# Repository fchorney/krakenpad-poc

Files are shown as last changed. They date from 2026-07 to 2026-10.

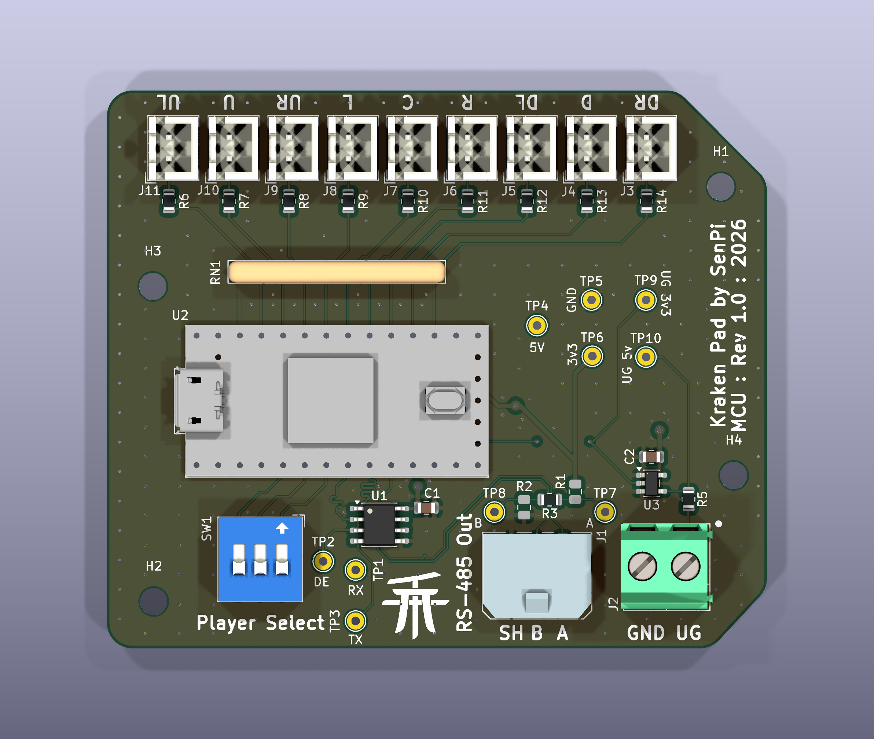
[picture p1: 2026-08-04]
review/01-master/11-3d-top.png

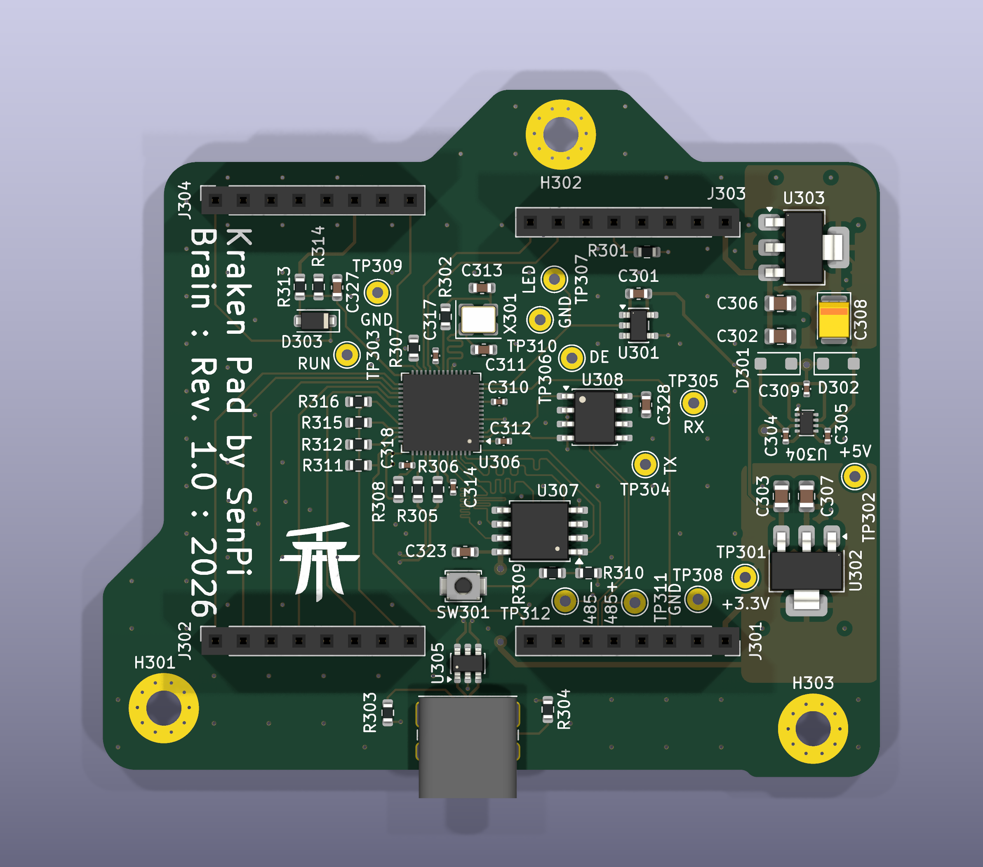
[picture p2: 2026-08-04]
review/04-dual-brain/11-3d-top.png

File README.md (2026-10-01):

# KrakenPad

Open-source dance pad controller hardware and firmware, built for modern ITG-style
rhythm games (Stepmania, ITGmania, DeadSync, etc.).

Commercial dance pad electronics haven't kept pace with what competitive/high-level
play actually wants: low, consistent input latency, high-resolution force sensing,
and hardware/firmware you can actually inspect, modify, and fix yourself. This
project is a ground-up replacement controller — sensor boards, main controller, and
firmware — designed around those priorities instead of around vendor lock-in or
proprietary protocols.

It is not tied to any one game or platform — it just speaks USB HID, so anything
that reads a standard controller/joystick works.

## Priorities

- **Low, consistent input latency.** Presses are detected and reported by dedicated
  interrupt-driven hardware, not discovered via a slow polling cycle — eliminating
  the multi-millisecond blind spots that periodic-scan designs are prone to.
- **High-resolution force sensing.** Each panel reads continuous per-sensor
  pressure (not just a binary switch), sampled at kHz-class rates, enabling more
  accurate and tunable press/release detection than simple threshold switches.
- **Higher, more consistent USB polling and LED refresh rates** than older
  commercial hardware typically offers, for tighter timing and smoother panel
  lighting.
- **Fully open hardware and firmware.** Schematics, PCB layouts, and firmware
  source are all open — no proprietary authentication, no closed protocol, no
  black-box firmware blobs. Anyone can build, modify, or repair their own unit.
- **Standard, open software compatibility.** Presents as a generic USB controller
  so it works out of the box with the open-source rhythm game ecosystem, with no
  vendor-specific driver or SDK required.

## Hardware Scope

The project is initially targeted at retrofitting existing SMX-style dance pad
frames — reusing the frame and panel mechanics while replacing the electronics
(control unit and panel sensor/LED boards) entirely. The design isn't
SMX-compatible at the protocol or hardware level; it simply fits the same
frame as a drop-in electronics replacement, since that's the hardware most
readily available for this kind of upgrade.

## Status

Prototype boards in hand, bring-up underway. Rev 1 of both boards — the master
controller and the two-board panel — was fabricated in August 2026, and the
boards are now being assembled and tested one at a time. The first panel and the
first master have been brought up: power, flash, sensors, all 25 LEDs, the
interrupt path and the RS-485 bus all work on the real hardware, panel to master.
Any board change from here is a rev 2 change. Firmware is still at bring-up
stage: the host-facing USB HID layer and flash-backed animation playback are not
written yet. See `docs/BRINGUP_LOG.md` for per-board results, `CLAUDE.md` and
`docs/` for design notes and specs.

## AI Disclosure

This project was built with AI assistance (Claude), used mainly for the grunt
work: research and part-comparison legwork, documentation drafts, firmware
prototyping, design-review passes, and scripted KiCad edits/fab outputs. All
design decisions, schematic wiring, PCB layout, and physical testing were done
by a human.

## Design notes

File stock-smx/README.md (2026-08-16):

# Stock SMX pad — reference documentation

**What a factory StepManiaX pad actually contains**, recorded from a full
teardown. This tree is descriptive and stands on its own: it is working
knowledge of stock SMX hardware, useful to anyone repairing or studying a pad,
and it is **deliberately independent of this project's replacement design**.

> **This directory contains no design opinions.** Nothing here says what we
> would replace, improve or remove. Our own hardware lives in `hardware/` and
> `docs/`; our replacement harnesses are in `hardware/harness/`.

## Contents

| File | What it covers |
|---|---|
| `harness/` | Every stock cable and connector, wall socket to FSRs — 12 WireViz drawings + a one-page topology map |
| `MEASUREMENTS.md` | The teardown bench sheet: raw lengths, gauges, pinouts, and the verification passes |
| `WIRE_COLORS.md` | Per-conductor colors for every stock harness, with confirmed/TODO status |
| `PARTS.md` | Stock connector/contact index, the JST-vs-Molex gender conventions, and JST YL current ratings |
| `PANEL_PCB.md` | The stock panel PCB — reverse-engineering reference |

## The harness drawings

Documented in power-flow order, wall inward. **The record is COMPLETE as of
2026-08-08** — nothing knowingly undocumented. A short list of low-consequence
unknowns is kept in `MEASUREMENTS.md`.

| File | Harness | Count per pad |
|---|---|---|
| `ac-input.yml` | Wall cord → YD06 EMI filter → locking IEC C13 | 1 |
| `psu-12v.yml` | C13 → YU1208 12V PSU → 5.5×2.5 barrel → JST YL 2-way | 1 |
| `12v-distribution.yml` | YL 2-way → fork-terminal star point → 2nd YL 2-way + underglow SM 3P | 1 |
| `external-12v-input.yml` | Star point → barrel socket, external cabinet 12V in | 1 |
| `dcdc-5v.yml` | Star point → Daygreen B15-1224-05, 12V→5V 15A | 1 |
| `5v-distribution.yml` | Converter 5V out → fork terminals → SM 2P + VLR-04V | 1 |
| `5v-columns.yml` | VLP-04V → 3× Molex 39014041, one per panel column | 1 |
| `mcu-interface.yml` | 5V SM 2P + underglow DATA → 14-pin KF2510 → Micro, analog row | 1 |
| `mcu-panel-io.yml` | 17-pin KF2510 on the Micro's digital row → 9 panel signal lines + RJ-12 data bus | 1 |
| `panel-signal-lines.yml` | YLP-09V → nine 18 AWG home runs → panel terminal blocks | 1 |
| `panel-power-chain.yml` | Column feed → 3 panels daisy-chained at 5V, 2 jumpers each | 3 |
| `panel-data-chain.yml` | MCU RJ-12 → all 9 panels, serpentine data bus | 1 |

`harness/stock-overview.dot` is the whole pad on one sheet — graphviz, not
WireViz, because it is a topology map rather than a harness drawing. It carries
no detail that is not already in the `.yml` files.

## Regenerating the drawings

```sh
uv tool install wireviz     # one-time; needs graphviz (brew install graphviz)
cd harness && ./gen.sh      # renders every .yml to harness/out/
```

Outputs land in `harness/out/` and are **not** committed.

## The headline findings

**The stock pad is a 5 V pad.** 12 V exists only between the supply and a
**Daygreen B15-1224-05** DC-DC converter; everything downstream — panels, LEDs,
MCU — runs at 5 V, with 15 A the whole budget. Read any stock harness past the
converter as 5 V unless it says otherwise.

**Topology:** wall → EMI filter → 12 V PSU → 5.5×2.5 barrel → fork-terminal star
point (physically the converter's input screw terminals) → { underglow SM 3P,
external 12 V barrel socket, **12 V→5 V converter** } → 5 V fork terminals →
{ **SM 2P → the MCU**, VLR-04V → 3× Molex to the panel columns }.

**The PSU has no terminal block and no ground stud.** It is a brick with one
captive output cable. Any description of "PSU lugs" or a "PSU GND stud" is
wrong — those came from pre-teardown guesswork elsewhere in this repo and have
been corrected.

**The MCU is fully accounted for.** Both header rows carry a KF2510 crimp
housing pushed straight onto the Arduino Micro's own pins — no adapter board.
Nine per-panel signal lines on D2–D10 (so **Dn drives panel n−2**), a **TX-only**
data bus off D1 through an RJ-12, and A1 driving the underglow. **On both
housings every position carries a contact whether wired or not** — an unwired
position is not an empty cavity.

**Panel LEDs have no wiring at all** — the 25-LED string is entirely PCB traces.
The only LED wiring in the pad is the underglow.

## Conventions used throughout

- **Panel numbers are 0–8** (0 = UL … 8 = DR). Teardown notes were spoken in
  1–9 numbering; subtract one.
- **Lengths in metres**, as WireViz expects. Bench readings were taken in
  **centimetres**, so the conversion is ÷100.
- **Sanity-check every length against something physical.** Every length taken
  on 2026-08-08 was reported in mm and meant in cm, and the whole set had to be
  corrected ×10 — caught only because nine panel home runs summed to an
  impossible 0.93 m of wire.
- **Wire by color within a harness, never by pin number across one.** Colors are
  inconsistent between harnesses; see `WIRE_COLORS.md`.
- Anything not measured or confirmed is marked `TODO` in a `notes:` field so it
  appears on the rendered drawing rather than hiding in a comment.
- **Never write `->` or a Unicode arrow inside a `notes:` field.** Notes are
  emitted into a graphviz HTML-like label unescaped and `dot` fails with an
  unhelpful syntax error. Write "then".

## Scope note: AC mains

`harness/ac-input.yml` documents the mains wiring as found. This project
replaces the MCU and panel PCBs only — nothing on the AC side changes. It is
recorded so a pad can be reassembled correctly and so the safety-critical
details (the JST YLP-03V's ground-in-the-middle pinout, the chassis bonding ring
terminal) are written down rather than remembered.

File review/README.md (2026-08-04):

# Review package — r/PrintedCircuitBoard, regenerated 2026-08-04

Export-only image set for every board in this project, formatted to the
subreddit's posting rules ([rule #8 / "please read before
posting"](https://old.reddit.com/r/PrintedCircuitBoard/comments/zj6ac8/please_read_before_posting_especially_if_using_a/),
[the "before you request a review, please fix these"
post](https://old.reddit.com/r/PrintedCircuitBoard/comments/1jwjhpe/before_you_request_a_review_please_fix_these/)).

Regenerate everything with:

```sh
tools/gen_review_images.py            # add --skip-3d to skip the slow raytraces
```

The script works on throwaway copies of the projects under `/tmp`, because
`kicad-cli` mutates `.kicad_pro` / `.kicad_sym` as a side effect. `hardware/` is
never written to.

## What's here

| Directory | Board | Size | Layers |
|---|---|---|---|
| `01-master/` | Master MCU board (Teensy 4.0 carrier) | 77.6 × 65.6 mm | 4 |
| `03-dual-carrier/` | Panel PCB — two-board design, LED/IO carrier | 127 × 127 mm core (139.3 mm across tabs) | 4 |
| `04-dual-brain/` | Panel PCB — two-board design, MCU brain | 70.9 × 62.8 mm | 4 |

The directory numbering has a gap because `02-panel-single/` — the retired
single-board panel — was removed on 2026-08-04 when the two-board split was
chosen. It is in git history at `1b41d1c` if it is ever wanted back.

At the top level: `POST-01-master.md` and `POST-03-dual-panel.md` are draft post
titles/bodies with the per-image captions each request needs, and
`RULES-CHECKLIST.md` is the pre-post audit.

Per board:

| File | What it is |
|---|---|
| `01-schematic.pdf` | schematic, vector, light background |
| `01-schematic-1-*.png` | same page rasterised at 300 dpi for image hosts |
| `02-2d-top.png` | F.Cu + F.Silkscreen + Edge.Cuts |
| `03-2d-in1.png` | In1.Cu + Edge.Cuts |
| `04-2d-in2.png` | In2.Cu + Edge.Cuts |
| `05-2d-bottom-mirrored.png` | B.Cu + B.Silkscreen + Edge.Cuts, mirrored so bottom silk reads correctly |
| `06-2d-silkscreen-top.png` | F.Silkscreen + Edge.Cuts alone (silk legibility check) |
| `07-2d-top-no-pour.png` | as `02`, zones emptied — routing visible under the pour |
| `08-2d-in1-no-pour.png` | as `03`, zones emptied |
| `09-2d-in2-no-pour.png` | as `04`, zones emptied |
| `10-2d-bottom-no-pour-mirrored.png` | as `05`, zones emptied |
| `11-3d-top.png` | 3D, straight-down plan view, same orientation as the 2D top |
| `12-3d-bottom.png` | 3D, straight-down plan view from below (matches the mirrored 2D bottom) |

The no-pour set exists because a solid GND pour hides the routing — reviewers
routinely ask for copper without fills. They are plotted from a throwaway copy
of the board with every zone un-filled; `--check-zones` is deliberately *not*
passed for those, or KiCad refills them.

**Cropping note:** `--bg-color` paints the whole PDF *page*, so trimming that
raster crops to the page, not the board. Each 2D view is therefore plotted
twice — once on white paper to measure the true board extent, once on black —
and the black raster is cropped to the white one's trim box.

`dual-panel.kicad_pcb` holds both outlines in one file (they ship as one
panel). The script splits it into two boards by X coordinate before plotting so
each gets its own images — see `DUAL_SPLIT_X` in the script.

## How the images satisfy the rules

* Exported with `kicad-cli`, never screen-captured — no cursor, no OS chrome,
  no grid, no photos of a monitor.
* Schematics keep KiCad's light background and standard orientation.
* 2D plots carry only layers that exist in the gerbers: copper, silkscreen and
  the board outline. No `*.Fab`, no `*.Courtyard`, no `User.*`, no net names on
  traces, no pad numbers.
* 2D colour scheme is a purpose-built theme (`PCB-Review`, written to
  `~/Library/Preferences/kicad/10.0/colors/` by the script): white silkscreen
  and outline, red/green/orange/blue copper per layer, black background so
  clearance and holes read as voids.
* 3D views are orthographic straight-down plan views in the same orientation as
  the 2D images. No tilted-only views.
* File sizes are 0.1–3.6 MB PNG / PDF.

## Read before posting

* **Subreddit rule 1 and rule 7A restrict AI-assisted work** ("no AI content /
  AI designs", "minor AI help ok"). These boards were designed with substantial
  AI assistance. Decide how you want to handle that before posting — the
  moderators, not this file, get to judge where the line is.
* **Rule 5: no board-house names anywhere in the title or body.** The
  `JLCJLCJLCJLC` string on B.Silkscreen (all three boards) is the order-number
  placeholder and is visible in `05-2d-bottom-mirrored.png`; don't name the
  vendor in the post text if a reviewer asks about it.
* **Rule 7A: no design questions in a review request.** Post each board as its
  own review request — the drafts in `POST-*.md` are written that way. (The
  single-vs-dual question that used to sit here is settled; don't reintroduce it
  into a post.)
* **Rule 7A: one review per board per day**, and don't edit images mid-review.

## State as of the 2026-08-04 regeneration

These images are current with the boards as of that date. They include the
2026-08-03 shifter swap (quad SN74AHCT125 → single-gate **SN74AHCT1G125**), the
brain's via-in-pad pass, the clearance floor raised 0.09 → **0.127 mm**, and the
carrier's **third mounting hole**. Earlier image sets predate all of that.

Also reflected: silkscreen fixes (FSR East, RS-485 A/B on the bus test points, fab
placeholder removed), the **year** in every name/rev block, `master-pcb` refdes
contiguous from 1, and `dual-panel` re-annotated into per-sheet blocks — **carrier
2xx, brain 3xx**, every type contiguous, no duplicates across sheets, which is
exactly the multi-sheet exception the rules allow.

Verified the same day, from clean project copies with zones current:

| Board | DRC | Unconnected | Schematic parity | ERC |
|---|---|---|---|---|
| master-pcb | 1 ✱ | 0 | 0 | 0 |
| dual-panel | 0 | 19 | 90 ✱✱ | 0 |

✱ One `courtyards_overlap` between R4 and U2 — R4 sits deliberately under the
socketed Teensy, and the violation is an accepted exclusion, not an open defect.

✱✱ Both dual-panel numbers are expected and neither is a defect. The **19
unconnected** are the board-to-board mating gap KiCad cannot model. The **90
parity items are a `kicad-cli`-only artifact — the GUI reports none**; they are
net *naming*, not topology, and the exported netlist agrees with the PCB
pad-for-pad across all 577 pads. Be ready to explain both if a reviewer asks.

Still open:

1. The carrier's board-to-board headers **J210–J213** are bottom-mounted (the
   brain hangs underneath), so the top view shows only their plated holes. The
   header bodies are in `03-dual-carrier/12-3d-bottom.png` — post both sides.
2. `dual-panel.kicad_pro` registers the root sheet as
   `a1b2c3d4-…-000000000001` — inherited from the retired `panel-pcb`, which the
   sheets were seeded from — while `dual-panel.kicad_sch` says `…00000000d001`.
   Harmless day to day, but it is why "Update PCB from Schematic" refused to match
   after re-annotation and had to be recovered with a re-link-by-refdes round trip.
   Expect it again on the next renumber.

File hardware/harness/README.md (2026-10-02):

# Wire Harness — our design

Source-of-truth for every cable, connector and pigtail **this project builds**.

> **The stock SMX pad's wiring is a separate record: [`stock-smx/`](../../stock-smx/).**
> That tree is descriptive and stands on its own as working knowledge of stock
> hardware. This one is prescriptive. **Do not merge them** — a stock file must
> stay true and useful to someone repairing a factory pad who has never heard of
> this project.
>
> Where a stock finding bears on one of these harnesses, the note goes **here**,
> never in the stock file.

Diagrams are generated with [WireViz](https://github.com/wireviz/WireViz): each
`.yml` is a text description of connectors + cable + connections, and WireViz
renders an SVG/PNG harness drawing and a BOM from it.

## Regenerating

```sh
uv tool install wireviz     # one-time; needs graphviz (brew install graphviz)
./gen.sh                    # renders every .yml to out/
```

Outputs land in `out/` and are **not** committed.

## The harnesses

| File | Harness | Count per pad |
|---|---|---|
| `12v-trunk.yml` | PSU → XT30 → inline fuse → Wago lever-block fan-out | 1 |
| `power-column.yml` | Fan-out → column of 3 panels, daisy chain | 3 |
| `rs485-chain.yml` | Master → 9 panels, serpentine RS-485 chain | 1 |
| `int-home-run.yml` | Master J3–J11 → nine panel carriers, home runs | 1 |
| `underglow.yml` | Fan-out + master → underglow strips | 1 |
| `fsr-panel.yml` | FSR → panel carrier, internal to a panel | 36 (4×9) |

`PARTS.md` is the connector/contact/cable/tooling index **and the shopping
list** — everything still to buy is marked ⬜ there.

`WIRE_COLORS.md` is the per-conductor color reference.

## Topology

```
AC (stock, unchanged) → YU1208 12V 8.5A (retained)
  → XT30 (replaces the stock 5.5×2.5 barrel; the barrel's other half
     gets the second XT30 so the stock harness can be plugged back in)
  → T8A slow-blow inline fuse
  → Wago 221-415 lever blocks, mounted on the Daygreen's own M3 holes
      ├─ 20 AWG → Micro-Fit 2p → panel 0 → 3 → 6
      ├─ 20 AWG → Micro-Fit 2p → panel 1 → 4 → 7
      ├─ 20 AWG → Micro-Fit 2p → panel 2 → 5 → 8
      ├─ 22 AWG → SM 3P → underglow strips
      └─ GND rail only: master GND tie (its own port, its own lead)
```

Three lever blocks: **one on +12 V** (exactly 5 ports) and **two jumpered on
GND** (6 ports — the extra is the master GND tie). The external 12 V cabinet
input is deferred and not designed in; that is what makes the +12 V count land
at 5.

## What we keep, and what we replace

**Retained unmodified:** the whole AC side (wall cord, YD06 EMI filter, locking
C13), the YU1208 supply itself, and its captive 18 AWG output cable.

**Removed:** the 5.5 × 2.5 barrel pair, the 30 cm 20 AWG tail and its JST YL
2-way, the Daygreen converter, and everything downstream of it at 5 V.

**Why both connectors go:** every connector the stock pad offers at that point
is a ~5 A class part, against our 6.34 A. A JST YL at 2 circuits and #20 AWG is
rated **5.0 A**; a 5.5 × 2.5 barrel is 3–5 A. Both would be permanent
bottlenecks below the load. With them gone, **nothing in the 12 V path limits
below the supply's own 8.5 A**.

**Cutting is still reversible** — the second XT30 goes on the cut stock tail, so
the original 12 V path can be restored by unplugging our trunk and plugging the
stock tail back in. Label it and keep it with the pad.

⚠ **Meter the barrel's polarity before cutting it.** It is the only unambiguous
polarity reference on the supply side — both captive conductors are black and
the moulded ridge's meaning is *not recorded*. Power the supply, meter centre
pin vs sleeve (label says centre-positive), note which conductor is +12 V, *then*
cut. Detail in `12v-trunk.yml`.

## Cable quantities

All three come from the completed stock record, since our harnesses run the same
geometry through the same panel positions. The WireViz BOMs in `out/` regenerate
these totals.

| Cable | Needed **per pad** | Buy (build scope = **2 pads**) |
|---|---|---|
| 12 V columns + trunk, 2C 20 AWG | 5.4 m + ~1 m = **6.4 m** | **20 m** |
| **RS-485 + INT, 22 AWG 2-core shielded pair (RVSP)** — one reel | 4.2 m + 10.65 m = **14.85 m** (INT was 9.3 m before the +15 cm/cable of 2026-10-02) | **40 m** (bought 50 m) |

**RS-485 and INT share one cable as of 2026-08-16.** Both are 2-core shielded
twisted pair at signal-level current; only the shield termination differs
(RS-485 → Micro-Fit pin 3, INT trimmed). 22 AWG is the only gauge inside both
connector windows — JST XH needs ≥1.30 mm insulation OD, Micro-Fit ≤1.85 mm.
Rationale in `PARTS.md` → "RS-485 and INT share ONE cable".

⚠ **The "Needed" column is one pad; the "Buy" column is two.** These were
mismatched until 2026-08-16, when the buy quantities were still sized for a
single pad even though the board and connector orders had long been sized for
two. Sourcing detail and the match-checks are in `docs/BOM.md` → Order 4.

## Power budget

**≈ 6.34 A / 76 W** at full white everywhere, against an 8.5 A supply = 75%
loaded — and that is the *datasheet* worst case, a state nothing ever commands.
Realistic peak using measured figures is 5.30 A.

| Load | Math | Amps @ 12 V |
|---|---|---|
| Panel LEDs | 9 × 25 × 15 mA (WS2815, **per pixel**) | 3.4 |
| Panel brains | 9 × ~60 mA | 0.5 |
| Underglow | 44 groups × 55.5 mA (WS2811, 3 × 18.5 mA) | 2.44 |
| Master | USB-powered | 0 |
| | **total** | **≈ 6.34 A** |

⚠ **The two LED families behave in opposite ways.** WS2815 stacks three dies in
series and shorts unlit ones, so **panel red draws exactly what white does** and
only PWM duty reduces current. WS2811 has three independent sinks, so
**underglow red draws ⅓ of white** and colour scales current linearly. A single
global power or animation policy is therefore wrong. Full treatment and both
current models: `docs/UNDERGLOW.md` → "Current draw".

### ⚠ Per-pixel figures: always say WHICH quantity

Three numbers circulate and they are **not** interchangeable. Quoting one where
another is meant has now caused the same confusion twice.

| quantity | strip cut (2026-08-16) | assembled panel (2026-09-08) | datasheet |
|---|---|---|---|
| PWM-scaled, `I × max(r,g,b)/255` | 8.7 mA | **12.9 mA** | — |
| quiescent, drawn even when dark | 1.84 mA | **1.76 mA** | — |
| **total at full white** | **10.5 mA** | **14.66 mA** | **15 mA** |

- The **budget table above uses the datasheet's 15 mA**, a *total*. The assembled
  panel measures 14.66 — so that budget is **confirmed to ~1% on hardware**
  (0.43 A/panel vs 0.44 A budgeted; 6.28 A pad vs 6.34 A), not conservative.
- The **model** for predicting what a frame draws uses the PWM-scaled figure.
  Use **12.9 mA** for the board; 8.7 was the strip and under-predicts by half.
- `8.7 + 1.84 = 10.5` and `12.9 + 1.76 = 14.66` — that is why the pairs of
  numbers in older notes look contradictory when they are not.

⚠ **The raw 2026-08-16 readings were never actually written down here**, despite
`CLAUDE.md` pointing at this section for them. What survives is the derived
figures above and the bench firmware, `firmware/panel/c/led_current_test/`. The
2026-09-08 panel readings, which *are* recorded, are in `docs/BRINGUP_LOG.md`.

⚠ **There is no current sensing anywhere in the pad.** The master is
USB-powered and deliberately outside the 12 V path, so every figure here is an
open-loop model prediction. The trunk's **inline fuse is the only current
protection**, and the stock ceiling (the Daygreen current-limiting at 75 W) is
deleted along with the converter. It is not optional.

## Conventions

- **Panel numbers are 0–8** (0 = UL … 8 = DR).
- **Lengths in metres**, as WireViz expects; bench readings are cm, so ÷100.
- Wire colors use WireViz two-letter codes (`BK` black, `RD` red, `YE` yellow,
  `GN` green, `WH` white, `BU` blue, `BN` brown, `GY` grey, `VT` violet,
  `OG` orange, `PK` pink).
- Anything not yet chosen or measured is marked `TODO` in a `notes:` field so it
  shows up on the rendered drawing rather than hiding in a comment.
- **Never write `->` or a Unicode arrow inside a `notes:` field** — graphviz
  fails with an unhelpful syntax error. Write "then".

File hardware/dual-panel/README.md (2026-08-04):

# Dual-board panel — the production panel design

**This is the panel that gets built.** The single-board alternative
(`hardware/panel-pcb`) was retired on 2026-08-04; it lives in git history only,
last present at `1b41d1c`.

**For as-built facts — interface pin map, RP2040 GPIO map, part inventory,
mechanical stack, verification status — read [`docs/DUAL_PANEL.md`](../../docs/DUAL_PANEL.md).**
This file covers only *why the project is shaped the way it is*; anything
enumerable is derived from the KiCad files and lives in that doc, so it cannot
drift.

> Earlier revisions of this file described a 34-pin two-row interface (J12/J13),
> USB-C on the carrier, and two mounting screws. **None of that was built.** The
> interface is four 1×8 rows (32 pins), USB-C is on the brain, and there are three
> screws. Trust `docs/DUAL_PANEL.md`.

## The idea

Split the 127×127 mm panel into a **display/IO carrier** — 25 WS2815s, every
external connector, the switches — and a **brain** — RP2040, flash, transceiver,
regulators, level shifter, USB — that plugs into the carrier's underside and sits
in the frame cavity. The LEDs own the top surface; anything mounted above them
shadows the play surface.

Motivations, in the order they mattered:

1. **Layout separation.** On one board the LED field and the brain compete for the
   same planes. Split, each board's routing is a different problem.
2. **ESD and protection.** Clamp at the ports on the carrier; the brain sits behind
   the connector.
3. **Fix the brain without re-fabbing the panels.** Not about upgrades — about a
   routing or hardware bug found at bring-up. Re-spinning a small brain board is far
   cheaper in money and materials than re-spinning 20 carriers.

The measured comparison that settled single-vs-dual is archived at
[`docs/archive/DESIGN_COMPARISON.md`](../../docs/archive/DESIGN_COMPARISON.md). Short
version: cost was near-neutral at **$2.13/panel**, and the split measured *better*
on FSR isolation — 1.1× channel-length spread vs 11×, and 3.18 mm worst same-layer
clearance to LED data / 12V vs 1.06 mm.

## Why one KiCad project rather than two

KiCad has no multi-board feature, but a project is already *one hierarchy → one
netlist → one `.kicad_pcb`*, and two `Edge.Cuts` outlines in a single board file is
the supported way to panelise. Two things fall out:

- **ERC checks the board-to-board interface for you.** With two separate projects,
  every interface change means editing two schematics and hand-checking that they
  agree — and the interface spec is precisely the mistake that would force *both*
  boards to be re-spun.
- **One JLC engineering fee and one PCBA setup instead of two.**

The cost is a known wart: the ratsnest draws airwires across the mating gap and DRC
reports 19 `unconnected_items`. There is no way to tell KiCad "these mate
mechanically." Giving each side distinct net names would kill the airwires but throw
away the cross-checking that motivated this structure, so the 19 are accepted and
enumerated instead.

## Why both boards are 4-layer on one panel

Tempting idea: carrier at 2 layers, brain at 4, since the carrier looks like it
might route single-sided. It costs more, not less, and it is not close.

A 2-layer carrier saves only the bare-fab delta on one board — the qty-5 quote put
the *entire* board cost for the 127×127 4-layer panel at **$14.91**, so even if
2-layer PCBs were free the saving caps around **$55** at qty 20; realistically
**$25–35**. A second run costs fixed per-order overhead: $25 eng fee + $51.12 PCBA
setup + $16.42 stencil + $4.93 storage ≈ **$97**, plus a second ~$40 shipment ⇒
**~$137**.

| | one 4L panel (both boards) | 2L carrier + 4L brain |
|---|---|---|
| bare fab | ~$55–60 | ~$25–30 + ~$15 |
| order overhead | $97 × 1 | $97 × 2 |
| shipping | ~$40 | ~$80 |
| **net** | — | **~$110–140 worse** |

There is no quantity where this flips: the saving scales with board count, the
penalty doesn't. Both boards need PCBA regardless — WS2815 is MSL 5a with a 24 h
floor life, so hand-assembling the carrier was never on the table.

What you get for the $25–35 you'd have "saved" is two extra copper layers on the
noisiest board in the system: an uninterrupted GND plane plus a power plane, under a
25-LED field with four high-impedance FSR lines crossing it. That is motivation #1
delivered better than the 2-layer version would have.

**6-layer was the weakest option considered** — JLCPCB lists 4-layer 100×100 mm from
~$7 vs 6-layer from ~$35, and it delivers neither the best routing environment nor
fault isolation. Only a 6-layer *brain* would genuinely force two fab runs; the brain
is already 4-layer-proven, since all of its content routed on 4 layers back when it
was still sharing them with the LED field and 12V distribution.

*Prices are point-in-time — verify live, per the warning in `docs/BOM.md`.*

## Directory map

| path | what |
|---|---|
| `dual-panel.kicad_sch` | root sheet — two sheet symbols, nothing else |
| `carrier.kicad_sch` / `brain.kicad_sch` | the two roles |
| `dual-panel.kicad_pcb` | **both** outlines, carrier left of x=182.55 mm, brain right |
| `dual-panel.pretty` / `.kicad_sym` / `3dmodels/` | project-local libraries |
| `panel/` | panelisation + JLC fab package — `gen_panel.py`, `gen_fab.py`, `QUOTE-2026-07-31.md` |
| `fit-test/` | 1:1 printable cavity fit template — re-run after any outline change |

Both sheets were seeded as full copies of `panel-pcb` rev 1.0 and stripped to role,
which is why some schematic sheet descriptions still say so. That is history, not a
live dependency: **`dual-panel` references no `panel-pcb` library**, and its
`fp-lib-table`/`sym-lib-table` point only at its own project-local libs.

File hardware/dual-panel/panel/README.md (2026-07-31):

# Fabrication panel

`dual-panel.kicad_pcb` holds two boards — carrier and brain — side by side. A fab
needs **one contiguous piece**, so `gen_panel.py` joins them to a rail frame with
mouse-bite tabs and writes a separate `panel.kicad_pcb`.

```sh
python3 gen_panel.py     # must run under KiCad's Python, see below
```

The panel is a **generated artifact, like gerbers** — it's gitignored. Keep
designing in `dual-panel.kicad_pcb` and re-run this for fab. Never hand-edit the
panel; the next run overwrites it.

## Why bother

JLC's own panelization only arrays a *single* design, so two different boards have
to be supplied as a customer panel. Doing that is what makes it **one order** —
one engineering fee, one PCBA setup, one stencil and storage (~$97), plus one
shipment instead of two. Upload them as two designs and you pay all of it twice.

It also needs to be genuinely joined: two closed outlines with a gap between them
don't describe a manufacturable board, and the pieces would simply fall off the
router.

## Current output

~228 × 143 mm (≈326 cm²), 289 footprints, verified as one contiguous piece.

```
carrier : 16 tabs   N=3 S=3 E=7 W=3
brain   :  6 tabs   N=0 S=0 E=3 W=3
```

The script prints that breakdown every run — it's the "will a board come off the
panel?" check, so read it rather than trusting the total. Tunable parameters are at
the top: rail width, tab count and width, mouse-bite drill and spacing, fiducial
and tooling-hole counts.

**The brain only ever gets east/west tabs**, and that is a KiKit limitation rather
than a setting. `buildPartitionLineFromBB` tiles the panel by bounding boxes; the
brain's bbox sits inside the carrier's y-span, so the layout reads as two columns
with one item each and the brain has no north/south neighbour to bridge to — its
partition line is literally two vertical segments. Tight frames, explicit
`TabAnnotation`s on the N/S edges (both direction conventions) and `buildFullTabs`
were all tried and produce nothing there. Stacking the boards vertically instead
just rotates the problem, since the brain is then the narrower board. The only real
fix is filling the brain's column above and below it — i.e. more brains per panel,
which costs a full extra assembly each.

Three tabs per side on a 71 × 63 mm board is ample support, so this is a
non-issue in practice.

## Fabrication package

```sh
python3 gen_panel.py     # build/refresh the panel
python3 gen_fab.py       # then the fab package
```

Writes `production/` (gitignored, regenerable): `panel-gerbers.zip` (4 copper +
paste + silk + mask + Edge.Cuts, separate PTH/NPTH Excellon and drill maps),
`panel-BOM.csv` and `panel-CPL.csv` in JLC column format.

**Assembly scope is SMD only** — 115 placements, 101 top and 14 bottom, across 35
component lines, every one carrying an LCSC number. Through-hole parts (all
connectors, both switches, and the eight interface headers/sockets) are
hand-soldered, matching panel-pcb. That also sidesteps the interface
headers/sockets having no LCSC number.

Three groups are filtered out, for different reasons:

- **through-hole parts**, per the decision above
- **the 30 test points** — bare plated holes with nothing to place, whose "value"
  is a net name, so left in they become 30 unmatched BOM lines
- **KiKit's fiducials, tooling holes and mouse bites**. Note `--smd-only` honours
  the SMD attribute but *not* `exclude_from_bom`, so the fiducials are
  SMD-attributed and sail into the position file unless dropped explicitly.

The BOM is built from exactly the set the CPL places, so the two cannot disagree.

**Upload the zip as a customer panel** ("panel by customer"), not as a single
board — JLC's own panelization only arrays one design.

## Requirements

KiKit, importable from **KiCad's Python** (`pcbnew` only exists there). KiKit 1.8.0
is confirmed working against KiCad 10.0.4.

```sh
KPY=/Applications/KiCad/KiCad.app/Contents/Frameworks/Python.framework/Versions/Current/bin/python3

# either install into KiCad's Python (the bundle is writable, no sudo)
"$KPY" -m pip install kikit

# or keep the bundle clean and install somewhere separate
"$KPY" -m pip install --target ~/.kikit kikit
PYTHONPATH=~/.kikit "$KPY" gen_panel.py
```

## Things that will bite

**KiCad DRC does not catch sub-micron outline gaps.** A 1.6 µm gap between a fillet
arc and its line sat in this design with DRC reporting *zero* violations, and it
made the board unpanelizable. The script checks outline continuity itself and fails
with the coordinates.

**The two bounding boxes must be separable by a vertical line**, not merely
disjoint — KiKit extracts each board with a rectangular `sourceArea`. They once
interleaved by 0.28 mm, because a carrier connector tab reached past the brain's
west edge, and no rectangle could split them. The fix is to nudge the brain east;
its position is arbitrary, since the assembled relationship lives in the H5→H1
offset rather than the layout. The script checks this and says how far to move it.

**KiKit will emit a panel whose boards are still loose, without complaining.** An
early attempt reported no error and produced 0 tabs, no frame, and two separate
pieces. The order matters: framing substrates must exist *before* the partition
line and tab annotations. The script verifies the result is one contiguous piece
and fails if it isn't — don't remove that check.

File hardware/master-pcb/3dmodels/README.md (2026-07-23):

# Third-party 3D models — master PCB

| File | Part | Source | License |
|---|---|---|---|
| `Teensy_4.0_Assembly.STEP` | PJRC Teensy 4.0 | [XenGi/teensy.pretty](https://github.com/XenGi/teensy.pretty) | MIT (see `LICENSE-XenGi-teensy.pretty.txt`) |

The Teensy 4.0 **symbol** (`master-pcb.kicad_sym`) and **footprint**
(`master-pcb.pretty/Teensy40_Socketed.kicad_mod`) come from the same upstream
project ([XenGi/teensy_library](https://github.com/XenGi/teensy_library) and
[XenGi/teensy.pretty](https://github.com/XenGi/teensy.pretty), both MIT).

The footprint is **locally modified**: upstream pads 35–44 (Teensy bottom-side
pins 24–33) were removed. This design does not use those pins, and as
through-holes they sat in a 2×5 grid directly under the socket, consuming
routing area. Pads 1–34 are unchanged from upstream.

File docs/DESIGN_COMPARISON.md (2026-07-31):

# Single board vs two boards — measured comparison

Deciding between `hardware/panel-pcb` (one 127×127 board) and `hardware/dual-panel`
(carrier + socketed brain). Measured 2026-07-31.

**The two are the same circuit.** Identical schematic, identical BOM — 115
placements, 35 component lines, same parts, same quantities, same LCSC codes. The
only differences are *layout* and *the 32-pin interface*. That makes the comparison
unusually narrow: it isn't "which design is better", it's "does splitting it hurt".

## Cost: settled, and near-neutral

Both quoted at qty 5, ENIG, epoxy filled & capped, SMD-only assembly:

| | panel-pcb | dual-panel | delta |
|---|---|---|---|
| PCB | $78.05 | $89.01 | +$10.96 |
| PCBA | $199.96 | $199.67 | −$0.29 |
| Advanced | $8.70 | $8.70 | — |
| **Total** | **$286.71** | **$297.38** | **+$10.67** |

**$2.13 per panel**, all of it bare board area, and 70% of that extra area is rails
and dead space rather than the brain itself. Assembly is free. Full detail in
[`hardware/dual-panel/panel/QUOTE-2026-07-31.md`](../hardware/dual-panel/panel/QUOTE-2026-07-31.md).

Cost is therefore **not** the deciding factor. Layout quality is.

## FSR routing — dual-panel measures better on every channel

The FSR lines are the highest-impedance nets on the board and the stated layout
priority ("FSRs as far from power/LED as possible").

| metric | panel-pcb | dual-panel |
|---|---|---|
| FSR_North | **401.3 mm** | 83.2 mm |
| FSR_East | 36.6 mm | 90.3 mm |
| FSR_South | 137.6 mm | 93.2 mm |
| FSR_West | 266.7 mm | 91.6 mm |
| spread across channels | **11× (36.6 → 401.3)** | **1.1× (83.2 → 93.2)** |
| worst same-layer clearance to LED data / 12V | **1.06 mm** | **3.18 mm** |
| FSR segments on F.Cu / B.Cu | 90 / 57 | 27 / 37 |
| cross-layer crossings under aggressors | 0 | 21 (B.Cu under F.Cu) |

**Different isolation strategies.** `panel-pcb` routes FSR predominantly on F.Cu —
the same layer as all 332 LED-chain segments and the 12V distribution — and relies
on 1–4 mm of lateral spacing. `dual-panel` routes them mostly on B.Cu and lets them
cross *under* the aggressors, separated by the In1 and In2 ground planes. Those 21
crossings are by design and benign; two ground planes is far better isolation than
3 mm of coplanar air.

**The asymmetry is the sharper finding.** An 11× spread means the four channels have
materially different pickup areas — East is a 36 mm stub, North is a 401 mm run
alongside a field of PWM-switched 12 V LEDs. They would have different noise floors,
so per-channel calibration would be doing real work rather than trimming.

FSR_North on `panel-pcb` is 68 segments spanning a 131 × 123 mm bounding box —
essentially the whole board — for a signal that only has to get from a board-edge
connector to a central MCU.

## Other critical nets — no meaningful difference

| net | panel-pcb | dual-panel |
|---|---|---|
| RS485+ / RS485− | 150.4 / 153.6 mm, 3.2 mm mismatch | 209.1 / 208.1 mm, 1.0 mm mismatch |
| INT_OUT | 85.1 mm, 2 vias | 99.1 mm, 0 vias |

`dual-panel`'s RS-485 is longer because it crosses the interface, but better matched.
At 1 Mbps over <3 m of cable neither figure matters; the mismatch is noise either way.
INT is comparable, and it is the sole press path, so worth noting nothing degraded.

## What this does and does not show

**Does not show `panel-pcb` would misbehave.** This measures geometry, not behaviour.
The FSR signal is sampled at 4 kHz through a 10 k‖10 nF filter with a 1.6 kHz corner,
and thresholded against per-channel calibration held in flash. A 401 mm trace adds
roughly 40 pF against a 10 nF cap — irrelevant for settling. The exposure is *noise
pickup*, which is a risk-profile difference, not a proven defect.

**Review status matters here.** `panel-pcb`'s **human review covered the schematic
only** — its *layout* has only ever been reviewed by AI. So the FSR asymmetry has not
had expert eyes on it, and an AI review is unlikely to have measured trace lengths.
It should not be read as "reviewed and found fine".

**The counterweight is not electrical.** Walking each crossing net against what
actually stresses a connector — FSR at kHz and 10 kΩ, INT as one open-drain edge,
RS-485 at 1 Mbps, LED data as one damped edge behind R16 — the interface is benign at
these speeds and impedances. The real risk of the split is **mechanical**: 32 spring
contacts in a device that is stomped on. That is what the M3 screws and the 11 mm
spacer are for, and it is the question no measurement here answers.

## Open questions for a reviewer

Frame it narrowly — these implement an identical schematic:

1. Does the 32-pin interface degrade anything, given the signal speeds above?
2. Is `panel-pcb`'s FSR routing (401 mm, 1.06 mm from the LED field, on the same
   layer) acceptable, or a real noise problem?
3. Is the mechanical reliability of a socketed brain acceptable in a stomped device?

## Method

Measured directly from the `.kicad_pcb` files with `pcbnew`: per-net track length by
layer, via counts, and segment-to-segment minimum distance between each FSR net and
every LED-chain / `LED_DATA*` / `+12VDC` net. Clearance is computed **layer-aware** —
same-layer minimum separately from cross-layer crossings, because a crossing with two
ground planes between is not a clearance problem and a naive 2D measurement reports it
misleadingly as 0.00 mm.

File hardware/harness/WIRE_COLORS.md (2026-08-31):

# Wire Colors — our harnesses

Conductor colors for the harnesses this project builds. The stock pad's colors
are a separate record: `stock-smx/WIRE_COLORS.md`.

Status column: **confirmed** = settled. **TODO** = not yet chosen.

The two-letter codes are WireViz's, used in the `.yml` sources:
`BK` black, `WH` white, `RD` red, `GN` green, `YE` yellow, `BU` blue,
`BN` brown, `PK` pink, `GY` grey, `VT` violet, `OG` orange.

**Per-panel identification is a marker at BOTH cable ends, not conductor
color** — the chosen RVSP cable comes in one color only. **The scheme is a
printed label under clear heat-shrink** (below), decided 2026-08-31 when the
reel landed. The **two-band row/column colour code** is the documented fallback,
and it in turn replaced the stock SMX 0=Red … 8=Black map on 2026-08-17.

## Panel identification — printed labels under clear shrink

**DECIDED 2026-08-31, and it supersedes the colour code below as the primary
scheme.** Each cable end carries a printed slip reading the panel's physical
position — `UL` `U` `UR` `L` `C` `R` `DL` `D` `DR` — captured under a piece of
**clear** heat-shrink.

**Why it won, when the colour code was already designed and costed:**

- **No lookup table.** `UL` is self-describing; `red + blue` is not. Every
  decode of the colour scheme is a trip back to this file.
- **It matches the socket.** The master's J3–J11 silkscreen already reads
  `UL`/`U`/`UR`/…, so the label and the socket are the *same string*. The colour
  code only encoded the same information indirectly.
- **The bin was one colour short anyway.** Stock on hand is red, blue, green,
  white, yellow, black and clear — **no violet**, and black and clear are both
  excluded as markers (see rule 2 below). The colour scheme needed a purchase;
  this one uses clear shrink already on the shelf.
- **Immune to bad light.** The failure mode the colour code fights hardest —
  telling blue from violet inside a closed pad — does not exist here.

**Practical rules:**

- **Laser-print the slips, not inkjet** — toner will not smudge or run when the
  shrink is heated; inkjet ink can. No printer to hand? A fine **paint pen on
  white heat-shrink** is the acceptable substitute; a permanent marker directly
  on shrink rubs off with handling and is not.
- **Print the position, never the panel ID.** Slot↔ID agreement is not assumed
  anywhere in this project — the master learns the real mapping with the `'I'`
  identify pulse and reports mismatches (`docs/RS485_PROTOCOL.md`).
- **Quantity: 9 cables × 2 ends × 2 pads = 36 labels**, half the 72 pieces the
  two-band code needed.
- Mark both ends of every cable identically.

### ⚠ Slide the shrink on BEFORE crimping

This applies to either scheme and is the one ordering mistake that cannot be
undone. Heat-shrink has to go onto the cable **before** the connectors are
terminated. Crimp all 204 contacts first and the only retrofit markers left are
tape or clip-on sleeves — and **tape is rejected here** (adhesive migrates and
the wrap unwinds in a warm pad), which is the whole reason it is not the scheme.

Note the RS-485 ends also need heat-shrink for the **braid-to-drain joint** (the
reel has foil + braid and no drain wire — `docs/BOM.md`). Load both pieces onto
the conductor in the same pass.

## Fallback — two-band row/column colour code

**Decided 2026-08-17; demoted to fallback 2026-08-31.** Kept in full because it
is what to build if labels prove impractical at assembly, and because its design
rules constrain any colour marking used anywhere in this harness.

The stock map needed **9 distinct colors**, and coloured
heat-shrink is simply not sold in nine distinguishable colours — that was the
blocker. This scheme needs **6**, as two disjoint sets of three, and every cable
end carries **two bands: one row, one column.**

| | col 1 (**L**) | col 2 (**C**) | col 3 (**R**) |
|---|---|---|---|
| **row 1 (U)** | `UL` = **red + blue** — ID 0 | `U` = **red + white** — ID 1 | `UR` = **red + violet** — ID 2 |
| **row 2 (M)** | `L` = **yellow + blue** — ID 3 | `C` = **yellow + white** — ID 4 | `R` = **yellow + violet** — ID 5 |
| **row 3 (D)** | `DL` = **green + blue** — ID 6 | `D` = **green + white** — ID 7 | `DR` = **green + violet** — ID 8 |

- **Rows, top → bottom: red, yellow, green.** A traffic light read downward.
- **Columns, left → right: blue, white, violet.**

### Why this is better than the 9-colour map it replaces, beyond needing fewer colours

- **It encodes physical position, and so does the master's silkscreen.** J3–J11
  are labelled `UL`/`U`/`UR`/`L`/`C`/`R`/`DL`/`D`/`DR`, so a cable now reads in
  the same terms as the socket it plugs into. The old map encoded *panel ID*,
  which is a DIP-switch/firmware property the master doesn't even assume is
  correct — it learns the real mapping with the `'I'` identify pulse.
- **Order-independent, because the two sets are disjoint.** Red is only ever a
  row and blue only ever a column, so "red then blue" and "blue then red" decode
  identically. There is no way to misread a cable by looking at the bands in the
  wrong order — worth preserving if the colours are ever changed.
- **Degrades gracefully.** Lose a band and you still have a row *or* a column,
  narrowing to three candidates. Lose the single band of a 9-colour scheme and
  you have nothing.

### Rules if the colours get substituted

The exact colours matter less than these three properties. Substitute freely
from what is actually in the bin, but keep:

1. **The two sets disjoint** — no colour used as both a row and a column, or the
   order-independence above is lost.
2. **No black and no clear.** Black is the default heat-shrink colour *and* the
   RVSP jacket is dark, so a black band reads as ordinary strain relief; clear
   reads as unmarked. This is why the stock map's `8 = Black` could not survive.
3. **No confusable pair across the sets** — red/orange, blue/violet,
   yellow/white, brown/black. Inside a closed pad the light is bad. Note the
   proposed sets already put blue and violet in the *same* set, where they are
   only ever compared against each other's positions, not against a row.

**Quantity: 2 bands × 9 cables × 2 ends × 2 pads = 72 pieces**, ~8 of each
colour per pad. Mark both ends of every cable identically.

**This scheme existed because nine colours are unobtainable, not because
colour-coding was ever preferable** — which is exactly why the printed labels
above took over as soon as the alternative was actually on the shelf.

## 12V trunk and fan-out — `12v-trunk.yml`

| Conductor | Gauge | Color | Code | Status |
|---|---|---|---|---|
| +12V, XT30 to fuse | 20 AWG | red | `RD` | confirmed |
| +12V, fuse to Wago | 20 AWG | red | `RD` | confirmed |
| GND, XT30 to Wago | 20 AWG | black | `BK` | confirmed |

Taken from the same 2C 20 AWG jacketed reel as the power columns. The PSU's own
captive cable upstream of the XT30 is **18 AWG and BOTH CONDUCTORS ARE BLACK** —
one carries a moulded ridge, and which is +12 V is not recorded. Meter the
barrel before cutting it. See `stock-smx/harness/psu-12v.yml`.

## 12V power columns — `power-column.yml`

| Conductor | Gauge | Color | Code | Status |
|---|---|---|---|---|
| +12V | 20 AWG | red | `RD` | **TODO confirm** |
| GND | 20 AWG | black | `BK` | **TODO confirm** |

## RS-485 chain — `rs485-chain.yml`

| Conductor | Gauge | Color | Code | Status |
|---|---|---|---|---|
| A | 22 AWG | blue | `BU` | **TODO confirm** |
| B | 22 AWG | white | `WH` | **TODO confirm** |
| Shield | — | drain | — | pin 3, both ends |

## INT home runs — `int-home-run.yml`

New builds, not stock — colors are ours to choose.

| Conductor | Gauge | Color | Code | Status |
|---|---|---|---|---|
| INT | 22 AWG | white | `WH` | proposed |
| GND | 22 AWG | black | `BK` | proposed |

Per-panel identification is **two bands of coloured heat-shrink at both cable
ends**, not conductor color — the chosen RVSP cable comes in one color. See
"Panel identification — two-band row/column code" at the top of this file. The
stock SMX 0 = Red … 8 = Black map is **superseded** (2026-08-17) and no longer
names markers.

## FSR leads — `fsr-panel.yml`

| Conductor | Gauge | Color | Code | Status |
|---|---|---|---|---|
| S1 | 30 AWG | red | `RD` | confirmed — sensor's own moulded tail |
| S2 | 30 AWG | black | `BK` | confirmed — sensor's own moulded tail |

The FSR is not polarised, so these two are interchangeable electrically — the
colors matter only for build consistency.

## Underglow — `underglow.yml`

| Conductor | Gauge | Color | Code | Status |
|---|---|---|---|---|
| 12V | 22 AWG | yellow | `YE` | confirmed at teardown (pad side) |
| DATA | 22 AWG | white | `WH` | confirmed at teardown — **not pink**; the Gen4+ manual's pink was never observed |
| GND | 22 AWG | black | `BK` | confirmed at teardown (pad side) |
| Master GND tie | 20 AWG | black | `BK` | new build |

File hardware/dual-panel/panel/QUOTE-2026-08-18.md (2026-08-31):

# JLCPCB quote — 2026-08-18 (THE ORDER — ✅ PLACED)

> ## ✅ ORDERED 2026-08-18. JLC first, then LCSC combined at checkout.
>
> ### ⚠ EVERY FIGURE IN THIS FILE IS **USD**. The card was charged **CAD**.
>
> | | USD | CAD charged |
> |---|---|---|
> | JLCPCB | $630.93 | **$876.05** |
> | LCSC | $155.80 | **$216.33** |
> | **paid** | | **$1,092.38** |
> | advanced options (bake + cleaning), after review | $11.16 | **$15.42** |
> | **panelisation supplement, charged after review** | **$24.42** | **$33.91** |
> | **UPS — import charges on the JLC shipment, billed 2026-08-27** | *(billed CAD)* | **$109.30** |
>
> **Implied FX 1.3885, identical on both orders to four decimals** — which is how
> the currency was confirmed rather than assumed. A mid-session assumption that
> JLC/LCSC quote in CAD was **wrong**; they quote USD.
>
> ### ⚠ PANELISATION SUPPLEMENT LANDED — **$24.42 USD / $33.91 CAD**
>
> Charged after review **because the panel carries two different designs**
> (carrier + brain in one `.kicad_pcb`, panelised together). This was an
> anticipated risk, not a surprise, and it is the real price of the two-board
> split — **budget it into any rev-2 panelisation decision.**
>
> ✅ **RECONCILED 2026-08-22.** The supplement is **additional to** the advanced
> options, not inclusive of them: baking + board cleaning landed as their own
> charge of **$15.42 CAD**, against the $11.16 USD estimate (~$15.49 at the order's
> 1.3885 FX). Counting them separately was therefore correct, and the total below
> is **exact, no longer an upper bound.**
>
> ### ⚠ UPS IMPORT CHARGES — **$109.30 CAD, billed separately 2026-08-27**
>
> ⚠ **Billed, not "billed on delivery" — the parcel had NOT arrived as of
> 2026-08-31.** UPS raises the Canadian import charges before release, so paying
> them says nothing about where the parcel is. An earlier wording here implied
> the shipment had landed; it had not.
>
> Charged by **UPS** on the JLC/PCBA shipment, **on top of** the $82.01 USD JLC
> shipping line — i.e. the courier bill is **1.85× what JLC itself charged to
> ship it**, and it appears nowhere in any vendor quote. This is the usual
> Canadian import stack (brokerage/disbursement + duty + GST/PST collected at the
> door), not a JLC cost and not something the quote could have predicted.
>
> ⚠ **UPS WAS NOT A CHOICE.** JLC's cheaper shipping options **were not offered at
> this order's quantity/weight** (20 panelised PCBA boards + 5 master fabs). The
> cheap-carrier advice that applies to a small parcel does not apply here —
> **assume rev 2 at similar volume is locked to a premium courier again**, and
> budget the import bill as a fixed cost of ordering rather than something to
> shop around.
>
> ⚠ **A SECOND import bill is UNRESOLVED.** The order shipped as **two separate
> shipments** (the JLC/LCSC combine could not be applied — see `ORDER_NOTES.md`
> §7). The **LCSC parcel is on "Global Direct Standard Line"**, a consolidated
> service which is *usually* sold as duty/tax-prepaid — but that is **unverifiable
> for this order**, and "usually" is not a cost record. **Checked 2026-08-27:
> LCSC states NO incoterm** — not `DDP`, not `DAP`/`DDU` — anywhere on the order
> page or on the commercial invoice. There is nothing left to look up, so **the
> only way this resolves is a bill appearing, or the parcel landing without
> one**: a bill means it was `DAP`, silence through to delivery means it was
> prepaid. Note the JLC bill arrived *before* that parcel did, so the absence of
> a charge is only conclusive once the goods are actually in hand. **Until then the total below is a floor,
> not a final figure.**
>
>
> ✅ **The AliExpress cable parcel (the third shipment, $165.06) was DELIVERED
> 2026-08-31 with NO import charges.** One clean data point for rev 2: the import
> exposure so far is attached to the **JLC/UPS courier** shipment, not to
> low-value-declared AliExpress freight. It says nothing about the LCSC parcel,
> which remains the open one. **It is also the only one of the three shipments
> that has actually arrived** — JLC and LCSC were both still in transit as of
> that date.
>
> **For rev 2: budget landed cost, not quoted cost.** Import charges on this
> order were **~7.4% of everything else combined** — larger than the panelisation
> supplement and the advanced options put together. The only real lever found so
> far is **self-clearing at a CBSA office**, which removes the brokerage portion
> (not the duty/tax) at the cost of a trip.
>
> ### Project total: **$1,587.51 CAD** (~$794/pad) — every line an actual charge
>
> | | CAD |
> |---|---|
> | JLCPCB (charged) | 876.05 |
> | LCSC (charged) | 216.33 |
> | advanced options — bake + board cleaning | 15.42 |
> | panelisation supplement — 2 designs on one panel | 33.91 |
> | AliExpress — 50 m RVSP $125.84 + 20 m 2C $39.22 | 165.06 |
> | DigiKey/PJRC — Teensy 4.0 ×2 | 72.52 |
> | Newark — Molex 11-03-0043 extractor | 63.13 |
> | Amazon — fuse holders + T8AL250V | 21.26 |
> | Home Depot — Wago 221-415, 10-pack | 14.53 |
> | **UPS — import charges, JLC shipment** | **109.30** |
> | **TOTAL** | **1,587.51** |
>
> **Only JLC and LCSC were USD.** Every other purchase above was already CAD —
> confirmed by the user, so no conversion applies to them.
>
> **Updated 2026-08-22 — nothing is left to buy.** The Wago blocks were the last
> purchase outstanding; bought as a **10-pack for $14.53** (the plan assumed ×6 at
> $12.97 — 221-415 is not sold in sixes). **Sourcing for rev 1 is complete.**
>
> ✅ **Every line above is a confirmed charge.** The total was exact as of
> 2026-08-22 and moved once since, on **2026-08-27**, when UPS billed **$109.30
> CAD** in import charges on the JLC shipment — a cost no vendor quote
> contained. It is exact again now, but see the second-shipment warning above. The last
> estimate to be replaced was the AliExpress cable, long carried as ~$165.00 and
> confirmed 2026-08-22 against the card at **$165.06**: **50 m RVSP $125.84 + 20 m
> 2-conductor $39.22**, which sum to the charge exactly. Settling the two JLC
> after-review charges is what removed the old ~$15.50 upper-bound caveat.
>
> **Shipping combine: there is NO combine option at LCSC checkout.** Both orders
> were paid in full, then `support@lcsc.com` was emailed with both order numbers
> immediately. Any saving arrives as a **refund**, not a discount at checkout.

**This is the real qty-20 quote, and it supersedes `QUOTE-2026-07-31.md` as the
cost reference.** That one was qty 5, taken before the USB-C, level-shifter,
C0G-cap and RS-485-transceiver part changes, and its `panel-pcb` column describes
a board that no longer exists.

Dual-panel **×20 with PCBA**, master-pcb **×5 bare fab**. 4-layer, ENIG, POFV,
SMD-only assembly both sides, baking on the WS2815s, board cleaning, slow build.

## Headline

| | |
|---|---|
| Merchandise (both boards) | **$557.92** |
| Shipping | $82.01 |
| Coupon | −$9.00 |
| **Shown total** | **$630.93** |
| ⚠ Advanced options, billed after review | **+$11.16** |
| **Realistic JLC all-in** | **$642.09** |

⚠ **JLC excludes "Advanced Options" from the displayed total** — its own wording is
*"the cost of the options below is not included in the 'Total Price'."* Bake
components $7.88 + board cleaning $3.28 arrive as a separate charge after review.
**Confirmed: billed separately, $15.42 CAD** (2026-08-22).

## Breakdown

| dual-panel ×20 — PCB | $174.47 | | dual-panel ×20 — PCBA | $375.41 |
|---|---|---|---|---|
| Board | $79.70 | | Components (35 items) | $239.28 |
| Via covering | $32.44 | | Feeders loading | $53.55 |
| Surface finish (ENIG) | $31.40 | | Setup fee | $51.12 |
| Engineering fee | $25.00 | | Stencil | $16.42 |
| Via plating method | $4.89 | | SMT assembly | $14.09 |
| Confirm production file | $1.04 | | Packaging | $0.50 |
| | | | Confirm parts placement | $0.45 |
| | | | Panel / Large size | $0.00 |

**master-pcb ×5, bare fab: $8.04** — derived, not itemised separately
($557.92 − $549.88). Matches the "≈$8 per 5 boards" figure recorded in July, so the
master's fab cost has not moved.

**$28.05 per complete assembled panel** (all-in ÷ 20).

## POFV is now priced at volume

**Via covering $32.44 + via plating method $4.89 = $37.33 at qty 20**, up from
$22.77 at qty 5. This closes the long-open "POFV surcharge has never been priced"
question. It is ~6.7% of the order and is **not optional** — see `ORDER_NOTES.md` §1.

## ⚠ 18 → 20 PCBA cost far more than linear scaling predicts

The quote was first taken at **18 assembled** (2 left bare, intended as passthroughs).
Going to 20 cost **+$70.45**, against a predicted +$20.

| | 18 PCBA | 20 PCBA | delta |
|---|---|---|---|
| Components | $170.16 | $239.28 | **+$69.12** |
| SMT assembly | $12.76 | $14.09 | +$1.33 |
| Setup / stencil / feeders / confirm / packaging | — | — | **$0.00** |
| PCB block (all of it) | $174.47 | $174.47 | **$0.00** |

**Per-board component cost ROSE with volume — $9.45 → $11.96.** That is
non-monotonic, so it is a step function somewhere across the 35 lines, not linear
cost. The obvious suspect was a WS2815 reel break; **that was checked and
disproved** — `C5446699` ships in 1000-piece packs, and both 450 (18 boards) and
500 (20 boards) round to the same single pack. **The actual cause is unidentified.**
JLC's BOM matcher shows per-line extended cost, so comparing 18 vs 20 there would
find it.

⚠ **Do not estimate a quantity change on this board by dividing and multiplying.**

**It was ordered at 20 anyway**, because `docs/BOM.md` fixes the scope at **20 panel
assemblies (2 × 9 + 2 spares)**. The 2 spares were always the plan, and the brain
is the one board that cannot be hand-built. Passthroughs cost nothing extra: the
carrier daisy-chains `RS485+/−`, `RS485_Shield`, `+12VDC` and `GND` in its own
copper (J204↔J207, J205↔J208 share nets), so **a populated carrier with the brain
unplugged IS a passthrough**. Only caveat: `LED_DATA_5V` then floats, since the
shifter U301 and R301 live on the brain — ground it at TP214 if the LEDs misbehave.

## Sanity checks that passed

- **PCB block byte-identical between the 18 and 20 quotes** — correct, the fab
  quantity was always 20; only assembly changed.
- **Setup, stencil, feeders, confirm and packaging all held steady** across the
  quantity change, so nothing else silently reset when the quantity was edited.

⚠ **Editing the quantity WIPES the PCB and PCBA remark fields.** Set quantity
first, then paste. Re-verify every option afterwards.

## Companion order

**LCSC (order 2): $138.68 merchandise + $33.19 shipping − $16.07 discounts =
$155.80.** The −$16.07 is the *sum* of the two itemised discounts ($4.07 + $12.00
shipping), not a third one.

**Vendor total, USD, JLC + LCSC only: $666.51 + $155.80 = $822.31.**
⚠ Not the project total — that is **$1,478.21 CAD** at the top of this file, which
also carries the cable, Teensys, extractor, fuses and Wagos. This figure is USD and
covers the two vendor orders alone. JLC's $666.51 is the $642.09 all-in above plus
the **$24.42 panelisation supplement**, which landed after review.

⚠ **$103.20 of that is shipping** ($82.01 JLC + $21.19 net LCSC) — 13% of the
two vendor orders — **and that is the quoted freight only. UPS then billed
$109.30 CAD in import charges on the JLC parcel**, which more than
doubles the real cost of getting the order here. See the top of this file. See `ORDER_NOTES.md` §7 for combining the two shipments, and note the
saving is realistically under $21, not $33, because shipping is recalculated and
the −$12 LCSC shipping discount may be lost.

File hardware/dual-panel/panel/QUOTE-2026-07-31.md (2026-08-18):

# JLCPCB quotes — 2026-07-31

> ## ⛔ SUPERSEDED — this is qty 5 and predates several part changes.
>
> **For cost, use `QUOTE-2026-08-18.md`** — the real qty-20 order quote. This file
> predates the USB-C, level-shifter, C0G-cap and RS-485-transceiver changes, and
> its `panel-pcb` column describes a board that was deleted 2026-08-04.
> **Kept for the controlled single-vs-dual board comparison only.**

Quantity **5**, ENIG, epoxy filled & capped vias, SMD-only assembly, baking on the
WS2815s. Not ordered. Taken before deleting the `JLCJLCJLCJLC` placeholder, but
**after** the R20 (`C22935`) and R8–R11 (`C98220`) LCSC fixes.

**The two-board split costs $10.67 across five panels — $2.13 per panel.**

## Headline comparison

| | panel-pcb (single board) | dual-panel (carrier + brain) | delta |
|---|---|---|---|
| PCB | $78.05 | $89.01 | **+$10.96** |
| PCBA | $199.96 | $199.67 | **−$0.29** |
| Advanced | $8.70 | $8.70 | — |
| **Total** | **$286.71** | **$297.38** | **+$10.67** |
| per panel | $57.34 | $59.48 | +$2.13 |

Both buy the same thing: five working panels. **Assembly is free** — it came in
fractionally cheaper on the panel. The entire difference is the bare board being
physically bigger (326 cm² vs 178 cm²), which is the rails and the dead space
beside the brain as much as the second board itself.

This is a controlled comparison: the two designs export **identical BOMs** — 115
placements, 35 lines, same parts, same quantities, same LCSC codes — because the
circuit is the same, just divided across two boards.

## dual-panel breakdown ($297.38)

| PCB | $89.01 | | PCBA | $199.67 | | Advanced | $8.70 |
|---|---|---|---|---|---|---|---|
| Engineering fee | $25.00 | | Setup fee | $51.12 | | Bake components | $7.88 |
| Via covering | $19.09 | | Stencil | $16.42 | | Board cleaning | $0.82 |
| Surface finish (ENIG) | $20.20 | | **Panel** | **$0.00** | | | |
| Board | $20.00 | | **Large size** | **$0.00** | | | |
| Via plating method | $3.68 | | Components (35 items) | $73.32 | | | |
| Confirm production file | $1.04 | | Feeders loading | $53.55 | | | |
| | | | SMT assembly | $4.31 | | | |
| | | | Confirm parts placement | $0.45 | | | |
| | | | Packaging | $0.50 | | | |

`panel-pcb` differs only in: board $11.80, via covering $17.99, surface finish
$18.70, via plating $3.52, components $73.58, SMT assembly $4.34.

## ⚠ Panel format: use Column = 1, Row = 1

**This is the expensive gotcha.** On "panel by customer", JLC asks for column and
row counts. Entering **2 × 1** — geometrically true, two boards side by side —
makes their system read qty 5 panels as **10 assembled boards**, and it prices
components and placement for twice the units:

| line | Column = 2 | Column = 1 | ratio |
|---|---|---|---|
| Components | $128.34 | $73.32 | 1.75× |
| SMT assembly | $7.56 | $4.31 | 1.75× |

That is **$58 of phantom assembly**, and nothing else on the quote moves.

**How it was diagnosed, since the same trap will look different next time:** the
two lines that changed are the only two that scale with *unit count*. Everything
that scales with *complexity* — feeders loading ($53.55), setup ($51.12), stencil
($16.42) — was identical to the cent. Same reels, same setup, same number of
sides, but 1.75× the parts, means more units are being built, not more work per
unit. Both ratios matching to three decimals (1.744 / 1.742) confirmed it.

Use **1 × 1** and describe the panel in the order remarks instead:

> Customer panel: 2 different designs, 1× carrier (139.2 × 127.0 mm) + 1× brain
> (70.9 × 62.5 mm), joined by mouse-bite tabs to a 5 mm rail frame.

## Panelising is confirmed working

`Setup fee $51.12` and `Stencil $16.42` are **identical to the single-board quote**,
and `Panel: $0.00` / `Large size: $0.00` mean the customer panel was accepted with
no surcharge and 228 × 143 mm didn't trip an oversize band.

That per-order overhead is paid **once for both boards**. Two separate designs
would repeat engineering + setup + stencil + confirm-file ≈ **$94**, plus a second
shipment — which is what the one-project, one-panel structure exists to avoid.

## Scaling

About **$147.58 is quantity-independent** (engineering, setup, stencil, feeder
loading, both confirm fees). The remaining ~$149.80 scales, at about **$29.96 per
panel**.

| qty | total | per panel |
|---|---|---|
| 5 | $297.38 | $59.48 |
| 9 (a full pad) | ~$418 | ~$46.36 |
| 10 (a pad + 1 spare set) | ~$447 | ~$44.72 |

Linear extrapolation, so a floor on the saving — components have quantity breaks.
A single qty-10 run is roughly **$150 cheaper** than 5 now and 5 later.

## Notes

- **ENIG is deliberate** — a 0.4 mm-pitch QFN-56 plus filled-and-capped vias is
  exactly where a flat finish earns its keep.
- **Via covering ($19.09)** is the price of via-in-pad. The lever, if ever wanted:
  move the six 0402 vias (C5, C6, C7, C9, C11, C15) out of their pads, leaving only
  the RP2040 thermal array, and a cheaper option becomes viable. Design change, and
  it's 6% of the order.
- **Baking came in flat at $7.88**, not per-part.
- The 2026-07-18 panel-pcb quote's $72.59 components line was **not** under-counting
  as first suspected — $73.58 here confirms it was right all along.

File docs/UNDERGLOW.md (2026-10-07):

# Platform / Underglow LED Strips (optional feature)

Status: **optional — electrical spec fully resolved.** Nice-to-have; if it
isn't easy to fit, the plan is to just not connect it rather than force a fit.
Trimmed 2026-07-23 — superseded speculation (5V-bus theories, Daygreen-reuse
ideas, pre-confirmation brightness background) removed; full history in git.

## What the stock underglow is (all confirmed)

- **Driven directly by the stock MCU**, not on the panel data bus:
  `SMX_SetPlatformLights()` sends USB `'L' + strip_index + count + RGB` and
  the MCU handles it locally (confirmed by bus capture — no bus traffic during
  platform light updates).
- **12V-native, 3 wires** (confirmed from the official Gen4+ manual wiring
  diagram, page 8): 12V (yellow) and GND (black) come straight from the PSU
  side, data (pink) from the MCU. The 3-wire/12V combination rules out WS2815
  (which needs a 4th backup-data wire) — this is the common 12V
  WS2811-grouped-by-3 strip design. **Confirmed against the WS2811 datasheet
  2026-08-16 — see "Current draw" below.** Note the part identification is
  still an *inference* from three observations (12V, 3 wires, probe-confirmed
  groups of 3); no one has read a part marking. The architecture is certain
  even if the exact IC vendor is not.
- **44 addressable chunks per pad, each = 3 physical LEDs** (confirmed by
  direct test with `underglow_probe.cpp` — lighting one chunk lights three
  LEDs). Physical layout: 17 chunks left edge + 17 right edge + 10 back
  (players stand at the front) = 132 physical LEDs addressed as 44 groups.
- **Addressing resolution is per-group-of-3** — animation tooling and USB
  protocol commands should think in 44 positions (17/17/10), not 132 LEDs.
- Stock PSU: Gen 4 = 12V 9A, Gen 5 = 12V 15A (from the manual). This project
  targets **Gen 5 pads only**.

## Current draw — resolved 2026-08-16 against the WS2811 datasheet

**2.44 A at full white, all 44 groups.** The `44 × 60 mA = 2.6 A` figure this
repo already carried is correct and about 6% conservative — unlike the panel
LED figure, which was wrong by 3× and had to be corrected the same week. This
one needed no correction.

### How the WS2811 actually draws current

From the Worldsemi WS2811 datasheet (pages 2–3):

- The pinout is **`OUTR` / `OUTG` / `OUTB` — three separate output pins**, each
  an independent constant-current sink.
- Electrical characteristics: `I_OL`, condition `ROUT`, **Typ 18.5 mA**. There
  is no Min/Max given.
- Absolute max `V_OUT` = **12 V** per output; `V_DD` is only 6–7 V.
- Pin 7 `SET` is the **speed-mode** pin (VDD = low speed, floating = high
  speed) — *not* a current-setting pin. The datasheet's "add a resistance to
  IC VDD" note applies to running from a **24 V** supply. **WS2811 output
  current is fixed internally; there is no REXT.** Several third-party guides
  get this wrong.

At 12 V each channel drives **3 same-colour dies in series** — that is exactly
why one IC addresses 3 physical LEDs, and why the pad's addressing granularity
is 44 groups rather than 132 pixels.

So **full white per group = 3 channels × 18.5 mA = 55.5 mA**, and
44 × 55.5 mA = **2.44 A**.

Sanity-checked against two independent commercial strip densities, which is the
check that would have caught the WS2815 error had it been applied there:

| Density | ICs/m | Predicted | Vendors state |
|---|---|---|---|
| 60 LED/m | 20 | 1.11 A/m (13.3 W/m) | 1.2 A/m (14.4 W/m) ✓ |
| 90 LED/m | 30 | 1.67 A/m (20.0 W/m) | max 20 W/m ✓ |

### ⚠ The underglow and the panels behave in OPPOSITE ways

This is the single most important fact on this page for firmware and animation
work, and it is genuinely counterintuitive because both parts are from the same
manufacturer's family.

| | Underglow (WS2811) | Panels (WS2815) |
|---|---|---|
| Topology | 3 **independent** current sinks, each feeding 3 series dies | 3 dies **in series** in one package, unlit ones shorted out |
| Pure red vs full white | **red = ⅓ of white** | **red = exactly white** |
| Does colour choice reduce current? | **yes, linearly** | **no, never — only PWM duty does** |
| Current model | `I = 18.5mA × (r+g+b)/255` per group | `I = 12.9mA × max(r,g,b)/255` per pixel ⚠ **was 8.7mA — see note below** |

**A single global power policy is therefore wrong.** One written on the panels'
rule over-estimates underglow by up to 3×; one written on the underglow's rule
under-estimates the panels catastrophically. Model the two separately.

> ⚠ **8.7 and 10.5 are the SAME measurement, not two conflicting ones.** The
> table below gives the **PWM-scaled component**; `CLAUDE.md` quotes **10.5
> mA/pixel** for the same strip. The difference is quiescent:
> **8.7 + 1.84 = 10.54.** Always say which quantity you mean — this ambiguity
> made the two look contradictory for weeks, and caused the same mistake again
> on 2026-09-08 when 12.9 was first compared against the datasheet's 15.

The panel `max()` model is not a guess — it is confirmed on four points from the
2026-08-16 bench run:

| Commanded | `max()` predicts | Measured |
|---|---|---|
| (255,255,255) | 8.7 mA | 8.7 mA ✓ |
| (255,0,0) | 8.7 mA | 8.7 mA ✓ |
| (128,128,128) | 4.35 mA | 4.6 mA ✓ |
| one channel @ 64 | 2.18 mA | 2.2 mA ✓ |

The `(128,128,128)` row is load-bearing: staggered PWM phases would have given
8.7 mA there. It gave half, so the phases are aligned and `max()` holds.

Secondary consequence, thermal rather than electrical: WS2811 is a **linear**
part, dropping ~6 V across the IC on a red channel (3 × ~2.0 V dies) versus
~2.4 V on green/blue (3 × ~3.2 V). So on the underglow, red is simultaneously
the *lowest* current and the *least efficient per unit light* — a third distinct
behaviour from the panels, where red and white draw identically but red wastes
the most.

### Sizing figure

Use **20 mA/channel**, not the 18.5 mA typ — the datasheet gives no Max, so
binning can go over as easily as under, and this matches the 20 mA/pixel
headroom convention already used for the panels. That puts underglow at
**2.64 A** for sizing purposes.

### Deferred: a firmware power budget

An earlier plan had the master scale LED output to hold total pad current under
a connector limit, because the design briefly tried to reuse the stock PSU tail
unmodified. **That constraint was removed 2026-08-16** (see
`hardware/harness/12v-trunk.yml`) and the budget is no longer needed for safety.
Recorded here because the model is worth keeping if it is ever wanted:

- The two formulas above give **exact** per-frame current, not an estimate.
- Underglow is the natural place to absorb any cap: it is decorative, and it is
  **master-local**, so the master governs it completely. The panels' local
  fallback animations (played after a 100 ms RS-485 timeout) are by definition
  *not* reachable by a master-side budget — so any panel-side cap would have to
  be compiled into the default animation slots to be real.
- Because WS2811 current scales with channel count, a **single-colour** underglow
  already costs ⅓ of white. Any "limit by channels driven" policy would almost
  never bind in practice, since typical underglow use is one accent colour.

Sources: [WS2811 datasheet (Worldsemi)](https://cdn-shop.adafruit.com/datasheets/WS2811.pdf),
[mirror (TME)](https://www.tme.eu/Document/26d574b43ad9ddaffa4d5bcd140ec145/WS2811.pdf).

## Set-and-forget is native behavior

WS28xx-family LEDs latch their PWM state: write one frame and they hold the
color indefinitely with the data line quiet. ~~Our default: write on command
only. Animation stays possible for free (send frames more often) but is not
the design center.~~ **Superseded 2026-10-05:** write-on-command only works if
the strip is already powered when the command arrives, and a real strip powers
up at full white. See "Measured on a real strip" below.

## Measured on a real strip, 2026-10-05

The stock underglow (44 groups), master #2. Log:
`docs/BRINGUP_LOG.md` → master #2 → 2026-10-05.

- **Byte order is BRG, not RGB.** Sending R, G, B lit the strip blue, red,
  green. The master firmware's `underglowFill` reorders; anything else that
  drives the strip must too. Measured on one strip only: check the second
  pad's strips rather than assume.
- **All 44 groups addressable singly and in order** (`g` chase).
- **Power-on state is full white**, held until the first frame. That is
  2.44 A, which the 12 V budget already covers, so the issue is appearance, not
  power.

**Design consequence: the master must re-send the underglow frame
periodically, not only on command.** The master runs on USB and the strip on
12 V; they come up independently, and the master has no 12 V sense. If the
strip powers up after the master has sent its frame, or is re-plugged, it sits
at full white until the host happens to send another. Fix: send the current
frame at boot, then every few hundred ms. A frame is ~1.3 ms, so the cost is
negligible. A 12 V sense on the master would also solve it, but that is a board
change.

## Our design (as built on the master PCB — see `docs/MASTER_PCB.md`)

- **Power**: strips take 12V/GND from the Wago fan-out (`hardware/harness/12v-trunk.yml`) — the
  master is not in the underglow power path at all. No regulator, no
  magnetics on the master.
- **Data**: Teensy GPIO11 → SN74AHCT1G125 single-gate buffer (VCC = Teensy USB 5V rail)
  → 330R series → J2 pin 1 (DATA position of the merged GND-tie/underglow
  screw terminal). Ground reference comes via the master's mandatory GND
  tie (J2 pin 2).
- **Host-side**: a strip-set command in our USB protocol
  (`docs/USB_PROTOCOL.md`, `'L'` platform strip — write-on-command).
- Gating is UI/software config only ("underglow: on/off") — no sense pin; a
  12V-sense divider (like the panel's) is the known upgrade path if
  config-only gating proves annoying.

## Physical connection — CLOSED 2026-08-08 by the full pad teardown

The strips terminate in a **JST SM 3P, female**, carrying 12V / DATA / GND.
Our side is therefore a **JST SM 3P male** pigtail, no splicing required:

- 12V and GND come off the **12V star point**, exactly as stock does. Note that
  star point is **not** "PSU terminals" — the stock PSU is a brick with a single
  JST YL 2-way output and no terminal block or ground stud. The star point is
  physically the DC-DC converter's input screw terminals.
- DATA goes to master **J2 pin 1**.
- Master **J2 pin 2** is a separate lead to a GND port on the Wago fan-out — the mandatory
  GND tie, required whether or not underglow is fitted.

Harness drawing and BOM: `hardware/harness/underglow.yml`.

**Pin order RESOLVED 2026-08-08, and it is the reverse of what was assumed:**
**pin 1 = GND, pin 2 = DATA, pin 3 = 12V.** The conductor *set* was right; the
*order* was not. Building to the old 12V/DATA/GND assumption would have put 12V
into the DATA pin and destroyed the first WS2811.

**Naming, per JST's convention** (see `stock-smx/PARTS.md`): the pad-side
half is an **SMR-03V-B receptacle**, which in JST-speak carries *male pin*
contacts; the strips' own pigtail is the **SMP-03V-BC plug** with female sockets.
"SM 3P female" above refers to the strip side's contacts and is consistent with
this, but order by part number, not by gender word.

**RESOLVED 2026-08-16: we DO build the SM 3P pigtail.** An earlier note here
said this harness "may not be needed at all", because the teardown found the pad
already had an SM 3P wired with 12V/GND from the star point and DATA on a
**JST YLR-01V**. That was **conditional on reusing the stock harness segment**,
and we do not — all SMX wiring is removed, and the star point itself is replaced
by the Wago fan-out (`hardware/harness/12v-trunk.yml`). The stock `SMR-03V-B`
goes with that wiring.

**What survives is only the strips' own moulded `SMP-03V-BC` pigtail**, so we
must build its mate:

- **`SMR-03V-B` housing — LCSC `C157907`**
- ~~**`SMM-003T-P0.5` pin contact — LCSC `C385123`**, ×3 plus spares~~ — wrong
  pin: rated 28–30 AWG, too fine for 22 AWG. **Corrected 2026-10-07:** the SM
  male pin is **`SYM-001T-P0.6`** (28–22 AWG). Not yet bought; the build in use
  is the pre-made pigtail route in `hardware/harness/PARTS.md`.

12 V and GND come from the Wago fan-out; DATA from master J2 pin 1. No
`YLP-01V` is involved.

This supersedes the earlier note that the underglow leads were crimped into a
12-pin Dupont-style housing with no intermediate connector to reuse. That was
wrong; there is a reusable connector.

## ⚠ The panel figure was corrected on real hardware, 2026-09-08

The `8.7 mA/pixel` above came from a `HD-12v-WS2815-144L-B-IP30` **strip cut**.
An assembled panel — JLC-placed `C5446699`, a different manufacturer and bin —
measures **12.9 mA/pixel**. Compare totals rather than constants:

| | strip cut (2026-08-16) | assembled panel (2026-09-08) | datasheet |
|---|---|---|---|
| PWM-scaled | 8.7 | **12.9** | — |
| quiescent | 1.84 | **1.76** | — |
| **total, full white** | **10.5** | **14.66** | **15** |

The strip ran **30% under datasheet**; the board runs **2% under**. Both were
measured correctly — they are simply different LEDs from different bins, which
is the whole reason a strip figure must not be used to model a board.

Two-point fit against the real board:

| state | duty (`max(r,g,b)/255`) | measured |
|---|---|---|
| master's idle rainbow (`>>3`) | 31/255 = 12.2% | **0.083 A** |
| pressed solid red `{200,0,0}` | 200/255 = 78.4% | **0.296 A** |

Solving both unknowns gives `Ifull = 12.9 mA`, `Iq = 1.76 mA` — and that
quiescent independently reproduces the documented 1.84 mA/pixel to within 4%,
so the **model's structure is confirmed and only the constant moved.**

**⚠ Do not compare 12.9 against the datasheet's 15 mA directly — they are not the
same quantity.** 12.9 is the PWM-scaled component with quiescent fitted
*separately*; at full white you add it back: **12.9 + 1.76 = 14.66 mA/pixel,
within 2% of the datasheet's 15.** So the datasheet figure evidently already
includes quiescent, and the budget built on it is **confirmed accurate, not
merely conservative**: 25 × 14.66 = 0.37 A + 60 mA brain = **0.43 A per panel
against the budgeted 0.44 A**, and **6.28 A whole-pad against 6.34 A**. The
entire 12V chain — PSU, gauges, fuse, connector ratings — was sized from 15
mA/pixel and that number now stands measured to ~1%.

What the 8.7 figure *does* break is anything that used it to predict animation
power — that under-predicts by half. Budget and model are different jobs: the
budget asks "how big must the supply be", the model asks "what does this frame
actually draw". **Measurement caveat:** USB was connected, so the
brain ran off VBUS through `U304` and this is essentially pure LED current; add
the brain's ~60 mA separately for a 12V-only panel.

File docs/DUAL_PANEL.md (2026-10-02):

# Dual-Panel (carrier + brain) — as-built reference

**This is the panel design that gets built.** The single-board `hardware/panel-pcb`
was retired on 2026-08-04 when the two-board split won; it is not in the working
tree any more, only in git history (last present at `1b41d1c`). The measurements
that decided it are archived at `docs/archive/DESIGN_COMPARISON.md`.

Everything below is read out of the current KiCad files — the schematic netlist
(`kicad-cli sch export netlist --format kicadxml`) and `dual-panel.kicad_pcb` —
not carried forward from plans. Last derived **2026-08-04**.

## Project shape

One KiCad project, two hierarchical sheets, **one `.kicad_pcb` holding both board
outlines** so they fab and assemble as a single panel:

```
hardware/dual-panel/
  dual-panel.kicad_sch     root — two sheet symbols, nothing else
    carrier.kicad_sch      LED field + every external connector + switches
    brain.kicad_sch        RP2040, flash, transceiver, regulators, USB
  dual-panel.kicad_pcb     BOTH outlines
  panel/                   panelisation + JLC fab package (gen_panel.py, gen_fab.py)
  fit-test/                1:1 printable cavity fit template
```

KiCad has no multi-board feature, but one project is already one hierarchy → one
netlist → one board file, and two `Edge.Cuts` outlines is the supported way to
panelise. The payoff is that **ERC polices the board-to-board interface** — the
one mistake that would force both boards to be re-spun — and it is one JLC
engineering fee and one PCBA setup instead of two.

| | size | layers |
|---|---|---|
| carrier | 139.30 × 127.10 mm (127 × 127 core, 139.3 across the connector tabs) | 4 |
| brain | 70.91 × 62.75 mm | 4 |

174 footprints total, 1107 vias, 4-layer stackup shared by both boards.

**Reference designators are blocked per sheet: carrier = 2xx, brain = 3xx.**
Every type is contiguous within its block with no duplicates across sheets. This
is the multi-sheet exception r/PrintedCircuitBoard's rules explicitly allow.

## Board-to-board interface — 32 pins, netlist-verified

Four independent 1×8 2.54 mm pairs. **Carrier carries the pin headers on B.Cu
(J210–J213); the brain carries the sockets (J301–J304)** and hangs underneath in
the frame cavity.

Every one of the 32 nets below was checked to land on the same net at both ends.

| | J210 ↔ J301 | J211 ↔ J302 | J212 ↔ J303 | J213 ↔ J304 |
|---|---|---|---|---|
| 1 | `+3.3VDC` | `DIP_ID3` | `+12VDC` | `+3.3VDC` |
| 2 | `GND` | `DIP_ID2` | `GND` | `FSR_North` |
| 3 | `TERM_SENSE` | `DIP_ID1` | `GND` | `FSR_West` |
| 4 | `GND` | `DIP_ID0` | `GND` | `GND` |
| 5 | `RS485+` | `GND` | `LED_DATA_5V` | `GND` |
| 6 | `RS485−` | `INT_OUT` | `GND` | `+12VDC` |
| 7 | `GND` | `GND` | `SWCLK` | `GND` |
| 8 | `FSR_East` | `FSR_South` | `SWDIO` | `DEBUG_LED` |

**16 signals, 4 rail pins (+3.3VDC ×2, +12VDC ×2), 12 GND.** Each of the four FSR
lines sits on a different connector with GND adjacent, and `LED_DATA_5V` — the only
fast-edged single-ended signal — is on J212 with GND on both sides, away from every
FSR line.

Two things worth knowing about this interface:

- **USB does not cross it.** `USB_D±`, `VBUS` and `USB_BOOT` are all brain-local
  now that J305 and SW301 moved there (2026-07-28). Earlier planning documents
  that show USB-C on the carrier and a 34-pin two-row interface describe a design
  that was never built.
- **`+3.3VDC` is load-bearing, not a probe convenience.** The four FSR connectors
  sit on the carrier while their dividers sit on the brain, so this rail is the
  **FSR excitation supply** and the reference the ADC readings are ratiometric to.
- **180° rotation is prevented geometrically** — the four rows sit at unequal
  distances from the brain's centreline, so a rotated brain physically will not
  seat. That matters: rotated, `+12VDC` would land on the `+3.3VDC` pin.

## RP2040 (U306) GPIO map — netlist-verified

**This differs from the retired `panel-pcb` map. Firmware must use these.**
The prototype firmware in `firmware/panel/` predates both boards and uses
breadboard pin numbers; it is not a reference for either.

| pad | function | net |
|---|---|---|
| 2 | GPIO0 | `RS485_TX` |
| 3 | GPIO1 | `RS485_RX` |
| 6 | GPIO4 | `RS485_DE` (DE + R̅E̅ tied) |
| 13 | GPIO10 | `TERM_SENSE` |
| 14 | GPIO11 | `LED_DATA` (→ U301 shifter → R301 330R → carrier) |
| 27 | GPIO16 | `DEBUG_LED` |
| 28 | GPIO17 | `SENSE_12V` |
| 29–32 | GPIO18–21 | `DIP_ID3`, `DIP_ID2`, `DIP_ID1`, `DIP_ID0` (bit order reversed) |
| 34 | GPIO22 | `INT_OUT` — open-drain to master, the sole gameplay press path |
| 38–41 | GPIO26–29 / ADC0–3 | `FSR_South`, `FSR_West`, `FSR_North`, `FSR_East` |
| 25 | SWDIO | `SWDIO` (SWCLK on pad 24) |
| 46/47 | USB_DM / USB_DP | brain-local, behind R305/R306 27Ω |
| 51–56 | QSPI | `QSPI_SD3/SCLK/SD0/SD2/SD1/SS` → U307 flash |
| 20 | XIN | X301 12 MHz |

**16 of 30 GPIO used.** Spare: 2, 3, 5–9, 12–15, 23–25.

### Pin-capability audit (2026-08-04)

Checked every assignment against the RP2040 datasheet's GPIO function table.
**No blockers — the board is wired correctly. Four things firmware must know:**

- ✅ **`RS485_TX`/`RS485_RX` are on GPIO0/GPIO1, which really are UART0 TX/RX.**
  Hardware UART, not PIO. (GPIO16/17 would have been the other UART0 pair, and
  they're used for other things — no conflict.)
- ⚠ **`RS485_DE` on GPIO4 is not a UART0 RTS pin** — those are GPIO3, 15 and 19.
  DE must be driven in software (or by a PIO UART), timed off the TX FIFO
  draining. This is not a layout mistake: the RP2040's PL011 has no RS-485
  auto-direction mode on *any* pin, so no pin choice would have bought it. But
  it is the classic RS-485 bug — **release DE too early and the last byte is
  truncated, too late and you collide with the next talker.** The breadboard
  prototype already ran 1 Mbps with manual DE and 0 CRC errors, so the approach
  is proven; it just has to be re-derived on the real pin.
- ⚠ **`SENSE_12V` on GPIO17 is a digital threshold, not a measurement.** Only
  GPIO26–29 have ADC, and all four are taken by FSRs — **there is no spare ADC
  channel.** The divider is sized for a clean presence detect, verified from the
  netlist:

  | | |
  |---|---|
  | divider | R313 100k / R314 33k → ratio 0.2481 |
  | at 12.0 V | 2.977 V at the pin |
  | reads HIGH above | 8.65 V input (VIH = 0.65·3V3 = 2.145 V) |
  | reads LOW below | 4.65 V input (VIL = 0.35·3V3 = 1.155 V) |
  | over-voltage | divider alone survives to 14.5 V; **D303 clamps to +3.3VDC** past that |
  | quiescent | 90 µA |

  So it answers "is the 12 V bus up?" with a wide, safe hysteresis band. It
  cannot report *what* the rail voltage is, and adding that later would mean
  giving up an FSR channel.
- ⚠ **`INT_OUT` on GPIO22 must be emulated open-drain.** The RP2040 has no true
  open-drain output mode. Assert = drive output LOW; release = switch the pin to
  **input (hi-Z)**, never drive it HIGH. Driving push-pull would fight the
  master's 10 k pull-up and break the documented safe-failure behaviour
  (disconnected wire reads HIGH = not pressed). The pin itself is fine; this is
  purely a firmware contract.

Everything else is a plain SIO input or output with no special requirement:
`TERM_SENSE` (GPIO10), the four `DIP_ID` lines (GPIO18–21, internal pull-ups, no
board resistors), and `DEBUG_LED` (GPIO16 — PWM0A is available on that pin if
brightness control is ever wanted). `LED_DATA` on GPIO11 is driven by PIO, which
can drive any GPIO.

> **`SENSE_12V` on a non-ADC pin is CLOSED — do not raise it again.** The
> 2026-07-23 external AI review raised it as its finding F1; the user confirmed
> then that 12 V sense is a **digital present/absent check only** — it gates
> whether it is safe to drive the WS2815s — and was **never** meant to measure bus
> voltage. So a non-ADC pin is correct, not a defect. This was recorded in
> `docs/PANEL_PCB.md`; that file was deleted with the single-board design on
> 2026-08-04 and the note was nearly lost, which is why it is restated here.

## Signal conventions (netlist-verified)

Small facts that are easy to get wrong at firmware or assembly time.

- **Panel-ID DIP bit order is reversed.** `SW201` pins 1–4 drive `DIP_ID0`–`DIP_ID3`,
  but on the MCU **GPIO18 = bit 3 … GPIO21 = bit 0**. Switch closes to GND, internal
  pull-ups, so **closed = 0**.
- **`TERM_SENSE`: LOW = terminated.** `SW202` is DPDT — pole A puts `R201` (120 Ω)
  across the pair, pole B reports the state so firmware can never disagree with the
  copper. Wiring as built: pin 2 = `RS485+` (pole-A common), pin 1 → `R201` →
  `RS485−`, pin 5 = `TERM_SENSE` (pole-B common), pin 4 = GND, pins 3 and 6 NC,
  **pins 7/8 are mounting lugs tied to GND**.
- **FSR connectors are `pin 2 = +3.3VDC`, `pin 1 = ADC node`.** The FSR itself is
  non-polarised, so a reversed lead is harmless.
- **WS2815 chain has three endpoints per net, not two** — the backup ring. Verified:
  `LD1 = D203.DOUT + D208.DIN + D213.BIN`. Rule is `BIN(n) ← DIN-signal(n−1)`, the
  **first LED's BIN ties to GND** (D203 pins 5 and 6 are both on GND), and the last
  DOUT is left unconnected. That is ~1.5× the routing of a plain daisy chain and it
  is deliberate: it lets the chain survive one dead LED.
- **The 25-LED field is wired serpentine** — rows alternate direction, same physical
  topology as the stock SMX panel. Animation tooling has to account for the mapping;
  see `docs/ANIMATIONS.md`. The row of 3 is intentionally rotated 180° from the row
  of 4, which is a consequence of that layout and not a placement error.
- **Support pins:** `RUN` = R307 10 k pull-up; `QSPI_SS` = R310 10 k pull-up —
  **fitted deliberately, it closes an early-power-ramp race** — plus R309 1 k to
  `SW301` BOOTSEL; `ADC_AVDD` = R308 200 Ω from +3.3VDC into C318 2.2 µF.

## Layout and routing

- **4 layers, JLC 4-layer standard** (0.3/0.45 via class): L1 components + signals,
  **In1 and In2 are BOTH solid GND, never split** (layer names `GND1.Cu`/`GND2.Cu`);
  B.Cu spillover + GND pour. There is **no 12 V plane** — 12 V is a routed trace
  tree (2 mm trunk, ≥0.5 mm LED branches, verified by widest-path analysis
  2026-08-06), and the 3.3 V/5 V islands are small F.Cu pours at the regulators,
  not inner-layer pours. An earlier draft of this file described In2 as power
  pours; that was never the as-built board. Chosen for analog noise —
  high-impedance FSR lines sharing a board with 25 switching LEDs — not for
  routing density.
- ⚠ **The two boards need SEPARATE GND zones, and this has already broken once.**
  As built there are **four** zones: `GND_Planes` (priority 0, carrier, 4 layers),
  **`GND_Brain` (priority 1, brain, 4 layers)**, and the two F.Cu regulator islands
  `LD0 5VDC AMS` (2) and `LD0 3.3VDC` (3).

  `GND_Brain` was **deleted by commit `96f43c0` (2026-08-03, the shifter swap —
  a 62 704-line full-file rewrite)** and the loss went unnoticed because
  `GND_Planes` was then simply stretched east to cover both boards. That fills
  correctly in KiCad, so **DRC, ERC, schematic parity and an external review all
  passed** — but KiKit extracts each board with a rectangular `sourceArea`, so the
  one spanning zone was attributed to the carrier and clipped to it, and **the
  brain came out of panelization with no ground pour on any of its four layers.**
  Two fab packages were generated in that state. Restored 2026-08-17.

  A zone spanning the split cannot survive panelization. `gen_panel.py` now fails
  the build if any board ends up without a ground pour on every copper layer.
- **Assembly is double-sided**: 115 SMD placements, **101 top / 14 bottom**. THT
  (connectors, switches, the interface headers) is hand-soldered, not JLC.
- **High-current path:** at the IN connector of a column's first panel the 12 V
  daisy-chain carries **~1.3 A** (three panels), of which ~0.9 A passes through
  to OUT and ~0.44 A is local — fat copper on L1/In2 is now generous rather than
  necessary. **Corrected 2026-08-16** from 3.7 A / 1.24 A: the WS2815 datasheet's
  15 mA is **per pixel, not per channel** (three dies in series, unlit ones
  shorted out), so per-LED draw is ~15 mA, not 47 mA. Bench-measured at
  10.5 mA/pixel. See `hardware/harness/README.md` → "Power budget".
- **10 nF ADC caps sit physically at the RP2040 pins.** The crosstalk fix is
  placement-sensitive; do not relocate them for routing convenience.
- **QSPI is length-matched to a 20 nm spread across the five data/clock nets**
  (19.82 mm each, 0.15 mm wide). Do not disturb it. Width changes are safe — they do
  not affect length.

### Trace / via width conventions (the user's routing rules)

| Class | Trace | Via |
|---|---|---|
| 12 V trunk (IN/OUT + ground return, ≤1.3 A) | 2 mm | 0.6 mm |
| LED power feeds off the 12 V plane + grounds | 1 mm | 0.3 mm |
| 5 V / 3V3 top-layer power | 1.5–2 mm | 0.6 mm |
| Data | 0.2 mm (0.15 mm where needed, e.g. the QFN escape) | 0.3 mm |
| Ground (non-trunk) | 2 mm | 0.3 mm |
| Decoupling | ~2 mm, short beats wide | 0.3 mm |
| QSPI | **0.15 mm**, length-matched | — |
| USB / RS-485 | per impedance below | — |

**CLOSED 2026-08-16 — no re-route needed.** This was opened when the class
current appeared to rise from 2.7 A to 3.7 A, leaving 2 mm of 1 oz outer copper
at only a 1.05× margin. That rise came from misreading the WS2815 datasheet's
15 mA as per-channel; the real class current is **1.3 A**, against ~3.9 A for
2 mm of 1 oz outer copper at a 10 °C rise — a **3× margin**. The trunk and its
vias are comfortably oversized as drawn. Nothing to widen; nothing to decide.

As-built deviation worth knowing: **`XIN`/`XOUT` are routed at 0.2 mm, not the
0.15 mm the table implies.** That is fine — the 0.15 mm figure exists for the QSPI
pinch at the QFN escape, not for crystal nets.

### Differential pairs

Measured from the board, not calculated forward:

| pair | width / spacing | length | layers |
|---|---|---|---|
| `USB+` / `USB−` | 0.25 mm / 0.1375 mm | 3.02 / 3.04 mm | F.Cu only |
| `RS485+` / `RS485−` | 0.15 mm / 0.2 mm (~119 Ω) | 209.06 / 208.05 mm | F.Cu + ~34 mm B.Cu each |

USB is now **3 mm long**, because the receptacle moved onto the brain right beside
the RP2040 — impedance control is close to irrelevant at that length, and the
0.1375 mm pair spacing is deliberate coupling, not a clearance violation. RS-485
mismatches by 1.01 mm over ~208 mm; at 1 Mbps that is ~7 ps, i.e. nothing.

Impedance figures come from Hammerstad-Jensen cross-checked against IPC-2141 (they
agree within 5%); ±10% is the honest band for a non-impedance-controlled order.

**Retired finding — do not port it forward.** `panel-pcb` had deliberate one-sided
B.Cu hops on `USB_D+` and `RS485+`, where one conductor dove to B.Cu to cross under
its partner because the pair arrived in the wrong order for its destination pins.
Every automated review flagged them (2026-07-23 findings F7/F8) and they were
closed WONTFIX. **They do not exist on `dual-panel`** — verified: both USB legs are
F.Cu-only across 3 segments each, and both RS-485 legs carry a comparable amount of
B.Cu (~34 mm) because the pair crosses the board-to-board interface, which is not a
crossover. If a future review reports a one-sided hop, it is a new finding.

> **The stackup lesson, so it is never re-derived.** On `panel-pcb` the pairs were
> first drawn at USB 0.528 mm / RS-485 0.2787 mm — correct for KiCad's **default**
> stackup (3 × 0.48 mm FR4), which is what they had been calculated against. Applying
> the real JLC 4-layer stackup put the reference plane at **0.2104 mm** instead of
> 0.48 mm. Impedance follows w/h, so a 2.28× thinner dielectric needs a ~2.1×
> narrower trace; the original geometry was landing near 55 Ω / 92 Ω.
> **Rule of thumb: 90 Ω USB on a normal 4-layer stackup is 0.2–0.3 mm. If you have
> drawn 0.5 mm, the stackup is wrong.**

## Physical

127 × 127 mm carrier core (real edges 128/127/128/127), mounting holes 4.5 mm on
114 mm centres except the top pair at 113 mm, LED lattice at 33.5 mm column /
17 mm row pitch — all measured off the stock board and confirmed with a 1:1
printout (`stock-smx/PANEL_PCB.md`). **X is locked at ~127 mm by the edge
connectors; Y has ~20 mm of slack per end** if a future revision needs it. Height
budget above the PCB is ~35 mm.

Silkscreen: "Kraken Pad by SenPi / Rev. 1.0", JLC order-number placeholder on
B.Silkscreen, and the project logo.

⚠ **Corrected 2026-08-18: the logo is SILKSCREEN, not exposed copper.** This line
previously described it as "exposed GND copper via the mask-opening technique"
with artwork still pending. Verified against the board — all graphics live on
`F.Silkscreen` (10 items) and `User.Drawings` (5); **there is no copper/mask logo
pair anywhere.** The stale claim mattered because it was the stated reason the
surface finish was an aesthetic choice, which propagated into
`docs/PRE_ORDER_CHECKLIST.md`. Finish is **ENIG**, decided on solderability and
probe life, not appearance.

## Passthrough variant

A carrier populated with only connectors + the termination switch + R201 is
electrically a valid passthrough: power and RS-485 are bused connector-to-connector,
and INT floats safe-HIGH at the master. Mechanism is KiCad per-symbol DNP → a second
BOM/CPL export, so it is **one bare-PCB SKU with two assembly variants**. Nothing is
built yet — see `docs/MODULAR_PANEL_COUNT.md`.

## Accepted-for-rev-A risks

Bring-up measurements, **not order blockers** — these were accepted deliberately:
U303 thermal at real load (~50 mA), +5 V rail margin, INT-into-a-dead-panel (the
master-side 10 k pull-up is deliberately *not* stiff for exactly this case),
hot-plug/USB-attach behaviour, SI asymmetries, and the FSR runs on B.Cu.

## Carrier (2xx) — 76 parts

| block | designators |
|---|---|
| LED field | 25× WS2815 **D203–D227**, pin-1 100nF **C203–C227** (Cn pairs with Dn) |
| bulk | **C201** 470µF 25V elec |
| FSR connectors | **J201** W, **J202** S, **J203** E, **J206** N — JST B2B-PH-K (C131337). Dividers are on the brain |
| power | **J205** 12V_IN, **J208** 12V_OUT — Micro-Fit 43650-0200 (C192562) |
| RS-485 | **J204** IN, **J207** OUT — Micro-Fit 43650-0300 (C503478); **SW202** termination (SS22E01L5, C609835) + **R201** 120Ω; shield network **R202** 1M ‖ **C202** 100nF |
| INT | **J214** WJ500V-5.08-2P (C8465), **D201** SMAJ5.0A, **R203** 100Ω |
| panel ID | **SW201** 4-pos DIP (DS-04, C52177925) |
| SWD | **J209** 3-pin PZ254V-11-03P (C2937625) |
| debug LED | **D202** + **R204** 1k |
| interface | **J210–J213** 1×8 headers, B.Cu |
| mechanical | **H201** (86.83, 106.19), **H202** (123.03, 53.86), **H203** (146.03, 108.06) |
| test points | TP201–TP218, from the netlist: **+12VDC** TP203, TP205 · **TERM_SENSE** TP201 · **RS485+/−** TP202/TP204 · **+3.3VDC** TP206 · **INT** (`D201` K) TP211 · **LED_DATA_5V** TP214 · **LED chain nodes** LD6/LD12/LD18/LD23 = TP215/TP216/TP217/TP218 · **GND** TP207–TP210, TP212, TP213. ⚠ Nine of these footprints carry a wrong *Value* field (most say `GND`); fab layer only, not printed. Corrected 2026-10-02 |

Protection lives at the ports on the carrier, so a plug or ESD event clamps
upstream and never crosses the interface.
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

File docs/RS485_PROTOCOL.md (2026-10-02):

# RS-485 Bus Protocol (v0 — prototype)

Status: **v0, prototype bring-up.** Minimal framing; `'L'`/`'F'`/`'f'`/`'C'`/`'c'`
are implemented and bench-proven, **`'I'`/`'i'` (identify) are specified but not
yet implemented** — there is no master firmware yet. Config write/read and
calibration come later; they slot in as new command bytes with the same framing.

## Physical layer

- UART **1 Mbps, 8N1**, half-duplex RS-485 (MAX3485 / THVD1450)
- Master drives the bus by default; a panel transmits only when replying to a
  poll addressed to it
- DE/~RE tied together per transceiver:
  - Teensy: `Serial1.transmitterEnable(pin)` — hardware manages DE automatically
  - RP2040: manual — raise DE, `uart_write_blocking`, `uart_tx_wait_blocking`
    (TX **complete**, not FIFO-empty), drop DE

## Framing

Every message, both directions:

| Offset | Field | Value |
|---|---|---|
| 0 | sync | `0x55` |
| 1 | cmd | command byte |
| 2 | addr | panel ID 0–8, or `0xFF` broadcast |
| 3 | len | payload length (0–80) |
| 4 | payload | `len` bytes |
| 4+len | crc | CRC-8 (poly `0x07`, init `0x00`) over cmd, addr, len, payload |

Receivers hunt for `0x55`, then validate CRC; on mismatch, drop and re-hunt.
(`0x55` can appear inside payloads — the CRC is what actually validates a frame.
Good enough for v0; re-sync loss just costs one frame.)

## Commands

### `'L'` — LED frame (master → panels)

- addr = panel ID (per-panel frame) or `0xFF` broadcast, len 75
- Payload: 25 × RGB triplets, **serpentine LED order** (LED index i at bytes
  3i, 3i+1, 3i+2 = R, G, B)
- Panel displays the frame on receipt. Remote frames take priority over local
  animations; panel falls back to local animation if no `'L'` frame arrives
  within **100ms**.
- Multi-panel: **per-panel addressed `'L'` frames** (addr = panel ID) — working
  as of the 2-panel bench bring-up 2026-07-11. A single big broadcast with
  per-panel offsets was the alternative considered; not needed at current bus
  utilization (~6% single-panel, ~9ms full 9-panel cycle).
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

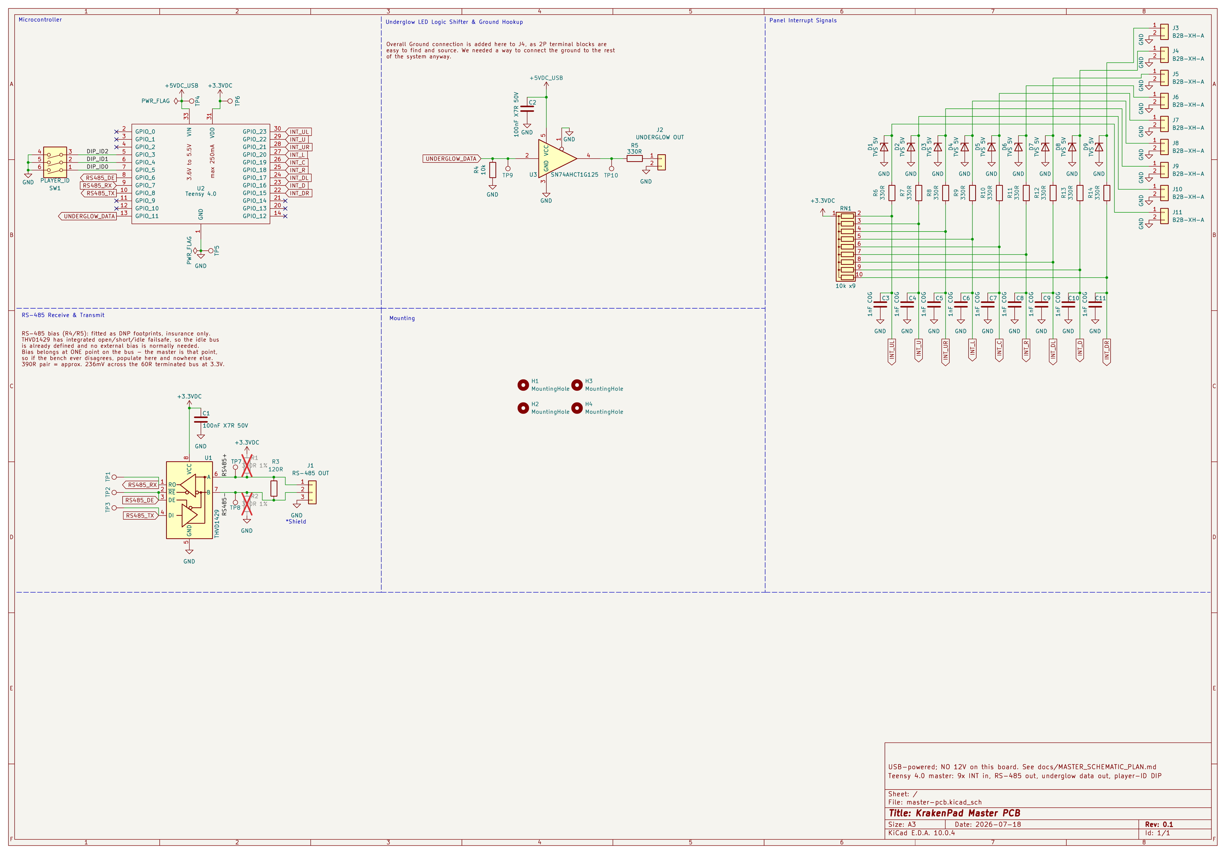
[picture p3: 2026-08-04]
review/01-master/01-schematic-1-master.png

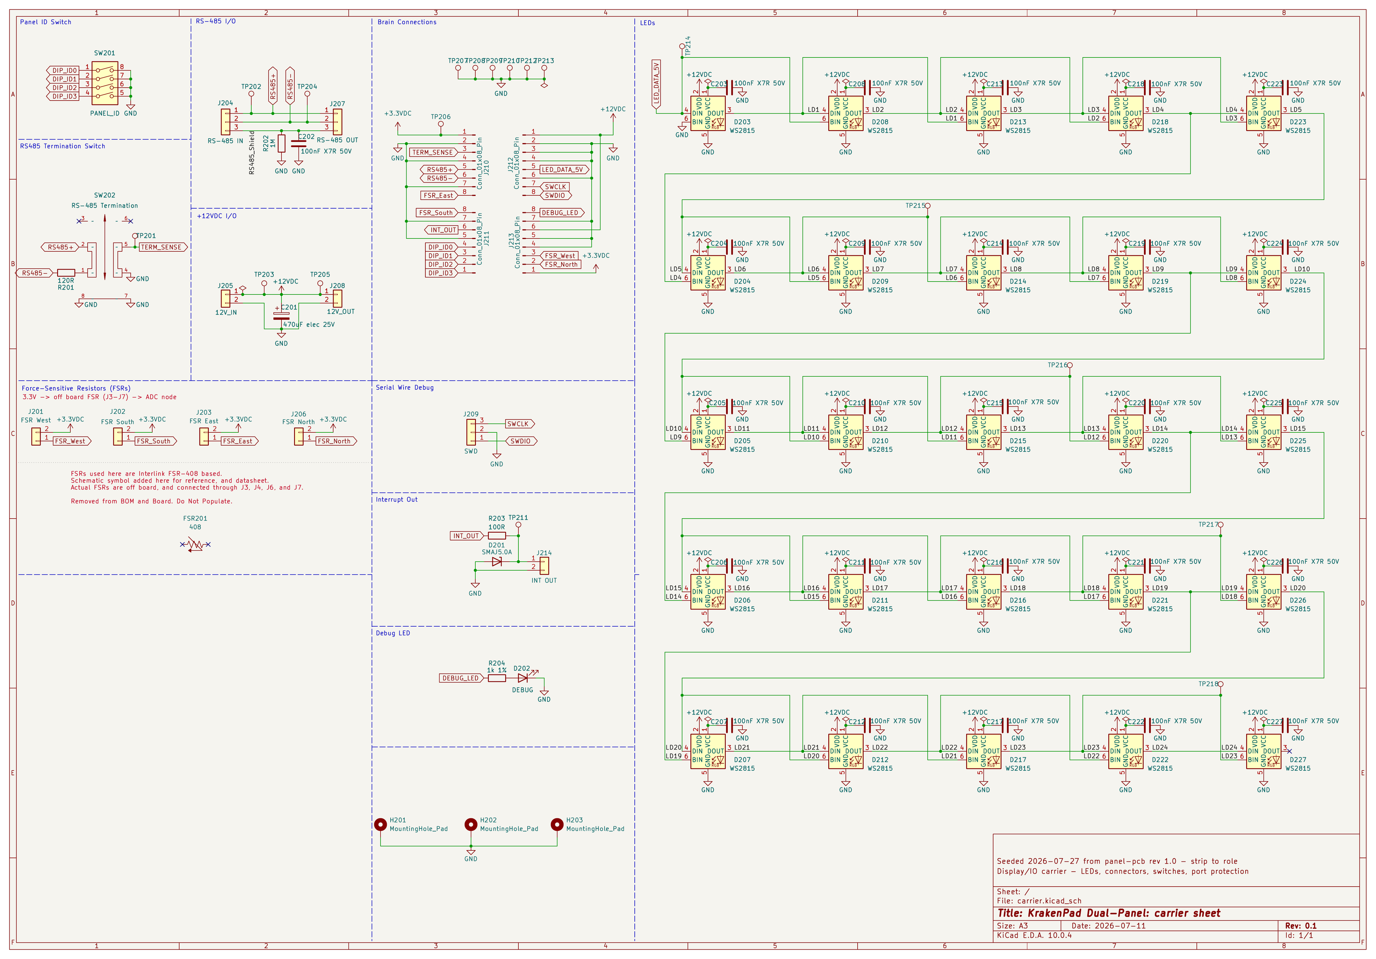
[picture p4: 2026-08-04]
review/03-dual-carrier/01-schematic-1-carrier.png

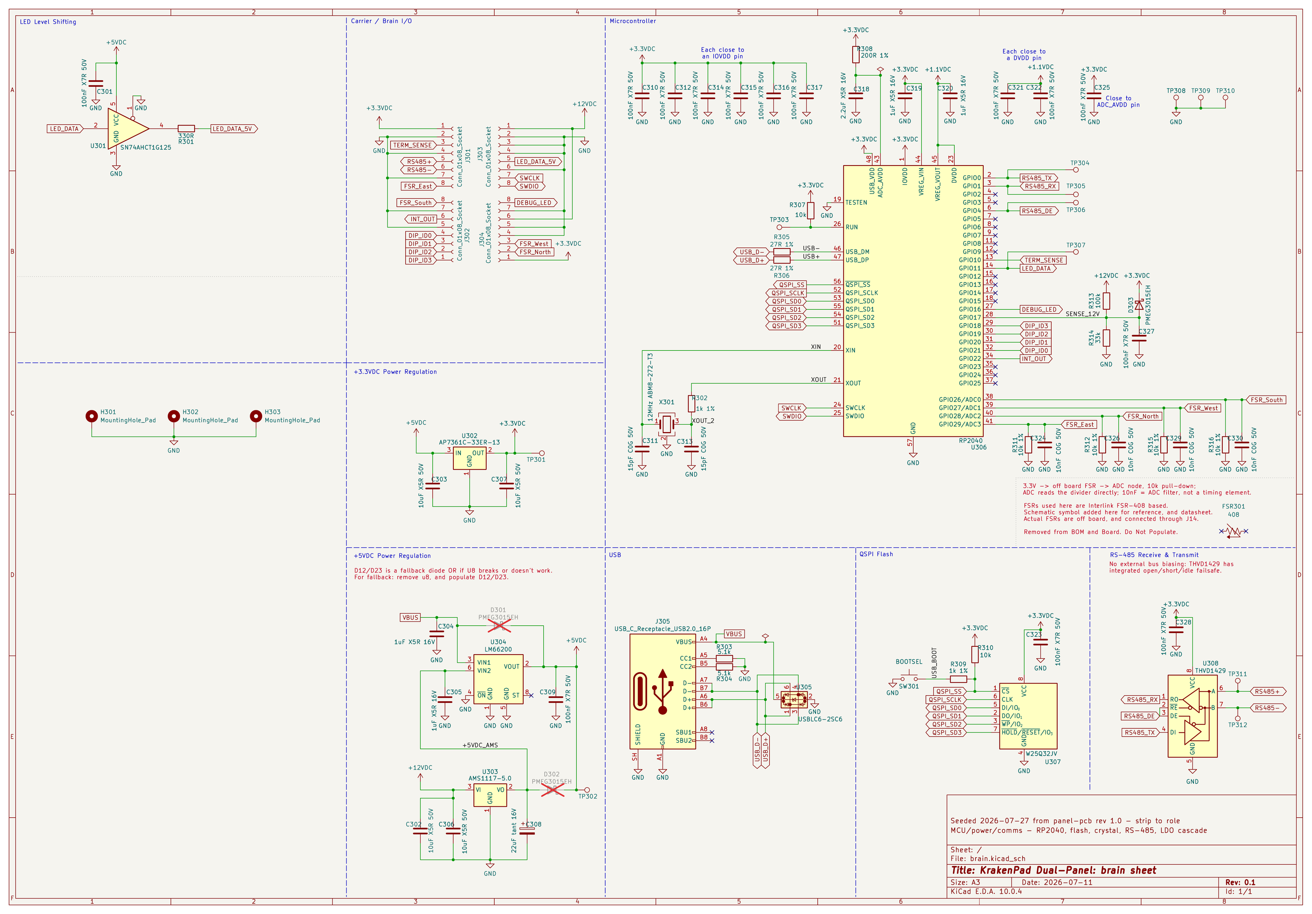
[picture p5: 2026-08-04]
review/04-dual-brain/01-schematic-1-brain.png

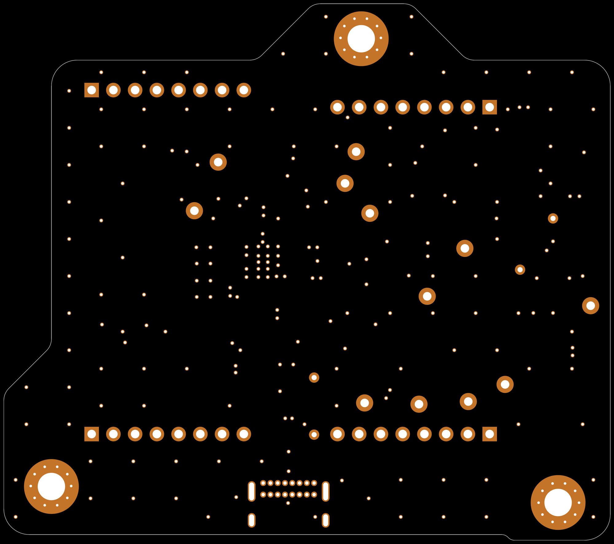
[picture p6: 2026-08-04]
review/04-dual-brain/04-2d-in2.png

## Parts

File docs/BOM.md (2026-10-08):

# Bill of Materials & Sourcing

What we are buying, and from where. Four orders, one section each.

**Build scope: 2 pads = 2 master PCBs + 20 panel assemblies** (2 × 9 + 2 spares).
One fab panel = one carrier + one brain, so that is 20 panels.

> ## ⛔ THE 2-PAD SCOPE IS SETTLED. DO NOT RE-DERIVE IT.
>
> **Every quantity in this document, and every harness quantity in
> `hardware/harness/PARTS.md`, is sized for two complete pads.** That includes
> the cable footage, both PSUs and their XT30 halves, the fuse holders, the
> Wago blocks, the crimps, the housings and the panel markers.
>
> This has been re-questioned more than once — "does the second pad actually
> exist?", "should this be ×1 for now?" — and the answer has not changed.
> **It is ×2. Assume ×2. Do not ask again.** If the scope ever genuinely
> changes it will be edited here first, and this banner will say so.

**This doc is derived from the boards, not maintained by hand.** The
per-part identity lives in the KiCad schematics (`LCSC` / `MPN` fields);
`tools/bom_census.py` reads the `.kicad_pcb` files and prints the need counts
used here. Re-run it after any part change and reconcile before ordering:

```
/Applications/KiCad/KiCad.app/Contents/Frameworks/Python.framework/Versions/Current/bin/python3 tools/bom_census.py
```

⚠ **LCSC prices and stock are point-in-time and have burned us before — verify
live in the cart before committing.** Prices below are the **2026-08-18** cart
export (`tmp/export_cart_20260818_043803.csv`), USD — the audited, all-clear
one. Older exports in `tmp/` predate the USB-C and level-shifter part swaps and
must not be used.

⚠ **Prices drift more than expected.** The USB-C (`C7095263`) was recorded here
as "~16" for 30 and is actually **$31.75** — $1.0583 each, now the second most
expensive line in the order. Re-read the extended price from a live export
rather than trusting any figure in this table.

Superseded material — the DigiKey price snapshot the pivot was measured
against, the AliExpress comparisons, and the hand-solder-vs-JLC-assembly
analysis — is in `docs/archive/BOM_SOURCING_HISTORY.md`.

---

## Order 1 — JLCPCB

> ### 💵 ACTUAL COST, 2026-08-18 — `hardware/dual-panel/panel/QUOTE-2026-08-18.md`
>
> | | |
> |---|---|
> | dual-panel ×20: PCB $174.47 + PCBA $375.41 | $549.88 |
> | master-pcb ×5, bare fab | $8.04 |
> | **merchandise** | **$557.92** |
> | shipping $82.01, coupon −$9.00 | |
> | **shown total** | **$630.93** |
> | ⚠ advanced options (bake $7.88 + cleaning $3.28), billed after review | +$11.16 |
> | **JLC all-in** | **$642.09** |
>
> **Project total: $642.09 + $155.80 (LCSC) = $797.89**, of which **$103.20 is
> shipping** — combine the two shipments, see `ORDER_NOTES.md` §7.
>
> ⚠ **USD, and freight only.** On delivery **UPS billed a further $109.30 CAD** in
> import charges (brokerage + duty + tax) on the JLC parcel — 1.85× JLC's own
> $82.01 shipping line. The LCSC parcel ships separately and may draw its own.
> **Full landed cost: $1,587.51 CAD**, see `hardware/dual-panel/panel/QUOTE-2026-08-18.md`.
>
> **$28.05 per complete assembled panel.**

| Item | Qty | Note |
|---|-----|---|
| Panel, 4-layer, **+ SMD assembly (PCBA)** | 20 | One fab panel = one carrier + one brain. 115 SMD placements/panel, DNP excluded. Part identity comes from the exported BOM/CPL's `LCSC` column and auto-matches. These parts never reach the bench and are **not** in order 2. |
| Master PCB, bare fab only | 2 | Hand-assembled — PCBA's ~$148 fixed overhead buys nothing for 19 parts. |

Files come from `hardware/dual-panel/panel/production/` (gerbers zip + BOM +
CPL), generated by `gen_panel.py` then `gen_fab.py`. **Always regenerate before
ordering** — that directory is gitignored precisely because it is a build
artifact. Upload as a **customer panel**, not a single board. See
`docs/PRE_ORDER_CHECKLIST.md` §1.

Place this order **first or same-day** as order 2, then email
`support@lcsc.com` with both order numbers to combine the shipment.

## Order 2 — LCSC ($138.68 merchandise / **$155.80 delivered**, 30 lines)

> ### ✅ CART AUDIT 2026-08-18 — four defects found, ALL FIXED AND RE-VERIFIED
>
> Reconciled `tmp/export_cart_20260818_042110.csv` against `tools/bom_census.py`.
> The cart had drifted from the design in four ways. **Two would have stopped
> the build outright** — a board cannot be assembled with a part that isn't there.
>
> | # | LCSC | action | why |
> |---|---|---|---|
> | 1 | **C7095263** | ➕ **ADD ~25** | GCT USB4085-GF-A, brain **J305**. Was simply absent. |
> | 2 | **C53184807** | 🗑️ **REMOVE 30** | LCK-TCF829D — the **retired `panel-pcb`** vertical USB-C. Superseded 2026-08-04. |
> | 3 | **C7484** | ➕ **ADD 5** | SN74AHCT1G125DBVR, master **U3**. Was simply absent. |
> | 4 | **C354152** | 🗑️ **REMOVE 5** | SN74AHCT125N quad DIP — superseded by the single-gate part **2026-08-03**. |
> | 5 | **C5383116** | ⬆️ **50 → 100** | Need **80** (4 × 20 boards); MOQ multiple is 50. |
> | 6 | **C7509515** | ⬆️ **50 → 85** | Need **80**; multiple is 5. |
>
> **The pattern is worth noting: the cart was never updated after two part
> swaps.** Items 1–4 are two swaps left half-applied — the old part still in the
> cart, the new one never added. A part swap is not done when the schematic
> changes; it is done when the cart changes too.
>
> **Items 5–6 are the one-pad/two-pad error again**, this time live in a real
> cart: `hardware/harness/PARTS.md` said *"36 for a 9-panel pad, 50 ordered"*
> and the cart was built to it. The scope is **20 panel assemblies**.
>
> **✅ RESOLVED.** All six applied and re-verified against
> `tmp/export_cart_20260818_043803.csv`: every one of the 30 lines meets or
> exceeds need, nothing superseded remains, and there are no unneeded lines.
> Total $118.33 → **$142.93**.
>
> ### 🔄 UPDATE 2026-08-18 — RS-485 transceiver swapped in the cart
>
> **`C1850236` (THVD1429DR, 4 pcs, $16.28) → `C2671361` (THVD1450DR, 5 pcs,
> $5.60)** — applied to the live cart by the user. Same SOIC-8 pinout, and it
> covers the master's need of 2 with spares. Rationale is in `CLAUDE.md`; the
> panel-side saving is separate and larger (JLC PCBA, −$52).
>
> **Final live figures at order time: merchandise $138.68**, i.e. **+$6.43 above
> the $132.25 this doc predicted** — ordinary LCSC price drift since the
> 2026-08-18 cart export, exactly what the warning at the top of this file exists
> for. Delivered: $138.68 + $33.19 shipping − $16.07 discounts = **$155.80**
> (the −$16.07 is the *sum* of the $4.07 and $12.00 lines, not a third discount).
>
> **Reproduce this check before any future order** — it is the only step that
> catches cart drift, because both docs already listed the correct parts:
> ```
> python3 tools/bom_census.py            # need, from the boards
> # then diff the total column against a fresh LCSC cart export
> ```

Everything hand-soldered on both boards, plus the harness connectors.
**Combined-shipped with the JLC order**, so it carries no extra freight.
Constraints on combining: same currency and customer ID, not to Mainland
China, cannot be unbound afterwards, shipping is recalculated. If either order
has already shipped, it's too late.

### Panel through-hole (21 placements/board × 20)

Refs are `dual-panel`'s — **carrier 2xx, brain 3xx**. Re-derived from the board
2026-08-04 with `tools/bom_census.py`; the old `panel-pcb` numbering is in
`docs/archive/REFDES_TRANSLATION.md`.

| LCSC | Part | Refs | Board | Need | Cart | Ext $ |
|---|---|---|---|---|---|---|
| **C503478** | Molex Micro-Fit 3.0 3-pin RA header (436500300) | J204, J207 (+ master J1) | carrier | 42 | 50 | 21.10 |
| **C192562** | Molex Micro-Fit 3.0 2-pin RA header (436500200) | J205, J208 | carrier | 40 | 50 | 19.93 |
| **C131337** | JST B2B-PH-K-S 2-pin 2mm vertical (genuine JST) | J201, J202, J203, J206 | carrier | 80 | 100 | 3.53 |
| **C7095263** | GCT USB4085-GF-A USB-C, horizontal all-THT | J305 | **brain** | 20 | 30 | **31.75** |
| **C8465** | KANGNEX WJ500V-5.08-2P screw terminal | J214 (+ master J2) | carrier | 22 | 30 | 4.01 |
| **C52177925** | Zhongdi DS-04 DIP slide, 4-pos | SW201 | carrier | 20 | 30 | 6.03 |
| **C609835** | XKB SS22E01L5 DPDT slide | SW202 | carrier | 20 | 25 | 4.37 |
| **C2937625** | XFCN PZ254V-11-03P pin header 1×03 (SWD) | J209 | carrier | 20 | 50 | 0.94 |
| **C5383116** | HanElectricity 2541WV-08P 1×8 header, **6.0mm mating pin / 3.0mm tail**, gold | J210–J213 | carrier | 80 | 100 | 0.87 |
| **C7509515** | CONNFLY DS1023-1x8SF11 1×8 socket, 8.5mm body, gold | J301–J304 | **brain** | 80 | 85 | 6.65 |

**Two corrections landed 2026-08-04, both from re-deriving against the real board:**

- **USB-C was listed as the wrong part.** `C53184807` (LCKELEC LCK-TCF829D,
  vertical) is the *retired* `panel-pcb` pick. `dual-panel` uses the **GCT
  USB4085-GF-A, `C7095263`**, horizontal, on the **brain**. The LCK footprint
  survives in `dual-panel.pretty` as a revert path, but it is not what is on the
  board.
- **The 8 board-to-board interface connectors were missing entirely** — 160 pieces
  across the build. **Sourced 2026-08-16** (rows above). The load-bearing spec is
  mating-pin length: separation is set by the two plastics meeting, not by pins
  bottoming out, and some "short" headers trim the *tail* instead, leaving nothing
  to solder through the carrier. ⚠ **These parts stack to 11.04 mm, so they need
  12 mm M3 spacers, not the 11 mm the mechanical stack assumed** — see
  `docs/DUAL_PANEL.md` → "Mechanical stack".

The 30 test points are bare probe holes; `SW301` (BOOTSEL) is SMD on the brain, so
JLC places it. Neither is ordered.

### Master — all of it (hand-assembled, SMD included)

| LCSC | Part | Refs | Need | Cart | Ext $ |
|---|---|---|---|---|---|
| **C2671361** | TI THVD1450DR RS-485 transceiver, SOIC-8 | U1 | 2 | **5** | **5.60** |
| **C7484** | TI SN74AHCT1G125DBVR single buffer, SOT-23-5 (was C354152 quad DIP, swapped 2026-08-03) | U3 | 2 | 5 | 0.23 |
| **C840655** | Bourns 4610X-101-103LF 10k ×9 bussed, SIP-10 | RN1 | 2 | 5 | 1.66 |
| **C46595747** | DORABO DS-3P-BU DIP slide, 3-pos | SW1 | 2 | 5 | 1.23 |
| **C2905420** | KH-2.54FH-1X14P-H8.5 female 1×14 socket | U2 socket (2/board) | 4 | 10 | 1.52 |
| **C113952** | SMAJ5.0A TVS, DO-214AC (MDD) | D1–D9 | 18 | 40 | 1.64 |
| **C844839** | 330R 1% 0805 (Vishay) | R5, R6–R14 | 20 | 50 | 0.75 |
| **C1791** | 1nF C0G 0805 (Samsung) | C3–C11 | 18 | 30 | 0.35 |
| **C83055** | 100nF X7R 0805 (Walsin) | C1, C2 | 4 | 10 | 0.24 |
| **C844816** | 120R 1% 0805 (Vishay) | R3 | 2 | 100 | 0.86 |
| **C192906** | 10k 1% 0805 (Yageo) | R4 | 2 | 50 | 0.90 |
| **C158012** | JST B2B-XH-A 2-pin 2.5mm vertical THT | J3–J11 (INT) | 18 | 40 | — |

Master J1 and J2 share the panel's Micro-Fit and terminal lines above.

⚠ **Some of the master resistors that arrived have no value marking on the body**
(found at the bench, 2026-10-02). They work, but a hand-assembled board is easier
to place and check when every resistor carries its code. **Next order (masters
#3–#5 and any rev 2): check the datasheet's marking line before buying.** Which
of the three resistor lines above were unmarked is not recorded yet.

**J3–J11 replaced the 9-pos Euroblock 2026-07-26** (INT went to twisted
pair, signal + dedicated GND). That moved the INT connector off the AliExpress
order and onto this one. Nine per board, 18 for two pads.

**Two of these part numbers also appear on the panel, and the quantities here
deliberately do not cover that:** the panel's D201 (SMAJ5.0A, **C113952**) and U308
(THVD1450, **C2671361**) are SMD, so **JLCPCB sources and places them** as part
of order 1. Only the master's 18 TVS and 2 transceivers are hand-soldered and
bought here. Checking design totals against this table will therefore look 20
TVS and 20 transceivers short — that is correct, not an under-order.

### Harness (not on any board)

| LCSC | Part | Need | Cart | Ext $ |
|---|---|---|---|---|
| **C114089** | Molex 436450200 Micro-Fit 2-ckt receptacle housing | 30 | 50 | 3.79 |
| **C259740** | Molex 436450300 Micro-Fit 3-ckt receptacle housing | 36 | 50 | 5.68 |
| **C259786** | Molex 430300001 Micro-Fit crimp, 20–24 AWG | 168 | 300 | 4.47 |
| **C144401** | JST XHP-2 2-pos housing (INT, wire side) | 18 | 50 | — |
| **C385122** | JST SXH-001T-P0.6N XH crimp, 22–26 AWG | 36 | 100 | — |
| **C157907** | JST SMR-03V-B 3-pos housing — **underglow custom-length leads; ordered without contacts, needs `SYM-001T-P0.6` (not yet bought, 2026-10-07)** | 1 | 10 | 0.77 |
| **C99102** | XT30U-**F** — PSU side of the 12V trunk (recessed sockets) | 2 | 10 | 2.06 |
| **C99101** | XT30U-**M** — our trunk + the cut stock tail (exposed pins) | 4 | 10 | 2.28 |

**XT30 added 2026-08-17.** Solder-cup, so no crimp tool — the only connector in
the pad that needs none. **Female goes on the PSU**: its contacts are recessed,
so the permanently-live side is shrouded and our male pins are dead whenever
unplugged. Two males per pad because one goes on the **cut stock 20 AWG tail**,
which is what keeps the PSU modification reversible. ⚠ Verify gender by looking
at the parts — put whichever half has *sockets* on the supply.

Housing/crimp counts derive from the stock SMX topology: 3 power columns of 3
panels (5 housings per column × 3 × 2 pads = 30), RS-485 serpentine with 9
segments × 2 ends × 2 pads = 36 housings. Buy crimps in bulk — crimping has a
learning curve.

**Micro-Fit crimp count rose 132 → 168 on 2026-07-26:** RS-485 3-pin housings
now populate **all three** circuits, because pin 3 carries the cable shield
(36 housings × 3 = 108, plus 60 for power). The third position is no longer
empty — keying against 2-pin power is the 3-circuit housing itself, and pin 3
carries shield only, so a mis-mate still cannot put 12V on a transceiver.

XH counts: 9 INT connectors per pad × 2 pads = 18 housings, 2 contacts each =
36. 100 contacts ordered deliberately — XH crimping wants practice crimps.

Power feed cables crimp only the panel end. **The PSU end is not crimped at
all** — it is bare conductor into a Wago 221-415 lever block, fed from the PSU
through an XT30 pair and an inline T8A fuse. The old "fork/spade lugs at the PSU"
line was a pre-teardown assumption: there is no PSU terminal block and no ground
stud. See `hardware/harness/12v-trunk.yml`.

## Order 3 — DigiKey / PJRC ✅ COMPLETE

| Item | Qty | Note |
|---|-----|---|
| Teensy 4.0 (PJRC 15583) | 2 | ✅ **PURCHASED AND IN HAND.** ~$36 each, the one part LCSC never carries. |

**This order is closed — nothing further to buy from DigiKey/PJRC.**

## Order 4 — AliExpress

Commodity items and the two things the other vendors don't win. Each candidate
needs its match-check to pass before ordering.

| Item | Qty | Candidate | Match-check |
|---|-----|---|---|
| 12V power cable, 2C 20 AWG jacketed | **12.8m needed → 20m (2×10m) ORDERED 2026-08-16** | [1005008621580316](https://www.aliexpress.com/item/1005008621580316.html) | 20 AWG (not 22/24), **stranded**, 2-conductor jacketed round |
| **RS-485 + INT cable, 22 AWG 2-core shielded twisted pair (RVSP)** — **ONE reel, both harnesses** | **27.0m needed → 50m ORDERED 2026-08-16** (30m was the next step down and left only 3m; 50m is ~3.5 pads' worth and the better per-metre price) | [1005006546939974](https://www.aliexpress.com/item/1005006546939974.html) (22 AWG / 2-core option) | **Conductor insulation OD must be 1.30–1.85mm** — see the checks below. Shield **required**: RS-485 lands it on Micro-Fit pin 3, INT trims it |
| Wire ferrules | ✅ **SIZES CLOSED 2026-09-01 — ENOUGH ON HAND 2026-10-07** (~~BUY 100× 0.34 mm²~~; a recount found about 10 spare after the 32 still needed) (bare; match the barrel length to the bin. 0.5 mm² needs no purchase) | domestic | **Both earlier guesses were one size too big.** **0.34 mm² (1.25 mm OD / 0.8 mm ID) ×36** for the J214 INT conductors — the reel measured 24 AWG, not the labelled 22. **0.5 mm² (1.45 mm OD / 1.05 mm ID) ×4** for master J2: the 20 AWG GND tie (DIN CSA column right, vendor labelling wrong — 20 AWG = 0.518 mm², ~80% fill) and the 22 AWG underglow DATA lead (⚠ **not** 0.34 as `PARTS.md`'s 2026-08-16 block says — the 24 AWG finding applies to the RVSP reel only; test-fit one). ~30 of each on hand, so only the 0.34 mm² falls short. ⚠ **First crimps pulled out and the ferrule was not the cause** — the HSC8 6-4 is self-adjusting with no die stations and 0.34 mm² sits at the bottom of its 0.25–6.0 mm² span; tightening its adjustment pin made the conductor snap before the ferrule releases. Both sizes verified good at that one setting. **Wago lever blocks want no ferrule at all.** Full reasoning: `hardware/harness/PARTS.md` → "Ferrules" |
| ~~Colored + printed heatshrink, zip-tie anchors, grommets~~ | — | ✅ **ON HAND / not needed** | **Heat-shrink and zip ties are on hand** — but heat-shrink is **load-bearing** here (it carries the per-panel INT identification, 36 marks), so confirm the stock covers 9 distinguishable colours, or use printed labels under clear. **Grommets were speculative and are dropped as a purchase**: the teardown recorded no frame penetration our harness crosses. Made an assembly-time check instead — see below |

**Where the cable quantities come from (all closed 2026-08-16):** they are
transcribed from the completed stock record, since our harnesses run the same
geometry through the same panel positions — `panel-power-chain.yml` +
`5v-columns.yml` give the 12V columns (0.60m feed ×3 + 0.60m jumpers ×6 =
**5.4m**), `panel-data-chain.yml` gives the RS-485 serpentine (0.60m + 8 × 0.45m
= **4.2m**), and `panel-signal-lines.yml` gives the INT home runs (**9.3m**).
The WireViz BOMs in `hardware/harness/out/` regenerate these totals.

⚠ **Those figures are PER PAD; the Qty column above is for TWO pads**
(corrected 2026-08-16 — the buy quantities had been sized for one pad while
every other quantity in this doc was sized for two, which would have left the
reels short). The 12V line also carries **+1m per pad for the trunk**
(`hardware/harness/12v-trunk.yml`), which is why it reads 12.8m and not 10.8m.
The shielded-pair line is 2 × (4.2 + 9.3) = **27.0m**. Reels sell in 5/10/20/50m
steps, so round up rather than reorder — a second AliExpress order is a second
month of shipping.

### RS-485 and INT are ONE cable now — 22 AWG, decided 2026-08-16

They were two lines (RS-485 "22 AWG", INT "24 AWG"), and `rs485-chain.yml` had
separately drifted to 24 AWG against this doc's 22. Both runs are **2-core
shielded twisted pair** carrying signal-level current, so they are now a single
**22 AWG** reel. Full rationale and the connector-window table:
`hardware/harness/PARTS.md` → "RS-485 and INT share ONE cable".

**22 AWG is the only gauge inside both connector windows** — JST XH needs
insulation OD **≥1.30mm** (24 AWG RVSP measures ~1.3–1.4, right at the floor)
and Micro-Fit needs **≤1.85mm**. Gauge here is purely mechanical; the current is
microamps to milliamps.

Only the shield termination differs: RS-485 lands it on Micro-Fit **pin 3**,
INT trims and heatshrinks it at both ends. Cross-plugging is impossible — the
connectors differ (3-circuit Micro-Fit vs JST XH and a 5.08mm screw terminal).

**Verify before crimping 204 contacts:**

1. **Conductor insulation OD must be 1.30–1.85mm.** This is the *individual
   conductor's* insulation, **not** the outer jacket OD — and it is the one spec
   that can sink this cable. It is rarely listed, so ask the seller or measure on
   arrival. Below 1.30 the XH contact won't grip; above 1.85 the Micro-Fit
   terminal's insulation wings won't close.
2. **Genuinely twisted**, not 2-core parallel/zip.
3. **Stranded, not solid** — solid cracks at the crimp after a few re-dresses.

Checks 2 and 3 are already satisfied by the type code: **RVSP** = R 软 flexible
(stranded) + V PVC + S 双绞 (twisted) + P shielded. Only the OD is open.

### ✅ BOTH REELS LANDED AND MEASURED 2026-08-31 — cable ACCEPTED

No import charges were billed on this delivery (unlike the JLC parcel — see
`hardware/dual-panel/panel/QUOTE-2026-08-18.md`).

| Measured | RVSP (50 m) | 2C power (20 m) | Requirement | |
|---|---|---|---|---|
| Outer jacket OD | ~5.0 mm | ~4.75 mm | *(informational)* | — |
| **Conductor insulation OD** | **~1.45 mm** | **~1.50 mm** | **1.30–1.85 mm** | ✅ **PASS** — 0.15 mm above the JST XH floor, 0.35–0.40 mm under the Micro-Fit ceiling |
| Twisted | genuine twist | n/a | required | ✅ |
| Stranded | yes | yes | required | ✅ |

**Both connector windows clear on both cables**, so the mechanical risk that
made this the gating check is closed. Crimp the 204 contacts.

**Both cables are one gauge step under their markings — copper, and harmless.**
Each was measured by end-to-end resistance, then confirmed against mass and/or
construction:

| | marked | **actual** | shortfall | metal |
|---|---|---|---|---|
| RVSP 50 m | `2x0.3mm²` / 22 AWG | **0.212 mm² — 16/0.13, 24 AWG** | 29% | copper ✅ |
| 2C power 20 m | `STYLE 2464 20AWG` | **0.42 mm² — 21/0.16, 21 AWG** | 22% | copper ✅ |

The power cable was measured as a **single 20 m spool** (the 2×10 m ordered
arrived as one length) shorted at the far end: 2.0 Ω raw, 1.7 Ω after the
meter's 0.3 Ω leads, over 40 m of conductor = 42.5 Ω/km, which is 99% of
nominal 21 AWG. A 21-strand count then fixes the build as **21/0.16** (0.42 mm²)
where the honest 20 AWG is 21/0.18. **CCA is excluded without weighing**: to read
42.5 Ω/km as CCA the conductor would need 0.607 mm², i.e. 21 strands of 192 µm —
thicker than the genuine build, against a caliper reading of 120 µm.
**No build impact** — the worst column drops 135 mV at the far panel against
106 mV for true 20 AWG.

⚠ **Both cables shipped the honest strand COUNT with thinner strands** — RVSP
16/0.13 where 0.3 mm² is 16/0.15, power 21/0.16 where 0.5 mm² is 21/0.18. So
**counting strands never exposes the substitution**; only strand diameter or
resistance does. Note this before accepting any future cable on a strand count.
Note too that this project's calipers read a soft round strand **30–40 µm low**,
consistently — enough to make a good conductor look like a fraudulent one.

✅ **The power cable's `80C 300V` meets the ≥80 °C/300 V spec below**; the RVSP's
70 °C does not and is recorded as an accepted deviation. The cable carrying real
current is the better-rated one.

⚠ **`STYLE 2464` is printed with no UL file number** (no `E…`), so the UL style
claim is decorative rather than a listing. Common at this end of the market; it
means the `20AWG` assertion has no certification behind it.

**Shield construction: foil + braid, NO separate drain wire.** The
braid-as-drain technique already specified under "RS-485 shield" below is
therefore **mandatory, not a contingency** — at every one of the 18 RS-485 ends,
gather the braid, solder a short 22 AWG lead, heatshrink the joint, and crimp
that into Micro-Fit pin 3. The 18 INT ends trim and heatshrink the braid
instead. Budget the extra assembly time.

⚠ **The conductor is 24 AWG copper, not the 22 AWG on the label — CLOSED
2026-08-31. It is copper (the "never CCA" rule below is satisfied), and the
gauge shortfall changes only the ferrule size.** One conductor end-to-end across the 50 m reel
reads **4.5 Ω = 90 Ω/km = 0.19 mm²**; 22 AWG would read 2.65 Ω. The stripped
bundle's ~0.6 mm caliper reading independently gives the same ~0.21 mm², so two
methods agree. **Nothing in the build depends on it except the ferrule barrel** —
the insulation OD passes either way, `SXH-001T-P0.6N` covers 22–28 AWG, and the
current is microamps to milliamps. Two follow-ons: Molex `430300001` covers
20–24 AWG so 24 sits at the **bottom edge** — pull-test the first few Micro-Fit
crimps; and **for rev 2, hold the vendor to the insulation OD, not the gauge in
any unit** — the jacket's own `0.3mm²` was as wrong as the listing's "22 AWG".

> **Pull-test result, 2026-09-08: the Micro-Fit crimps PASS, but only just.**
> Bench-confirmed by the user on the first shield-lead terminations. That is the
> predicted outcome for a conductor sitting at the bottom edge of `430300001`'s
> 20–24 AWG window, and it is **accepted for the prototype pads** — the joint
> holds, the load is milliamps, and the cable is already bought.
>
> ⚠ **It is NOT acceptable for a production run.** "Barely passes" has no margin
> against assembly handling, and a marginal crimp on a differential pair fails
> intermittently rather than cleanly. **If these are ever manufactured in
> quantity, source genuine 22 AWG shielded twisted pair** — specified by measured
> insulation OD and conductor resistance, not by a printed gauge, since this reel
> missed its own marking by 38%. Pull-test every crimp on the prototype build
> rather than the first few.

**CCA was suspected and is ruled out.** A 0.3 mm² CCA conductor measures nearly
the same 84 Ω/km as a 0.2 mm² copper one, so resistance alone could not separate
them — but **resistance × mass cancels the cross-section and fingerprints the
metal**: 84.0 Ω/km × 1.90 g/m = 159.6, against 154.5 for copper and 93.8 for
CCA-15%. Copper, by better than 2×. The construction is `16/0.13` (0.212 mm²)
sold as `2x0.3mm²`. Full working, and the ⚠ warning about inferring CSA from a
stripped bundle's diameter: `hardware/harness/PARTS.md` → "Ferrules". The jacket reads `ZC-RVSP 2x0.3mm² 300/300V JB/T8734.5-2016` — so
the seller's "22 AWG" was an honest conversion of `0.3mm²` and **the cable
misses its own printed marking**, by 38% against the ~65 Ω/km that flexible
class-5 0.3 mm² allows. Full working: `hardware/harness/PARTS.md` → "Ferrules".

The Euroblock line (the master's old 9-pos header + plug) was **removed 2026-07-26** — INT
moved to JST XH, which is sourced on the LCSC order.

Buy mating housings and crimps from the **same** ecosystem — mixing clone
crimps into a different clone housing risks seat/latch failures. Micro-Fit
clones are otherwise fine at this 5A hobby load, but ours are genuine Molex
from LCSC anyway. Watch vertical-vs-**right-angle** on any PCB header.

## Not ordered

| Item | Why |
|---|-----|
| **Panel D301/D302** (PMEG3015EH, C552867) | **DNP** — the LM66200 ideal-diode mux (U304) replaced the Schottky power-OR. Footprints stay so populating both + removing U304 is a hand-solderable rescue |
| **Master R1/R2** (390R 1%) | **DNP** — THVD1450's integrated failsafe makes RS-485 bias unnecessary; footprints exist if the bench disagrees |
| FSR sensors | reuse stock SMX (Interlink FSR 408; iefsr.com if replacements are needed) |
| 18 AWG stranded (underglow / GND tie) | on hand |
| ~~Spade/fork lugs (PSU ends + master GND tie)~~ | **Deleted 2026-08-16 — not needed.** The teardown found no PSU terminal block and no ground stud; the 12V star point is a Wago lever-block fan-out that takes bare conductor, and the master GND tie lands in its own lever port |
| M3 mounting hardware | on hand |
| Master enclosure | future — 3D-print from the KiCad 3D export once boards are in hand |
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

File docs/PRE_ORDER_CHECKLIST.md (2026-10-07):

# Pre-order checklist — dual-panel + master (rev 2.0, rescoped 2026-08-04)

> # 🔒 ORDERED 2026-08-18 — THIS CHECKLIST IS NOW A HISTORICAL RECORD
>
> **Both boards are at fab.** Nothing here is actionable any more; it documents how
> rev 1 was verified. Tag **`rev1-fab`**, artifacts in
> `hardware/fab-archive/rev1-2026-08-18/`. Any change from here is **rev 2**.

Run this top to bottom before paying JLCPCB. ⬜ is open, ✅ is closed.

> 📋 **`docs/ORDER_NOTES.md` is the companion to this file** — the text and
> answers you need *while the order form is open*: what to say about POFV and
> J305, and every DFM flag that is intentional. This file is the process;
> that one is the script.

**Rescoped 2026-08-04.** Rev 1.0 of this doc was written around the single-board
`hardware/panel-pcb`, which was retired when the two-board split won. Where a
closed item below names a part rather than a board, it still holds — the parts are
the same physical parts, only the reference designators moved (carrier 2xx, brain
3xx). Anything panel-pcb-specific has been dropped; it is in git at `1b41d1c`.

**Build scope: 2 fully assembled pads** = 2 master PCBs + **20 panel assemblies**
(2 × 9 + 2 spares). One fab panel = one carrier + one brain, so that is **20
panels**. Every quantity here and in `docs/BOM.md` is sized to that; if the scope
changes, both docs move together.

---

## 0. The blocker

✅ **Pad + harness teardown — done 2026-08-08.** Every component and wire is out.
**J2's 2-pos screw terminal is confirmed final, not interim**: the underglow
strips terminate in a **JST SM 3P female** carrying 12V/DATA/GND, so our side is
an SM 3P male pigtail that sends 12V/GND to the pad's 12V distribution and DATA
alone to J2 pin 1 — no splice, and no change to the master PCB. See
`docs/UNDERGLOW.md`. (There are no "PSU lugs"; distribution is now the Wago
fan-out in `hardware/harness/12v-trunk.yml`.)

Remaining teardown follow-ups, none of which block the board order:

- ✅ **SM 3P pin order resolved 2026-08-08: pin 1 = GND, pin 2 = DATA,
  pin 3 = 12V** — the *reverse* of the earlier assumption. Building to the old
  order would have put 12V into the DATA pin.
- ✅ **Underglow connector — RESOLVED 2026-08-16.** We *do* build this side:
  removing all SMX wiring takes the stock `SMR-03V-B` with it, leaving only the
  strips' moulded plug to mate. **Use a pre-made 3-pin SM 2.5 LED-strip pigtail
  pair (22 AWG, on hand)**, not loose contacts — `SMM-003T-P0.5` is 28–30 AWG
  and cannot crimp our wire. `SMR-03V-B` (LCSC **C157907**) is stocked as a
  hand-made fallback. ⚠ **Corrected 2026-10-07:** it was ordered with no
  contacts — the right pin is `SYM-001T-P0.6` (28–22 AWG), which was never
  checked. Wanted, not yet bought; see `hardware/harness/PARTS.md`. Pinout **1 = GND, 2 = DATA, 3 = 12 V**. Cable-side either
  way, so it never blocked the board order.
- ✅ **"PSU stud size" is moot** — the stock PSU is a brick with one JST YL 2-way
  output and no terminal block or ground stud. The 12V star point is physically
  the DC-DC converter's input screw terminals.
- ✅ **Stock harness fully documented 2026-08-08** — 12 WireViz drawings plus a
  one-page topology map in **`stock-smx/`**, wall socket through to the FSRs,
  with per-run lengths. That tree is kept deliberately separate from our own
  replacement harnesses in `hardware/harness/`.

✅ **Source the 8 board-to-board interface connectors — DONE 2026-08-16.**
Carrier headers **J210–J213** = LCSC **C5383116** (HanElectricity 2541WV-08P,
1×8 male 2.54 mm, **6 mm mating pin / 3 mm solder tail**, gold, 3 A/pin).
Brain sockets **J301–J304** = LCSC **C7509515** (CONNFLY DS1023-1x8SF11, 1×8
female, 8.5 mm body, gold). They are hand-soldered, so they are a cart item, not
a PCBA line.

> ⚠ **QUANTITY CORRECTED 2026-08-18.** This read *"50 of each ordered against a
> need of 36"* — **36 is the ONE-PAD figure** and the cart had been built to the
> 50. The scope is **20 panel assemblies**, so the need is **4 × 20 = 80 of
> each**. Now **100 / 85** in the cart. Same stale per-pad number appeared in
> `hardware/harness/PARTS.md`; both are fixed.

**⚠ Carries one consequence: the M3 spacer must be 12 mm.** These parts measure
2.54 + 8.50 = **11.04 mm** board-to-board, against the 10.75 mm the mechanical
stack assumed — so an 11 mm spacer no longer clears, by 0.04 mm, and would let
the connector plastics take the clamping load. ✅ **12 mm F-F is on hand**
(2026-08-16); the only open question is having **60** of them. See
`docs/DUAL_PANEL.md` → "Mechanical stack".

Original constraint, retained because it is what made these parts the right
ones:

**Type confirmed from `dual-panel.kicad_pcb` 2026-08-16 — they are ordinary
2.54 mm parts, nothing exotic:** `PinHeader_1x08_P2.54mm_Vertical` on the
carrier (B.Cu), `PinSocket_1x08_P2.54mm_Vertical` on the brain. Four of each per
panel, 32 pins per side. Searchable on DigiKey/LCSC as plain 1×8 headers and
sockets; the pitch and pin count are not the hard part.

Constraint most listings don't state: **6.0 mm mating pin with a ≥3.0 mm
solder tail** (the standard 11.6 mm total pin). Separation is set by the two
plastics meeting, not by pins bottoming out, and some "short" headers trim the tail
instead of the mating end — which leaves nothing to solder through the carrier.

✅ **INT cable length — CLOSED 2026-08-16 at 9.3 m/pad**, from the stock record
(`stock-smx/harness/panel-signal-lines.yml`, nine home runs of 60–150 cm).
**Purchased**: RS-485 and INT now share one **50 m** reel of 22 AWG 2-core
shielded RVSP against a 27.0 m two-pad need.

⬜ **INT cable OD check on arrival** — conductor insulation must be **1.30–1.85 mm**:
a floor for the JST XH contact and a ceiling for the Micro-Fit terminal, since
one cable now feeds both. Do this **before crimping 204 contacts**. It is the
only spec that can sink this cable and it is rarely listed by sellers.

---

## 1. Fab package

The panel is a **generated artifact, like gerbers** — gitignored, never
hand-edited. Regenerate both steps; the second overwrites the first's output.

```sh
cd hardware/dual-panel/panel
python3 gen_panel.py     # joins carrier + brain to a rail frame with mouse bites
python3 gen_fab.py       # gerbers zip + JLC-format BOM + CPL into production/
```

✅ **REGENERATED AND VERIFIED 2026-08-18.** The previous package was from
**Jul 30** and predated the Aug 4 board edit (third mounting hole, hole refdes,
via fill/cap) *and* the Aug 17 U303 fix — it would have been fabbed without the
third mounting hole.

```
carrier : 16 tabs   N=3 S=3 E=7 W=3     ← expected shape, matched
brain   :  6 tabs   N=0 S=0 E=3 W=3     ← expected shape, matched
substrates 2 · tab cuts 22 · contiguous: YES — one piece
panel 227.57 × 143.10 mm (326 cm²) · 291 footprints
CPL 115 placements · BOM 35 lines · every line carries an LCSC number
6 non-part footprints dropped (fiducials/tooling)
```

The brain gets no N/S tabs; that is a KiKit partition-line limitation, not a
setting, and it is documented in `hardware/dual-panel/panel/README.md`.

⚠ **KiKit is NOT importable from KiCad's Python directly** — it lives in
`~/.kikit`, so both generators need the path prefix or they fail with
`ModuleNotFoundError`:

```sh
KPY=/Applications/KiCad/KiCad.app/Contents/Frameworks/Python.framework/Versions/Current/bin/python3
cd hardware/dual-panel/panel
PYTHONPATH=~/.kikit "$KPY" gen_panel.py
PYTHONPATH=~/.kikit "$KPY" gen_fab.py
```

🚨 **A FAB BLOCKER WAS CAUGHT HERE 2026-08-17 — the brain had no ground pour.**
The first regenerated package (and the Jul 30 one before it) put the brain on the
panel with **zero GND copper on all four layers**. Root cause: `GND_Brain` was
deleted by `96f43c0` and `GND_Planes` stretched to cover both boards instead. That
fills fine in KiCad, so **every existing check passed** — DRC, ERC, parity, and a
human review. KiKit clips a spanning zone to one board and the other gets nothing.

Fixed by recreating `GND_Brain`, and `gen_panel.py` now **fails the build** if any
board lacks a GND pour on any copper layer. Expected passing output:

```
  ground pour per board (mm2):
    carrier  F.Cu=13421  In1.Cu=15656  In2.Cu=15656  B.Cu=15093
    brain    F.Cu=2412   In1.Cu=3418   In2.Cu=3418   B.Cu=3249
```

⚠ **If either row shows zeros, do not order** — the boards will arrive with no
ground plane. See `docs/DUAL_PANEL.md` → "Layout and routing".

✅ **Package contents spot-checked**: D301/D302 (DNP) absent from both BOM and
CPL while D303 is present; the 30 test points filtered; 16 gerber files (4 copper
+ paste/silk/mask pairs + Edge.Cuts + separate PTH/NPTH Excellon + 2 drill maps +
gbrjob). `In1_Cu` and `In2_Cu` come out byte-identical in size, corroborating
that **both inner layers are solid GND** and no 12V plane exists.

✅ **Master package: NO regeneration needed, verified rather than assumed.**
Regenerated to a scratch dir and compared layer-by-layer against
`hardware/master-pcb/production/`: **all 11 files are content-identical.**

⚠ **When diffing gerbers, strip `%TF.CreationDate` as well as `G04` comments.**
It is an X2 *attribute*, not a comment, so a comment-only filter leaves a
timestamp in and every layer falsely reads as changed — that produced a wrong
"master package is stale" verdict on 2026-08-18 before it was caught. The drill
files being identical while all nine gerbers "differed" was the tell.

⬜ **Upload as a customer panel** ("panel by customer"), **not** as a single board
— JLC's own panelization only arrays one design, and two different boards must be
supplied this way. Doing that is what makes it *one* order: one engineering fee,
one PCBA setup, one stencil, one shipment.

⬜ **Assembly scope is SMD only.** Through-hole — every connector, both switches,
and the eight interface headers/sockets — is hand-soldered. `gen_fab.py` filters
THT, the 30 test points (bare plated holes whose "value" is a net name, so they'd
become 30 unmatched BOM lines), and KiKit's mouse bites / tooling holes / fiducials.

⬜ **Master board**: bare fab only, no PCBA — hand-assembled from LCSC parts. Its
shopping BOM regenerates with `python3 tools/gen_bom.py --board
hardware/master-pcb/master-pcb.kicad_pcb`.

⬜ Working tree committed and pushed.

---

## 2. Design-file state

✅ **RE-VERIFIED 2026-08-18** from clean project copies, after the U303 pad edit.
Counts are **identical to the 2026-08-04 baseline** — the edit introduced nothing.

| board | DRC | unconnected | parity | ERC | exclusions |
|---|---|---|---|---|---|
| master-pcb | 1 ✱ | 0 | 0 | 0 | 0 DRC / 0 ERC |
| dual-panel | 0 | 19 ✱✱ | 90 ✱✱✱ | 0 | 0 DRC / 0 ERC |

✅ **U303's SOT-223 tab is FIXED and the fix is in the copper.** The tab pad now
carries `zone_connect 2` (solid) into the `+5VDC_AMS` pour, replacing the 4×0.5mm
thermal spokes that were throttling the AMS1117's stated heatsink path.

⚠ **A `zone_connect` change only reaches the gerbers if the zone was refilled
afterwards** — the fill polygons are stored in the `.kicad_pcb`, so an unrefilled
board keeps the old spokes in the artwork while the *rule* reads solid. Verified
by refilling all 6 zones headlessly and comparing areas: **zero change**, so the
saved copper already matches the solid-connection rule. Worth repeating after any
future pad/zone/rule edit:

```python
# kicad python; threshold in nm^2
before = {…z.GetFilledPolysList(layer).Area()…}
pcbnew.ZONE_FILLER(b).Fill(b.Zones())
# any area delta ⇒ the saved fill was stale
```

Both `drc_exclusions` and `erc_exclusions` are genuinely **empty** — nothing is
suppressed by exclusion. Two rule severities are set to `ignore` on both boards,
and both are cosmetic library-naming checks: `footprint_filters_mismatch` and
`footprint_type_mismatch`.

✱ One `courtyards_overlap`, R4 against U2 — R4 sits deliberately under the socketed
Teensy. Accepted, not a defect.

✱✱ The permanent board-to-board mating-gap floor. KiCad cannot model "these mate
mechanically"; each was confirmed to be a genuine crossing net.

✱✱✱ **A `kicad-cli`-only artifact — the GUI reports none.** Net *naming*, not
topology; the exported netlist agrees with the PCB pad-for-pad across all 577 pads
and gerbers carry no net names.

⬜ **Re-run all three checks after any edit.** Geometric DRC, `--schematic-parity`,
and ERC are three separate checks and parity is the easy one to forget.

⚠ **`kicad-cli` mutates `.kicad_pro` / `.kicad_sym` as a side effect.** Run checks
on a scratch copy — and copy the **whole project set** (`.kicad_pro`, `.kicad_dru`,
`.kicad_prl`, `fp-lib-table`, `.pretty`), or `${KIPRJMOD}` won't resolve and the
counts differ.

### JLC DFM run — 2026-08-17, findings and what was done

Ran JLC's own DFM checker on `panel-gerbers.zip`. Reports are in `tmp/`.

✅ **Annular ring (100 Danger) — FIXED.** Vias were **0.3 mm drill / 0.45 mm pad
= 0.075 mm annular**, JLC's *absolute* minimum for the class. JLC recommends
**≥0.15 mm** against drill-registration breakout, so their tool flagged all of
them. Vias are now **0.60 mm pad = 0.150 mm annular**, meeting the recommendation.

- **Drills are unchanged** (1063 @ 0.3 mm, 44 @ 0.6 mm), so current capacity and
  the POFV story are untouched. ⚠ Do not confuse the two: the **0.5 mm POFV
  limit is a DRILL limit**, not a pad diameter.
- Copper pour lost **55 mm² of 72,756 — 0.076%**. Nothing else moved.
- **Three vias stay at 0.45 mm** because growing them violates clearance:
  `VBUS` @ (216.23, 85.24) against U305 pad 2, and GND vias @ (176.69, 27.18)
  and (176.67, 151.95) against the board edge. Shrinking those three instead of
  nudging them gives **0 DRC violations and no re-routing**. The netclass is
  0.6 mm so new vias inherit the good size; the DRU `via_diameter` minimum stays
  at 0.45 mm only so these three pass.

⬜ **Trace spacing (5 Danger at 0.09 mm) — DELIBERATELY NOT FIXED.** 500 of the
508 sub-0.15 mm gaps are **copper-pour-to-track**, not track-to-track: the DRU's
blanket `(constraint clearance (min 0.09mm))` **replaces** the Default netclass's
0.2 mm, so pours back off only 0.09 mm. Raising it looked like a free win — but
**every value tested above 0.09 mm (0.10, 0.11, 0.12, 0.125) orphans a copper
island and produces a `starved_thermal` on J211 pad 5.** 0.09 mm is JLC's stated
minimum, so this is *at* spec rather than under it, and the real routing is
comfortably clear (tightest track-track 0.1266 mm, track-pad 0.1328 mm). Left
alone as the lesser risk.

🟢 **Ignore:** silkscreen-over-pad/hole (96) is cosmetic — JLC clips it.
Negative soldermask expansion (62) is normal. Fiducials reported "null" but **6
exist** (`KiKit_FID_T/B_1-3`); JLC's detector just missed KiKit's. Slot width
0.5 mm (6) sits at JLC's minimum, same "at limit, not under" as the vias.

### SMT DFM — run WITH BOM + CPL, all findings triaged 2026-08-17

| finding | Danger | verdict |
|---|---|---|
| Lead to hole distance | 72 | ✅ **deliberate via-in-pad** — makes POFV mandatory, see below |
| Pin left / right / outer edge | 28 / 28 | ✅ **fixed 2026-08-18** — pads widened to 0.23 mm = datasheet b max; confirmed cleared on the DFM re-run |
| Pin **inner** edge | 42 | ⚠ **ACCEPTED, do not fix** — pad inner edge 3.000 mm = pin inner edge at datasheet **L max 0.500**. Zero heel at worst case only; 0.100 mm at nominal. Adding heel measured to cause solder-mask bridging. Full argument + JLC reply in `docs/ORDER_NOTES.md` §8 |
| Lead area overlapping pad | 1 | RP2040 exposed pad; conservative, see below |
| component→board edge, through-hole ×4, pad spacing, clipped by outline, pin without pad, pin outer edge, missing hole | **0** | clean |

🚨 **POFV IS NOW MANDATORY, NOT A COST DECISION.** "Lead to hole distance" is the
**83 via-in-pad instances** from `9bf960f` ("via-in-pad pass on the brain").
Measured: **all 0.3 mm drill, all on the brain, none over the 0.5 mm fill limit**,
17 of them under U306. Without filling, solder wicks down those vias during
reflow and starves 83 joints including the RP2040's. This also sharpens the
question for JLC — ask them to **fill the 0.3 mm vias; the 44 at 0.6 mm drill do
not need filling and none of them sit in a pad.**

✅ **The RP2040 exposed pad is CORRECT at 3.2 × 3.2 mm.** Verified against
Raspberry Pi's own reference board (`Minimal-KiCAD.zip` →
`RPI-RP2040-MINIMAL_R3-S1.kicad_pcb`), which uses the same 3.2 mm EP. ⚠ A web
search claiming RP2040 needs a 5.6 × 5.6 mm EP is **wrong** — KiCad ships that
variant for other parts in the same body. Do not "fix" this.

✅ **The pin-edge findings were a pad-width difference on U306 — FIXED 2026-08-18,
pads widened to Raspberry Pi's 0.23 mm.** We were on KiCad's generic
`QFN-56-1EP_7x7mm_P0.4mm_EP3.2x3.2mm` with **0.875 × 0.20 mm** signal pads against
Raspberry Pi's official **0.80 × 0.23 mm**; 28 + 28 = **56 = exactly the pin
count**, which identified the width as the cause. Resolved by the user's pre-order
call rather than deferring to rev-B.

**What was changed, and what deliberately was not.** A local footprint
`dual-panel:QFN-56-1EP_7x7mm_P0.4mm_EP3.2x3.2mm_RPiPad` widens **only** the signal
pad width, 0.20 → **0.23 mm**. Pad **length stays 0.875 mm** (not RPi's 0.80) —
the extra toe overhang aids solderability and inspection, and shortening it would
have moved geometry the DFM never complained about. Pitch, pad centres and the
3.2 × 3.2 mm exposed pad are untouched. Pad-to-pad gap goes 0.20 → **0.17 mm**,
still far above JLC's floor.

⚠ **The widening had two knock-on effects; both are handled.**
1. **Zone refill is mandatory** — the wider pads produced three pad-to-`GND_Brain`
   clearance errors that exist only in stale fill polygons. A headless
   `ZONE_FILLER` pass cleared them (`GND_Brain` F.Cu 2423.787 → 2423.741 mm²).
2. **The `QSPI flash pour clearance` rule had to be scoped to zones.** It was
   written with no B-side condition, so it also policed track-to-pad, and the
   wider pad 51 left one +1.1VDC track at 0.1253 mm against the 0.13 mm rule.
   That is a routing gap, not a pour gap — and 0.1253 mm is still well clear of
   JLC's 0.09 mm floor. The condition now ends `&& B.Type == 'Zone'`, matching the
   rule's own stated purpose. **Verified still live:** raising it to 0.20 mm
   produces 101 QSPI-vs-`GND_Brain` violations, so it is genuinely holding the
   pour back.

⚠ **Edit the schematic INSTANCE, not the `lib_symbols` cache.** Changing the
footprint in both places raises a `lib_symbol_mismatch` ERC warning, because the
cached symbol then disagrees with the on-disk `MCU_RaspberryPi` library. The
instance override alone is what assigns the footprint, and is what the GUI would
have produced. Reverting the cache took ERC back to 0.

✅ **Re-verified after the change: DRC 0 · unconnected 19 · parity 90 · ERC 0** —
identical to the baseline. Gerbers confirmed to carry the new geometry (roundrect
apertures at 0.0575 mm corner radius with ±0.0575/±0.380 mm vertices = 0.23 ×
0.875 mm, present in both pad orientations).

✅ **`tht to smd` (11 Danger) does not apply to this order.** The pairs are
TP303→D303 (1.55), TP306→U308 (2.17), J213→D204 (2.01), J303→U303 (2.16),
TP208→D212 (2.17), TP304→U308 (**1.13**, closest), TP309→C327 (2.23),
TP310→X301 (2.83), TP301→U302 (2.39), and SW202's two ground lugs (1.69 to
R201). **Seven are bare test-point probe holes with nothing soldered into them**,
and the other four are hand-soldered by us. **JLC does SMD only on this order —
every through-hole part is hand-assembled**, so their THT-process clearance check
is inapplicable. Nothing is under 1.1 mm.

### The two DRU subtleties, both still live

⬜ **J305's USB-C holes sit at exactly 0.45 mm edge-to-edge — zero margin against
JLC's published multilayer floor.** Verified 2026-08-04 by raising the rule to
0.5 mm on a copy: **14 violations come straight back**, all on J305. The
`pad to pad clearance (with hole, different nets)` rule is deliberately relaxed to
0.45 mm; the generic `hole to hole clearance (different nets)` rule stays at 0.5 mm
and still guards via↔pad and every other non-pad-pair hole.
- **The two rules are not interchangeable** — both carry a `hole_to_hole`
  constraint, but the pad-to-pad rule is more specific and appears later, so *it*
  governs J305. Don't "simplify" them into one.
- **Keep J305 on the DFM-confirmation list at order time.**

⬜ **`.kicad_dru`'s "Minimum Trace Width and Spacing" rule carries
`(constraint clearance (min 0.09mm))`, and in KiCad a custom rule *replaces* the
netclass value rather than acting as a floor** — so it silently overrides the
Default netclass's 0.2 mm board-wide. Proven by deleting just that constraint: 77
violations appear, actual range 0.0900–0.1993 mm. The routing was separately raised
to a 0.1266 mm minimum, so this is not currently biting, but the rule reads like a
fab-capability template and does not say what it appears to say. If 0.2 mm should
ever be enforced, drop the `clearance` constraint (keep `track_width`) and let the
netclass govern.

---
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

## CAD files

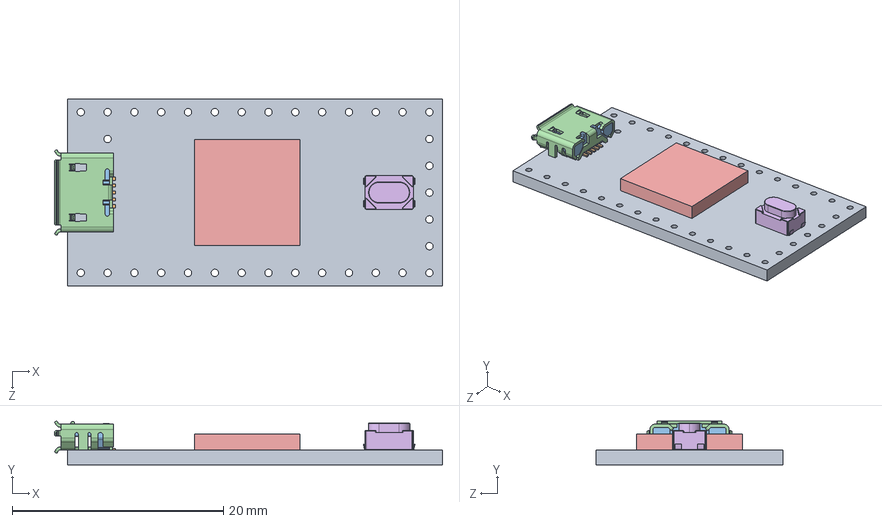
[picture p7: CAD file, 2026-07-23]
hardware/master-pcb/3dmodels/Teensy_4.0_Assembly.STEP
36.8 x 4.12 x 17.7 mm
Teensy_4.0_PCB
Micro USB-B Female 5Pin SMD
NXP iMXRT1062
SKRPACE010 v4

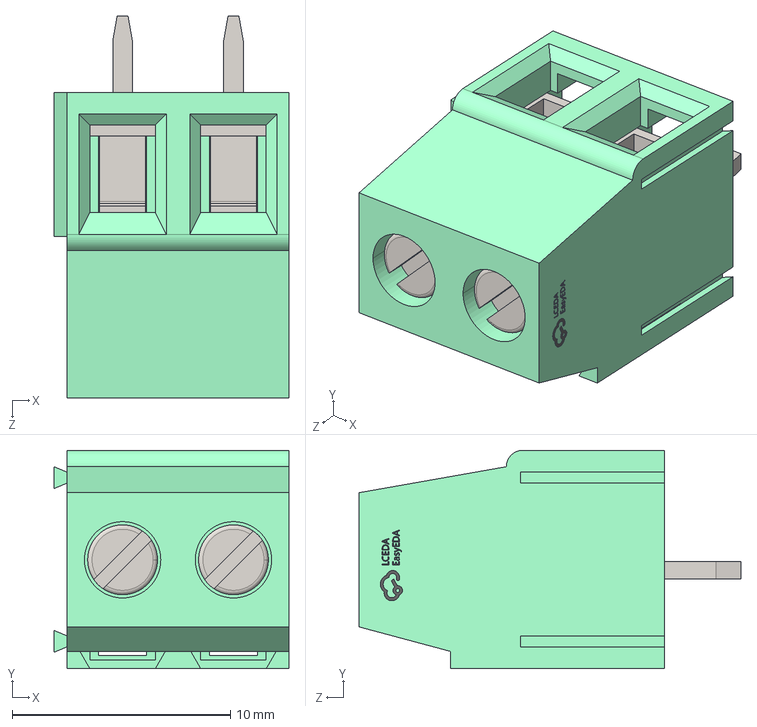
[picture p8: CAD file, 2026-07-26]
hardware/dual-panel/3dmodels/WJ500V-5.08-2P.step
10.8 x 10.0 x 17.5 mm

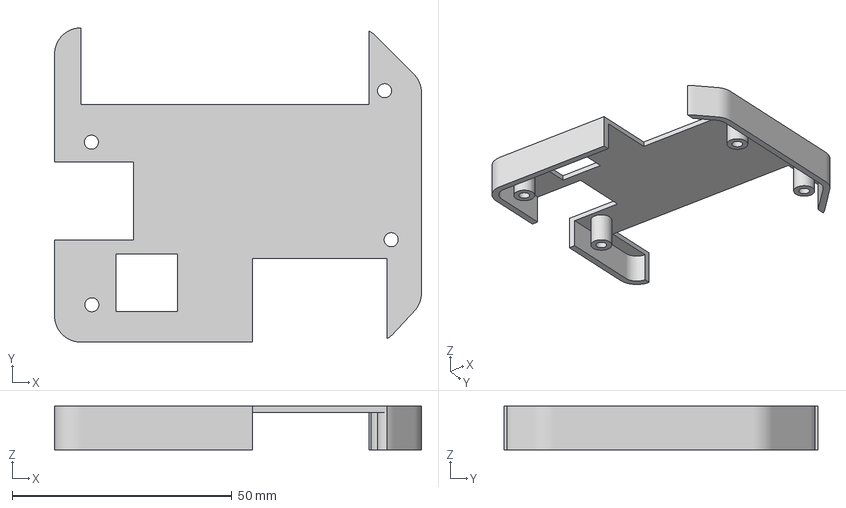
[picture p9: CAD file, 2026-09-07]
hardware/Master-Case/MCU-Top.3mf
83.5 x 71.5 x 10.0 mm

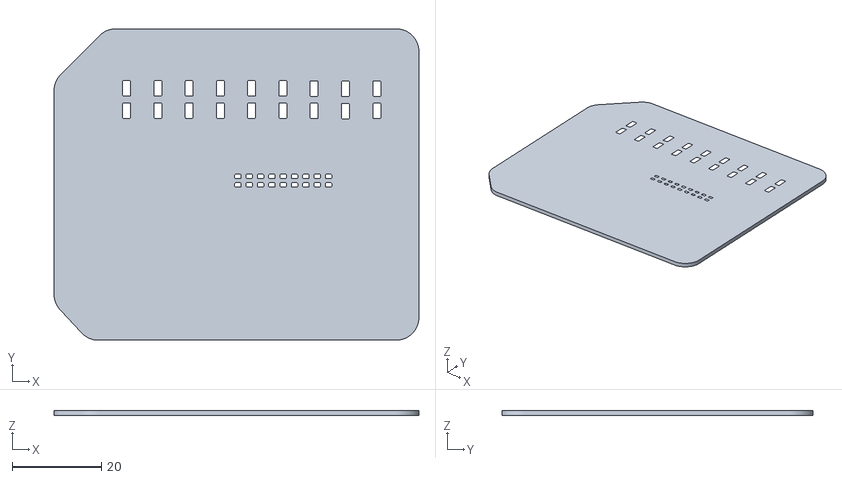
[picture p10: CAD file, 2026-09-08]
hardware/master-pcb/stencil/master-stencil-bottom.stl
81.8 x 69.8 x 1.20

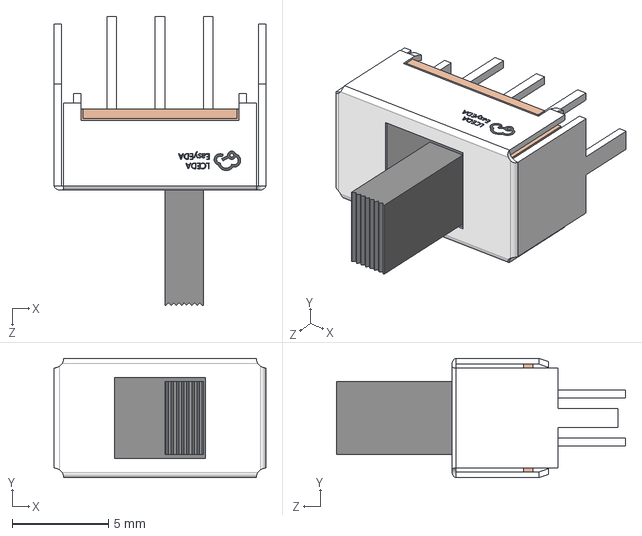
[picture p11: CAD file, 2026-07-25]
hardware/dual-panel/3dmodels/SS22E01L5.step
11.0 x 6.20 x 15.0 mm

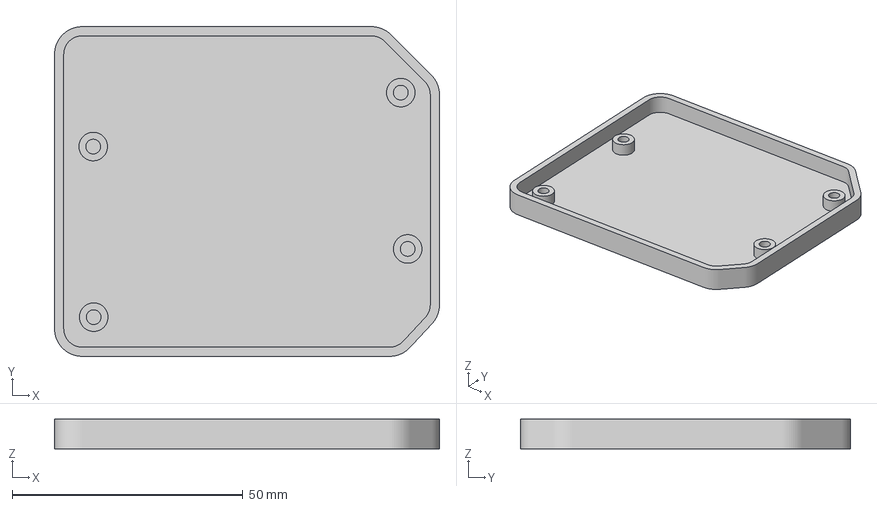
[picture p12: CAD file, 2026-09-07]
hardware/Master-Case/MCU-Bottom.3mf
83.5 x 71.5 x 6.50 mm

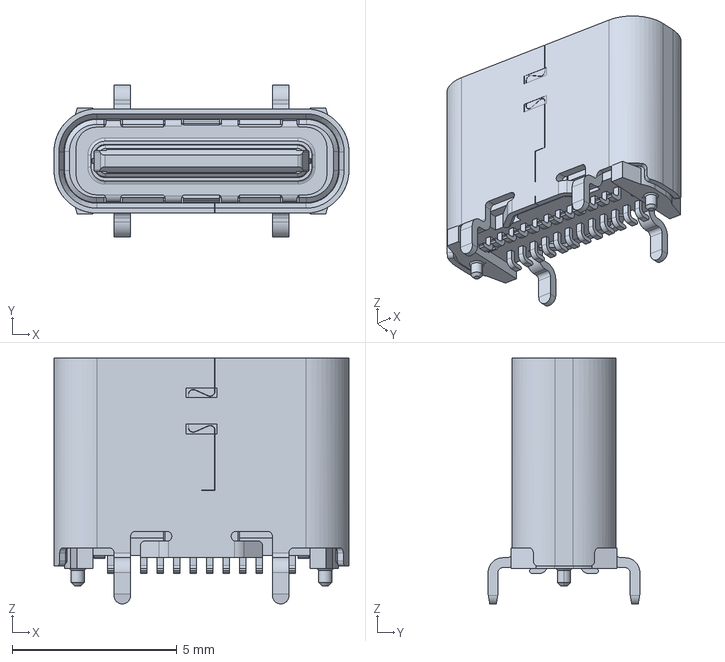
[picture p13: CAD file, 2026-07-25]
hardware/dual-panel/3dmodels/PLACEHOLDER_USB_C_CMUCF661016C.stp
8.94 x 4.60 x 7.45 mm

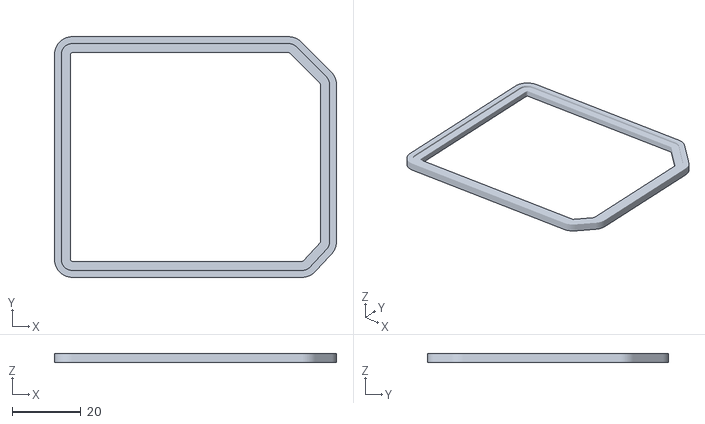
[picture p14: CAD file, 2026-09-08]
hardware/master-pcb/stencil/master-jig-base.stl
81.8 x 69.8 x 2.60

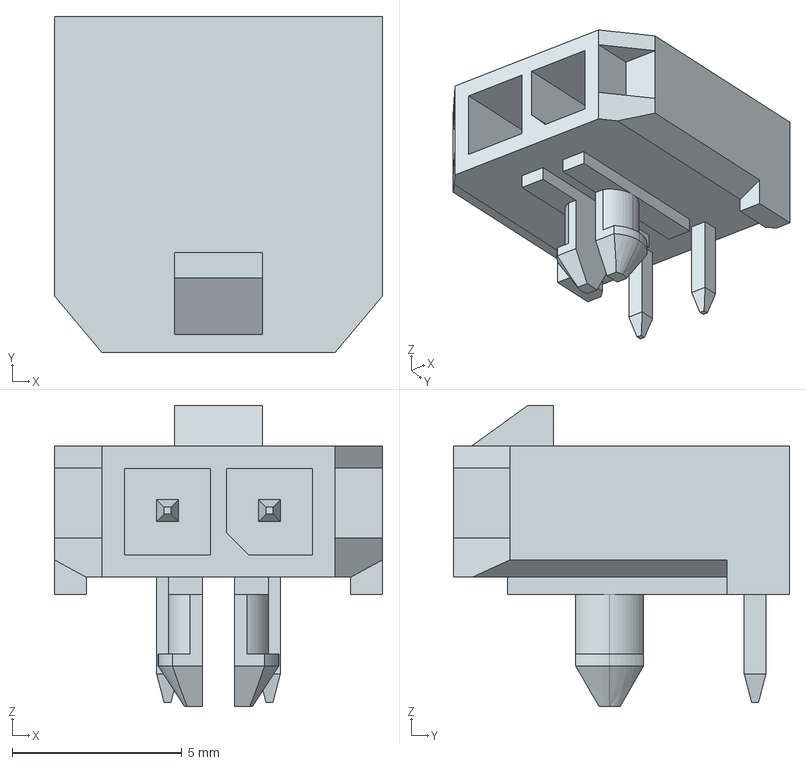
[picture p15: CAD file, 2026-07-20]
hardware/dual-panel/3dmodels/0436500200.stp
9.65 x 9.90 x 8.87 mm

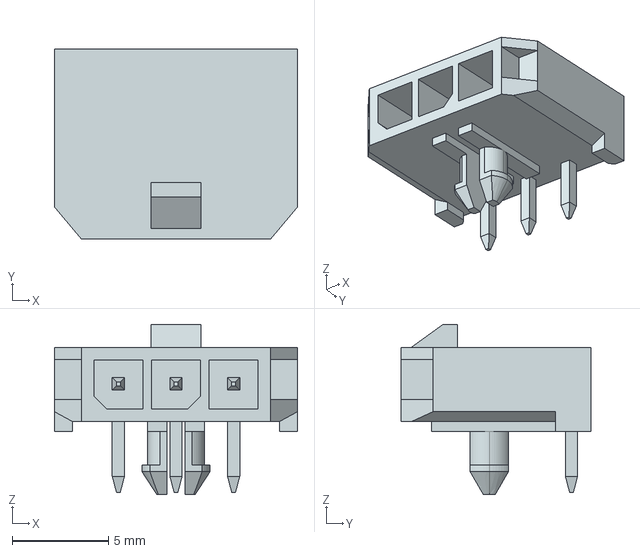
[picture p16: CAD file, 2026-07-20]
hardware/dual-panel/3dmodels/0436500300.stp
12.7 x 9.90 x 8.87 mm

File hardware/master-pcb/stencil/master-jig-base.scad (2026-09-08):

// generated by tools/gen_stencil.py — do not edit by hand
// board: master-pcb.kicad_pcb
$fn = 48;
module board_outline() {
    polygon(points=[[156.9252,-77.4957], [157.2599,-77.5334], [157.5883,-77.6084], [157.9062,-77.7197], [158.2097,-77.8659], [158.4948,-78.0452], [158.7581,-78.2553], [158.8788,-78.3728], [167.6220,-87.1214], [167.7393,-87.2421], [167.9490,-87.5053], [168.1280,-87.7903], [168.2740,-88.0936], [168.3851,-88.4113], [168.4600,-88.7394], [168.4976,-89.0738], [168.5000,-89.2421], [168.5000,-134.8219], [168.4971,-135.0091], [168.4506,-135.3805], [168.3581,-135.7432], [168.2213,-136.0916], [168.0422,-136.4203], [167.8236,-136.7242], [167.6984,-136.8633], [162.8902,-142.0414], [162.7684,-142.1688], [162.4998,-142.3973], [162.2063,-142.5927], [161.8920,-142.7523], [161.5611,-142.8740], [161.2182,-142.9561], [160.8681,-142.9975], [160.6918,-143.0000], [94.0000,-143.0000], [93.8317,-142.9976], [93.4971,-142.9599], [93.1688,-142.8850], [92.8510,-142.7738], [92.5477,-142.6277], [92.2626,-142.4486], [91.9994,-142.2387], [91.7613,-142.0006], [91.5514,-141.7374], [91.3723,-141.4523], [91.2262,-141.1490], [91.1150,-140.8312], [91.0401,-140.5029], [91.0024,-140.1683], [91.0000,-140.0000], [91.0000,-80.4934], [91.0023,-80.3251], [91.0400,-79.9905], [91.1149,-79.6623], [91.2261,-79.3445], [91.3722,-79.0411], [91.5513,-78.7560], [91.7612,-78.4928], [91.9993,-78.2547], [92.2626,-78.0448], [92.5477,-77.8656], [92.8510,-77.7196], [93.1688,-77.6084], [93.4971,-77.5335], [93.8317,-77.4958], [94.0000,-77.4934], [156.7568,-77.4934]]);
}
// Support jig for pasting the SECOND side: the board rests on a
// 2.5mm ledge and everything inside is open, so parts already
// placed on side one hang free instead of being crushed.
// The rebate is shallower than the board, leaving 1.0mm of edge
// proud so the stencil's skirt still has something to grip.
difference() {
  linear_extrude(height=2.600) offset(r=2.150) board_outline();
  translate([0,0,2.000]) linear_extrude(height=1.600) offset(r=0.150) board_outline();
  translate([0,0,-1]) linear_extrude(height=4.600) offset(r=-2.500) board_outline();
}

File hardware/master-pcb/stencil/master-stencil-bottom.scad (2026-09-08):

// generated by tools/gen_stencil.py — do not edit by hand
// board: master-pcb.kicad_pcb
$fn = 48;
module board_outline() {
    polygon(points=[[-156.9252,-77.4957], [-157.2599,-77.5334], [-157.5883,-77.6084], [-157.9062,-77.7197], [-158.2097,-77.8659], [-158.4948,-78.0452], [-158.7581,-78.2553], [-158.8788,-78.3728], [-167.6220,-87.1214], [-167.7393,-87.2421], [-167.9490,-87.5053], [-168.1280,-87.7903], [-168.2740,-88.0936], [-168.3851,-88.4113], [-168.4600,-88.7394], [-168.4976,-89.0738], [-168.5000,-89.2421], [-168.5000,-134.8219], [-168.4971,-135.0091], [-168.4506,-135.3805], [-168.3581,-135.7432], [-168.2213,-136.0916], [-168.0422,-136.4203], [-167.8236,-136.7242], [-167.6984,-136.8633], [-162.8902,-142.0414], [-162.7684,-142.1688], [-162.4998,-142.3973], [-162.2063,-142.5927], [-161.8920,-142.7523], [-161.5611,-142.8740], [-161.2182,-142.9561], [-160.8681,-142.9975], [-160.6918,-143.0000], [-94.0000,-143.0000], [-93.8317,-142.9976], [-93.4971,-142.9599], [-93.1688,-142.8850], [-92.8510,-142.7738], [-92.5477,-142.6277], [-92.2626,-142.4486], [-91.9994,-142.2387], [-91.7613,-142.0006], [-91.5514,-141.7374], [-91.3723,-141.4523], [-91.2262,-141.1490], [-91.1150,-140.8312], [-91.0401,-140.5029], [-91.0024,-140.1683], [-91.0000,-140.0000], [-91.0000,-80.4934], [-91.0023,-80.3251], [-91.0400,-79.9905], [-91.1149,-79.6623], [-91.2261,-79.3445], [-91.3722,-79.0411], [-91.5513,-78.7560], [-91.7612,-78.4928], [-91.9993,-78.2547], [-92.2626,-78.0448], [-92.5477,-77.8656], [-92.8510,-77.7196], [-93.1688,-77.6084], [-93.4971,-77.5335], [-93.8317,-77.4958], [-94.0000,-77.4934], [-156.7568,-77.4934]]);
}
// 36 apertures
difference() {
  union() {
    linear_extrude(height=0.200) offset(r=2.150) board_outline();
    translate([0,0,-1.000]) linear_extrude(height=1.000) difference() {
      offset(r=2.150) board_outline();
      offset(r=0.150) board_outline();
    }
  }
  translate([0,0,-0.5]) linear_extrude(height=1.200)
    polygon(points=[[-155.0250,-86.9500], [-155.1207,-86.9690], [-155.2018,-87.0232], [-155.2560,-87.1043], [-155.2750,-87.2000], [-155.2750,-90.2000], [-155.2560,-90.2957], [-155.2018,-90.3768], [-155.1207,-90.4310], [-155.0250,-90.4500], [-153.7250,-90.4500], [-153.6293,-90.4310], [-153.5482,-90.3768], [-153.4940,-90.2957], [-153.4750,-90.2000], [-153.4750,-87.2000], [-153.4940,-87.1043], [-153.5482,-87.0232], [-153.6293,-86.9690], [-153.7250,-86.9500]]);
  translate([0,0,-0.5]) linear_extrude(height=1.200)
    polygon(points=[[-155.0250,-91.9500], [-155.1207,-91.9690], [-155.2018,-92.0232], [-155.2560,-92.1043], [-155.2750,-92.2000], [-155.2750,-95.2000], [-155.2560,-95.2957], [-155.2018,-95.3768], [-155.1207,-95.4310], [-155.0250,-95.4500], [-153.7250,-95.4500], [-153.6293,-95.4310], [-153.5482,-95.3768], [-153.4940,-95.2957], [-153.4750,-95.2000], [-153.4750,-92.2000], [-153.4940,-92.1043], [-153.5482,-92.0232], [-153.6293,-91.9690], [-153.7250,-91.9500]]);
  translate([0,0,-0.5]) linear_extrude(height=1.200)
    polygon(points=[[-129.9050,-107.9300], [-130.0007,-107.9490], [-130.0818,-108.0032], [-130.1360,-108.0843], [-130.1550,-108.1800], [-130.1550,-108.6800], [-130.1360,-108.7757], [-130.0818,-108.8568], [-130.0007,-108.9110], [-129.9050,-108.9300], [-128.9550,-108.9300], [-128.8593,-108.9110], [-128.7782,-108.8568], [-128.7240,-108.7757], [-128.7050,-108.6800], [-128.7050,-108.1800], [-128.7240,-108.0843], [-128.7782,-108.0032], [-128.8593,-107.9490], [-128.9550,-107.9300]]);
  translate([0,0,-0.5]) linear_extrude(height=1.200)
    polygon(points=[[-129.9050,-109.8300], [-130.0007,-109.8490], [-130.0818,-109.9032], [-130.1360,-109.9843], [-130.1550,-110.0800], [-130.1550,-110.5800], [-130.1360,-110.6757], [-130.0818,-110.7568], [-130.0007,-110.8110], [-129.9050,-110.8300], [-128.9550,-110.8300], [-128.8593,-110.8110], [-128.7782,-110.7568], [-128.7240,-110.6757], [-128.7050,-110.5800], [-128.7050,-110.0800], [-128.7240,-109.9843], [-128.7782,-109.9032], [-128.8593,-109.8490], [-128.9550,-109.8300]]);
  translate([0,0,-0.5]) linear_extrude(height=1.200)
    polygon(points=[[-98.9250,-87.0000], [-99.0207,-87.0190], [-99.1018,-87.0732], [-99.1560,-87.1543], [-99.1750,-87.2500], [-99.1750,-90.2500], [-99.1560,-90.3457], [-99.1018,-90.4268], [-99.0207,-90.4810], [-98.9250,-90.5000], [-97.6250,-90.5000], [-97.5293,-90.4810], [-97.4482,-90.4268], [-97.3940,-90.3457], [-97.3750,-90.2500], [-97.3750,-87.2500], [-97.3940,-87.1543], [-97.4482,-87.0732], [-97.5293,-87.0190], [-97.6250,-87.0000]]);
  translate([0,0,-0.5]) linear_extrude(height=1.200)
    polygon(points=[[-98.9250,-92.0000], [-99.0207,-92.0190], [-99.1018,-92.0732], [-99.1560,-92.1543], [-99.1750,-92.2500], [-99.1750,-95.2500], [-99.1560,-95.3457], [-99.1018,-95.4268], [-99.0207,-95.4810], [-98.9250,-95.5000], [-97.6250,-95.5000], [-97.5293,-95.4810], [-97.4482,-95.4268], [-97.3940,-95.3457], [-97.3750,-95.2500], [-97.3750,-92.2500], [-97.3940,-92.1543], [-97.4482,-92.0732], [-97.5293,-92.0190], [-97.6250,-92.0000]]);
  translate([0,0,-0.5]) linear_extrude(height=1.200)
    polygon(points=[[-117.2050,-107.9300], [-117.3007,-107.9490], [-117.3818,-108.0032], [-117.4360,-108.0843], [-117.4550,-108.1800], [-117.4550,-108.6800], [-117.4360,-108.7757], [-117.3818,-108.8568], [-117.3007,-108.9110], [-117.2050,-108.9300], [-116.2550,-108.9300], [-116.1593,-108.9110], [-116.0782,-108.8568], [-116.0240,-108.7757], [-116.0050,-108.6800], [-116.0050,-108.1800], [-116.0240,-108.0843], [-116.0782,-108.0032], [-116.1593,-107.9490], [-116.2550,-107.9300]]);
  translate([0,0,-0.5]) linear_extrude(height=1.200)
    polygon(points=[[-117.2050,-109.8300], [-117.3007,-109.8490], [-117.3818,-109.9032], [-117.4360,-109.9843], [-117.4550,-110.0800], [-117.4550,-110.5800], [-117.4360,-110.6757], [-117.3818,-110.7568], [-117.3007,-110.8110], [-117.2050,-110.8300], [-116.2550,-110.8300], [-116.1593,-110.8110], [-116.0782,-110.7568], [-116.0240,-110.6757], [-116.0050,-110.5800], [-116.0050,-110.0800], [-116.0240,-109.9843], [-116.0782,-109.9032], [-116.1593,-109.8490], [-116.2550,-109.8300]]);
  translate([0,0,-0.5]) linear_extrude(height=1.200)
    polygon(points=[[-119.7450,-107.9300], [-119.8407,-107.9490], [-119.9218,-108.0032], [-119.9760,-108.0843], [-119.9950,-108.1800], [-119.9950,-108.6800], [-119.9760,-108.7757], [-119.9218,-108.8568], [-119.8407,-108.9110], [-119.7450,-108.9300], [-118.7950,-108.9300], [-118.6993,-108.9110], [-118.6182,-108.8568], [-118.5640,-108.7757], [-118.5450,-108.6800], [-118.5450,-108.1800], [-118.5640,-108.0843], [-118.6182,-108.0032], [-118.6993,-107.9490], [-118.7950,-107.9300]]);
  translate([0,0,-0.5]) linear_extrude(height=1.200)
    polygon(points=[[-119.7450,-109.8300], [-119.8407,-109.8490], [-119.9218,-109.9032], [-119.9760,-109.9843], [-119.9950,-110.0800], [-119.9950,-110.5800], [-119.9760,-110.6757], [-119.9218,-110.7568], [-119.8407,-110.8110], [-119.7450,-110.8300], [-118.7950,-110.8300], [-118.6993,-110.8110], [-118.6182,-110.7568], [-118.5640,-110.6757], [-118.5450,-110.5800], [-118.5450,-110.0800], [-118.5640,-109.9843], [-118.6182,-109.9032], [-118.6993,-109.8490], [-118.7950,-109.8300]]);
  translate([0,0,-0.5]) linear_extrude(height=1.200)
    polygon(points=[[-109.5850,-107.9300], [-109.6807,-107.9490], [-109.7618,-108.0032], [-109.8160,-108.0843], [-109.8350,-108.1800], [-109.8350,-108.6800], [-109.8160,-108.7757], [-109.7618,-108.8568], [-109.6807,-108.9110], [-109.5850,-108.9300], [-108.6350,-108.9300], [-108.5393,-108.9110], [-108.4582,-108.8568], [-108.4040,-108.7757], [-108.3850,-108.6800], [-108.3850,-108.1800], [-108.4040,-108.0843], [-108.4582,-108.0032], [-108.5393,-107.9490], [-108.6350,-107.9300]]);
  translate([0,0,-0.5]) linear_extrude(height=1.200)
    polygon(points=[[-109.5850,-109.8300], [-109.6807,-109.8490], [-109.7618,-109.9032], [-109.8160,-109.9843], [-109.8350,-110.0800], [-109.8350,-110.5800], [-109.8160,-110.6757], [-109.7618,-110.7568], [-109.6807,-110.8110], [-109.5850,-110.8300], [-108.6350,-110.8300], [-108.5393,-110.8110], [-108.4582,-110.7568], [-108.4040,-110.6757], [-108.3850,-110.5800], [-108.3850,-110.0800], [-108.4040,-109.9843], [-108.4582,-109.9032], [-108.5393,-109.8490], [-108.6350,-109.8300]]);
  translate([0,0,-0.5]) linear_extrude(height=1.200)
    polygon(points=[[-113.0250,-87.0000], [-113.1207,-87.0190], [-113.2018,-87.0732], [-113.2560,-87.1543], [-113.2750,-87.2500], [-113.2750,-90.2500], [-113.2560,-90.3457], [-113.2018,-90.4268], [-113.1207,-90.4810], [-113.0250,-90.5000], [-111.7250,-90.5000], [-111.6293,-90.4810], [-111.5482,-90.4268], [-111.4940,-90.3457], [-111.4750,-90.2500], [-111.4750,-87.2500], [-111.4940,-87.1543], [-111.5482,-87.0732], [-111.6293,-87.0190], [-111.7250,-87.0000]]);
  translate([0,0,-0.5]) linear_extrude(height=1.200)
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

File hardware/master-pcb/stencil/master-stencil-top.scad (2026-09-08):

// generated by tools/gen_stencil.py — do not edit by hand
// board: master-pcb.kicad_pcb
$fn = 48;
module board_outline() {
    polygon(points=[[156.9252,-77.4957], [157.2599,-77.5334], [157.5883,-77.6084], [157.9062,-77.7197], [158.2097,-77.8659], [158.4948,-78.0452], [158.7581,-78.2553], [158.8788,-78.3728], [167.6220,-87.1214], [167.7393,-87.2421], [167.9490,-87.5053], [168.1280,-87.7903], [168.2740,-88.0936], [168.3851,-88.4113], [168.4600,-88.7394], [168.4976,-89.0738], [168.5000,-89.2421], [168.5000,-134.8219], [168.4971,-135.0091], [168.4506,-135.3805], [168.3581,-135.7432], [168.2213,-136.0916], [168.0422,-136.4203], [167.8236,-136.7242], [167.6984,-136.8633], [162.8902,-142.0414], [162.7684,-142.1688], [162.4998,-142.3973], [162.2063,-142.5927], [161.8920,-142.7523], [161.5611,-142.8740], [161.2182,-142.9561], [160.8681,-142.9975], [160.6918,-143.0000], [94.0000,-143.0000], [93.8317,-142.9976], [93.4971,-142.9599], [93.1688,-142.8850], [92.8510,-142.7738], [92.5477,-142.6277], [92.2626,-142.4486], [91.9994,-142.2387], [91.7613,-142.0006], [91.5514,-141.7374], [91.3723,-141.4523], [91.2262,-141.1490], [91.1150,-140.8312], [91.0401,-140.5029], [91.0024,-140.1683], [91.0000,-140.0000], [91.0000,-80.4934], [91.0023,-80.3251], [91.0400,-79.9905], [91.1149,-79.6623], [91.2261,-79.3445], [91.3722,-79.0411], [91.5513,-78.7560], [91.7612,-78.4928], [91.9993,-78.2547], [92.2626,-78.0448], [92.5477,-77.8656], [92.8510,-77.7196], [93.1688,-77.6084], [93.4971,-77.5335], [93.8317,-77.4958], [94.0000,-77.4934], [156.7568,-77.4934]]);
}
// 41 apertures
// DNP, no aperture cut: R1, R2
difference() {
  union() {
    linear_extrude(height=0.200) offset(r=2.150) board_outline();
    translate([0,0,-1.000]) linear_extrude(height=1.000) difference() {
      offset(r=2.150) board_outline();
      offset(r=0.150) board_outline();
    }
  }
  translate([0,0,-0.5]) linear_extrude(height=1.200)
    polygon(points=[[105.8000,-89.0750], [105.8957,-89.0940], [105.9768,-89.1482], [106.0310,-89.2293], [106.0500,-89.3250], [106.0500,-89.8500], [106.0310,-89.9457], [105.9768,-90.0268], [105.8957,-90.0810], [105.8000,-90.1000], [104.9000,-90.1000], [104.8043,-90.0810], [104.7232,-90.0268], [104.6690,-89.9457], [104.6500,-89.8500], [104.6500,-89.3250], [104.6690,-89.2293], [104.7232,-89.1482], [104.8043,-89.0940], [104.9000,-89.0750]]);
  translate([0,0,-0.5]) linear_extrude(height=1.200)
    polygon(points=[[105.8000,-90.9000], [105.8957,-90.9190], [105.9768,-90.9732], [106.0310,-91.0543], [106.0500,-91.1500], [106.0500,-91.6750], [106.0310,-91.7707], [105.9768,-91.8518], [105.8957,-91.9060], [105.8000,-91.9250], [104.9000,-91.9250], [104.8043,-91.9060], [104.7232,-91.8518], [104.6690,-91.7707], [104.6500,-91.6750], [104.6500,-91.1500], [104.6690,-91.0543], [104.7232,-90.9732], [104.8043,-90.9190], [104.9000,-90.9000]]);
  translate([0,0,-0.5]) linear_extrude(height=1.200)
    polygon(points=[[132.4500,-119.2375], [132.4310,-119.3332], [132.3768,-119.4143], [132.2957,-119.4685], [132.2000,-119.4875], [131.6750,-119.4875], [131.5793,-119.4685], [131.4982,-119.4143], [131.4440,-119.3332], [131.4250,-119.2375], [131.4250,-118.3375], [131.4440,-118.2418], [131.4982,-118.1607], [131.5793,-118.1065], [131.6750,-118.0875], [132.2000,-118.0875], [132.2957,-118.1065], [132.3768,-118.1607], [132.4310,-118.2418], [132.4500,-118.3375]]);
  translate([0,0,-0.5]) linear_extrude(height=1.200)
    polygon(points=[[130.6250,-119.2375], [130.6060,-119.3332], [130.5518,-119.4143], [130.4707,-119.4685], [130.3750,-119.4875], [129.8500,-119.4875], [129.7543,-119.4685], [129.6732,-119.4143], [129.6190,-119.3332], [129.6000,-119.2375], [129.6000,-118.3375], [129.6190,-118.2418], [129.6732,-118.1607], [129.7543,-118.1065], [129.8500,-118.0875], [130.3750,-118.0875], [130.4707,-118.1065], [130.5518,-118.1607], [130.6060,-118.2418], [130.6250,-118.3375]]);
  translate([0,0,-0.5]) linear_extrude(height=1.200)
    polygon(points=[[112.8250,-89.0750], [112.9207,-89.0940], [113.0018,-89.1482], [113.0560,-89.2293], [113.0750,-89.3250], [113.0750,-89.8500], [113.0560,-89.9457], [113.0018,-90.0268], [112.9207,-90.0810], [112.8250,-90.1000], [111.9250,-90.1000], [111.8293,-90.0810], [111.7482,-90.0268], [111.6940,-89.9457], [111.6750,-89.8500], [111.6750,-89.3250], [111.6940,-89.2293], [111.7482,-89.1482], [111.8293,-89.0940], [111.9250,-89.0750]]);
  translate([0,0,-0.5]) linear_extrude(height=1.200)
    polygon(points=[[112.8250,-90.9000], [112.9207,-90.9190], [113.0018,-90.9732], [113.0560,-91.0543], [113.0750,-91.1500], [113.0750,-91.6750], [113.0560,-91.7707], [113.0018,-91.8518], [112.9207,-91.9060], [112.8250,-91.9250], [111.9250,-91.9250], [111.8293,-91.9060], [111.7482,-91.8518], [111.6940,-91.7707], [111.6750,-91.6750], [111.6750,-91.1500], [111.6940,-91.0543], [111.7482,-90.9732], [111.8293,-90.9190], [111.9250,-90.9000]]);
  translate([0,0,-0.5]) linear_extrude(height=1.200)
    polygon(points=[[133.8000,-89.0750], [133.8957,-89.0940], [133.9768,-89.1482], [134.0310,-89.2293], [134.0500,-89.3250], [134.0500,-89.8500], [134.0310,-89.9457], [133.9768,-90.0268], [133.8957,-90.0810], [133.8000,-90.1000], [132.9000,-90.1000], [132.8043,-90.0810], [132.7232,-90.0268], [132.6690,-89.9457], [132.6500,-89.8500], [132.6500,-89.3250], [132.6690,-89.2293], [132.7232,-89.1482], [132.8043,-89.0940], [132.9000,-89.0750]]);
  translate([0,0,-0.5]) linear_extrude(height=1.200)
    polygon(points=[[133.8000,-90.9000], [133.8957,-90.9190], [133.9768,-90.9732], [134.0310,-91.0543], [134.0500,-91.1500], [134.0500,-91.6750], [134.0310,-91.7707], [133.9768,-91.8518], [133.8957,-91.9060], [133.8000,-91.9250], [132.9000,-91.9250], [132.8043,-91.9060], [132.7232,-91.8518], [132.6690,-91.7707], [132.6500,-91.6750], [132.6500,-91.1500], [132.6690,-91.0543], [132.7232,-90.9732], [132.8043,-90.9190], [132.9000,-90.9000]]);
  translate([0,0,-0.5]) linear_extrude(height=1.200)
    polygon(points=[[153.1500,-122.5250], [153.1614,-122.4676], [153.1939,-122.4189], [153.2426,-122.3864], [153.3000,-122.3750], [154.3250,-122.3750], [154.3824,-122.3864], [154.4311,-122.4189], [154.4636,-122.4676], [154.4750,-122.5250], [154.4750,-122.8250], [154.4636,-122.8824], [154.4311,-122.9311], [154.3824,-122.9636], [154.3250,-122.9750], [153.3000,-122.9750], [153.2426,-122.9636], [153.1939,-122.9311], [153.1614,-122.8824], [153.1500,-122.8250]]);
  translate([0,0,-0.5]) linear_extrude(height=1.200)
    polygon(points=[[153.1500,-123.4750], [153.1614,-123.4176], [153.1939,-123.3689], [153.2426,-123.3364], [153.3000,-123.3250], [154.3250,-123.3250], [154.3824,-123.3364], [154.4311,-123.3689], [154.4636,-123.4176], [154.4750,-123.4750], [154.4750,-123.7750], [154.4636,-123.8324], [154.4311,-123.8811], [154.3824,-123.9136], [154.3250,-123.9250], [153.3000,-123.9250], [153.2426,-123.9136], [153.1939,-123.8811], [153.1614,-123.8324], [153.1500,-123.7750]]);
  translate([0,0,-0.5]) linear_extrude(height=1.200)
    polygon(points=[[153.1500,-124.4250], [153.1614,-124.3676], [153.1939,-124.3189], [153.2426,-124.2864], [153.3000,-124.2750], [154.3250,-124.2750], [154.3824,-124.2864], [154.4311,-124.3189], [154.4636,-124.3676], [154.4750,-124.4250], [154.4750,-124.7250], [154.4636,-124.7824], [154.4311,-124.8311], [154.3824,-124.8636], [154.3250,-124.8750], [153.3000,-124.8750], [153.2426,-124.8636], [153.1939,-124.8311], [153.1614,-124.7824], [153.1500,-124.7250]]);
  translate([0,0,-0.5]) linear_extrude(height=1.200)
    polygon(points=[[155.4250,-124.4250], [155.4364,-124.3676], [155.4689,-124.3189], [155.5176,-124.2864], [155.5750,-124.2750], [156.6000,-124.2750], [156.6574,-124.2864], [156.7061,-124.3189], [156.7386,-124.3676], [156.7500,-124.4250], [156.7500,-124.7250], [156.7386,-124.7824], [156.7061,-124.8311], [156.6574,-124.8636], [156.6000,-124.8750], [155.5750,-124.8750], [155.5176,-124.8636], [155.4689,-124.8311], [155.4364,-124.7824], [155.4250,-124.7250]]);
  translate([0,0,-0.5]) linear_extrude(height=1.200)
    polygon(points=[[155.4250,-122.5250], [155.4364,-122.4676], [155.4689,-122.4189], [155.5176,-122.3864], [155.5750,-122.3750], [156.6000,-122.3750], [156.6574,-122.3864], [156.7061,-122.4189], [156.7386,-122.4676], [156.7500,-122.5250], [156.7500,-122.8250], [156.7386,-122.8824], [156.7061,-122.9311], [156.6574,-122.9636], [156.6000,-122.9750], [155.5750,-122.9750], [155.5176,-122.9636], [155.4689,-122.9311], [155.4364,-122.8824], [155.4250,-122.8250]]);
  translate([0,0,-0.5]) linear_extrude(height=1.200)
    polygon(points=[[126.8000,-89.0750], [126.8957,-89.0940], [126.9768,-89.1482], [127.0310,-89.2293], [127.0500,-89.3250], [127.0500,-89.8500], [127.0310,-89.9457], [126.9768,-90.0268], [126.8957,-90.0810], [126.8000,-90.1000], [125.9000,-90.1000], [125.8043,-90.0810], [125.7232,-90.0268], [125.6690,-89.9457], [125.6500,-89.8500], [125.6500,-89.3250], [125.6690,-89.2293], [125.7232,-89.1482], [125.8043,-89.0940], [125.9000,-89.0750]]);
  translate([0,0,-0.5]) linear_extrude(height=1.200)
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

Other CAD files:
hardware/master-pcb/stencil/master-stencil-top.stl

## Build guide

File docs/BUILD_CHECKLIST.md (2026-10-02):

# Repeat-build checklist

`PANEL_BRINGUP.md` and `MASTER_BRINGUP.md` are written to **prove a design** —
the right shape for board 1, the wrong shape for boards 3 through 20. This is the
condensed version: what to do per board, and what not to do again.

**Remaining as of 2026-10-02:** 2 panels built of **20** (2 pads × 9 + 2 spares),
so **18 to go**. Both masters built.

---

## Solder, flux and cleaning — every board

**Materials on hand (2026-10-01).** All are no-clean or rosin; none is water-soluble.

| | part | notes |
|---|---|---|
| Flux | MG Chemicals **8341** No Clean Flux Paste | used up |
| Flux | Chip Quik **SMD291NL** No Clean Tacky Flux | current — a gel, hard to shift with IPA |
| Paste | MG Chemicals **Sn42Bi57Ag1** low-temp, T3, no-clean | current |
| Paste | Chip Quik **Sn63/Pb37** thermally stable, T4, no-clean | in use since master #2 (2026-10-01): worked well through the printed stencil, needed more heat than SnBi, and needed no added flux |
| Wire | MG Chemicals **4884-227G** Sn63/Pb37, RA (rosin activated) core, 2.2% flux, 0.025" (0.64 mm, 23 AWG) | current — **not no-clean; its residue must be cleaned off** (below) |

- ⛔ **Never mix the bismuth paste and leaded solder on one joint.** Sn–Pb–Bi
  forms a ~96 °C eutectic, and the joint ends up brittle. Keep each board on one
  alloy family. To rework a SnBi joint, add SnBi or wick it clean first; never
  touch it up with the leaded wire. Switch pastes between boards, never partway
  through one. This matters most on the master, which is reflowed with paste
  *and* has its through-hole hand-soldered.
- **The wire's flux is the one residue that must come off.** MG classes the
  4880–4888 core as **J-STD-004B ROM1**: rosin, *moderate* activity, **0.5–2.0 %
  halides**, and silver-chromate result "Detection" (halides present). MG's own
  no-clean Sn63/Pb37 wire (4860–4865) is REL0 with <0.05 %. The datasheet still
  calls the residue "non-corrosive and non-conductive" (corrosion test pass, SIR
  >1×10⁹ Ω), but MG's own solder-wire catalogue lists **Cleaning: Required** for
  this series and "No-clean" for the others. So "leave it" in the bullet below
  applies only to no-clean flux. Every joint made with this wire gets cleaned.
  MG doesn't name a solvent for it in either document. IPA dissolves rosin.
  Sources, read 2026-10-01: `mgchemicals.com/downloads/tds/tds-4880-4888.pdf`
  (Ver. 4.0, 2025-09-30) and `…/category-data-sheets/CDS-Solder Wires.pdf`
  (Ver. 1.1, 2023-02-14).
- **Distilled water does nothing here.** It removes water-soluble (OA) flux only.
  On no-clean residue a partial wetting can leave white residue.
- **Use less flux.** No-clean flux is only benign where heat activated it. Flux
  that spread past the joint and never got hot stays tacky and partly active, and
  that's most of the sticky film.
- **Through-hole: rosin-core wire only, no added flux.** An iron heats the joint
  alone. SMD291NL spread around the pad, wicked down the barrel or tucked under a
  connector body never reaches activation temperature, so it stays raw gel. IPA
  can't reach it there, and it keeps seeping back out however much is used.
  Found on the first panels (2026-10-01): hot-air rework residue came off easily,
  but the through-hole joints stayed sticky. **SMD291NL is for hot air and
  reflow only.**
- **No-clean flux: either clean it completely or leave it.** Fully heated
  no-clean residue is made to stay on the board. (This doesn't apply to the RA
  wire. See above.) A half-dissolved smear is worse than either.
- **Cleaning method:** scrub, then flush with *fresh* solvent while it's still
  wet and wick it off into a lint-free wipe. Repeat 2–3×. Dirty solvent that
  evaporates on the board is what leaves the film. IPA handles the rosin wire;
  SMD291NL needs a real flux remover. Test any remover on a spare board's LED
  first.
- **Clean locally around your own joints only.** JLC already washed the panels.
  Keep liquid away from `SW201`, `SW202`, `SW301` (Omron: "Washing: Not
  possible"), `J305` and the `J301`–`J304` sockets. On the master, the same goes
  for `SW1`.
- **Melamine foam is fine on joints and mask, but never on the WS2815 lenses.**
  It's an abrasive and will scuff the encapsulant. It also crumbles, so finish
  with a flush.

---

## ⛔ First-board-only — do NOT repeat

These were one-time questions about the *design*, and they are closed. Repeating
them costs bench time and risks "re-opening" settled decisions.

- **Stage 0 meter sweep** (`TP306` 35 mV, `TP302`, `TP301`, `RUN`). `TP306` in
  particular answered whether the RP2040's internal pull-down parks the THVD1450
  in receive. It does. Closed, and it dropped a rev-2 candidate.
- **The `p` pull-strength probe.** Answered; the rule stands.
- **`ADC_DUMMY_READ = 0`.** Confirmed on hardware; keeps the full sample rate.
- **Master `r`** (nine INT pins on one GPIO port, register `0x42000008`).
  A property of the chip, not of your soldering.

---

## Per panel (×19)

### 1. Hand-solder — 20 connectors, all through-hole

JLC placed every SMD part including the 25 WS2815s. Nothing here needs hot air.

**Carrier (15):** `J201` `J202` `J203` `J206` JST-PH ×4 · `J204` `J207`
Micro-Fit 3 ×2 · `J205` `J208` Micro-Fit 2 ×2 · `J209` SWD 1×3 · `J210`–`J213`
1×8 pin headers ×4 · `J214` screw terminal · `SW201` ID DIP · `SW202` termination

**Brain (5):** `J301`–`J304` 1×8 sockets ×4 · `J305` USB-C

⚠ The 30 test points are bare probe holes — nothing to fit.
⚠ `J305`'s contact holes sit at 0.45 mm edge-to-edge, zero margin. Don't bridge.

### 2. Flash

```
picotool load -f -x firmware/panel/c/bringup/build/panel_bringup.uf2
```

Blank boards enter BOOTSEL on their own. Already-flashed boards reflash over USB
with `-f`, or `B` from the firmware — **the button is never needed after the
first time.**

⚠ Panel builds need the toolchain override until the Homebrew formula is removed:
`-DPICO_TOOLCHAIN_PATH=/Applications/ArmGNUToolchain/15.2.rel1/arm-none-eabi`

### 3. Bench — brain alone on USB

| | pass condition |
|---|---|
| `v` | banner prints; **record the RP2040 unique ID — this is the board's name** |
| `w` | JEDEC `EF 40 16`, write/verify PASS **and** the 4 MB alias check PASS |
| `s` | sysclk 125 MHz, all five internal pull-ups good, 4 ADC channels uniform |

### 4. Bench — carrier mated, 12 V on, USB kept

⚠ **Connect USB *before* 12 V.** The brain back-drives its own VBUS to 2.78 V, so
a USB-C host refuses to attach to an already-powered panel. Rev 1 needs no rework
— just the ordering.

| | pass condition |
|---|---|
| `s` | 12 V present; `TERM_SENSE` tracks `SW202` |
| `d` | DIP reads the ID you set — **closed = 0, so ID 0 is all four switches ON** |
| `f` | four channels, resting ~94–98, each FSR moves its own edge only |
| `i` | INT pulses (meter the 8 s dwell phase, never the 1 Hz train) |
| `l` | all 25 LEDs light |
| | pull USB: rail holds via `U304` |

⚠ **Run once on 12 V only**, or `U303` ships untested — VBUS at 5.25 V outranks
the AMS1117 so the mux otherwise never selects it.

### 5. Bench — on the bus

`R` to enable the responder, then from the master: heartbeat shows replies, `I`
passes for this panel's ID, `S <id> 500 400` acks. `T` on the panel should read
**0 CRC errors, 0 overruns, 0 uart errors**.

⚠ Give every panel a **unique** ID 0–8. Two on one address collide, and the
master's health check calls it out by name.

### 6. Record

Append to `docs/BRINGUP_LOG.md`, keyed by the RP2040 unique ID: JEDEC, `w`, DIP,
FSR mapping and resting values, LED count, bus counters. One summary row + a
detail section. With 20 boards, "which one had the odd channel" gets asked later.

---

## Per master (×1)

1. **Solder headers onto a fresh Teensy** — the reason board 1 uses the
   ex-prototype module. Two 1×14 rows only.
2. **Paste and reflow both sides.** The board is double-sided: 46 parts on the
   front, and `D1`–`D9` + `C3`–`C11` (the whole INT protection block) on the
   back. Stencils and a support jig: `hardware/master-pcb/stencil/`.
3. **Hand-solder the through-hole**: `J1` Micro-Fit 3, `J2` screw terminal,
   `J3`–`J11` JST XH ×9, two 1×14 Teensy sockets, `RN1`, `SW1`.
4. ⚠ **Leave `R1`/`R2` empty** — DNP, never ordered. The stencil already omits
   their apertures.
5. ⚠ **Do not cut the Teensy's VUSB↔VIN bridge.** The board taps VIN; cutting it
   kills `U3`'s 5 V rail with no other symptom.
6. **Bench:** `N` (all nine external pull-ups — the test `n` cannot do), `n`
   (all HIGH), `D`, `U` (`R4` present; `TP10` follows `TP9` — this is what caught
   bridged pins on `U3`), `u` with a scope.

---

## Per pad — harness

~29 cables: 9 RS-485 (1 × 60 cm + 8 × 45 cm), 9 power, 9 INT home-runs, 1
underglow pigtail, 1 master GND tie.

- ⚠ **Pull-test every crimp.** The RVSP reel is 24 AWG despite its marking and
  sits at the bottom edge of Molex `430300001`'s 20–24 AWG window — it passes,
  but barely. Sourcing genuine 22 AWG before a full harness build is the cheap
  insurance.
- ⚠ **Slide heat-shrink on before crimping.** Labels are the only marking scheme;
  after termination the only retrofit is tape, which is rejected.
- ⚠ **Shield goes to Micro-Fit pin 3 on RS-485 only** — braid gathered to a
  pigtail, a 22 AWG lead soldered on, joint heat-shrunk, *that* lead crimped.
  Never tin the part inside the crimp barrel. INT shields are trimmed and
  heat-shrunk at both ends, never bonded to the INT ground.
- 🛒 **Still to buy: 100 × 0.34 mm² ferrules** (~30 on hand, 36 needed per pad).

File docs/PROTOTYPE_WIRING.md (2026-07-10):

# Breadboard Prototype Wiring Guide

One master MCU (Teensy 4.0) and one panel MCU (Raspberry Pi Pico) connected via RS-485,
with a single interrupt wire, 4 FSRs, and a WS2812B LED strip.

---

## Parts List

### ICs
- Teensy 4.0 — 1×
- Raspberry Pi Pico — 1×
- MAX3485 (SOIC-8) — 2× (one per RS-485 end)
- SOIC-8 to DIP adapter — 2× (for breadboard use)
- SN74AHCT125N (DIP-14) — 1× (3.3V → 5V level shifter for LED data)

### Passives
- 120Ω resistor — 2× (RS-485 termination, one at each end)
- 10kΩ resistor — 5× (4× FSR voltage dividers, 1× INT pull-up)
- 470Ω resistor — 1× (series on LED data line)
- 1000µF electrolytic capacitor — 1× (LED power supply decoupling)
- 100nF ceramic capacitor — 6× (decoupling: 1 per MAX3485, 1 per 74AHCT125, spares)
- 10nF ceramic capacitor — 4× (one per FSR ADC node to GND — kills ADC mux crosstalk, see gotchas)
- TVS diode (e.g. SMBJ3.3A) — 1× (ESD protection on INT line at Teensy)

### Sensors & Actuators
- Interlink Electronics FSR 408 — 4× (long strip FSRs from SMX panel)
- WS2812B LED strip (5V, 60 LED/m) — cut to 25 LEDs or use however many you have

### Power
- USB power adapter, 5V 2A+ — 1× (dedicated to LED strip)
- Micro-USB cables — 2× (Teensy programming/power, Pico programming/power)

### Miscellaneous
- 2× large breadboards
- Jumper wires (various lengths)
- Twisted pair wire, short length (~30cm for RS-485 A/B between boards)
- 0.1" pin headers — 2× strips (Teensy and Pico ship without headers)

---

## Power Distribution

```
USB charger (5V 2A+) ──────────────────── WS2812B VDD
                                       └── 74AHCT125 pin 14 (VCC)
                      (keep this separate from MCU 5V to avoid LED current sag)

Teensy USB ──── Teensy onboard regulator ──── Teensy 3.3V out ──── MAX3485 master VCC

Pico USB ──── Pico onboard regulator ──── Pico 3V3 OUT (pin 36) ──── MAX3485 panel VCC

GND: Teensy GND + Pico GND + LED GND + USB charger GND all joined on breadboard GND rail
     (shared GND is required for RS-485 to work)
```

---

## Teensy 4.0 Connections

| Teensy Pin | Signal | Connects To |
|---|---|---|
| GND | Ground | Common GND rail |
| 3.3V | 3.3V out | MAX3485 master VCC (pin 8), one leg of INT pull-up resistor |
| 0 (RX1) | UART1 RX | MAX3485 master RO (pin 1) |
| 1 (TX1) | UART1 TX | MAX3485 master DI (pin 4) |
| 2 | RS-485 direction | MAX3485 master DE (pin 3) + ~RE (pin 2) tied together |
| 3 | INT input | 10kΩ pull-up → 3.3V; TVS diode → GND; wire → Pico GPIO5 |

---

## MAX3485 — Master Side (on SOIC-8 DIP adapter)

| Pin | Name | Connects To |
|-----|---|---|
| 1 | RO | Teensy pin 0 (RX1) |
| 2 | ~RE | Tied to pin 3, then to Teensy pin 2 |
| 3 | DE | Tied to pin 2, then to Teensy pin 2 |
| 4 | DI | Teensy pin 1 (TX1) |
| 5 | GND | Common GND rail |
| 6 | A | RS-485 A wire (twisted pair) → MAX3485 panel pin 6 |
| 7 | B | RS-485 B wire (twisted pair) → MAX3485 panel pin 7 |
| 8 | VCC | Teensy 3.3V out |

**Also on this IC:**
- 100nF ceramic cap between pins 8 and 5 (place as close to the chip as possible)
- 120Ω resistor between pins 6 and 7 (master-end RS-485 termination)

---

## Raspberry Pi Pico Connections

| Pico Pin | GPIO | Signal | Connects To |
|---|---|---|---|
| 1 | GPIO0 | UART0 TX | MAX3485 panel DI (pin 4) |
| 2 | GPIO1 | UART0 RX | MAX3485 panel RO (pin 1) |
| 3 | GND | Ground | Common GND rail |
| 4 | GPIO2 | RS-485 direction | MAX3485 panel DE (pin 3) + ~RE (pin 2) tied together |
| 5 | GPIO3 | Debug press LED | Push-pull output, HIGH on press — debug visualization only |
| 6 | GPIO4 | LED data | 74AHCT125 pin 2 (1A input) |
| 7 | GPIO5 | INT output | Wire → Teensy pin 3 (open-drain: output LOW to signal press, input/high-Z otherwise) |
| 31 | GPIO26 / ADC0 | FSR 1 | FSR voltage divider midpoint (see FSR section) |
| 32 | GPIO27 / ADC1 | FSR 2 | FSR voltage divider midpoint |
| 34 | GPIO28 / ADC2 | FSR 3 | FSR voltage divider midpoint |
| 35 | GPIO29 / ADC3 | FSR 4 | FSR voltage divider midpoint (see GPIO29 warning below) |
| 36 | 3V3 OUT | 3.3V | MAX3485 panel VCC (pin 8) |

---

## MAX3485 — Panel Side (on SOIC-8 DIP adapter)

| Pin | Name | Connects To |
|-----|---|---|
| 1 | RO | Pico GPIO1 (UART0 RX) |
| 2 | ~RE | Tied to pin 3, then to Pico GPIO2 |
| 3 | DE | Tied to pin 2, then to Pico GPIO2 |
| 4 | DI | Pico GPIO0 (UART0 TX) |
| 5 | GND | Common GND rail |
| 6 | A | RS-485 A wire → MAX3485 master pin 6 |
| 7 | B | RS-485 B wire → MAX3485 master pin 7 |
| 8 | VCC | Pico 3V3 OUT (pin 36) |

**Also on this IC:**
- 100nF ceramic cap between pins 8 and 5 (place as close to chip as possible)
- 120Ω resistor between pins 6 and 7 (panel-end RS-485 termination — single panel = last in chain)

---

## SN74AHCT125N Level Shifter (DIP-14)

Only channel 1 is used. Disable all other channels.

| Pin | Name | Connects To |
|-----|---|---|
| 1 | 1~OE | GND (enables channel 1) |
| 2 | 1A | Pico GPIO4 (3.3V LED data) |
| 3 | 1Y | 470Ω resistor → WS2812B DIN |
| 4 | 2~OE | VCC (disables channel 2) |
| 5 | 2A | Leave unconnected |
| 6 | 2Y | Leave unconnected |
| 7 | GND | Common GND rail |
| 8 | 3Y | Leave unconnected |
| 9 | 3A | Leave unconnected |
| 10 | 3~OE | VCC (disables channel 3) |
| 11 | 4Y | Leave unconnected |
| 12 | 4A | Leave unconnected |
| 13 | 4~OE | VCC (disables channel 4) |
| 14 | VCC | 5V rail |

100nF ceramic cap between pins 14 and 7 (place close to chip).

---

## FSR Voltage Dividers (×4, identical)

```
3.3V ──────┬──── FSR 408 lead 1
           │
      FSR 408 body
           │
           ├──── FSR 408 lead 2
           │          │
           │       ADC pin (GPIO26 / 27 / 28 / 29)
           │
         10kΩ
           │
          GND
```

One divider per FSR, four total. The ADC reads the voltage at the midpoint between the FSR
and the 10kΩ pull-down. Higher pressure = lower FSR resistance = higher ADC voltage.

---

## WS2812B LED Strip

| Connection | Connects To |
|---|---|
| DIN (data in) | 74AHCT125 pin 3 (1Y output), via 470Ω series resistor |
| VDD (5V) | Dedicated 5V USB power adapter (not Pico VBUS) |
| GND | Common GND rail |

Place 1000µF electrolytic capacitor across VDD and GND **at the point where power enters
the strip**, not at the breadboard. Observe polarity (+ to VDD, − to GND).

---

## INT Line Detail

The pull-up, TVS diode, Teensy pin 3, and the wire to the Pico all join at **one
single node** (one breadboard row):

```
              Teensy 3.3V
                   │
                  10kΩ            (pull-up: holds the line HIGH when idle)
                   │
    ●──────────────┼──────────────────●──────────────●
    │                                 │              │
 Teensy pin 3                    TVS diode      wire to Pico GPIO5
 (reads the line)             (SMBJ3.3A, cathode
                               to node, anode to GND)
                                      │
                                     GND
```

- **Idle:** Pico GPIO5 is high-Z → 10kΩ pulls the node to 3.3V → pin 3 reads HIGH.
- **Press:** Pico GPIO5 outputs LOW, sinking the node → pin 3 reads LOW → interrupt fires.
- **Wire unplugged:** same as idle (pull-up wins) → reads HIGH, no phantom presses.
- The TVS is not in the signal path — it sits node-to-GND and only conducts on an ESD spike.

Pico firmware: configure GPIO5 as open-drain output. Pull LOW to signal a press, release
(set as input / high-Z) when not pressed. The 10kΩ at the Teensy end pulls it HIGH.
Teensy firmware: configure pin 3 as INPUT with hardware interrupt on CHANGE (both edges).

GPIO3 additionally drives a push-pull debug LED (HIGH on press) for visual confirmation
independent of the INT wire — prototype debugging aid only, not part of the final design.

---

## RS-485 Bus

Use a short length (~30cm) of twisted pair wire between the two MAX3485 chips.
- One wire = A line (pins 6 of both chips)
- Other wire = B line (pins 7 of both chips)

Twisted pair is important even at short distances — parallel wires pick up noise.

**DE/~RE direction control:** Both DE and ~RE on each MAX3485 are tied together and driven
by a single GPIO (Teensy pin 2, Pico GPIO2).
- HIGH = transmit mode (driver enabled, receiver disabled)
- LOW = receive mode (driver disabled, receiver enabled)

**Critical firmware timing:** When transmitting, set DE HIGH before writing to UART TX.
After the last byte, wait for the UART "TX complete" flag (not "TX buffer empty" — these
are different), then set DE LOW. Dropping DE too early clips the last stop bit.

---

## Warnings and Gotchas

### GPIO29 (ADC3) on Pico
On the Raspberry Pi Pico board, GPIO29 is internally connected to a voltage divider for
VSYS monitoring. Connecting an FSR voltage divider to it creates two dividers in parallel
and skews the ADC reading. For a more accurate 4th FSR reading on the Pico prototype,
account for the ~200kΩ internal divider in your calculations, or only use 3 FSRs
(GPIO26–28) and add the 4th on the final custom PCB where GPIO29 is a clean ADC pin.

### Neither Teensy 4.0 nor RP2040 is 5V tolerant
All I/O on both MCUs is 3.3V only. Never connect a 5V signal to any GPIO. The MAX3485
(3.3V version), the Pico INT wire, and the level shifter input are all 3.3V — correct.
The level shifter OUTPUT is 5V — only connect that to the LED strip, not to any MCU pin.

### Shared GND is mandatory
The Teensy and Pico must share a common ground on the breadboard even though they are
powered from separate USB ports. RS-485 requires a common voltage reference between the
two transceivers. Without a shared GND, communication will be unreliable or fail.

### SOIC-8 adapter orientation
The MAX3485 has a dot or notch marking pin 1. Match it to the pin 1 indicator on the DIP
adapter. An upside-down IC here is a frustrating and non-obvious failure mode.

### Decoupling caps must be physically close
Place 100nF ceramic caps as close as possible to the VCC and GND pins of each IC.
Breadboards have high parasitic inductance — a cap placed far away across the board offers
little protection. The 74AHCT125 is especially sensitive when switching at WS2812B speeds.

### FSR 408 flat leads
The FSR leads are flat and flexible and make unreliable contact in standard breadboard
sockets. Bend the last few mm of each lead slightly before inserting, or solder a short
length of solid-core wire to each lead to get a solid breadboard connection.

### LED strip power — keep separate from MCU supply
Connect the LED strip VDD directly to the 5V USB power adapter. Do not run LED power
through the same breadboard rail that powers the level shifter from Pico VBUS. The 1000µF
cap handles transients but high LED current draw on the same rail can cause voltage dips
that glitch the MCU.

### ADC mux crosstalk between FSR channels — solved with 10nF caps
The RP2040's four ADC inputs share one SAR ADC behind a mux, and the sample
capacitor retains charge from the previous conversion. Reading channels
back-to-back lets a high channel (pressed FSR) bleed ~15 counts into the next
channel read. **Fix (bench-verified): 10nF ceramic from each ADC node to GND.**
Measured result: crosstalk dropped to 1–2 counts, and the idle noise floor fell
from ~45 to ~15–20 counts as a bonus — the caps also filter broadband noise on
the high-impedance divider node. Adds only ~30µs of response lag.

These caps are **required on the final panel PCB** (one per FSR channel, close
to the RP2040's ADC pins). A software alternative (discard the first conversion
after each mux switch, `ADC_DUMMY_READ` in main.c) works but halves the sample
rate; it's kept as a compile-time fallback and disabled.

### GPIO23 and GPIO24 on Pico — avoid
GPIO23 controls the onboard SMPS power mode. GPIO24 is VBUS sense. Neither is safe to
use as general-purpose I/O.

### Pico GPIO25 and Teensy pin 13 — onboard LEDs
Both are usable as GPIO but the onboard LED will light up. Useful for firmware heartbeat
debugging.

---

## Quick Reference — What Each GPIO Does

### Teensy 4.0
| Pin | Function |
|-----|---|
| 0 | RS-485 RX (Serial1) |
| 1 | RS-485 TX (Serial1) |
| 2 | RS-485 DE/~RE direction control |
| 3 | INT input from panel (interrupt on CHANGE — falling = press, rising = release) |

### Raspberry Pi Pico
| GPIO | Function |
|---|---|
| 0 | RS-485 TX (UART0) |
| 1 | RS-485 RX (UART0) |
| 2 | RS-485 DE/~RE direction control |
| 3 | Debug press LED (push-pull, HIGH on press) |
| 4 | LED data out → level shifter |
| 5 | INT output to master (open-drain) |
| 26 | ADC0 — FSR 1 |
| 27 | ADC1 — FSR 2 |
| 28 | ADC2 — FSR 3 |
| 29 | ADC3 — FSR 4 (see GPIO29 warning above) |

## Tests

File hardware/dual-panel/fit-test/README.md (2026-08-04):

# Cavity fit test

A 1:1 printable template for checking that the **brain** clears the frame cavity
before committing to an outline or an order.

## Why

Everything in `dual-panel.kicad_pcb` is in **carrier board coordinates**. The frame
cavity is not — its opening measures 88 x 100 mm, but *where* that rectangle sits
relative to the board has to come from something physical.

**Verified 2026-07-30:** the dashed rectangle matched the real frame edge on all four
sides, so the opening is measured, not assumed.

**The opening's position is derived at runtime from the frame-standoff pattern**, not
hard-coded — the standoffs are the physical registration between carrier and frame,
so the opening is fixed relative to them and moving the boards around the KiCad
canvas cannot invalidate it. This matters: the constant used to be
`WINDOW = (41.80, 129.80, 28.90, 128.90)`, correct only while the standoff pattern
sat at `(85.80, 78.90)`. The carrier was later translated `(+28.83, +10.69)` on the
canvas, the constant did not follow, and the stale window produced a phantom "brain
overhangs the cavity by 22 mm east" clash that cost real debugging time. **Do not
re-introduce a hard-coded window in board coordinates.**

The test also caught a real clash — the USB-C body overhung the west edge by 3.20mm,
leaving 2.94mm to the cavity wall where the outline alone showed 6.11mm. USB-C has
since moved to the **brain**'s south edge as **J305** (24.70mm of clearance) and the
generator now draws overhanging bodies (see below).

## Use

```sh
python3 gen_cavity_template.py     # regenerates cavity-fit-template.svg
```

1. Print `cavity-fit-template.svg` at **100% / "Actual size"** — never fit-to-page.
   Confirm the calibration bar measures exactly 100.0 mm before trusting anything.
   Card stock beats paper; paper sags through the opening and fakes a fit.
2. Punch the four ⌀4.50 standoff holes and cut out the brain silhouette.
3. Seat it on the frame standoffs and look down through the cut-out:
   - **only cavity visible** — the brain clears the opening
   - **frame ledge inside the cut** — that side clashes; measure the intrusion
4. Read the gap between the dashed rectangle and the real frame edge on each side.
   That gap *is* the offset, and it is what the design needs.

If a side disagrees, the fix is the `OPENING` **size** constant at the top of the
generator (or the standoff-derived centring, if the pattern itself is wrong) — never
a hard-coded board-coordinate window.

## Overhanging parts

Edge-mount connectors have bodies that stick out past `Edge.Cuts`, so plotting the
outline alone understates how much room the board needs. The generator detects any
footprint whose courtyard crosses the outline and draws it as a dashed blue box,
printing its clearance to the assumed opening. **Cut wide enough to clear those
boxes, not just the outline** — a body that overhangs is what actually hits the frame.

## Limits

- **Plan only.** It does not test depth. The brain sits ~14 mm down; if the frame is
  moulded with draft, the walls close in over that distance. Re-check with a stiff
  copy of the cut-out dropped to the cavity floor.
- **Not a height check.** The measured assembly stack is recorded in
  [`docs/DUAL_PANEL.md`](../../../docs/DUAL_PANEL.md) under *Mechanical stack* —
  15.35 mm used of 20 mm available, with an 11 mm M3 spacer between the boards.
- **Don't read it to tenths.** ⌀4.50 holes on M3 screws let the board sit up to
  0.75 mm off in any direction, and PCB outline tolerance adds ~±0.2 mm.

## Notes

All geometry — both outlines, the standoff holes, the M3 interface holes, and the
carrier→brain registration offset — is read from `../dual-panel.kicad_pcb` at run
time. **Re-run the generator after any outline or placement change**; only `WINDOW`
is hard-coded, because it describes the frame rather than the boards.

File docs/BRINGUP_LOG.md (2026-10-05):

# Bring-up log

Per-board results from `docs/PANEL_BRINGUP.md` and `docs/MASTER_BRINGUP.md`. One
row per board in the summary, one detail section below it.

**Panels** are named by the RP2040 unique ID the banner prints (read out of
`U307`) — silkscreen carries no serial, so this is the only durable handle on a
physical board.

⚠ **Masters have no equivalent, and the Teensy's serial is NOT a substitute.**
The Teensy is socketed, so its serial identifies *the MCU module, not the board
it is plugged into* — the same Teensy can move between masters, and the
prototype Teensy was in fact reused for master #1. Masters are therefore numbered
by hand, and **the number must be written on the board** (silkscreen carries no
serial here either). The Teensy serial is recorded alongside it only to say which
module was fitted at the time.

Twenty brains and twenty carriers were fabricated, and five master boards; this
file fills in as they are brought up.

## Summary

| board ID | assembled | stage 0 | stage 1 | stage 2 | stage 3 | notes |
|---|---|---|---|---|---|---|
| `DE6558A69754442F` | 2026-09-07 | ✅ | ✅ | ✅ | ✅ | first board powered; found the `INT_OUT` pull-down bug and the VBUS back-drive. Stage 3 2026-10-02 at ID 3 with master #2: `F`, `I`, `S` clean, `A` + `E` closed loop by eye |
| `DE6558A6977D462D` | 2026-10-02 | ✅ | ✅ | ✅ | ✅ | second board; clean first time. ID 1 on 10-01, **ID 0 from 10-02**. `i` skipped, INT proven on the bus with master #2 instead |

### Masters

| board | assembled | stage 1 | stage 2 | stage 3 | Teensy fitted | notes |
|---|---|---|---|---|---|---|
| **master #1** | 2026-09-08 | ✅ | ✅ INT | — | `20432520` (ex-prototype) | SMD hand-soldered with Sn42Bi57Ag1; INT path proven end to end with one panel; `r` closed the single-GPIO-port open item |
| **master #2** | 2026-10-02 | ✅ | ✅ INT | ✅ | `19755070` (new) | all-leaded build: Chip Quik Sn63/Pb37 paste through the printed stencils, no added flux. `S` bus fault found and fixed in master firmware 2026-10-02; first two-panel bus, see below |

## `DE6558A69754442F` — first board

**2026-09-07.** Brain only: JLC-assembled, with `J305` (GCT USB4085 USB-C) and
the `J301`–`J304` interface sockets hand-soldered. No carrier, no 12V — USB is
the only power source.

### Stage 0 — meter, blank flash, in BOOTSEL

Board enumerated as `RPI-RP2` on USB with no BOOTSEL press, as expected from a
blank flash.

| point | signal | reading | verdict |
|---|---|---|---|
| `TP306` | `RS485_DE` | **35 mV** | hard low — internal pull-down parks the THVD1450 in receive. **Closes the rev-2 external pull-down candidate.** First-board-only check |
| `TP302` | +5VDC | **5.25 V** | VBUS through `U304` with no meaningful drop; 0.75 V of margin over `U301`'s 4.5 V minimum |
| `TP301` | +3.3VDC | **3.29 V** | `U302` AP7361C in regulation on the USB-only path |
| `TP303` | `RUN` | **3.3 V** | `R307` pull-up good |

### Stage 1 — bring-up firmware over USB CDC

Firmware `firmware/panel/c/bringup/`, built Sep 3 2026 10:32:02.

```
sysclk        : 125000000 Hz
flash JEDEC   : EF 40 16   OK (Winbond W25Q32JV, 4MB)
board id      : DE6558A69754442F
SENSE_12V     : LOW
```

| check | result | verdict |
|---|---|---|
| enumerate + run | banner printed | crystal, PLL, `U305`, `R305/R306`, QFN USB pads all good |
| sysclk | 125 MHz | `X301` 12 MHz and the PLL at the right frequency |
| flash JEDEC | `EF 40 16` | genuine Winbond W25Q32JV |
| `w` write/verify | **PASS** | `U307` programs and reads back |
| `w` capacity | **PASS — no aliasing, full 4 MB** | a 2 MB die substituted for the 4 MB part is ruled out; the animation slots in upper flash are real |
| `p` | `0 0 0` | expected — see below |
| `s` → `SENSE_12V` | `12V ABSENT`, raw 0, 0 edges | negative half of the 12V-sense test: no bridge to +3.3V, `R313`/`R314` not mis-stuffed |
| `s` → DIP | `15` (`0b1111`) | internal pull-ups on GPIO18–21 all working — there are no board pull-ups on these nets |
| `s` → `TERM_SENSE` | not terminated | GPIO10 internal pull-up working |
| `s` → FSR raw | South 12, West 12, North 12, East 12 | four live ADC channels, ~10 mV, well under the 187 float threshold. **Uniform across all four**, and stable rather than drifting — evidence `R311/R312/R315/R316` are stuffed |
| `i` asserted (dwell) | **9.6 mV** | drives a clean low; ~29 Ω on-resistance against the 10 k |
| `i` released (dwell) | **2.7 V** before fix → **3.29 V** after | ⚠ **found a firmware bug**, now fixed and re-verified — see below |

**`p` = `0 0 0` is correct and guaranteed, not board-specific.** With no 12V the
`+12VDC` net floats, so GPIO17 sees only `R314`'s 33 k to GND; the internal
pull-up (50–80 kΩ) yields 0.96–1.31 V, far below VIH = 2.145 V at either end of
spec. It therefore says nothing about this chip's pull strength. **The pull-down
risk is settled at stage 2 and nowhere else.** An earlier version of
`PANEL_BRINGUP.md` predicted `0 0 1`; that was an arithmetic slip, now fixed.

**`i` needs a pull-up to mean anything.** Metered bare, GPIO22 at `J302` pin 6
read **0.4 mV released, 0.2 mV asserted** — both zero, because standalone nothing
pulls `INT_OUT` up (the master's 10 k and the carrier's `R203`/`D201` are all
absent) and a 10 MΩ meter cannot show "floating". With 10 k tacked from `TP301`
to `J302` pin 6, and with the fast pulse phase correctly ignored (its 2.64 V
duty-cycle average is unreadable on a handheld), the steady dwells gave 9.6 mV
asserted and **2.7 V released**.

### 🐛 Firmware bug found: `INT_OUT` was never truly hi-Z

The 2.7 V is the finding. RP2040 pads reset with the internal pull-**down**
enabled (`PADS_BANK0_GPIOn_PDE_RESET = 1`) and `gpio_init()` does not touch
pulls, so `int_out_release()` gave hi-Z **plus a ~45 kΩ pull-down** fighting the
10 k pull-up: 3.3 × 45/55 = 2.70 V. **This is the documented GPIO17 trap on a
second pin.**

Consequence had it shipped: 2.7 V still clears the Teensy's ~2.31 V VIH, so it
would have worked — with **0.4 V of noise margin instead of 1.0 V on the sole
gameplay input path**. Not a failure, a silent halving of margin.

**Fixed** 2026-09-07 by adding `gpio_disable_pulls(PIN_INT_OUT)` to
`int_out_init()`. **Re-measured after the fix: released dwell = 3.29 V** — the
rail, i.e. true hi-Z — with the asserted dwell unchanged at ~9 mV. Full 1.0 V of
noise margin restored. **`firmware/panel/c/main.c` needs the same call when
ported.**

### Bonus: this board's internal pull-down measures ~45 kΩ

Solved from the divider above. The RP2040 spec is 50–80 kΩ, so this die sits at
or beyond the **strong** end. Same pad structure as GPIO17, which means **stage 2
`p` on this board is predicted to read `1 0 …`** — the pull-down masking 12V,
confirming the trap on real silicon instead of arithmetic. Worth checking against
the prediction when stage 2 runs.

### Not testable at this stage

`l` (LEDs) and `b` (debug LED `D202`) are carrier-side; the `U304` power-mux
hot-swap needs 12V; RS-485 needs peers. Stages 2 and 3.

### Stage 2 — carrier mated, 12V applied

Carrier hand-assembled and mated 2026-09-07. 12V measured **12.02 V** at the
carrier.

| check | result | verdict |
|---|---|---|
| 12V-only, no USB | `D202` blinking 1 Hz | **`U303` AMS1117 proven** — the whole 12V→5V→3.3V chain carries the board with no VBUS anywhere. The documented stage-2 order never reaches this |
| `TP302`, 12V only | **4.965 V** | AMS1117 output. Below VBUS's 5.25 V, so VBUS wins the mux whenever present |
| `TP301`, 12V only | **3.29 V** | `U302` in regulation off the AMS1117 |
| `U303` temperature | barely warm | ~0.2 W in SOT-223 with pour; as expected |
| mux handover | USB removed with 12V live → board kept running, beat unbroken | **`U304` hot-swap passes** in the direction that actually switches |
| `SENSE_12V` edge | `12V PRESENT` logged on applying 12V | **the divider proven** — an edge, not a level a solder bridge could fake |
| `TERM_SENSE` | tracks `SW202`; `TERMINATED` when thrown | pole B agrees with pole A |
| DIP | all OFF → 15, leftmost ON → 7, rightmost ON → 14 | **matches the documented map**: leftmost = bit 3, rightmost = bit 0, ON = 0. Kept as-is |
| FSR raw, unfitted | South 13, West 13, North 12, East 12 | all four channels alive across the carrier interface |
| `f` with 4 FSRs fitted | **all four map correctly**, 2026-09-07 | the edge pressed is the name that moves — `J201`/`J202`/`J203`/`J206` wired as documented. This is the carrier mix-up that would otherwise surface as a gameplay bug much later |
| FSR resting | **94–98** counts | slightly below the breadboard-era ~100–115. Comfortably under the 187 float threshold — ~2× headroom before a resting channel is flagged |
| FSR full press | **~4000** counts | at the top of the 12-bit range; marginally better swing than the prototype's ~3900 |
| ADC crosstalk | **none observed** under a hard press | see below — closes `ADC_DUMMY_READ` |
| `p` with 12V | **`1 1 1`** | pull-down did **not** mask 12V → this die's Rpd > 63.5 kΩ, the weak end. Predicted `1 0 …`; prediction was wrong, rule unchanged |
| `l` LED test | **all 25 lit**, red/green/blue/white | WS2815 chain, `U301`, `R301`, serpentine and the 12V rail under load |

### 🐛 Second finding: the brain back-drives its own VBUS

**USB will not enumerate if 12V is already applied.** Isolated over a 2×2
(cable orientation × 12V): both orientations work with no 12V, neither works with
12V. So it is not a CC joint.

Measured with 12V on and USB unplugged: **VBUS = 2.78 V, D+ = 3.3 V** — one diode
drop apart. The RP2040 asserts its D+ pull-up (1.5 k to 3.3 V) as soon as the USB
stack initialises, and `U305`'s I/O→VBUS ESD diode carries that onto the VBUS
net, which has **no bleeder** (the net is only `J305` VBUS, `U304` IN1 and
`U305`). 2.78 V is above vSafe0V, so a USB-C source refuses to attach.

Corollary seen on the way: pulling 12V from a board with USB attached-but-unpowered
kills it outright and it reboots once the host finally attaches. That looks like a
mux failure and is not one — there was simply nothing to hand over to.

**Rev 1: no rework. Connect USB before 12V** — already the documented stage-2
order, which is why this stayed hidden. Consequence worth knowing: **a laptop
cannot be plugged into a live panel**; drop 12V on that column first.

**Rev 2: candidate #3** — VBUS divider into a spare GPIO so firmware can
`tud_connect()` on real VBUS instead of the SDK's `VBUS_DETECT_OVERRIDE`. A plain
bleeder is the wrong fix: against a 1.5 k pull-up it needs to be <600 Ω and then
burns ~8 mA whenever USB is live.

### ✅ `ADC_DUMMY_READ = 0` confirmed on hardware

Pressing one channel hard moved none of the other three. The breadboard firmware
discarded the first conversion after every mux switch to absorb ~15 counts of
sample-cap charge injection, **at the cost of halving the sample rate**; its own
comment said to drop it once the ADC nodes had 10 nF caps to GND, which this
board has (`C324/C326/C329/C330`). That is now measured rather than assumed, so
**the gameplay firmware keeps the full sample rate** (102 kHz was the RP2040
bench figure) with no dummy read.

### Thresholds against real hardware

Resting 94–98, full press ~4000. The defaults hold with room to spare: press 500
/ release 400 sit well clear of both ends, and the 187 float threshold has ~2×
headroom over a healthy resting channel. No retuning needed. Note that unfitted
channels read ~12, so "unplugged" and "unpressed" remain electrically
indistinguishable by design — presence is config, not measurement.

### Stage 3 — on the bus with master #2, 2026-10-02

At **ID 3**, INT on `L` (`J8`), sharing the bus with `DE6558A6977D462D` at ID 0.
Full run under **master #2 → 2026-10-02**. For this board:

| check | result | verdict |
|---|---|---|
| `'F'` polls | answered every poll addressed to ID 3 | ✅ |
| `I` | ID 3 → `L` (`J8`), 2031 µs low | ✅ ack + INT wire + `INT_OUT` |
| `S 3 500 400` × 50 (fixed master) | 50/50 acked | ✅ `'C'`→`'c'` path |
| counters over the fixed-master runs | **0 CRC, 0 uart, 0 turnaround** in 29,466 frames | ✅ |

| `A` + `E`, real presses | panel lit **green** on press (`L`'s press colour) | ✅ FSR → INT → master → `'L'` → LEDs, by eye |

### Still open for this board

- ~~**`A` with real presses.**~~ Done 2026-10-02, closed loop by eye; see
  master #2 → 2026-10-02. Presses were not counted, unlike board 2's 36.

---

## `DE6558A6977D462D` — second board

**2026-10-02.** First board built from `docs/BUILD_CHECKLIST.md` rather than the
full bring-up docs, so the first-board-only checks were not repeated. Bring-up
firmware built Sep 8 2026 15:08:34.

### Stage 0 and 1 — brain alone on USB

| check | result | verdict |
|---|---|---|
| blank board on USB | mounted as `RPI-RP2`, no button | ✅ |
| `v` sysclk | 125 MHz | ✅ |
| `v` flash JEDEC | `EF 40 16` | ✅ genuine W25Q32JV |
| `w` | write/verify **PASS**, capacity **PASS — no aliasing, full 4 MB** | ✅ |
| `s` → `SENSE_12V` | `12V ABSENT`, raw 0, 0 edges | ✅ |
| `s` → DIP / `TERM_SENSE` | 15 / not terminated | ✅ all five internal pull-ups good |
| `s` → FSR raw | South 16, West 16, North 17, East 16 | ✅ uniform (board 1 read 12) |

### Stage 2 — carrier mated, USB then 12 V

| check | result | verdict |
|---|---|---|
| `s` → `SENSE_12V` | `12V PRESENT`, raw 1, 1 edge | ✅ the edge is 12 V arriving after USB |
| `s` → DIP | 1 (`0b0001`), switches up-up-up-down | ✅ matches what was set |
| `s` → `TERM_SENSE` | TERMINATED | ✅ matches `SW202` |
| `d` | each switch flipped one bit and back: bit 3, 2, 1, 0 in switch order 1–4 | ✅ no bridges or opens on GPIO18–21 |
| FSR, East connected only | rests **97–98**; the three empty channels 15–18 | ✅ inside board 1's 94–98 |
| `f`, East pressed by hand, 15 s | East 96 → peak **3676**; South/West/North stayed 15–18 throughout | ✅ right channel, no crosstalk. Peak below ~4000 is hand press force |
| `l` | all 25 lit, red/green/blue/white | ✅ |
| `p` (run by habit; first-board-only) | `1 1 1` | same as board 1, nothing hangs on it |
| `i` | **skipped** | INT to be proven end to end with the master at stage 3 |
| USB pulled, 12 V live | board kept running | ✅ `U304` handover |
| `TP302` / `TP301`, 12 V only | **4.98 V / 3.304 V** | ✅ `U303` and `U302` in regulation (board 1: 4.965 / 3.29) |
| cold start on 12 V only | board came up | ✅ `U303` starts the board, not just holds it |
| back to USB: 12 V off, USB in, 12 V on | enumerated; `s` unchanged | ✅ |

Only one FSR was connected for this run, so South, West and North were
proven as live ADC channels at rest but not with a sensor pressed. The FSR
connectors themselves (`J201`, `J202`, `J206`) have not carried a sensor yet.

### Stage 3 — on the bus with master #2

See **master #2 → Stage 3** below for the full run. For this board: responder
at address 1, `I` passes on `U` (`J10`), `S` acks, all four command paths
answered, and 36 hand presses on East became 36 clean PRESS/RELEASE pairs at
the master through `A` mode. Counters at steady state: **0 CRC, 0 overruns,
0 uart errors, 1 turnaround** (at enable).

### Still open for this board

- The three FSR connectors not yet exercised with a sensor (`J201` W, `J202` S,
  `J206` N).

## master #1

**2026-09-08.** First master assembled. Bare JLC fab (OSP, 4-layer), every part
hand-soldered including SMD — `U1` SOIC-8, `U3` SOT-23-5, `D1`–`D9` DO-214AC and
22 × 0805 — with **MG Chemicals 4902P (Sn42Bi57Ag1)** low-temp paste by hot air.
`R1`/`R2` left unpopulated as designed.

**Teensy fitted: serial `20432520`, the ex-prototype module** (a new Teensy was
short of headers). Its VUSB↔VIN bridge was inspected and is **intact** — the
board taps VIN, and cutting that bridge costs `U3` its 5V supply with no other
symptom. It was flashed with the as-built `firmware/master/master.ino` *before*
being seated.

> The old prototype build turned out to be harmless on this board anyway, which
> is worth recording so the next person does not over-worry: every pin it drove
> as an output (Serial1 TX pin 1, DE pin 2, LED pin 13) lands on a **spare,
> unconnected** pad here, and the two pins that were repurposed (3/4, breadboard
> INT → player-ID DIP) were `INPUT_PULLUP` inputs against a switch to GND, i.e.
> ~150 µA. Flashing first is still the right habit; it just was not load-bearing.

### INT front end — verified in both directions

| check | result |
|---|---|
| `n` — all nine INT lines idle | **all HIGH** — no bridge, no shorted `C3`–`C11` |
| `N` — external pull-up (`RN1`) present | **all nine OK** — PASS |

`N` was written for this board (see `docs/MASTER_BRINGUP.md`) after noticing that
`n` alone **cannot** detect a missing `RN1`: the Teensy's internal pull-ups mask
it and the test still passes. Both together prove no shorts *and* no opens across
`D1`–`D9` / `R6`–`R14` / `C3`–`C11` and all ten `RN1` joints.

`N` also doubles as a seated/not-seated check — standalone it reads all nine LOW.

### `r` — single-GPIO-port claim CONFIRMED, and it closes a documented open item

`docs/MASTER_PCB.md` carried GPIO15–23 sharing one i.MX RT port as a
*processor-reference claim, not derived from the board files*, to be checked at
bring-up. It holds: **all nine INT pins report register `0x42000008`.** A single
read samples the whole pad, which the glitch-qualify re-read and the `'I'`
self-test both want.

⚠ **The bits are scattered — this needs a lookup table, not a shift.**

| panel | 0 `UL` | 1 `U` | 2 `UR` | 3 `L` | 4 `C` | 5 `R` | 6 `DL` | 7 `D` | 8 `DR` |
|---|---|---|---|---|---|---|---|---|---|
| pin | 23 | 22 | 21 | 20 | 19 | 18 | 17 | 16 | 15 |
| bit | 25 | 24 | 27 | 26 | 16 | 17 | 22 | 23 | 19 |

They do not descend with pin number, and `DR`/pin 15 lands on bit 19 — in the
middle, not at an end.

### `D` — player-ID DIP confirmed

Reads **0 (P1)** with all three switches ON, exactly as the inverted-DIP note
predicts. All-OFF reads 7, a reserved code — the deliberate choice, so that an
unconfigured master does not claim to be P1.

### Stage 2 — INT path end to end, master + one panel

**2026-09-08.** Master #1 with one panel (brain `DE6558A69754442F` + carrier),
12V on the panel, RS-485 cable fitted, INT cable on the `UL` header (`J11`).
Panel ran `i` from `firmware/panel/c/bringup/`.

**PASS.** Five 200 ms pulses then one 8 s dwell — exactly what `int_test()`
emits (a 5-iteration loop, then phase 2). Every `PRESS` had exactly one
`RELEASE`. **No bounce, no spurious edges, nothing dropped from the ring.**

This is the first time the sole gameplay input path has run over real hardware
end to end: panel GPIO22 (emulated open-drain) → carrier `R203`/`D201` → `J214`
→ cable → master `J11` → `D1`/`R6`/`C3` → `RN1` → Teensy pin 23 → ISR → ring.

#### Two numbers worth keeping

**Clock agreement: +7 ppm.** Press-to-press period measured 1 000 007 µs
(1000009/1000007/1000007/1000006) against an intended 1 000 000. Both ends of
that interval are *falling* edges, so the edge asymmetry below cancels and this
is a clean read of the RP2040 crystal against the Teensy's. 7 ppm between two
independent crystals is excellent. **Affects nothing** — the master timestamps
every edge off its own `micros()`, so panel/master drift never reaches a
reported number. Useful only as a free crystal sanity check.

**Assert/release asymmetry: ~22 µs, structural.** Hold measured 200.023 ms
against 200 ms; removing the 7 ppm leaves ~22 µs of excess, and four readings
sat within 2 µs of each other, so it is not noise.

- **Assert** — RP2040 drives LOW, hard and fast. This is the press path.
- **Release** — pin goes hi-Z and the line rises *passively* through `RN1`'s 10k
  into `C3` (1 nF) plus the junction capacitance of `D1` and `D201`.

10k × 1nF alone predicts ~12 µs to VIH; 22 µs implies ~1.8 nF total, i.e. roughly
800 pF across the two TVS. That is ordinary for SMAJ5.0A — **consistent with the
design, not a fault.** No action: presses are prompt, and 22 µs of release
latency is invisible against a 125 µs USB frame. `docs/USB_PROTOCOL.md`'s latency
table was corrected, since its "RC settle ~1 µs" row is the *press* figure and is
~20× optimistic if applied to a release.

⚠ **Only phase 1 is valid for timing.** Phase 2's 8 s dwell measured 8000.333 ms,
~275 µs long — a **software artifact**, not electrical: `int_test()` has a
four-line `printf` sitting between `sleep_ms(INT_DWELL_MS)` and
`int_out_release()`, so the release waits on a USB CDC write. Phase 1 has no
printf inside its loop, which is why those readings are clean.

#### RS-485 not tested — and it cannot be yet

`bus: 0/51961 poll replies` is **correct, not a fault.**
`firmware/panel/c/bringup/main.c` has **no RS-485 responder** — it only parks
`DE` low into receive (`gpio_put(PIN_RS485_DE, 0)`), with no `uart_init` on that
path, and `firmware/panel/c/main.c` is still breadboard-pinned. Nothing will
answer until that port is done. `0 crc errs` is likewise uninformative: nothing
replies, and the master cannot hear itself with `DE` tied to `R̅E̅`. It does
weakly confirm the bus picks up no garbage between transmissions.

### 🔧 Assembly defect found: `U3` had bridged pins

**The first real assembly fault on this board, and it took a new test to see it.**
`U3` (SN74AHCT1G125, SOT-23-5, hot-air placed) had **shorted pins**. Reflowed and
the level shifter now translates correctly — `U` passes.

**`u` could never have found this.** It sends real WS2811 frames at ~0.1% average
duty, so a meter reads ~5 mV whether `U3` works or not; the first reading taken
was "basically 0, and `u` doesn't change it", which is the *correct* reading of a
*working* pin through a slow instrument. `U` was written in response, and its
documented failure mode — "`TP10` stuck at 0 V while `TP9` switches" — is exactly
what the board was doing.

⚠ **Generalise this to the rest of the hot-air work.** `U3` is SOT-23-5 at 0.95 mm
pitch; **`U1` (THVD1450, SOIC-8) is the same class of risk and has had no
electrical test at all**, because RS-485 cannot be self-tested — `U1` pads 2 and 3
are both on `RS485_DE`, so transmitting kills the local receiver. A bridge there
stays invisible until a panel can answer. Inspect `U1` under magnification and
ring out its pins before blaming the protocol at stage 3.

`R4` was confirmed **PRESENT** by the same command — the 10k pull-down that holds
`U3`'s input LOW before firmware drives the pin, whose absence would put garbage
on the strip at every boot with no other symptom.

**Stage 1 is now complete on master #1**, as far as a bench allows: `U3`, `R4`,
`R5` and `J2` are all cleared with no strip attached. The underglow cable and the
LEDs themselves need the pad and are an install-day check, not a bring-up item.
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

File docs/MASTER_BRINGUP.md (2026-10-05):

# Master bring-up

Companion to `docs/PANEL_BRINGUP.md`. Written 2026-09-03, before any board was
powered; every pin and net below was read out of `master-pcb.kicad_pcb`.

**Firmware: `firmware/master/master.ino`** — unlike the panel, this is not a
separate tool. The master sketch had to be ported to the as-built board anyway,
and every board-local check it needs (DIP, underglow, INT idle states, the GPIO
port layout) works with **zero panels connected**, so the bench commands live in
the real firmware rather than a second sketch.

```sh
arduino-cli compile --fqbn teensy:avr:teensy40 firmware/master
arduino-cli upload  --fqbn teensy:avr:teensy40 firmware/master
```

## The port — what changed, and the trap in it

The breadboard prototype drove 2 panels. The as-built board drives 9, on a
different UART, with two subsystems the prototype did not have at all.

| | prototype | as built |
|---|---|---|
| panels | 2 | 9 |
| RS-485 | `Serial1`, DE on pin 2 | **`Serial2`** (RX 7 / TX 8), **DE on 6** |
| INT lines | pins 3, 4 | **pins 23,22,21,20,19,18,17,16,15** = panels 0–8 |
| player-ID DIP | — | **pins 3, 4, 5** |
| underglow | — | **pin 11** → U3 → R5 330R → J2.1 |

> ⚠ **The old map is not a subset of the new one.** Pins **3 and 4 carried the
> two INT lines on the breadboard and carry the player-ID DIP on the board.** A
> partial port — fixing the UART but leaving the INT pins — would have read the
> DIP switch as panel presses and looked like a wiring fault. This is the reason
> the port was done wholesale rather than incrementally.

Panel order is by ID: panel 0 (`UL`) is on pin 23 and descends to panel 8 (`DR`)
on pin 15 — **the pin numbers run backwards against the panel numbers.** The
firmware prints the silkscreen position (`UL`/`U`/`UR`/…) rather than a pin
number wherever it can, because that string is also what is printed on the cable
label, so nothing at the bench needs a lookup table.

## Bench commands

Type a letter **and press Enter** over USB serial. `?` lists them. The first
five need no panels and no 12V.

> ⚠ **This differs from the panel, and the difference bites coming off a panel
> bring-up.** `firmware/panel/c/bringup/` uses `getchar_timeout_us()` and acts
> on a **single keypress**; the master buffers a line and acts on `\n`/`\r`.
> The master has to work this way — `S <panel> <press> <rel>` takes arguments,
> so a single-key mode would fire `S` before you could type the thresholds.
>
> **Local echo was added 2026-09-08** (with backspace), because `S <panel>
> <press> <rel>` is unusable blind — you cannot spot a typo before Enter, and a
> dumb serial terminal does not echo for you. Your keystrokes now appear as you
> type. A reply can still land between two `[heartbeat]` lines. Keys doing
> "nothing" in `screen` is otherwise screen's copy/scrollback mode — a stray
> trackpad scroll enters it and swallows every keystroke until you press `Esc`.

| cmd | what it does |
|---|---|
| `n` | all nine INT line states, by panel position and connector |
| `N` | INT **external** pull-up (RN1) check — proves the 10k×9 is really there |
| `r` | which GPIO port register and bit each INT pin lands on |
| `D` | read the player-ID DIP |
| `u` | underglow test pattern — **scope only** |
| `U` | underglow steady levels + `R4` check — **the multimeter one** |
| `g` | underglow chase — one group lit at a time, 1 → 44 from the connector, 300 ms each |
| `g <n>` | light underglow group *n* (1–44) alone and hold it |
| `x` | pause/resume LED frames + FSR polling |
| `I` | slot ↔ panel-ID self-test (needs panels) |
| `t` | toggle the telemetry stream |
| `S <panel> <press> <rel>` | set FSR thresholds on one panel |

## Stage 1 — master alone, USB only

The board has **no regulators and no magnetics**; everything runs off the
Teensy's USB power (`+5VDC_USB` from VIN, plus the Teensy's own 3.3V regulator).
So a bare master needs nothing but a USB cable.

⚠ **The board taps Teensy VIN, not the raw VUSB pad — the on-Teensy VUSB↔VIN
bridge must stay intact.** Cut it and U3 loses its 5V supply and the underglow
goes dark with no other symptom.

**`N` — the external pull-up check, and why `n` is not enough.** Run this
before or after `n`; it is the one that actually tests the board.

`n` reads the INT lines with the Teensy's *internal* pull-ups enabled
(`pinMode(INT_PINS[i], INPUT_PULLUP)`), so it can only catch a line stuck LOW —
a bridge or a shorted `C3`–`C11`. It is **blind to the opposite fault**: with
`RN1` unsoldered every line still reads HIGH, held by the internal pull-up, and
`n` reports a clean pass. That is not a hypothetical on a hand-assembled board.
`RN1` is a THT SIP-10 whose **pin 1 is the common feeding all nine resistors**,
so a single cold joint there removes every external pull-up at once — and the
10k value is deliberate (`docs/MASTER_PCB.md`: "deliberately 10k not stiff", the
INT-into-dead-panel case), so silently running on the Teensy's internal pull-up
instead is a real, invisible deviation.

`N` inverts the bias to settle it. With the internal pull-**down** selected
(~100k on i.MX RT), `RN1`'s 10k to +3.3VDC still wins the divider —
3.3 × 100/110 ≈ 3.0 V, a solid HIGH — while a line with no external pull-up is
dragged to 0 V. `RN1` lands on the Teensy-side node (same net as `C3`–`C11`), so
the settling RC is 100k × 1nF = 100 µs worst case; the code waits 1 ms.

| result | meaning |
|---|---|
| all nine `OK` | `RN1` present and pulling on every line, all nine traces continuous |
| any line `NO external pull-up` | that line only: `RN1` joint, or an open trace to the Teensy pin |
| all nine missing | `RN1` pin 1 (the common) is open — **or the Teensy is not seated** |

⚠ **Nothing may be plugged into `J3`–`J11` while `N` runs.** A panel holding its
open-drain INT low is indistinguishable from a missing pull-up. The command
detaches the INT interrupts, flips the pin modes, and flushes the edge ring
before re-attaching them — without that flush the mode changes surface as nine
phantom presses.

**`n` — INT idle states.** All nine must read HIGH. `RN1` (10k ×9 bussed) pulls
every line to +3.3VDC, so a LOW line with nothing plugged in is a board fault:
a solder bridge, or a shorted `C3`–`C11`. Each line's protection chain is
TVS (`D1`–`D9`, SMAJ5.0A) → 330R (`R6`–`R14`) → 1nF C0G (`C3`–`C11`) to GND at
the Teensy-side node, forming a ~330 ns low-pass.

**`r` — the single-port question.** `docs/MASTER_PCB.md` flags this as "worth
confirming at bring-up, not verified here": all nine INT pins are `AD_B1_xx`
pads and *should* sit on one i.MX RT GPIO port, which would let a future fast
path sample every panel in a single register read. `r` reports the register
address and bit index for each pin, straight out of the core's own tables, and
says whether they match. **Expect them to match and the bit positions to be
scattered** — one read, but a table rather than a shift.

**`D` — the player-ID DIP**, and the same trap the panel has:

> `SW1` closes to GND against internal pull-ups (pads 4/5/6 are all GND), so a
> **closed switch reads 0**, and the bit order runs backwards against pin
> number — **pin 3 is bit 2, pin 5 is bit 0**. So **player 0 (P1) means all
> three switches ON**, and a factory-fresh all-OFF switch reads **7**, a
> reserved code. Netlist-verified; the panel's ID DIP behaves identically.

**`U` — the meter-readable underglow test, and why `u` is not one.**

⚠ **A DMM cannot see `u` at all, and the reading looks like a dead pin.** `u`
sends five real WS2811 frames — 44 groups × 24 bits × 1.25 µs ≈ 1.3 ms of burst
each — separated by 600–1200 ms with the line parked LOW, and it ends blanked.
Average duty across the run is **~0.1%**, so a handheld meter reports **~5 mV**
whether U3 works or not. That is a correct pin seen through a slow instrument,
exactly the trap the panel's `i` hit (which is why `i` grew 8-second dwells).
**`u` is for a scope. Use `U` with a meter.**

`U` does two things a meter can read:

- **`R4` present?** Pin to `INPUT_PULLUP` and read. `R4` (10k to GND) against the
  Teensy's internal ~22k divides to ~1.0 V = **LOW**; with `R4` missing the
  internal pull-up wins and it reads **HIGH**. Worth its own check because `R4`
  holds `U3`'s input LOW *before firmware drives the pin* — a missing one puts
  garbage on the strip at every boot and has **no other symptom**.
- **Steady 6 s dwells**, HIGH then LOW, each announced first.

| point | HIGH | LOW |
|---|---|---|
| `TP9` — 3.3V side, `U3` pin A | ~3.3 V | ~0 V |
| `TP10` — 5V side, `U3` pin Y | ~5 V | ~0 V |

**`TP10` following `TP9` is the whole test** — that is `U3` translating
3.3 V → 5 V, the one job it has. `TP10` stuck at 0 V while `TP9` switches means
`U3` is dead, unpowered (check `+5VDC_USB` at `TP4`), its OE̅ (pin 1) is not
grounded — **or its pins are bridged, which is what happened on master #1.**
`J2` pin 1 sits behind `R5` (330R) and reads the same as `TP10` with nothing
plugged in.

`U` ends with a blanking frame: a steady HIGH is not a valid WS2811 reset (a long
LOW is), so a connected strip could latch garbage — the LOW dwell resets it and
the zeros frame clears it.

**A pass clears the entire master-side chain — `U3`, `R4`, `R5`, `J2` — with no
strip attached.** Only the cable and the LEDs then need the pad, which makes them
an install-day check rather than a bring-up item.

**`u` — underglow.** Drives WS2811 data out pin 11 → `U3` (SN74AHCT1G125 at 5V)
→ `R5` 330R → `J2` pin 1. Two things to know:

- **`R4` (10k pull-down) holds U3's input LOW before firmware drives the pin**,
  so the strip sees no garbage during boot. Worth confirming with a scope on a
  first power-up.
- **The strip's 12V comes from the Wago fan-out, not from this board.** With the
  fan-out unpowered, `u` proves only that U3 switches — probe U3's Y pin.
  ⚠ And the connector pinout is **pin 1 = GND, pin 2 = DATA, pin 3 = 12V**, the
  reverse of what was originally assumed; building to the old order puts 12V
  into DATA and destroys the first LED.
- Underglow is **WS2811 — three independent constant-current sinks**, so colour
  scales current linearly. This is the *opposite* of the panels' WS2815, where
  red draws exactly as much as white. Do not carry a power intuition across.

The bit-bang is deliberately approximate (T1H ~600 ns / T0H ~250 ns against a
±150 ns tolerance) — a presence check for U3 and the cable, not a driver. Scope
it once, then trust it.

## Stage 2 — master + one panel

`x` first, to stop the master flooding the bus, then bring the panel up on its
own terms (`docs/PANEL_BRINGUP.md`), then resume.

⚠ **RS-485 cannot be self-tested on the master either.** `U1` pads 2 and 3 are
both on `RS485_DE` — R̅E̅ is tied to DE, exactly as on the panel — so
transmitting disables the local receiver and there is no loopback. Two nodes
minimum.

Termination is `R3` (120R, wired across `RS485+`/`RS485−`) at the master end and
`SW202` at the last panel. `R1`/`R2` (390R failsafe bias) are **DNP and were not
ordered** — the THVD1450's integrated open/short/idle failsafe makes them
unnecessary; the footprints exist so bias can be hand-added at the one correct
bus point if the bench ever disagrees.

> ~~Minor documentation trap~~ **FIXED 2026-09-08, no physical consequence.**
> The `Description` fields on R1/R2 used to call the bias pair "R4+R5" and say
> they were "PARKED UNWIRED" — naming that predated the 2026-07-31 master
> renumber. The bias pair is **R1/R2**, they *are* wired in the netlist, and
> **R4/R5 are the underglow pull-down and series resistor, both of which must be
> populated.** The same "PARKED UNWIRED" text sat on all ten test points, which
> are likewise wired. Descriptions in `.kicad_sch`/`.kicad_pcb` were corrected
> and `master-pcb-BOM.csv` regenerated; the edit touched description strings
> only, no geometry and no nets.

**Unlike the panel, the master has no manual-DE hazard.**
`Serial2.transmitterEnable(6)` makes the hardware assert and release DE around
each transmission. The truncated-last-byte trap is panel-side only, where the
RP2040's PL011 has no auto-direction mode on any pin.
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

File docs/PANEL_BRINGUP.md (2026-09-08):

# Panel bring-up

How to prove a freshly assembled `dual-panel` board works, and in what order.

Written 2026-09-03, while the LCSC parts parcel was still in transit. Every pin,
net and part number was re-derived from `dual-panel.kicad_pcb` and
`docs/DUAL_PANEL.md`.

**Stage 0 has since been run on real hardware (2026-09-07) and is closed** — see
below. Stages 1–3 are still as-written and unexercised.

**Firmware: `firmware/panel/c/bringup/`.** It is deliberately *not* the gameplay
firmware. `firmware/panel/c/main.c` is breadboard-pinned (LED on GPIO4, INT on
GPIO5, DE on GPIO2) and needs a port to the as-built map regardless; but the port
should not be the first thing to run on a real board, because bring-up happens in
a world the gameplay firmware does not model — a **standalone brain with no
carrier**: no DIP switch, no termination switch, no FSR connectors, no LEDs, no
12V. The bring-up build is single-core, USB-CDC interactive, and free to be as
chatty as a bench tool should be.

Build (note the toolchain — the Homebrew `arm-none-eabi-gcc` on `PATH` has no
newlib and dies on `nosys.specs`):
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

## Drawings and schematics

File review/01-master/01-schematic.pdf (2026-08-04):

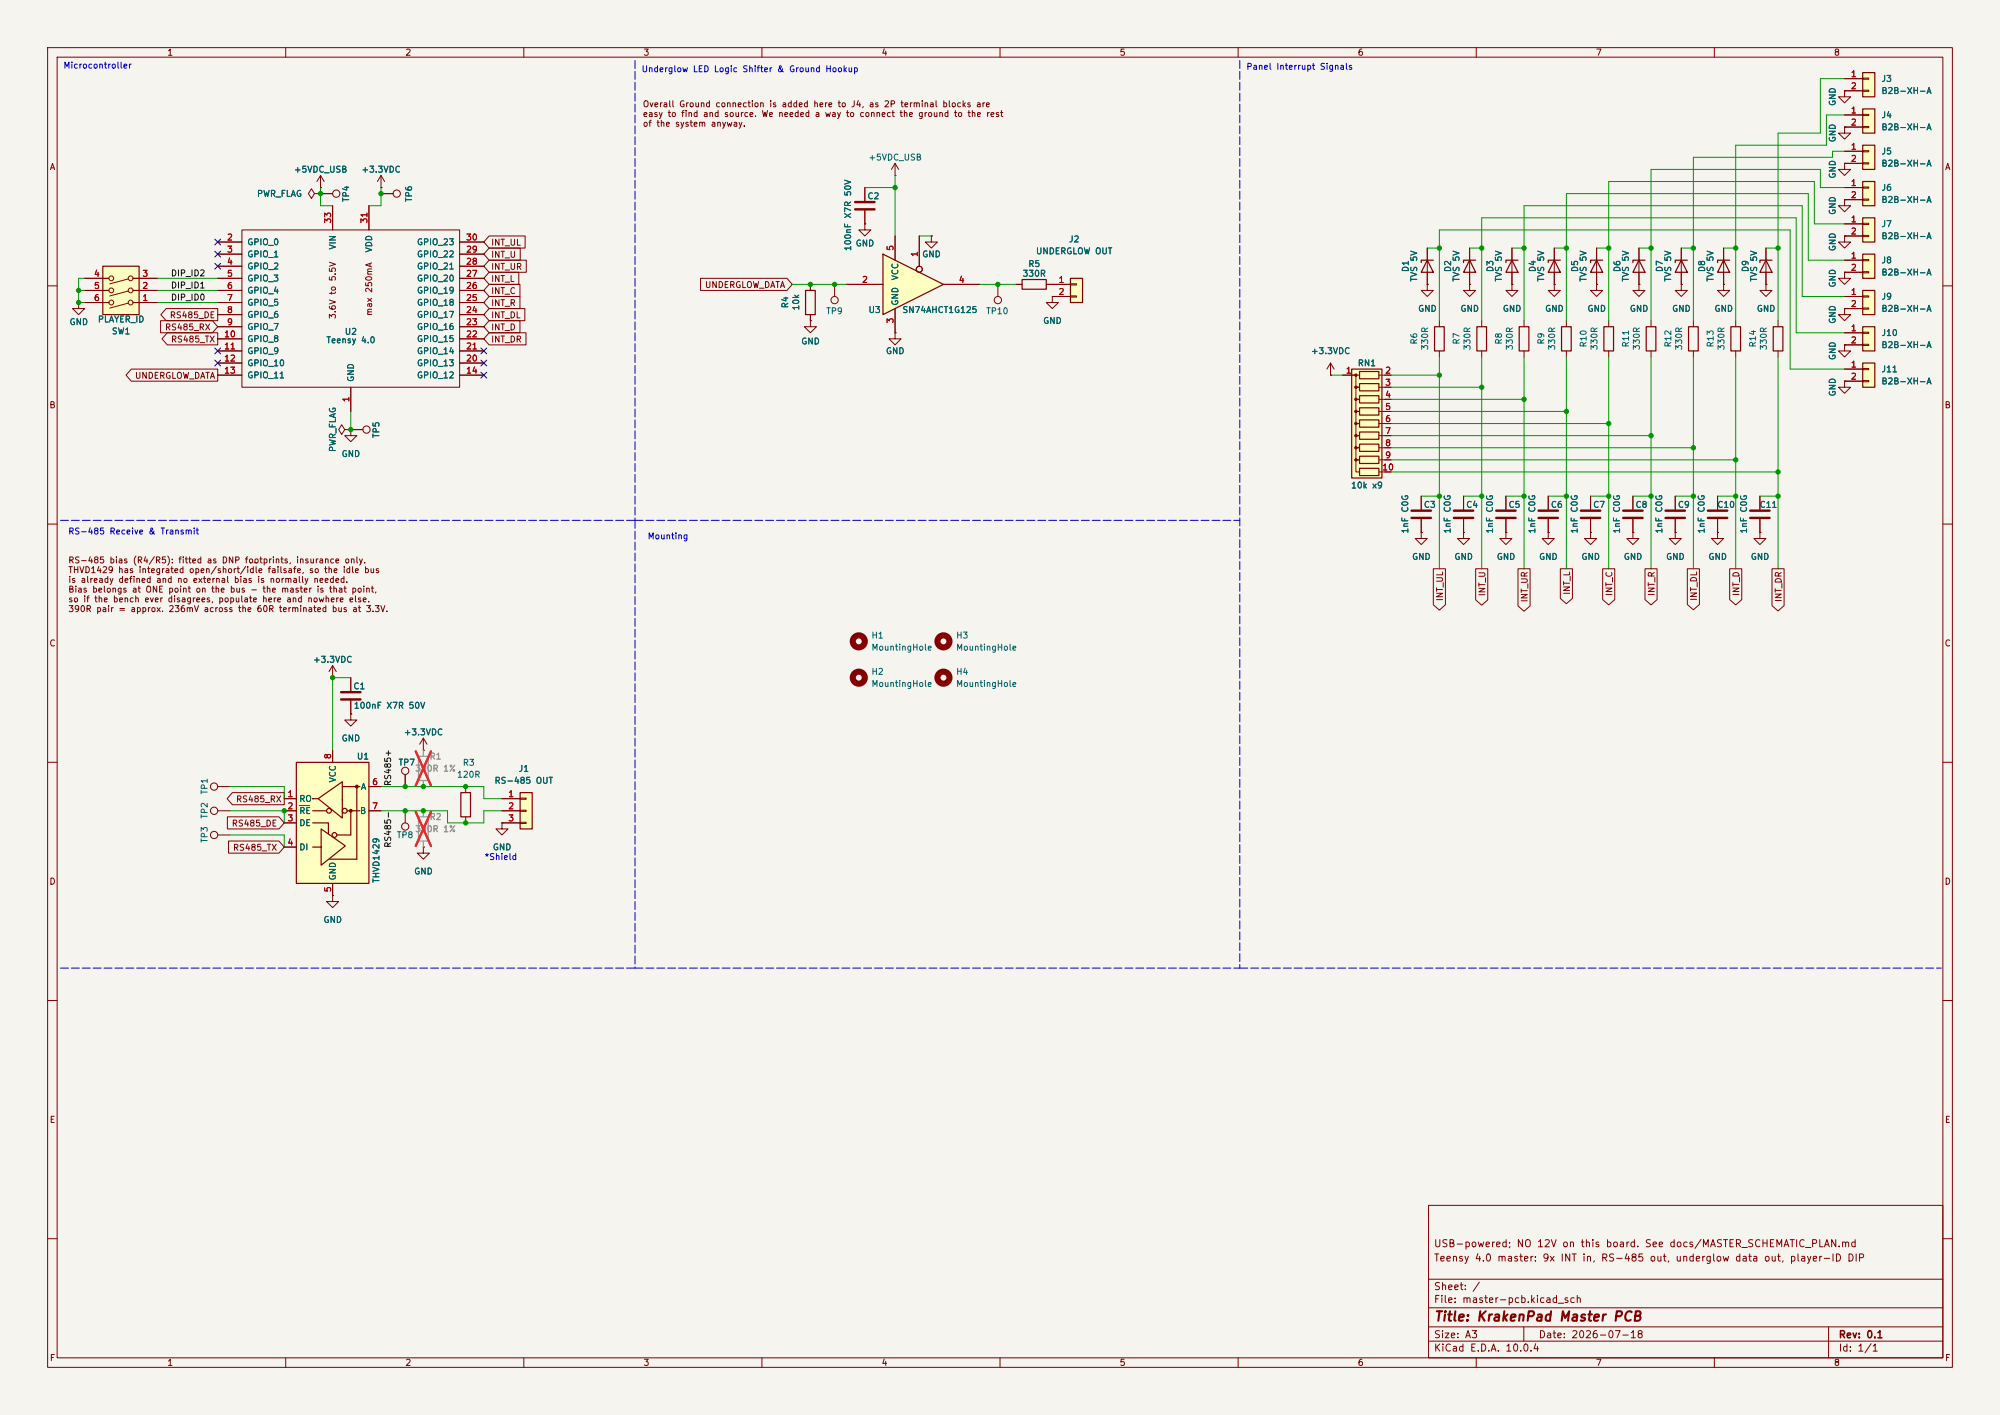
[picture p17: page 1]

Overall Ground connection is added here to J4, as 2P terminal blocks are easy to find and source. We needed a way to connect the ground to the rest of the system anyway. Underglow LED Logic Shifter & Ground Hookup

Mounting RS-485 bias (R4/R5): fitted as DNP footprints, insurance only. THVD1429 has integrated open/short/idle failsafe, so the idle bus

USB-powered; NO 12V on this board. See docs/MASTER_SCHEMATIC_PLAN.md
Teensy 4.0 master: 9x INT in, RS-485 out, underglow data out, player-ID DIP

Sheet: /
File: master-pcb.kicad_sch
Title: KrakenPad Master PCB

Size: A3 | Rev: 0.1
KiCad E.D.A. 10.0.4 | Id: 1/1 | F Date: 2026-07-18

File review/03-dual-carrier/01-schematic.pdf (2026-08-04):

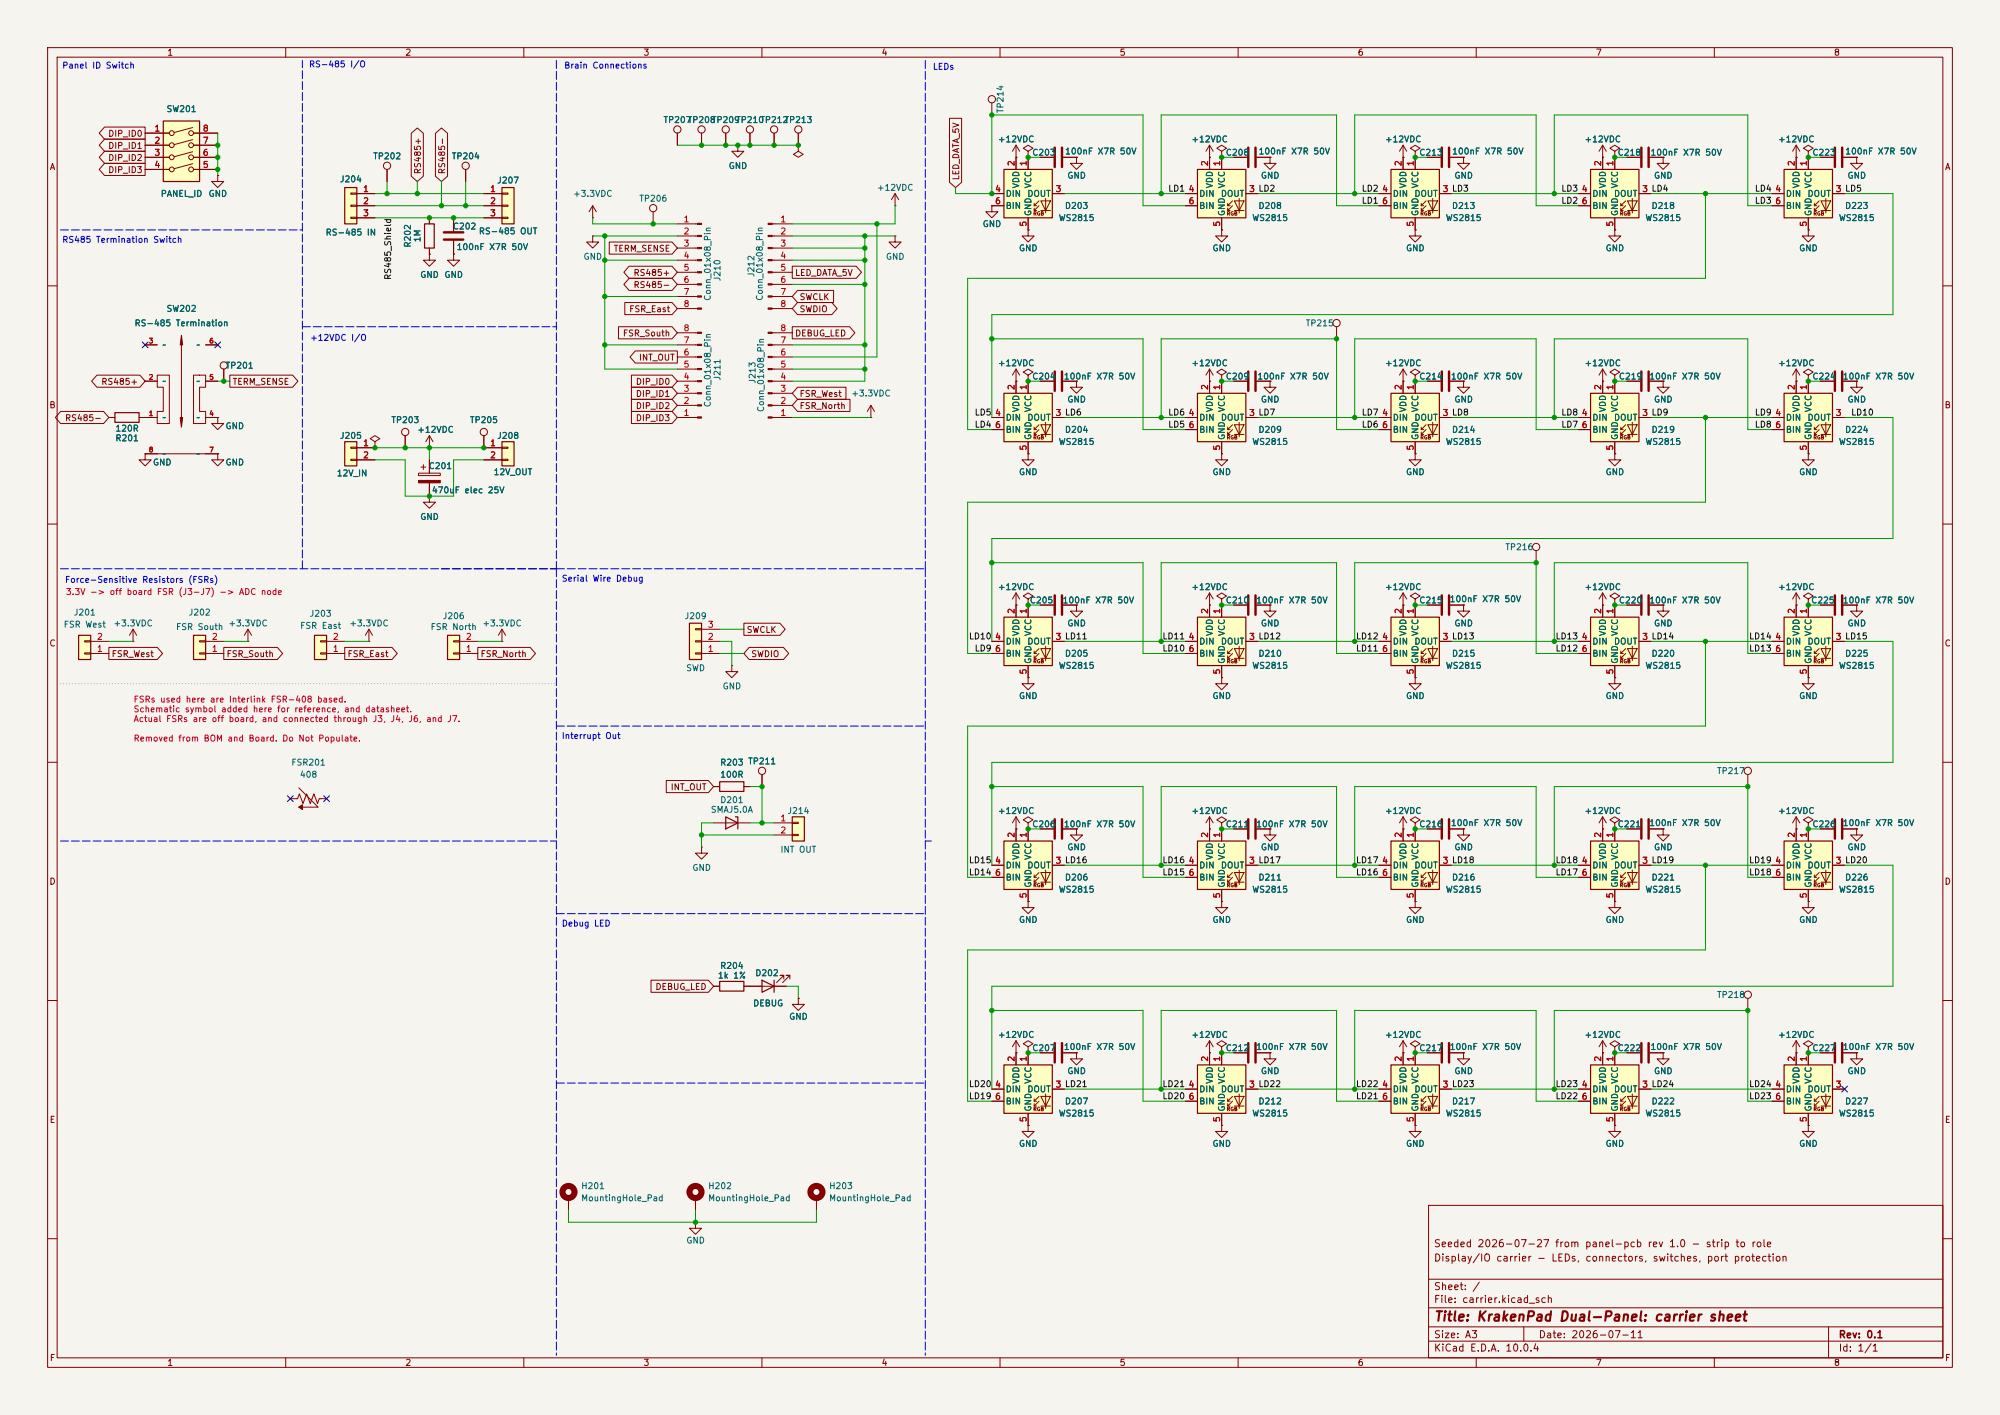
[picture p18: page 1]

LEDs Serial Wire Debug

Seeded 2026-07-27 from panel-pcb rev 1.0 - strip to role
Display/IO carrier - LEDs, connectors, switches, port protection

Sheet: /
File: carrier.kicad_sch
Title: KrakenPad Dual-Panel: carrier sheet

Size: A3 | Rev: 0.1
KiCad E.D.A. 10.0.4 | Id: 1/1 | F Date: 2026-07-11

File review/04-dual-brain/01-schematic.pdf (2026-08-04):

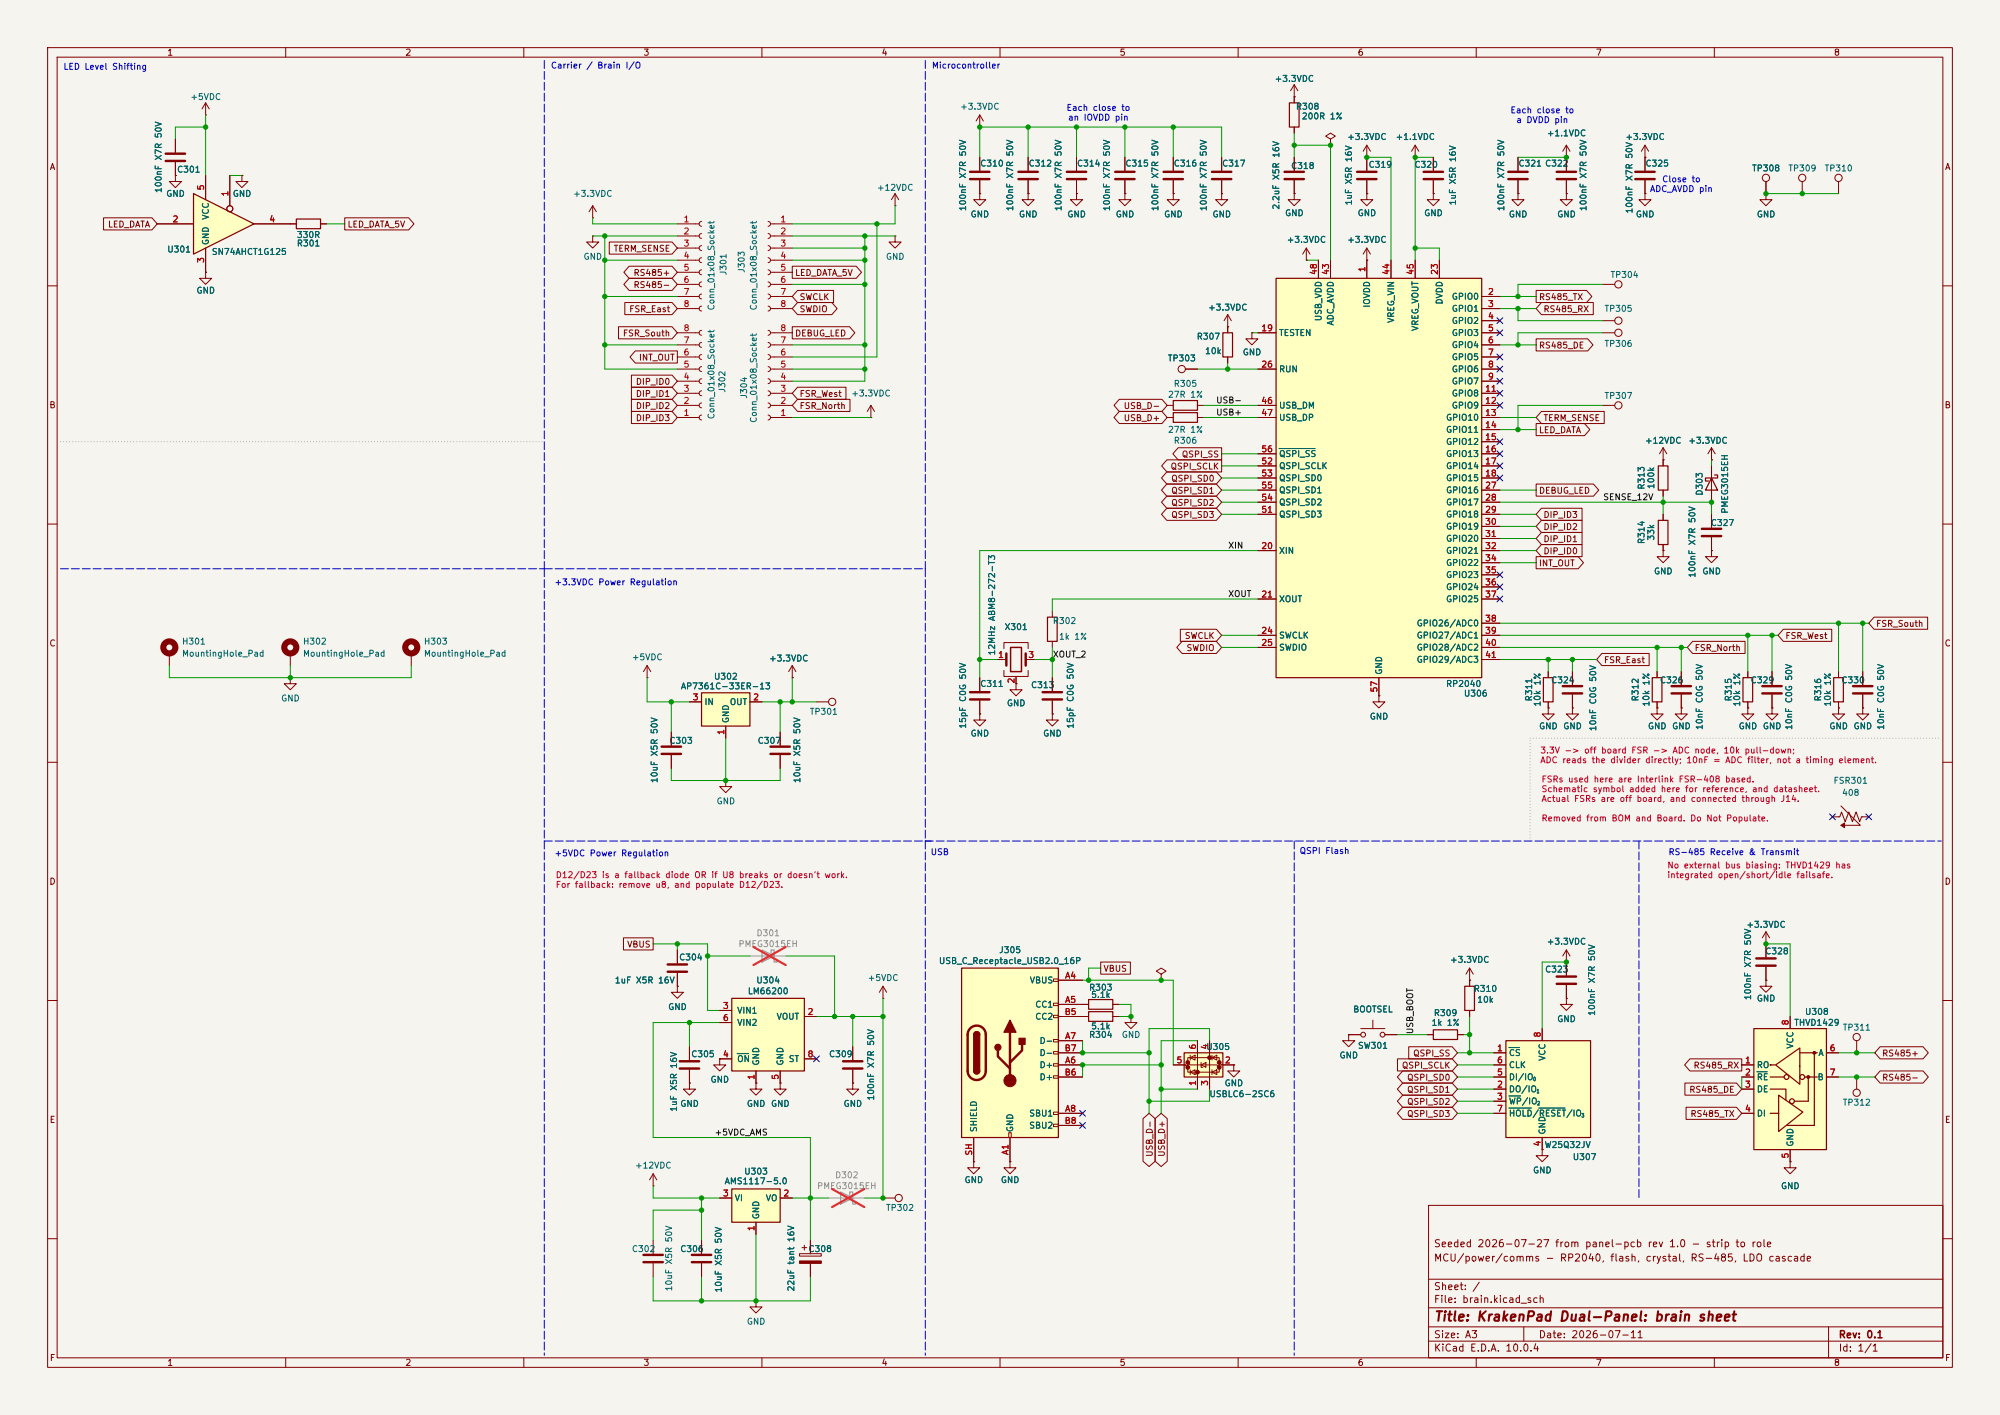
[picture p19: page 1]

3.3V -> off board FSR -> ADC node, 10k pull-down; ADC reads the divider directly; 10nF = ADC filter, not a timing element. RS-485 Receive & Transmit FSRs used here are Interlink FSR-408 based. Schematic symbol added here for reference, and datasheet. Actual FSRs are off board, and connected through J14. Removed from BOM and Board. Do Not Populate.

integrated open/short/idle failsafe.
GND +3.3VDC
THVD1429 GND
7 VCC

J305 USB_C_Receptacle_USB2.0_16P

4 DI/IO0 5 CLK 6 HOLD/RESET/IO3 7 VCC

SBU2 | B8 SHIELD SH

Seeded 2026-07-27 from panel-pcb rev 1.0 - strip to role
MCU/power/comms - RP2040, flash, crystal, RS-485, LDO cascade

Sheet: /
File: brain.kicad_sch
Title: KrakenPad Dual-Panel: brain sheet

Size: A3 | Rev: 0.1 | F Date: 2026-07-11
KiCad E.D.A. 10.0.4 | Id: 1/1

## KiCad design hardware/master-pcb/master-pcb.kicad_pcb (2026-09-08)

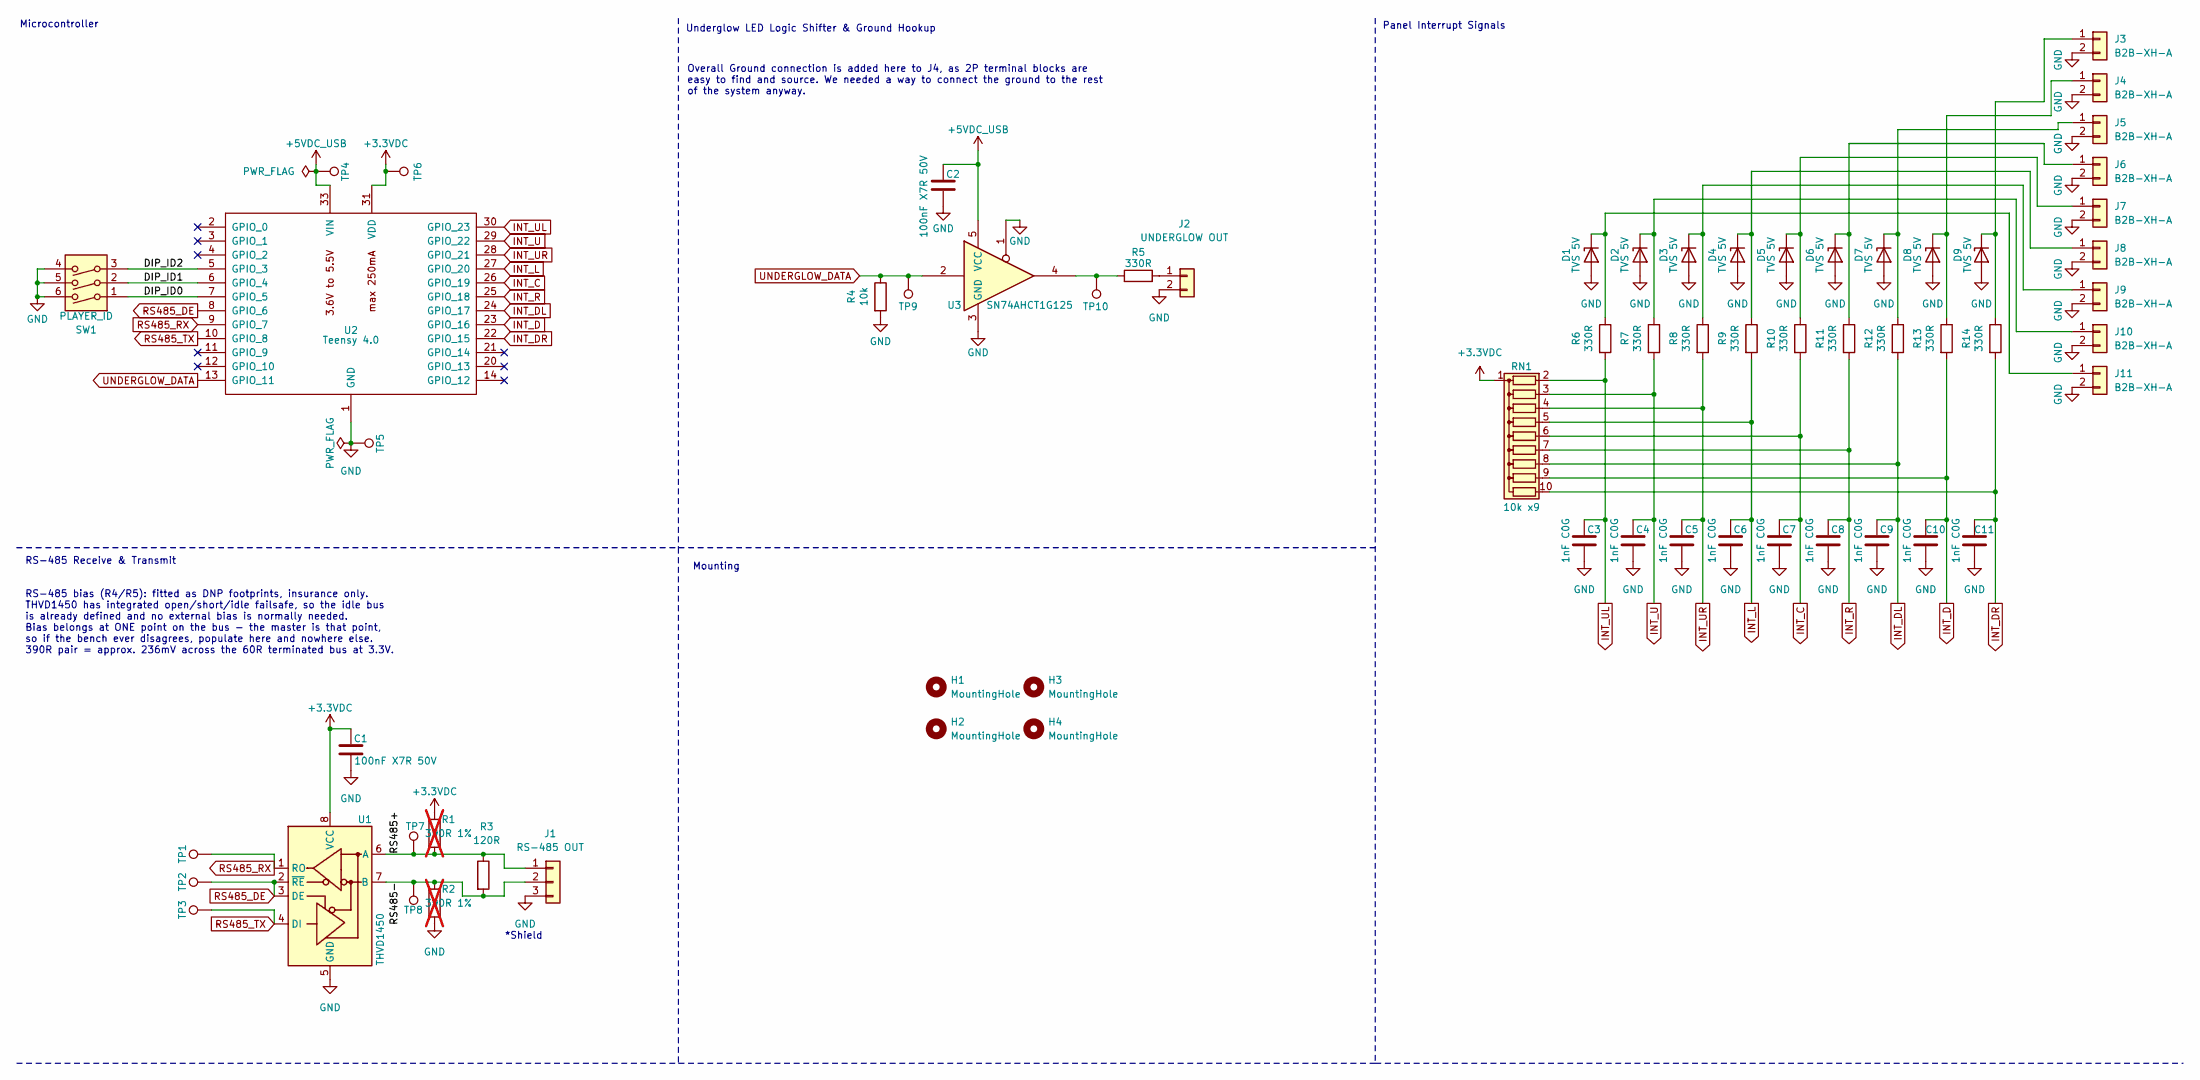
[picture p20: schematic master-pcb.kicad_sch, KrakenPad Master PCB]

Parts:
C1, C2: 100nF X7R 50V; C_0805_2012Metric; LCSC C83055
C3, C4, C5, C6, C7, C8, C9, C10, C11: 1nF C0G; C_0805_2012Metric; LCSC C1791
D1, D2, D3, D4, D5, D6, D7, D8, D9: TVS 5V; D_SMA_Handsoldering; MPN SMAJ5.0A; LCSC C113952
H1, H2, H3, H4: MountingHole; MountingHole_3.2mm_M3
J1: RS-485 OUT; Molex_Micro-Fit_3.0_43650-0300_1x03_P3.00mm_Horizontal; MPN 0436500300; LCSC C503478
J2: UNDERGLOW OUT; TerminalBlock_WJ500V-5.08-2P; MPN WJ500V-5.08-2P; LCSC C8465
J3, J4, J5, J6, J7, J8, J9, J10, J11: B2B-XH-A; JST_XH_B2B-XH-A_1x02_P2.50mm_Vertical; LCSC C158012
R1, R2: 390R 1%; R_0805_2012Metric; not fitted
R3: 120R; R_0805_2012Metric; LCSC C844816
R4: 10k; R_0805_2012Metric; LCSC C192906
R5, R6, R7, R8, R9, R10, R11, R12, R13, R14: 330R; R_0805_2012Metric; LCSC C844839
RN1: 10k x9; R_Array_SIP10; MPN 4610X-101-103LF; LCSC C840655
SW1: PLAYER_ID; SW_DIP_SPSTx03_Slide_9.78x9.8mm_W7.62mm_P2.54mm; MPN DS-3P-BU; LCSC C46595747
TP1: RS-485 RX; TestPoint_THTPad_D2.0mm_Drill1.0mm
TP2: RS-485 DE; TestPoint_THTPad_D2.0mm_Drill1.0mm
TP3: RS-485 TX; TestPoint_THTPad_D2.0mm_Drill1.0mm
TP4: +5VDC_USB; TestPoint_THTPad_D2.0mm_Drill1.0mm
TP5: GND; TestPoint_THTPad_D2.0mm_Drill1.0mm
TP6: +3.3VDC; TestPoint_THTPad_D2.0mm_Drill1.0mm
TP7: RS-485 A; TestPoint_THTPad_D2.0mm_Drill1.0mm
TP8: RS-485 B; TestPoint_THTPad_D2.0mm_Drill1.0mm
TP9: Underglow DATA 3.3V; TestPoint_THTPad_D2.0mm_Drill1.0mm
TP10: Underglow DATA 5V; TestPoint_THTPad_D2.0mm_Drill1.0mm
U1: THVD1450; SOIC-8_3.9x4.9mm_P1.27mm; MPN THVD1450DR; LCSC C2671361
U2: Teensy 4.0; Teensy40_Socketed; MPN 15583; DigiKey 1568-15583-ND
U3: SN74AHCT1G125; SOT-23-5; MPN SN74AHCT1G125DBVR; LCSC C7484

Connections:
+3.3VDC: C1.1, R1.1, RN1.1 (common), TP6.1 (1_1), U1.8 (VCC), U2.31 (VDD)
+5VDC_USB: C2.1, TP4.1 (1_1), U2.33 (VIN), U3.5 (VCC)
/DIP_ID0: SW1.1, U2.7 (GPIO_5)
/DIP_ID1: SW1.2, U2.6 (GPIO_4)
/DIP_ID2: SW1.3, U2.5 (GPIO_3)
/RS485+: J1.1, R1.2, R3.1, TP7.1 (1_1), U1.6 (A)
/RS485-: J1.2, R2.1, R3.2, TP8.1 (1_1), U1.7 (B)
GND: C1.2, C2.2, C3.2, C4.2, C5.2, C6.2, C7.2, C8.2, C9.2, C10.2, C11.2, D1.2 (A), D2.2 (A), D3.2 (A), D4.2 (A), D5.2 (A), D6.2 (A), D7.2 (A), D8.2 (A), D9.2 (A), J1.3, J2.2, J3.2, J4.2, J5.2, J6.2, J7.2, J8.2, J9.2, J10.2, J11.2, R2.2, R4.2, SW1.4, SW1.5, SW1.6, TP5.1 (1_1), U1.5 (GND), U2.1 (GND), U2.32 (GND), U3.1, U3.3 (GND)
INT_C: C7.1, R10.2, RN1.6 (R5), U2.26 (GPIO_19)
INT_D: C10.1, R13.2, RN1.9 (R8), U2.23 (GPIO_16)
INT_DL: C9.1, R12.2, RN1.8 (R7), U2.24 (GPIO_17)
INT_DR: C11.1, R14.2, RN1.10 (R9), U2.22 (GPIO_15)
INT_L: C6.1, R9.2, RN1.5 (R4), U2.27 (GPIO_20)
INT_R: C8.1, R11.2, RN1.7 (R6), U2.25 (GPIO_18)
INT_U: C4.1, R7.2, RN1.3 (R2), U2.29 (GPIO_22)
INT_UL: C3.1, R6.2, RN1.2 (R1), U2.30 (GPIO_23)
INT_UR: C5.1, R8.2, RN1.4 (R3), U2.28 (GPIO_21)
unnamed: D1.1 (K), J11.1, R6.1
unnamed: D2.1 (K), J10.1, R7.1
unnamed: D3.1 (K), J9.1, R8.1
unnamed: D4.1 (K), J8.1, R9.1
unnamed: D5.1 (K), J7.1, R10.1
unnamed: D6.1 (K), J6.1, R11.1
unnamed: D7.1 (K), J5.1, R12.1
unnamed: D8.1 (K), J4.1, R13.1
unnamed: D9.1 (K), J3.1, R14.1
unnamed: J2.1, R5.2
unnamed: R5.1, TP10.1 (1_1), U3.4
RS485_DE: TP2.1 (1_1), U1.2 (~RE), U1.3 (DE), U2.8 (GPIO_6)
RS485_RX: TP1.1 (1_1), U1.1 (RO), U2.9 (GPIO_7)
RS485_TX: TP3.1 (1_1), U1.4 (DI), U2.10 (GPIO_8)
UNDERGLOW_DATA: R4.1, TP9.1 (1_1), U2.13 (GPIO_11), U3.2

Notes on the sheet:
Panel Interrupt Signals
RS-485 bias (R4/R5): fitted as DNP footprints, insurance only. THVD1450 has integrated open/short/idle failsafe, so the idle bus is already defined and no external bias is normally needed. Bias belongs at ONE point on the bus - the master is that point, so if the bench ever disagrees, populate here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
Overall Ground connection is added here to J4, as 2P terminal blocks are easy to find and source. We needed a way to connect the ground to the rest of the system anyway.
Mounting
*Shield
Underglow LED Logic Shifter & Ground Hookup
Microcontroller
RS-485 Receive & Transmit

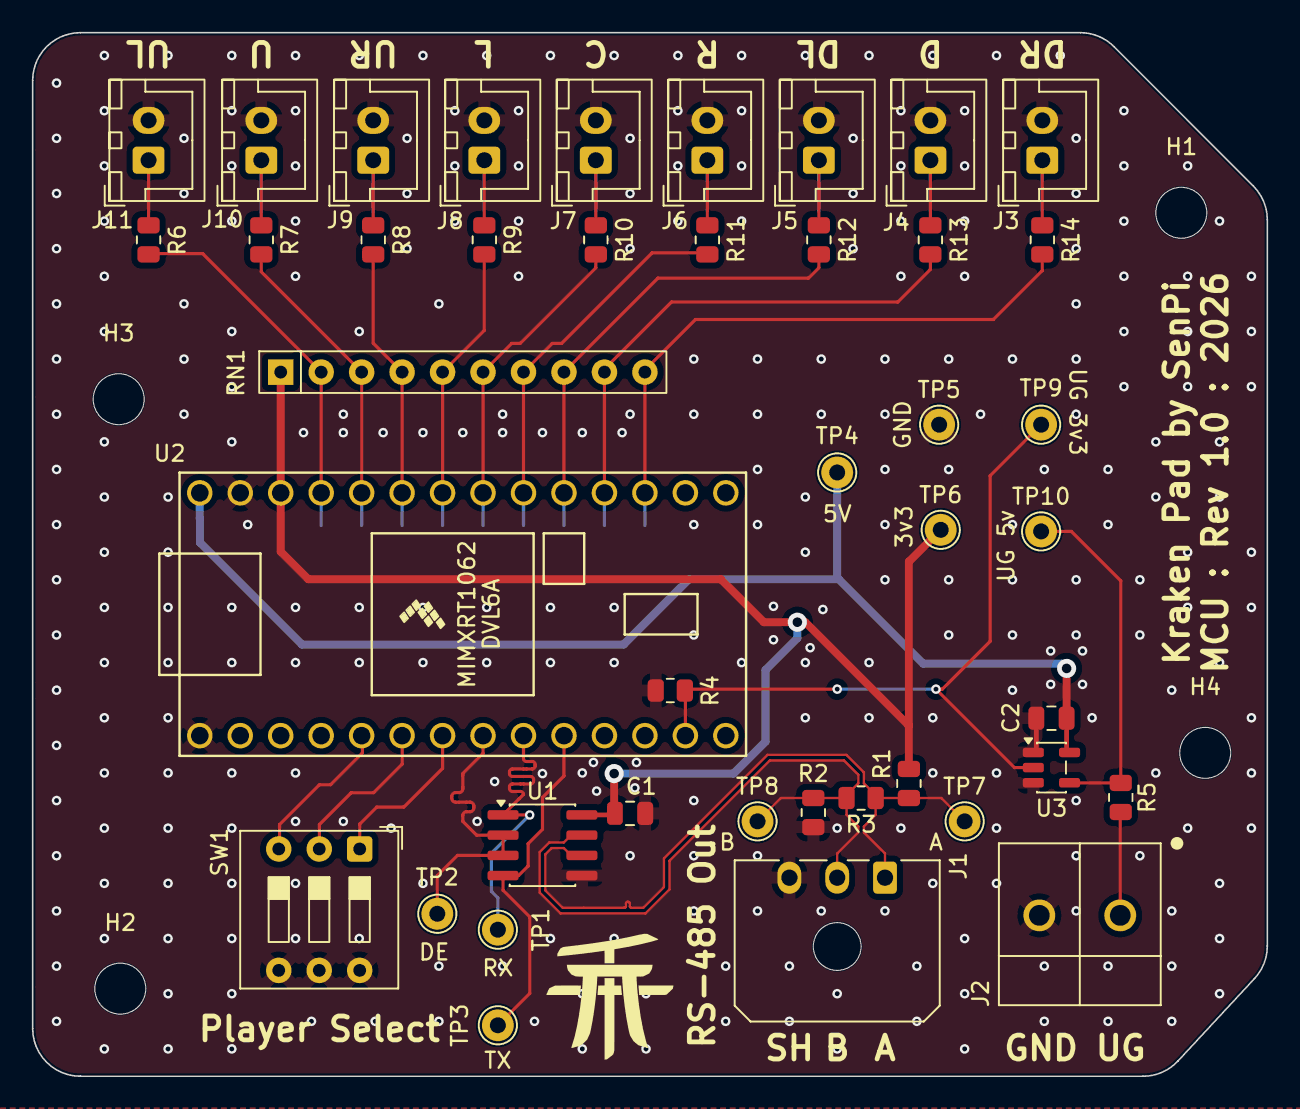
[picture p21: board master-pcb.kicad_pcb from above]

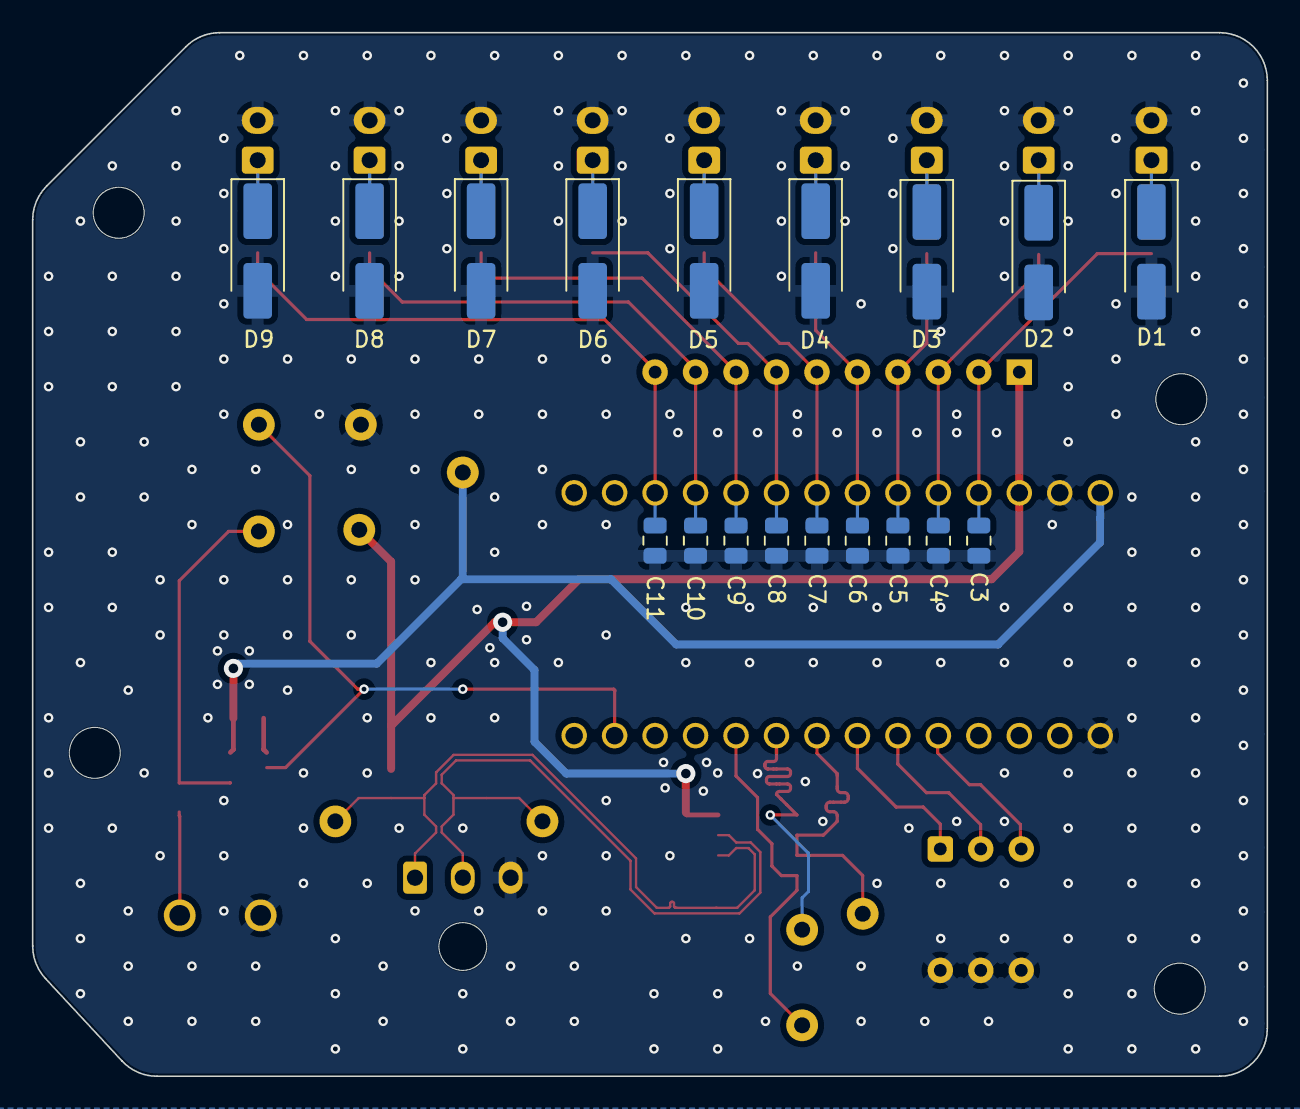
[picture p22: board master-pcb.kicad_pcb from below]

Board: 4 copper layers, 77.5 x 65.5 mm, 64 parts (18 on the bottom side), 32 nets.

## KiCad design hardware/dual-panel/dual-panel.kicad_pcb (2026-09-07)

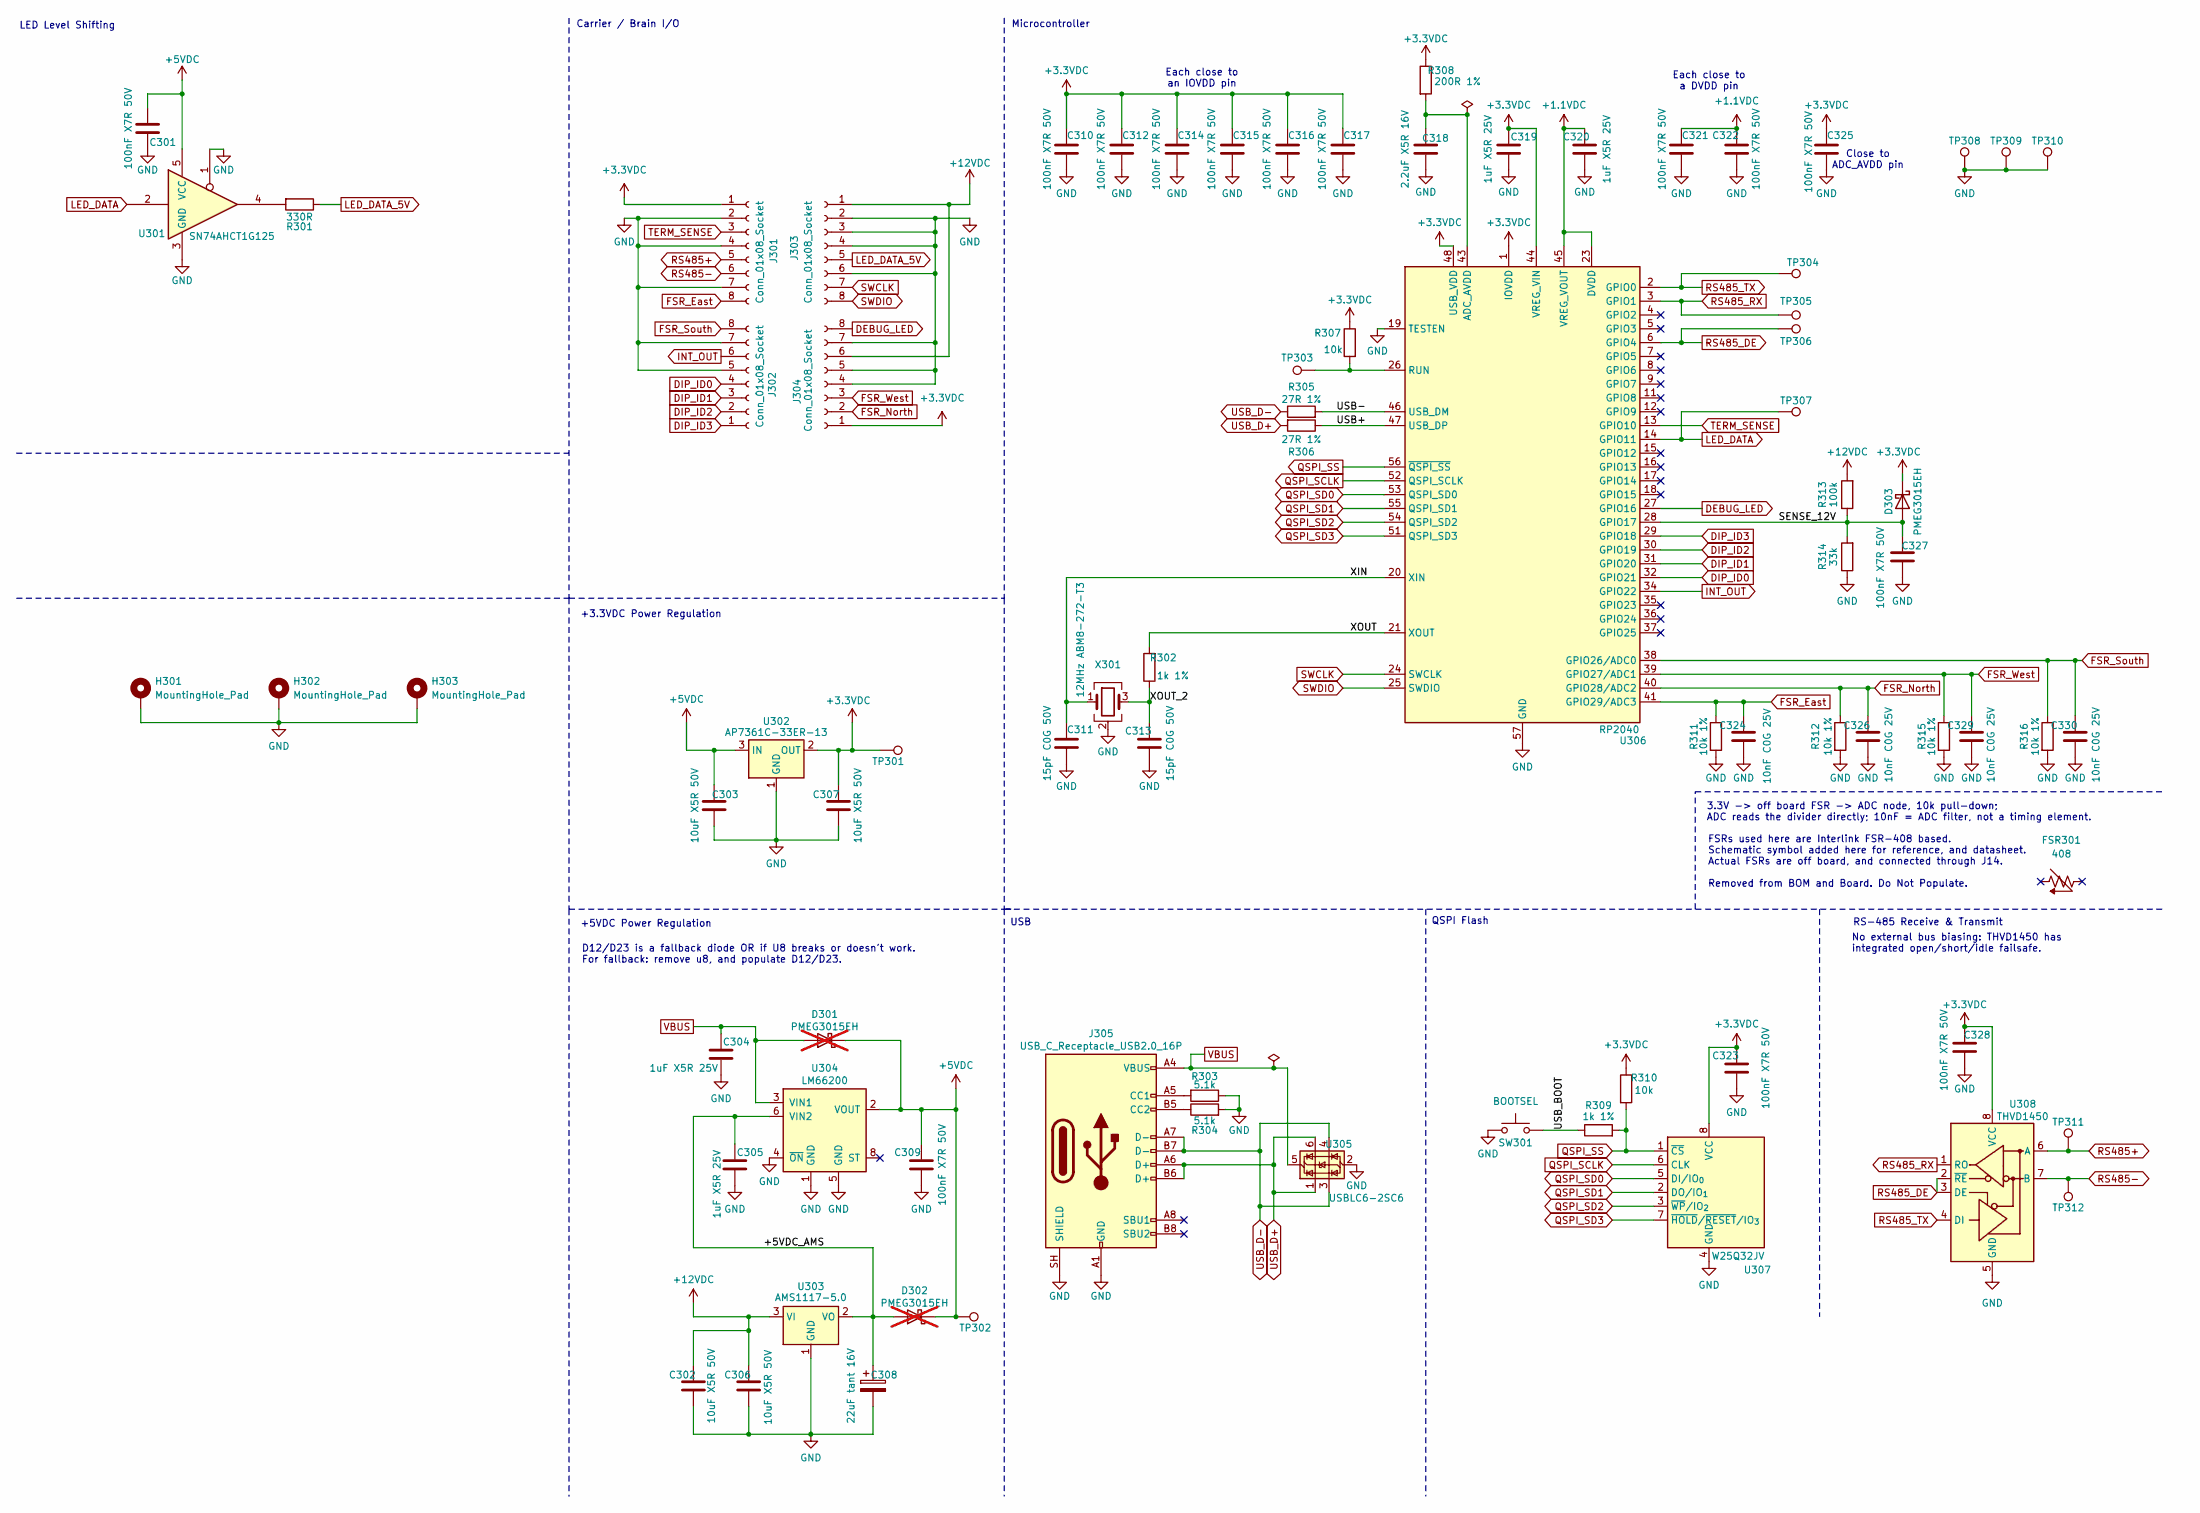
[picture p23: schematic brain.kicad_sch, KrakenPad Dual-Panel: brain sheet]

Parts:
C301, C323, C327, C328: 100nF X7R 50V; C_0603_1608Metric; LCSC C14663
C302, C303, C306, C307: 10uF X5R 50V; C_0805_2012Metric; LCSC C440198
C304, C305, C319, C320: 1uF X5R 25V; C_0402_1005Metric_SilkTrim; LCSC C52923
C308: 22uF tant 16V; CP_EIA-3528-21_Kemet-B; MPN TAJB226K016RNJ; LCSC C8020
C309, C310, C312, C314, C315, C316, C317, C321, C322, C325: 100nF X7R 50V; C_0402_1005Metric_SilkTrim; LCSC C307331
C311, C313: 15pF C0G 50V; C_0603_1608Metric; LCSC C1644
C318: 2.2uF X5R 16V; C_0402_1005Metric_SilkTrim; LCSC C170151
C324, C326, C329, C330: 10nF C0G 25V; C_0603_1608Metric; LCSC C723749
D301, D302: PMEG3015EH; D_SOD-123F; MPN PMEG3015EH,115; LCSC C552867; not fitted
D303: PMEG3015EH; D_SOD-123F; MPN PMEG3015EH,115; LCSC C552867
FSR301: 408
H301, H302, H303: MountingHole_Pad; MountingHole_3.2mm_M3_Pad
J301, J302, J303, J304: Conn_01x08_Socket; PinSocket_1x08_P2.54mm_Vertical
J305: USB_C_Receptacle_USB2.0_16P; USB_C_Receptacle_GCT_USB4085_EdgeTrim; MPN USB4085-GF-A; LCSC C7095263
R301: 330R; R_0603_1608Metric; LCSC C23138
R302, R309: 1k 1%; R_0603_1608Metric; LCSC C2907002
R303, R304: 5.1k; R_0603_1608Metric; LCSC C23186
R305, R306: 27R 1%; R_0603_1608Metric; LCSC C25190
R307, R310: 10k; R_0603_1608Metric; LCSC C2906982
R308: 200R 1%; R_0603_1608Metric; LCSC C8218
R311, R312, R315, R316: 10k 1%; R_0603_1608Metric; LCSC C98220
R313: 100k; R_0603_1608Metric; LCSC C25803
R314: 33k; R_0603_1608Metric; LCSC C4216
SW301: BOOTSEL; SW_SPST_B3U-1000P; MPN B3U-1000P; LCSC C231329
TP301: +3.3VDC; TestPoint_THTPad_D2.0mm_Drill1.0mm
TP302: +5VDC; TestPoint_THTPad_D2.0mm_Drill1.0mm
TP303: RUN; TestPoint_THTPad_D2.0mm_Drill1.0mm
TP304: UART TX; TestPoint_THTPad_D2.0mm_Drill1.0mm
TP305: UART RX; TestPoint_THTPad_D2.0mm_Drill1.0mm
TP306: RS-485 DE; TestPoint_THTPad_D2.0mm_Drill1.0mm
TP307: LED Data 3.3V; TestPoint_THTPad_D2.0mm_Drill1.0mm
TP308, TP309, TP310: GND; TestPoint_THTPad_D2.0mm_Drill1.0mm
TP311: RS485+; TestPoint_THTPad_D2.0mm_Drill1.0mm
TP312: RS485-; TestPoint_THTPad_D2.0mm_Drill1.0mm
U301: SN74AHCT1G125; SOT-23-5; MPN SN74AHCT1G125DBVR; LCSC C7484
U302: AP7361C-33ER-13; SOT-223-3_TabPin2; MPN AP7361C-33ER-13; LCSC C3743528
U303: AMS1117-5.0; SOT-223-3_TabPin2; MPN AMS1117-5.0; LCSC C6187
U304: LM66200; SOT-583-8; MPN LM66200DRLR; LCSC C3235556
U305: USBLC6-2SC6; SOT-23-6; MPN USBLC6-2SC6; LCSC C2827654
U306: RP2040; QFN-56-1EP_7x7mm_P0.4mm_EP3.2x3.2mm_RPiPad; MPN RP2040; LCSC C2040
U307: W25Q32JV; SOIC-8_5.3x5.3mm_P1.27mm; MPN W25Q32JVSSIQ; LCSC C179173
U308: THVD1450; SOIC-8_3.9x4.9mm_P1.27mm; MPN THVD1450DR; LCSC C2671361
X301: 12MHz ABM8-272-T3; Crystal_SMD_3225-4Pin_3.2x2.5mm; MPN ABM8-272-T3; LCSC C20625731

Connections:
+1.1VDC: C320.1, C321.1, C322.1, U306.23 (DVDD), U306.45 (VREG_VOUT), U306.50 (DVDD)
+3.3VDC: C307.1, C310.1, C312.1, C314.1, C315.1, C316.1, C317.1, C319.2, C323.1, C325.1, C328.1, D303.1 (K), J301.1, J304.1, R307.1, R308.1, R310.1, TP301.1 (1_1), U302.2 (OUT), U306.1 (IOVDD), U306.10 (IOVDD), U306.22 (IOVDD), U306.33 (IOVDD), U306.42 (IOVDD), U306.44 (VREG_VIN), U306.48 (USB_VDD), U306.49 (IOVDD), U307.8 (VCC), U308.8 (VCC); also elsewhere on the board
+5VDC: C301.1, C303.1, C309.1, D301.1 (K), D302.1 (K), TP302.1 (1_1), U301.5 (VCC), U302.3 (IN), U304.2 (VOUT), U304.7 (VOUT)
+12VDC: C302.1, C306.1, J303.1, J304.6, R313.2, U303.3 (VI); also elsewhere on the board
/brain/+5VDC_AMS: C305.2, C308.1, D302.2 (A), U303.2 (VO), U304.6 (VIN2)
/brain/SENSE_12V: C327.2, D303.2 (A), R313.1, R314.2, U306.28 (GPIO17)
/brain/USB+: R306.1, U306.47 (USB_DP)
/brain/USB-: R305.2, U306.46 (USB_DM)
/brain/USB_BOOT: R309.1, SW301.1
/brain/XIN: C311.1, U306.20 (XIN), X301.1
/brain/XOUT: R302.2, U306.21 (XOUT)
/brain/XOUT_2: C313.1, R302.1, X301.3
DEBUG_LED: J304.8, U306.27 (GPIO16); also elsewhere on the board
DIP_ID0: J302.4, U306.32 (GPIO21); also elsewhere on the board
DIP_ID1: J302.3, U306.31 (GPIO20); also elsewhere on the board
DIP_ID2: J302.2, U306.30 (GPIO19); also elsewhere on the board
DIP_ID3: J302.1, U306.29 (GPIO18); also elsewhere on the board
FSR_East: C324.1, J301.8, R311.1, U306.41 (GPIO29/ADC3); also elsewhere on the board
FSR_North: C326.1, J304.2, R312.1, U306.40 (GPIO28/ADC2); also elsewhere on the board
FSR_South: C330.1, J302.8, R316.1, U306.38 (GPIO26/ADC0); also elsewhere on the board
FSR_West: C329.1, J304.3, R315.1, U306.39 (GPIO27/ADC1); also elsewhere on the board
GND: C301.2, C302.2, C303.2, C304.1, C305.1, C306.2, C307.2, C308.2, C309.2, C310.2, C311.2, C312.2, C313.2, C314.2, C315.2, C316.2, C317.2, C318.1, C319.1, C320.2, C321.2, C322.2, C323.2, C324.2, C325.2, C326.2, C327.1, C328.2, C329.2, C330.2, H301.1 (1_1), H302.1 (1_1), H303.1 (1_1), J301.2, J301.4, J301.7, J302.5, J302.7, J303.2, J303.3, J303.4, J303.6, J304.4, J304.5, J304.7, J305.A1 (GND), J305.A12 (GND), J305.B1 (GND), J305.B12 (GND), J305.SH (SHIELD), R303.1, R304.2, R311.2, R312.2, R314.1, R315.2, R316.2, SW301.2, TP308.1 (1_1), TP309.1 (1_1), TP310.1 (1_1), U301.1, U301.3 (GND), U302.1 (GND), U303.1 (GND), U304.1 (GND), U304.4 (~ON), U304.5 (GND), U305.2 (GND), U306.19 (TESTEN), U306.57 (GND), U307.4 (GND), U308.5 (GND), X301.2 (G), X301.4 (G); also elsewhere on the board
INT_OUT: J302.6, U306.34 (GPIO22); also elsewhere on the board
LED_DATA: TP307.1 (1_1), U301.2, U306.14 (GPIO11)
LED_DATA_5V: J303.5, R301.1; also elsewhere on the board
unnamed: J305.A5 (CC1), R303.2
unnamed: J305.B5 (CC2), R304.1
unnamed: R301.2, U301.4
unnamed: C318.2, R308.2, U306.43 (ADC_AVDD)
unnamed: R307.2, TP303.1 (1_1), U306.26 (RUN)
QSPI_SCLK: U306.52 (QSPI_SCLK), U307.6 (CLK)
QSPI_SD0: U306.53 (QSPI_SD0), U307.5 (DI/IO_{0})
QSPI_SD1: U306.55 (QSPI_SD1), U307.2 (DO/IO_{1})
QSPI_SD2: U306.54 (QSPI_SD2), U307.3 (~WP/IO_{2})
QSPI_SD3: U306.51 (QSPI_SD3), U307.7 (~HOLD/~RESET/IO_{3})
QSPI_SS: R309.2, R310.2, U306.56 (~QSPI_SS), U307.1 (~CS)
RS485+: J301.5, TP311.1 (1_1), U308.6 (A); also elsewhere on the board
RS485-: J301.6, TP312.1 (1_1), U308.7 (B); also elsewhere on the board
RS485_DE: TP306.1 (1_1), U306.6 (GPIO4), U308.2 (~RE), U308.3 (DE)
RS485_RX: TP305.1 (1_1), U306.3 (GPIO1), U308.1 (RO)
RS485_TX: TP304.1 (1_1), U306.2 (GPIO0), U308.4 (DI)
SWCLK: J303.7, U306.24 (SWCLK); also elsewhere on the board
SWDIO: J303.8, U306.25 (SWDIO); also elsewhere on the board
TERM_SENSE: J301.3, U306.13 (GPIO10); also elsewhere on the board
USB_D+: J305.A6 (D+), J305.B6 (D+), R306.2, U305.1 (I/O1), U305.6 (I/O1)
USB_D-: J305.A7 (D-), J305.B7 (D-), R305.1, U305.3 (I/O2), U305.4 (I/O2)
VBUS: C304.2, D301.2 (A), J305.A4 (VBUS), J305.A9 (VBUS), J305.B4 (VBUS), J305.B9 (VBUS), U304.3 (VIN1), U305.5 (VBUS)

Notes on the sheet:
+5VDC Power Regulation
QSPI Flash
Microcontroller
+3.3VDC Power Regulation
No external bus biasing: THVD1450 has integrated open/short/idle failsafe.
Carrier / Brain I/O
D12/D23 is a fallback diode OR if U8 breaks or doesn't work. For fallback: remove u8, and populate D12/D23.
RS-485 Receive & Transmit
USB
FSRs used here are Interlink FSR-408 based. Schematic symbol added here for reference, and datasheet. Actual FSRs are off board, and connected through J14. Removed from BOM and Board. Do Not Populate.
3.3V -> off board FSR -> ADC node, 10k pull-down; ADC reads the divider directly; 10nF = ADC filter, not a timing element.
LED Level Shifting
Each close to an IOVDD pin
Each close to a DVDD pin
Close to ADC_AVDD pin

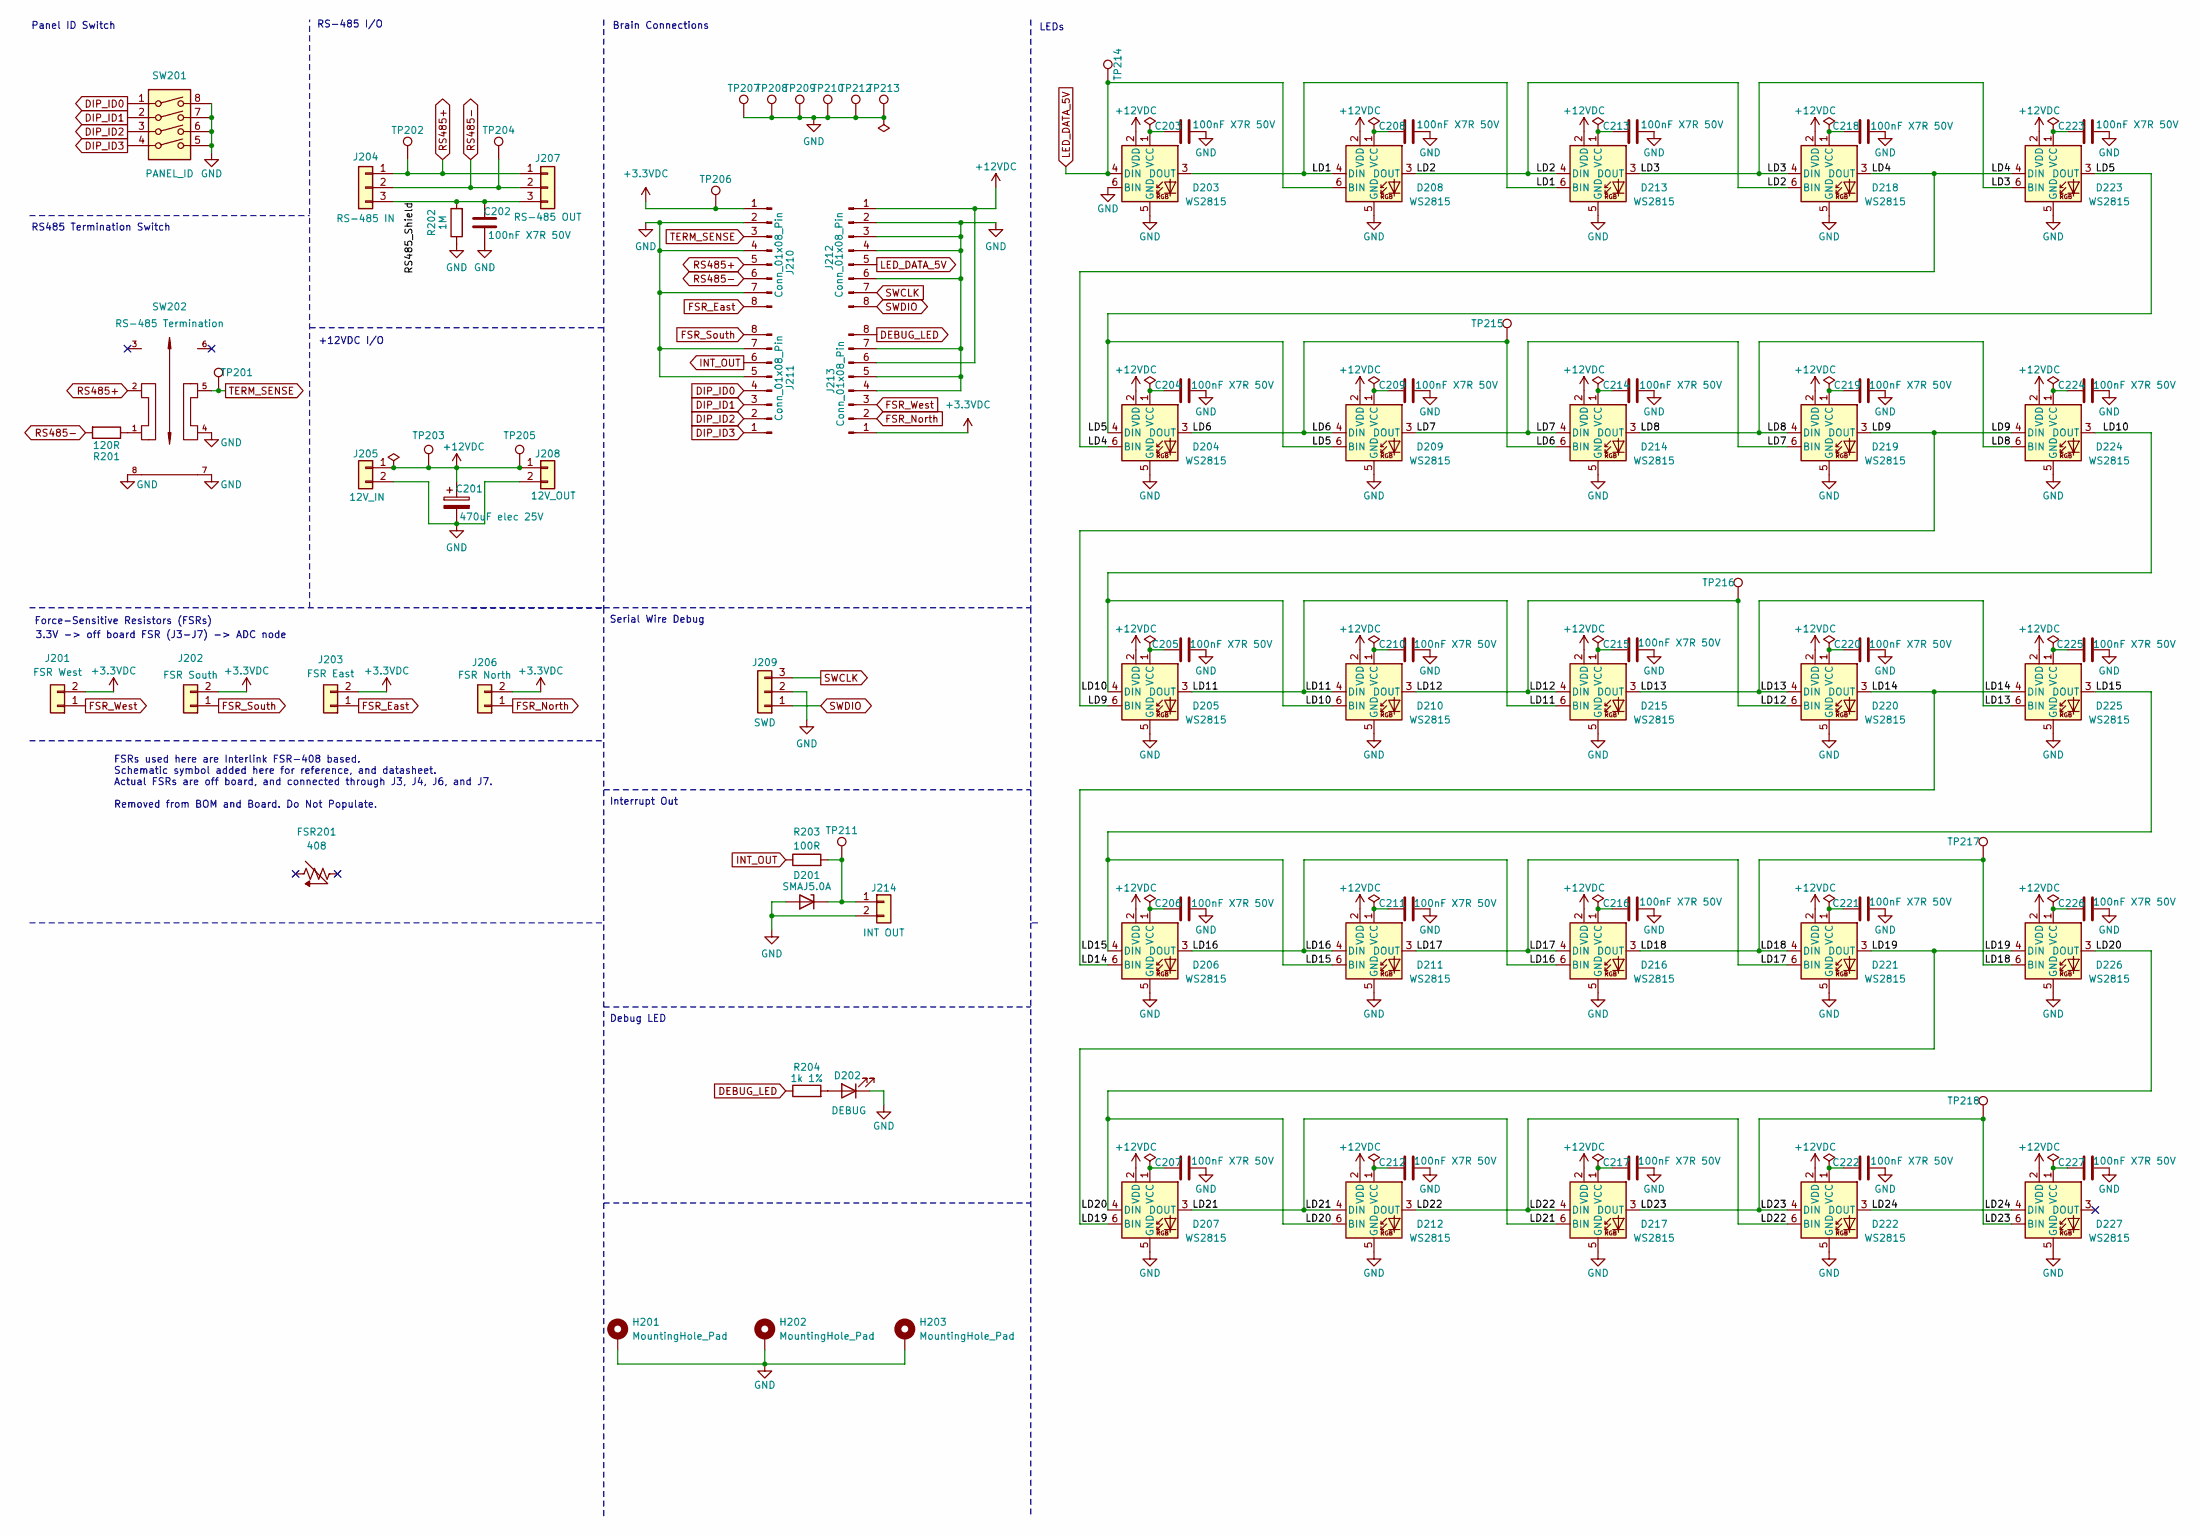
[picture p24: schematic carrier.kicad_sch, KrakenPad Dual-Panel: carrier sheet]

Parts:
C201: 470uF elec 25V; CP_Elec_10x10.5_RVT1E471M; MPN RVT1E471M1010; LCSC C82014
C202, C203, C204, C205, C206, C207, C208, C209, C210, C211, C212, C213, C214, C215, C216, C217, C218, C219, C220, C221, C222, C223, C224, C225, C226, C227: 100nF X7R 50V; C_0603_1608Metric; LCSC C14663
D201: SMAJ5.0A; D_SMA; MPN SMAJ5.0A; LCSC C113952
D202: DEBUG; LED_0603_1608Metric; MPN DYWH-19-21SUGC/4T; LCSC C47416536
D203, D204, D205, D206, D207, D208, D209, D210, D211, D212, D213, D214, D215, D216, D217, D218, D219, D220, D221, D222, D223, D224, D225, D226, D227: WS2815; WS2815_PLCC6_5.0x5.0mm_P1.6mm; MPN WS2815B-V1; LCSC C5446699
FSR201: 408
H201, H202, H203: MountingHole_Pad; MountingHole_3.2mm_M3_Pad
J201: FSR West; JST_PH_B2B-PH-K_1x02_P2.00mm_Vertical; MPN B2B-PH-K-S(LF)(SN); LCSC C131337
J202: FSR South; JST_PH_B2B-PH-K_1x02_P2.00mm_Vertical; MPN B2B-PH-K-S(LF)(SN); LCSC C131337
J203: FSR East; JST_PH_B2B-PH-K_1x02_P2.00mm_Vertical; MPN B2B-PH-K-S(LF)(SN); LCSC C131337
J204: RS-485 IN; Molex_Micro-Fit_3.0_43650-0300_1x03_P3.00mm_Horizontal; MPN 43650-0300; LCSC C503478
J205: 12V_IN; Molex_Micro-Fit_3.0_43650-0200_1x02_P3.00mm_Horizontal; MPN 43650-0200; LCSC C192562
J206: FSR North; JST_PH_B2B-PH-K_1x02_P2.00mm_Vertical; MPN B2B-PH-K-S(LF)(SN); LCSC C131337
J207: RS-485 OUT; Molex_Micro-Fit_3.0_43650-0300_1x03_P3.00mm_Horizontal; MPN 43650-0300; LCSC C503478
J208: 12V_OUT; Molex_Micro-Fit_3.0_43650-0200_1x02_P3.00mm_Horizontal; MPN 43650-0200; LCSC C192562
J209: SWD; PinHeader_1x03_P2.54mm_Vertical; MPN PZ254V-11-03P; LCSC C2937625
J210, J211, J212, J213: Conn_01x08_Pin; PinHeader_1x08_P2.54mm_Vertical
J214: INT OUT; TerminalBlock_WJ500V-5.08-2P; MPN WJ500V-5.08-2P; LCSC C8465
R201: 120R; R_0603_1608Metric; LCSC C22787
R202: 1M; R_0603_1608Metric; LCSC C22935
R203: 100R; R_0603_1608Metric; LCSC C22775
R204: 1k 1%; R_0603_1608Metric; LCSC C2907002
SW201: PANEL_ID; SW_DIP_SPSTx04_Slide_9.78x12.34mm_W7.62mm_P2.54mm; MPN DS-04; LCSC C52177925
SW202: RS-485 Termination; SW_SS22E01L5; MPN SS22E01L5; LCSC C609835
TP201, TP203, TP205: +12VDC; TestPoint_THTPad_D2.0mm_Drill1.0mm
TP202, TP204, TP206, TP207, TP208, TP209, TP210, TP211, TP212, TP213, TP215, TP216, TP217, TP218: GND; TestPoint_THTPad_D2.0mm_Drill1.0mm
TP214: LED Data 5.0V; TestPoint_THTPad_D2.0mm_Drill1.0mm

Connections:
+3.3VDC: J201.2, J202.2, J203.2, J206.2, J210.1, J213.1, TP206.1 (1_1); also elsewhere on the board
+12VDC: C201.1, D203.2 (VDD), D204.2 (VDD), D205.2 (VDD), D206.2 (VDD), D207.2 (VDD), D208.2 (VDD), D209.2 (VDD), D210.2 (VDD), D211.2 (VDD), D212.2 (VDD), D213.2 (VDD), D214.2 (VDD), D215.2 (VDD), D216.2 (VDD), D217.2 (VDD), D218.2 (VDD), D219.2 (VDD), D220.2 (VDD), D221.2 (VDD), D222.2 (VDD), D223.2 (VDD), D224.2 (VDD), D225.2 (VDD), D226.2 (VDD), D227.2 (VDD), J205.1, J208.1, J212.1, J213.6, TP203.1 (1_1), TP205.1 (1_1); also elsewhere on the board
/carrier/LD1: D203.3 (DOUT), D208.4 (DIN), D213.6 (BIN)
/carrier/LD2: D208.3 (DOUT), D213.4 (DIN), D218.6 (BIN)
/carrier/LD3: D213.3 (DOUT), D218.4 (DIN), D223.6 (BIN)
/carrier/LD4: D204.6 (BIN), D218.3 (DOUT), D223.4 (DIN)
/carrier/LD5: D204.4 (DIN), D209.6 (BIN), D223.3 (DOUT)
/carrier/LD6: D204.3 (DOUT), D209.4 (DIN), D214.6 (BIN), TP215.1 (1_1)
/carrier/LD7: D209.3 (DOUT), D214.4 (DIN), D219.6 (BIN)
/carrier/LD8: D214.3 (DOUT), D219.4 (DIN), D224.6 (BIN)
/carrier/LD9: D205.6 (BIN), D219.3 (DOUT), D224.4 (DIN)
/carrier/LD10: D205.4 (DIN), D210.6 (BIN), D224.3 (DOUT)
/carrier/LD11: D205.3 (DOUT), D210.4 (DIN), D215.6 (BIN)
/carrier/LD12: D210.3 (DOUT), D215.4 (DIN), D220.6 (BIN), TP216.1 (1_1)
/carrier/LD13: D215.3 (DOUT), D220.4 (DIN), D225.6 (BIN)
/carrier/LD14: D206.6 (BIN), D220.3 (DOUT), D225.4 (DIN)
/carrier/LD15: D206.4 (DIN), D211.6 (BIN), D225.3 (DOUT)
/carrier/LD16: D206.3 (DOUT), D211.4 (DIN), D216.6 (BIN)
/carrier/LD17: D211.3 (DOUT), D216.4 (DIN), D221.6 (BIN)
/carrier/LD18: D216.3 (DOUT), D221.4 (DIN), D226.6 (BIN), TP217.1 (1_1)
/carrier/LD19: D207.6 (BIN), D221.3 (DOUT), D226.4 (DIN)
/carrier/LD20: D207.4 (DIN), D212.6 (BIN), D226.3 (DOUT)
/carrier/LD21: D207.3 (DOUT), D212.4 (DIN), D217.6 (BIN)
/carrier/LD22: D212.3 (DOUT), D217.4 (DIN), D222.6 (BIN)
/carrier/LD23: D217.3 (DOUT), D222.4 (DIN), D227.6 (BIN), TP218.1 (1_1)
/carrier/LD24: D222.3 (DOUT), D227.4 (DIN)
/carrier/RS485_Shield: C202.2, J204.3, J207.3, R202.2
DEBUG_LED: J213.8, R204.1; also elsewhere on the board
DIP_ID0: J211.4, SW201.1; also elsewhere on the board
DIP_ID1: J211.3, SW201.2; also elsewhere on the board
DIP_ID2: J211.2, SW201.3; also elsewhere on the board
DIP_ID3: J211.1, SW201.4; also elsewhere on the board
FSR_East: J203.1, J210.8; also elsewhere on the board
FSR_North: J206.1, J213.2; also elsewhere on the board
FSR_South: J202.1, J211.8; also elsewhere on the board
FSR_West: J201.1, J213.3; also elsewhere on the board
GND: C201.2, C202.1, C203.2, C204.2, C205.2, C206.2, C207.2, C208.2, C209.2, C210.2, C211.2, C212.2, C213.2, C214.2, C215.2, C216.2, C217.2, C218.2, C219.2, C220.2, C221.2, C222.2, C223.2, C224.2, C225.2, C226.2, C227.2, D201.2 (A), D202.1 (K), D203.5 (GND), D203.6 (BIN), D204.5 (GND), D205.5 (GND), D206.5 (GND), D207.5 (GND), D208.5 (GND), D209.5 (GND), D210.5 (GND), D211.5 (GND), D212.5 (GND), D213.5 (GND), D214.5 (GND), D215.5 (GND), D216.5 (GND), D217.5 (GND), D218.5 (GND), D219.5 (GND), D220.5 (GND), D221.5 (GND), D222.5 (GND), D223.5 (GND), D224.5 (GND), D225.5 (GND), D226.5 (GND), D227.5 (GND), H201.1 (1_1), H202.1 (1_1), H203.1 (1_1), J205.2, J208.2, J209.2, J210.2, J210.4, J210.7, J211.5, J211.7, J212.2, J212.3, J212.4, J212.6, J213.4, J213.5, J213.7, J214.2, R202.1, SW201.5, SW201.6, SW201.7, SW201.8, SW202.4, SW202.7, SW202.8, TP207.1 (1_1), TP208.1 (1_1), TP209.1 (1_1), TP210.1 (1_1), TP212.1 (1_1), TP213.1 (1_1); also elsewhere on the board
INT_OUT: J211.6, R203.1; also elsewhere on the board
LED_DATA_5V: D203.4 (DIN), D208.6 (BIN), J212.5, TP214.1 (1_1); also elsewhere on the board
unnamed: D201.1 (K), J214.1, R203.2, TP211.1 (1_1)
unnamed: D202.2 (A), R204.2
unnamed: C203.1, D203.1 (VCC)
unnamed: C204.1, D204.1 (VCC)
unnamed: C205.1, D205.1 (VCC)
unnamed: C206.1, D206.1 (VCC)
unnamed: C207.1, D207.1 (VCC)
unnamed: C208.1, D208.1 (VCC)
unnamed: C209.1, D209.1 (VCC)
unnamed: C210.1, D210.1 (VCC)
unnamed: C211.1, D211.1 (VCC)
unnamed: C212.1, D212.1 (VCC)
unnamed: C213.1, D213.1 (VCC)
unnamed: C214.1, D214.1 (VCC)
unnamed: C215.1, D215.1 (VCC)
unnamed: C216.1, D216.1 (VCC)
unnamed: C217.1, D217.1 (VCC)
unnamed: C218.1, D218.1 (VCC)
unnamed: C219.1, D219.1 (VCC)
unnamed: C220.1, D220.1 (VCC)
unnamed: C221.1, D221.1 (VCC)
unnamed: C222.1, D222.1 (VCC)
unnamed: C223.1, D223.1 (VCC)
unnamed: C224.1, D224.1 (VCC)
unnamed: C225.1, D225.1 (VCC)
unnamed: C226.1, D226.1 (VCC)
unnamed: C227.1, D227.1 (VCC)
unnamed: R201.1, SW202.1
RS485+: J204.1, J207.1, J210.5, SW202.2, TP202.1 (1_1); also elsewhere on the board
RS485-: J204.2, J207.2, J210.6, R201.2, TP204.1 (1_1); also elsewhere on the board
SWCLK: J209.3, J212.7; also elsewhere on the board
SWDIO: J209.1, J212.8; also elsewhere on the board
TERM_SENSE: J210.3, SW202.5, TP201.1 (1_1); also elsewhere on the board

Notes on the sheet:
+12VDC I/O
Panel ID Switch
RS485 Termination Switch
Debug LED
Brain Connections
3.3V -> off board FSR (J3-J7) -> ADC node
LEDs
RS-485 I/O
Force-Sensitive Resistors (FSRs)
Interrupt Out
FSRs used here are Interlink FSR-408 based. Schematic symbol added here for reference, and datasheet. Actual FSRs are off board, and connected through J3, J4, J6, and J7. Removed from BOM and Board. Do Not Populate.
Serial Wire Debug

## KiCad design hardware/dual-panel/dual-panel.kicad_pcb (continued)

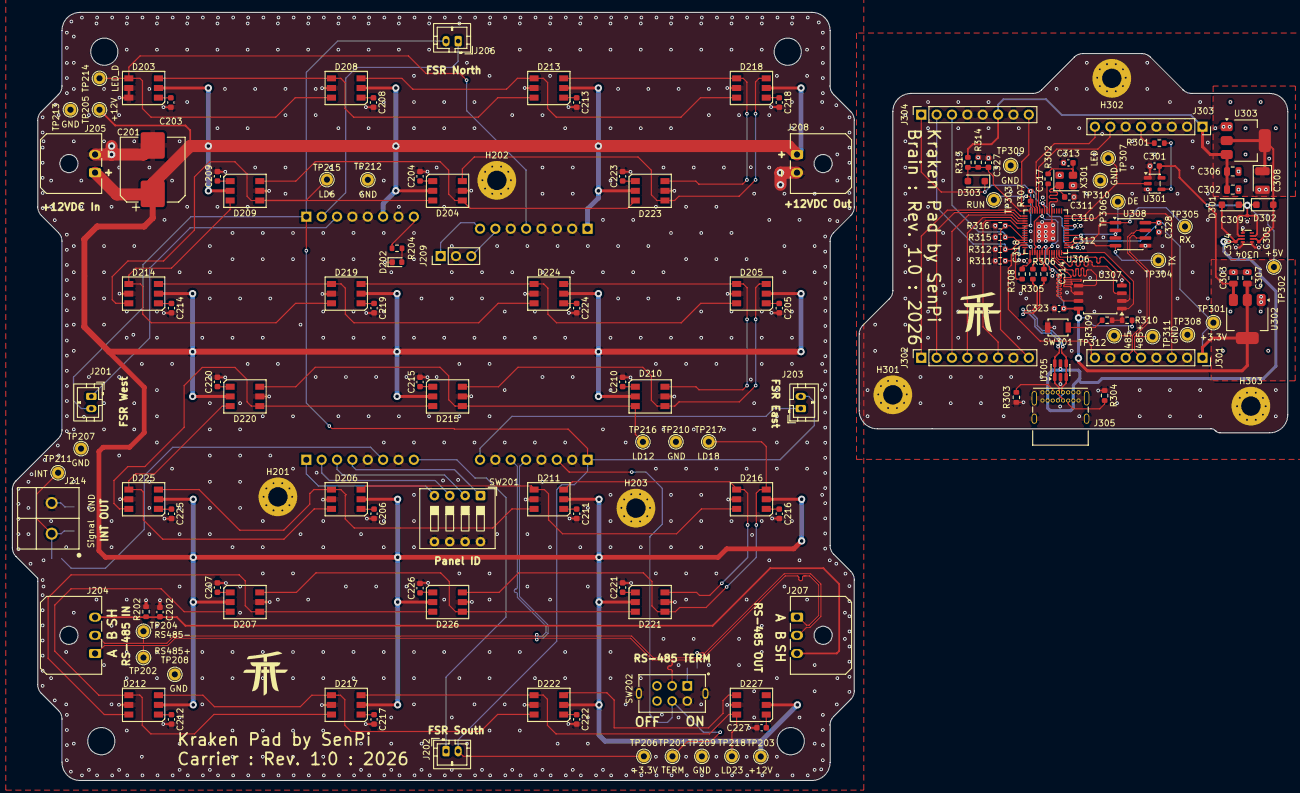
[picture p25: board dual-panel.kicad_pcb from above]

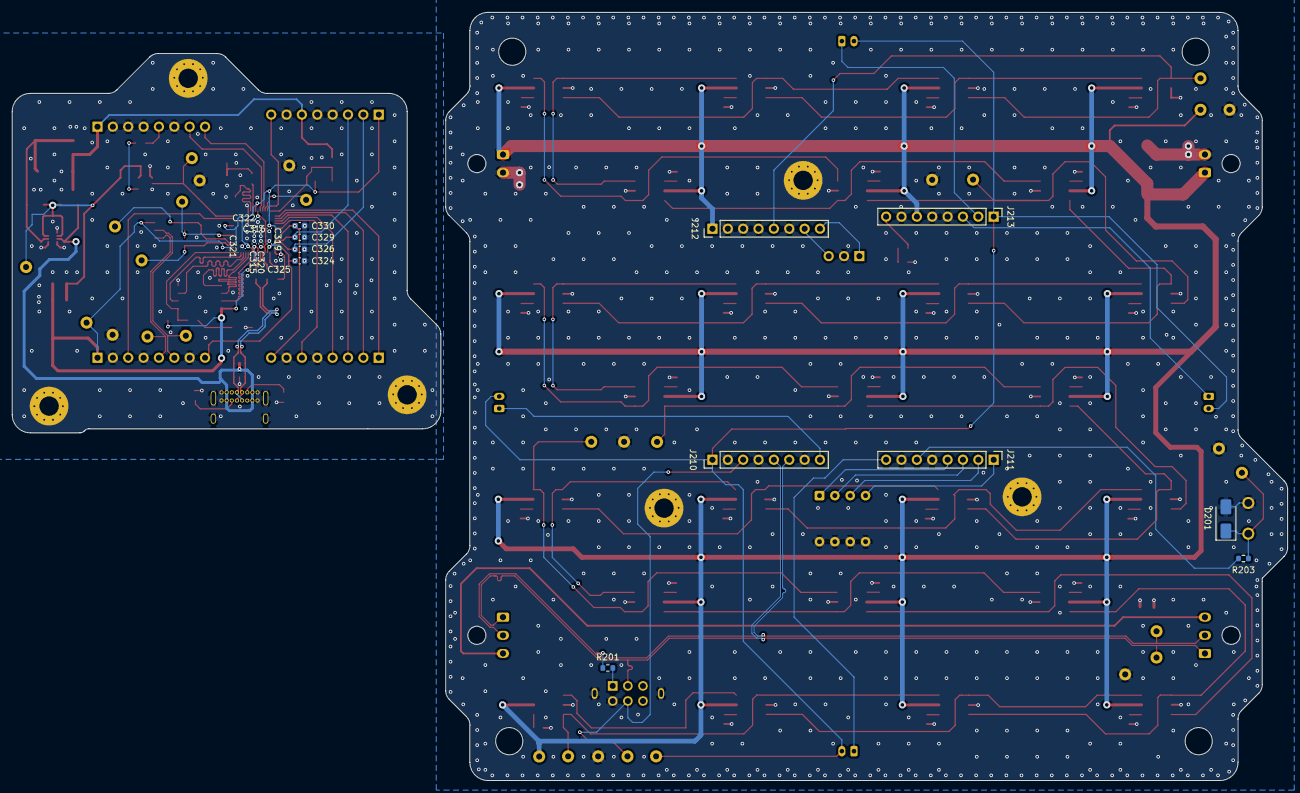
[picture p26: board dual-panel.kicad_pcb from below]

Board: 4 copper layers, 210.9 x 127.0 mm, 174 parts (18 on the bottom side), 100 nets.

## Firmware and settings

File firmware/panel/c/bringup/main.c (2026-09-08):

// Panel bring-up firmware — dual-panel rev 1 (carrier 2xx + brain 3xx).
//
// This is NOT the gameplay firmware. It exists to prove a freshly assembled
// board works, in the order the hardware allows things to be proven:
//
//   Stage 1  brain alone, USB power    — flash, rails, sense-low, pull config
//   Stage 2  + carrier + 12V, USB kept — power mux, DIP, term, FSRs, INT, LEDs
//   Stage 3  + master + a 2nd panel    — RS-485 (not exercised here; needs peers)
//
// Procedure and the reasoning behind each check: docs/PANEL_BRINGUP.md
// As-built pin map (netlist-derived, differs from ../main.c): docs/DUAL_PANEL.md
//
// Talks over USB CDC. Single core on purpose — nothing here is timing-critical
// and a second core only adds ways for a bring-up tool to lie to you.

#include <stdio.h>
#include <string.h>
#include "pico/stdlib.h"
#include "pico/unique_id.h"
#include "hardware/adc.h"
#include "hardware/pio.h"
#include "hardware/clocks.h"
#include "hardware/flash.h"
#include "hardware/sync.h"
#include "hardware/uart.h"
#include "hardware/irq.h"
#include "pico/bootrom.h"
#include "ws2812.pio.h"

// ── As-built pin map (docs/DUAL_PANEL.md → "RP2040 (U306) GPIO map") ─────────
#define PIN_RS485_TX    0
#define PIN_RS485_RX    1
#define PIN_RS485_DE    4    // DE + ~RE tied; HIGH = transmit. Also TP306.
#define PIN_TERM_SENSE  10   // LOW = terminated (SW202 pole B, closes to GND)
#define PIN_LED_DATA    11   // → U301 shifter → R301 330R → carrier
#define PIN_DEBUG_LED   16   // carrier D202/R204
#define PIN_SENSE_12V   17   // R313 100k / R314 33k divider. DIGITAL, not ADC.
#define PIN_DIP_ID3     18   // NOTE the reversal: GPIO18 is bit 3, GPIO21 bit 0
#define PIN_DIP_ID2     19
#define PIN_DIP_ID1     20
#define PIN_DIP_ID0     21
#define PIN_INT_OUT     22   // emulated open-drain, sole gameplay press path

#define NUM_FSR   4
#define NUM_LEDS  25

// GPIO26..29 = ADC0..3. Names are the physical panel edge each lands on; the
// carrier connector for each is listed so a swapped pair is identifiable.
static const uint  FSR_GPIO[NUM_FSR] = {26, 27, 28, 29};
static const char *FSR_NAME[NUM_FSR] = {"South", "West", "North", "East"};
static const char *FSR_CONN[NUM_FSR] = {"J202",  "J201", "J206",  "J203"};

// ── Defaults carried forward from the breadboard firmware ───────────────────
// Bench-validated on the prototype; re-confirm each on real hardware before the
// gameplay firmware inherits them.
#define FSR_PRESS_THRESHOLD    500   // 12-bit counts; resting ~100-115, press ~3900
#define FSR_RELEASE_THRESHOLD  400   // hysteresis, stops chatter at the threshold
#define FSR_FLOAT_THRESHOLD    187   // resting average above this = suspicious

// SENSE_12V filter. Asymmetric on purpose: slow to trust the rail, fast to give
// up on it. The pin's whole job is deciding when it is safe to drive WS2815
// DIN pins, so a sagging rail must stop LED output rather than flap.
#define SENSE_POLL_HZ          1000
#define SENSE_RISE_STABLE_MS   30
#define SENSE_FALL_STABLE_MS   2

// ── 12V sense state ─────────────────────────────────────────────────────────
static volatile bool     g_12v_present   = false;
static volatile uint32_t g_12v_edges     = 0;
static volatile bool     g_12v_edge_flag = false;   // set by timer, printed by main
static volatile uint32_t g_12v_edge_ms   = 0;

static bool sense_12v_raw(void) { return gpio_get(PIN_SENSE_12V); }

static bool sense_timer_cb(repeating_timer_t *t) {
    (void)t;
    static uint16_t agree = 0;
    bool raw = sense_12v_raw();
    if (raw == g_12v_present) { agree = 0; return true; }
    agree++;
    uint16_t need = raw ? (SENSE_RISE_STABLE_MS * SENSE_POLL_HZ / 1000)
                        : (SENSE_FALL_STABLE_MS * SENSE_POLL_HZ / 1000);
    if (agree >= need) {
        agree = 0;
        g_12v_present   = raw;
        g_12v_edges++;
        g_12v_edge_ms   = to_ms_since_boot(get_absolute_time());
        g_12v_edge_flag = true;
    }
    return true;
}

// ── Flash (U307 W25Q32JV) ───────────────────────────────────────────────────
// BOOTSEL enumerating proves nothing about the flash — the bootrom enters it
// *because* it could not read a valid image, so a dead or unsoldered U307 looks
// exactly like a blank one. These checks are what actually validate the part.

static void flash_jedec_id(uint8_t out[3]) {
    uint8_t tx[4] = {0x9F, 0, 0, 0};
    uint8_t rx[4] = {0};
    uint32_t save = save_and_disable_interrupts();
    flash_do_cmd(tx, rx, 4);          // handles XIP exit/restore itself
    restore_interrupts(save);
    out[0] = rx[1]; out[1] = rx[2]; out[2] = rx[3];
}

static void report_flash_id(void) {
    uint8_t id[3];
    flash_jedec_id(id);
    bool ok = (id[0] == 0xEF && id[1] == 0x40 && id[2] == 0x16);  // W25Q32JV
    printf("  flash JEDEC   : %02X %02X %02X   %s\n", id[0], id[1], id[2],
           ok ? "OK (Winbond W25Q32JV, 4MB)"
              : "UNEXPECTED — expected EF 40 16");

    pico_unique_board_id_t uid;
    pico_get_unique_board_id(&uid);
    printf("  board id      : ");
    for (int i = 0; i < PICO_UNIQUE_BOARD_ID_SIZE_BYTES; i++) printf("%02X", uid.id[i]);
    printf("   (read from U307 — use it to name this board's log)\n");
}

// Erase/program/verify the TOP sector, then check whether the pattern also
// appears one alias-length down. A 2MB die substituted for the 4MB part wraps
// addresses, so the write lands at 2MB-4KB and shows up in both windows —
// which is the only way a plain write-and-read-back test can be fooled.
#define TEST_SECTOR   (PICO_FLASH_SIZE_BYTES - FLASH_SECTOR_SIZE)
#define ALIAS_SECTOR  (TEST_SECTOR - (2 * 1024 * 1024))

static void flash_write_test(void) {
    static uint8_t page[FLASH_PAGE_SIZE];
    uint32_t seed = to_ms_since_boot(get_absolute_time());
    for (uint i = 0; i < FLASH_PAGE_SIZE; i++) page[i] = (uint8_t)(seed + i * 31u);

    printf("  erasing + programming 0x%06X (top 4KB, unused)...\n", TEST_SECTOR);
    uint32_t save = save_and_disable_interrupts();
    flash_range_erase(TEST_SECTOR, FLASH_SECTOR_SIZE);
    flash_range_program(TEST_SECTOR, page, FLASH_PAGE_SIZE);
    restore_interrupts(save);

    const uint8_t *at_top   = (const uint8_t *)(XIP_BASE + TEST_SECTOR);
    const uint8_t *at_alias = (const uint8_t *)(XIP_BASE + ALIAS_SECTOR);
    bool verify  = (memcmp(at_top, page, FLASH_PAGE_SIZE) == 0);
    bool aliased = (memcmp(at_alias, page, FLASH_PAGE_SIZE) == 0);

    printf("  write/verify  : %s\n", verify ? "PASS" : "FAIL — U307 does not program");
    printf("  capacity      : %s\n",
           aliased ? "FAIL — pattern echoes at 0x1FF000, die is 2MB not 4MB"
                   : "PASS — no aliasing, full 4MB addressable");
}

// ── SENSE_12V pull-configuration probe ──────────────────────────────────────
// The RP2040 comes out of reset with the pad pull-DOWN enabled, and that is the
// wrong default here: the divider is a 2.98V source behind 24.8k, so a 50k
// internal pull-down drags the pin to ~1.99V — under VIH, i.e. 12V present
// reading as absent. Firmware must disable pulls. This prints what the silicon
// on THIS board actually does under each configuration, so the margin is a
// measured fact rather than my arithmetic.
static void sense_pull_probe(void) {
    printf("  SENSE_12V under each pad pull configuration:\n");

    gpio_disable_pulls(PIN_SENSE_12V);            sleep_ms(5);
    bool none = gpio_get(PIN_SENSE_12V);
    gpio_pull_down(PIN_SENSE_12V);                sleep_ms(5);
    bool down = gpio_get(PIN_SENSE_12V);
    gpio_pull_up(PIN_SENSE_12V);                  sleep_ms(5);
    bool up   = gpio_get(PIN_SENSE_12V);
    gpio_disable_pulls(PIN_SENSE_12V);            sleep_ms(5);

    printf("    pulls off   : %d   <- the configuration firmware must use\n", none);
    printf("    pull-down   : %d\n", down);
    printf("    pull-up     : %d\n", up);
    if (none && !down)
        printf("    ^ CONFIRMED: the reset-default pull-down WOULD have masked 12V.\n"
               "      Record this. It is the reason gpio_disable_pulls(17) is mandatory.\n");
    if (none && down)
        printf("    ^ this board's pull-down is weak enough to still read high.\n"
               "      Do not relax the rule — it is silicon lottery, not margin.\n");
}

// ── INT_OUT: emulated open-drain ────────────────────────────────────────────
// The RP2040 has no true open-drain mode. Assert = drive LOW; release = revert
// to input (hi-Z) and let the master's 10k pull-up do the work. Driving HIGH
// would fight that pull-up and break the documented safe-failure behaviour
// (disconnected wire reads HIGH = not pressed). Never call gpio_put(22, 1).
// gpio_disable_pulls() is MANDATORY and was missing until 2026-09-07. RP2040
// pads reset with the pull-DOWN enabled (PADS_BANK0_GPIOn_PDE_RESET = 1) and
// gpio_init() does not touch pulls — it only sets direction, level and function.
// So "released" was hi-Z *plus a ~45k pull-down*, which fights the master's 10k
// pull-up: measured 2.7V instead of 3.3V on board DE6558A69754442F. Still above
// the Teensy's VIH, so it would have worked — with 0.4V of noise margin on the
// sole gameplay input path instead of 1.0V. This is the GPIO17 trap on a second
// pin, and it is invisible without an external pull-up on the bench.
static void int_out_init(void) {
    gpio_init(PIN_INT_OUT);
    gpio_disable_pulls(PIN_INT_OUT);       // released must be TRUE hi-Z
    gpio_put(PIN_INT_OUT, 0);              // latch low, ready for the dir flip
    gpio_set_dir(PIN_INT_OUT, GPIO_IN);    // released = hi-Z
}
static void int_out_assert(void)  { gpio_set_dir(PIN_INT_OUT, GPIO_OUT); }
static void int_out_release(void) { gpio_set_dir(PIN_INT_OUT, GPIO_IN);  }

// ── DIP + termination ───────────────────────────────────────────────────────
// No board resistors on either net — internal pull-ups are load-bearing.
// Switch closes to GND, so a CLOSED (ON) position reads 0. Panel ID 0 therefore
// means all four switches ON, and an untouched all-OFF switch reads 15.
static uint8_t dip_read(void) {
    return (uint8_t)((gpio_get(PIN_DIP_ID3) << 3) |
                     (gpio_get(PIN_DIP_ID2) << 2) |
                     (gpio_get(PIN_DIP_ID1) << 1) |
                      gpio_get(PIN_DIP_ID0));
}

static const char *dip_meaning(uint8_t v) {
    switch (v) {
        case 9:  return "diag: LED check";
        case 10: return "diag: sensor pressure test";
        case 11: return "diag: standalone";
        case 12: return "diag: raw ADC stream";
        case 13: return "diag: factory reset";
        case 14: return "reserved";
        case 15: return "reserved (also what an unmated brain reads)";
        default: return "panel ID";
    }
}

static uint16_t fsr_read(int ch) {
    adc_select_input(ch);
    return adc_read() & 0x0FFF;
}

// ── LED test — gated on SENSE_12V ───────────────────────────────────────────
// U301 runs from +5VDC, which is live from VBUS alone, so on USB-only power it
// will happily drive LED_DATA_5V into WS2815 DIN pins whose 12V rail is dead,
// forward-biasing their input protection. R301 (330R) keeps that non-destructive
// but it is not a valid test either. This gate is what GPIO17 is FOR.
static PIO  led_pio = pio0;
static uint led_sm;
static bool led_ready = false;

static void led_init(void) {
    uint offset = pio_add_program(led_pio, &ws2812_program);
    led_sm = pio_claim_unused_sm(led_pio, true);
    ws2812_program_init(led_pio, led_sm, offset, PIN_LED_DATA, 800000.0f, false);
    led_ready = true;
}

static void led_fill(uint8_t r, uint8_t g, uint8_t b) {
    uint32_t grb = ((uint32_t)g << 16) | ((uint32_t)r << 8) | b;
    for (int i = 0; i < NUM_LEDS; i++) pio_sm_put_blocking(led_pio, led_sm, grb << 8u);
    sleep_us(300);   // WS2815 reset is ~280us, longer than WS2812B's 50us
}

// Render a 75-byte 'L' payload: 25 RGB triplets, serpentine order (the mapping
// lives in the master; the panel just paints what it is handed). Called from the
// main loop on a throttle, never from the RS-485 reply path — 25 blocking PIO
// writes at 800kHz is ~750us and the master sends 'L' at 60Hz per panel.
static void led_write_frame(const uint8_t *rgb, int n) {
    if (n > NUM_LEDS) n = NUM_LEDS;
    for (int i = 0; i < n; i++) {
        uint32_t grb = ((uint32_t)rgb[i * 3 + 1] << 16) |   // G
                       ((uint32_t)rgb[i * 3 + 0] << 8)  |   // R
                        (uint32_t)rgb[i * 3 + 2];           // B
        pio_sm_put_blocking(led_pio, led_sm, grb << 8u);
    }
    sleep_us(300);
}

static void led_test(void) {
    if (!g_12v_present) {
        printf("  REFUSED — SENSE_12V is low. The WS2815s have no 12V rail; driving\n"
               "  their DIN pins now proves nothing and forward-biases their inputs.\n");
        return;
    }
    if (!led_ready) led_init();
    // Dim on purpose: full white is 0.44A/panel and the point is presence, not
    // brightness. Red draws exactly as much as white on WS2815 (dies in series)
    // so the colour sequence costs nothing extra.
    const uint8_t v = 32;
    printf("  red...\n");   led_fill(v, 0, 0); sleep_ms(700);
    printf("  green...\n"); led_fill(0, v, 0); sleep_ms(700);
    printf("  blue...\n");  led_fill(0, 0, v); sleep_ms(700);
    printf("  white — count them, all 25 should be lit...\n");
    led_fill(v, v, v); sleep_ms(2500);
    led_fill(0, 0, 0);
    printf("  done. Any dark or wrong-colour pixel localises the break: the chain\n"
           "  runs serpentine and the row of 3 is intentionally 180 degrees out.\n");
}
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
int main(void) {
    stdio_init_all();

    // SENSE_12V: pulls OFF, deliberately and first. See sense_pull_probe().
    gpio_init(PIN_SENSE_12V);
    gpio_set_dir(PIN_SENSE_12V, GPIO_IN);
    gpio_disable_pulls(PIN_SENSE_12V);

    // No external pull-ups exist on these nets. Unmated they read all-ones.
    const uint pu[] = {PIN_TERM_SENSE, PIN_DIP_ID0, PIN_DIP_ID1, PIN_DIP_ID2, PIN_DIP_ID3};
    for (uint i = 0; i < count_of(pu); i++) {
        gpio_init(pu[i]); gpio_set_dir(pu[i], GPIO_IN); gpio_pull_up(pu[i]);
    }

    gpio_init(PIN_DEBUG_LED); gpio_set_dir(PIN_DEBUG_LED, GPIO_OUT);
    gpio_put(PIN_DEBUG_LED, 0);

    // Park the transceiver in receive explicitly rather than trusting the pad
    // default, and keep it there — this build never transmits.
    gpio_init(PIN_RS485_DE); gpio_set_dir(PIN_RS485_DE, GPIO_OUT);
    gpio_put(PIN_RS485_DE, 0);

    int_out_init();

    adc_init();
    for (int i = 0; i < NUM_FSR; i++) adc_gpio_init(FSR_GPIO[i]);

    // Seed the filter from the pin so plugging in 12V before USB is not an edge.
    g_12v_present = sense_12v_raw();
    static repeating_timer_t sense_timer;
    add_repeating_timer_us(-1000000 / SENSE_POLL_HZ, sense_timer_cb, NULL, &sense_timer);

    // Give the host a moment to attach, but never block on it.
    for (int i = 0; i < 30 && !stdio_usb_connected(); i++) sleep_ms(100);
    banner();
    help();

    absolute_time_t next_paint = get_absolute_time();
    absolute_time_t next_beat = get_absolute_time();
    bool beat = false;

    while (true) {
        if (g_12v_edge_flag) {
            g_12v_edge_flag = false;
            printf("\n  [%lu ms] SENSE_12V -> %s\n", (unsigned long)g_12v_edge_ms,
                   g_12v_present ? "12V PRESENT" : "12V ABSENT");
        }

        // 1Hz heartbeat: a reset is visible on the board even with no terminal.
        if (absolute_time_diff_us(get_absolute_time(), next_beat) <= 0) {
            beat = !beat;
            gpio_put(PIN_DEBUG_LED, beat);
            next_beat = delayed_by_ms(get_absolute_time(), 500);
        }

        // ⚠ Do NOT block for a millisecond while the responder is live: at
        // 1 Mbps that is 100 byte times against a 32-byte FIFO. The IRQ still
        // catches bytes, but the ring only drains here, so keep the loop tight.
        if (g_rs485_on) rs485_service();

        // Paint the last 'L' frame, throttled and OFF the reply path. led_init()
        // is lazy and 12V-gated for the same reason led_test() is: driving WS2815
        // DIN with their 12V rail dead forward-biases their inputs.
        if (g_led_dirty && g_12v_present &&
            absolute_time_diff_us(get_absolute_time(), next_paint) <= 0) {
            if (!led_ready) led_init();
            led_write_frame(g_led_buf, g_led_len / 3);
            g_led_dirty = false;
            next_paint = delayed_by_ms(get_absolute_time(), 33);   // ~30Hz
        }

        // Auto-INT: drive the REAL gameplay press path from the FSR thresholds,
        // using the same hysteresis state the 'F' reply reports, so telemetry and
        // the INT edge can never disagree. Press any sensor and the master should
        // print "PRESS panel N" — panel ADC -> threshold -> open-drain -> wire ->
        // master ISR, the whole path, with nothing simulated.
        if (g_auto_int) {
            bool pressed = (fsr_update(NULL) != 0);
            if (pressed != g_int_asserted) {
                g_int_asserted = pressed;
                if (pressed) int_out_assert(); else int_out_release();
            }
        }

        int c = getchar_timeout_us(g_rs485_on ? 0 : 1000);
        switch (c) {
            case 's': print_status();      break;
            case 'f': fsr_stream();        break;
            case 'd': dip_watch();         break;
            case 'i': int_test();          break;
            case 'l': led_test();          break;
            case 'p': sense_pull_probe();  break;
            case 'w': flash_write_test();  break;
            case 'v': banner();            break;
            case 'b':
                for (int i = 0; i < 6; i++) {
                    gpio_put(PIN_DEBUG_LED, i & 1); sleep_ms(150);
                }
                printf("  debug LED blinked 3x (carrier D202).\n");
                break;
            case 'R':
                if (!g_rs485_init) rs485_init();
                g_rs485_on = !g_rs485_on;
                if (g_rs485_on) {
                    // Fresh window: counters describe THIS run, not the ring
                    // that backed up while the responder was off.
                    rs_frames = rs_crc_errs = rs_polls = rs_led = 0;
                    rs_ident  = rs_cfg = rs_notmine = 0;
                    rs_overruns = 0;
                    rs_uart_errs = 0;
                    rs_turnaround = 0;
                    rs_fail_idx = 0;
                    rs_head = rs_tail = 0;
                    // ⚠ FLUSH THE HARDWARE FIFO. The UART receives whether or
                    // not its interrupt is enabled, so by the time the responder
                    // is switched on the 32-byte FIFO holds STALE bytes from an
                    // arbitrary earlier moment, with OE long since set. Feeding
                    // those into the ring splices an old fragment onto the live
                    // stream: the result parses as a structurally perfect frame
                    // — right sync, right command, plausible payload — that
                    // fails CRC, because its two halves came from different
                    // frames. That, not bus noise, was every CRC error seen at
                    // the bench; steady-state was 0 in 68,257 frames.
                    while (uart_is_readable(uart0)) (void)uart_get_hw(uart0)->dr;
                    uart_get_hw(uart0)->rsr = 0x0Fu;   // clear OE/BE/PE/FE
                    rs_last_tx_us = time_us_32();
                    rs_resync = true;
                }
                uart_set_irq_enables(uart0, g_rs485_on, false);
                printf("\n  RS-485 responder %s (address %u). Silent while running —\n"
                       "  press 'T' for counters. See docs/PANEL_BRINGUP.md stage 3.\n",
                       g_rs485_on ? "ON" : "OFF", dip_read());
                break;
            case 'T': rs485_stats();       break;
            case 'X': rs485_dump_fails();  break;
            case 'A':
                g_auto_int = !g_auto_int;
                if (!g_auto_int) { int_out_release(); g_int_asserted = false; }
                printf("\n  auto-INT %s — INT_OUT now follows the FSR thresholds"
                       " (press %u / release %u).\n%s",
                       g_auto_int ? "ON" : "off",
                       g_press_th[0] ? g_press_th[0] : FSR_PRESS_THRESHOLD,
                       g_rel_th[0]   ? g_rel_th[0]   : FSR_RELEASE_THRESHOLD,
                       g_auto_int ? "  Stand on a sensor: the master should print"
                                    " PRESS/RELEASE for this panel.\n"
                                  : "  INT_OUT released (hi-Z).\n");
                break;
            case 'B':
                // Reboot into BOOTSEL so reflashing needs no button. Stage 3 is
                // an edit/build/flash loop; SW301 is under the panel platform.
                printf("\n  rebooting into BOOTSEL — drag the .uf2 onto RPI-RP2.\n");
                sleep_ms(120);          // let the CDC write drain first
                reset_usb_boot(0, 0);
                break;
            case 'E':
                g_led_echo = !g_led_echo;
                printf("\n  'L' -> LED echo %s.%s\n", g_led_echo ? "ON" : "off",
                       g_led_echo ? " Painting is throttled to ~30Hz in the main"
                                    " loop, so it does not touch reply timing."
                                    " Needs 12V." : "");
                break;
            case '?': help();              break;
            default: break;
        }
    }
}

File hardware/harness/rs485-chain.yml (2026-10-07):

metadata:
  title: RS-485 bus chain
  description: >
    Single daisy-chained differential bus, master plus all nine panels, at
    1 Mbps. Physical order matches the stock SMX serpentine routing exactly:
    master, 0(UL), 3(L), 6(DL), 7(D), 4(C), 1(U), 2(UR), 5(R), 8(DR).
    Carries the LED broadcast and the FSR telemetry round-robin poll -- NOT the
    press path, which is the separate INT home-run harness.
    Termination: 120R at the master end and at the last panel in the chain
    (selected by that panel's DPDT switch -- all nine panels are identical).
    LENGTHS CLOSED 2026-08-16, transcribed from the STOCK data chain in
    panel-data-chain.yml. That bus runs the IDENTICAL serpentine through the
    IDENTICAL panel positions, so its measured lengths transfer directly:
    60 cm master to panel 0, then EIGHT IDENTICAL 45 cm jumpers. Total 4.2 m
    of shielded pair before slack. Only two conductors and a drain replace
    stock's RJ-12 leads; the geometry is unchanged.
    Caveat: this assumes the replacement master mounts where the stock Arduino
    Micro sat. Re-measure the 60 cm master lead if it moves; the eight 45 cm
    panel-to-panel jumpers are unaffected by master position.
    DRY FIT 2026-10-07: the two finished RS-485 cables routed in the real pad came
    out, if anything, a little long. Stock lengths KEPT; the +5 cm per cable
    that was floated is NOT applied. The 60 cm master lead depends on where
    the master mounts, so check it when the master goes in.
  status: PROPOSED -- this project's own design, written pre-teardown. Provisional until the stock record is complete.
  pn: HARNESS-485-01
  qty_per_pad: 1

options:
  color_mode: full

connectors:
  MASTER:
    pn: Micro-Fit 3.0 3-pin
    type: Master PCB J1
    subtype: Micro-Fit 3.0, 3-pin
    pincount: 3
    pinlabels: [A, B, SHLD]
    notes: >
      Pin 3 is the ONLY DC ground reference for the cable shield in the whole
      pad (J1 pin 3 ties to master GND). Every panel passes the shield through
      without a local GND tie, each with a 100nF parallel 1M to GND.
      This hybrid grounding scheme was adopted 2026-07-26, reversing both the
      earlier "unpopulated 3rd pin" and "drain floating at both ends" calls.

  P0_IN:
    pn: Micro-Fit 3.0 3-pin
    type: Panel 0 (UL) RS485 IN
    subtype: Micro-Fit 3.0, 3-pin
    pincount: 3
    pinlabels: [A, B, SHLD]
  P0_OUT:
    pn: Micro-Fit 3.0 3-pin
    type: Panel 0 (UL) RS485 OUT
    subtype: Micro-Fit 3.0, 3-pin
    pincount: 3
    pinlabels: [A, B, SHLD]
  P3_IN:
    pn: Micro-Fit 3.0 3-pin
    type: Panel 3 (L) RS485 IN
    subtype: Micro-Fit 3.0, 3-pin
    pincount: 3
    pinlabels: [A, B, SHLD]
  P3_OUT:
    pn: Micro-Fit 3.0 3-pin
    type: Panel 3 (L) RS485 OUT
    subtype: Micro-Fit 3.0, 3-pin
    pincount: 3
    pinlabels: [A, B, SHLD]
  P6_IN:
    pn: Micro-Fit 3.0 3-pin
    type: Panel 6 (DL) RS485 IN
    subtype: Micro-Fit 3.0, 3-pin
    pincount: 3
    pinlabels: [A, B, SHLD]
  P6_OUT:
    pn: Micro-Fit 3.0 3-pin
    type: Panel 6 (DL) RS485 OUT
    subtype: Micro-Fit 3.0, 3-pin
    pincount: 3
    pinlabels: [A, B, SHLD]
  P7_IN:
    pn: Micro-Fit 3.0 3-pin
    type: Panel 7 (D) RS485 IN
    subtype: Micro-Fit 3.0, 3-pin
    pincount: 3
    pinlabels: [A, B, SHLD]
  P7_OUT:
    pn: Micro-Fit 3.0 3-pin
    type: Panel 7 (D) RS485 OUT
    subtype: Micro-Fit 3.0, 3-pin
    pincount: 3
    pinlabels: [A, B, SHLD]
  P4_IN:
    pn: Micro-Fit 3.0 3-pin
    type: Panel 4 (C) RS485 IN
    subtype: Micro-Fit 3.0, 3-pin
    pincount: 3
    pinlabels: [A, B, SHLD]
  P4_OUT:
    pn: Micro-Fit 3.0 3-pin
    type: Panel 4 (C) RS485 OUT
    subtype: Micro-Fit 3.0, 3-pin
    pincount: 3
    pinlabels: [A, B, SHLD]
  P1_IN:
    pn: Micro-Fit 3.0 3-pin
    type: Panel 1 (U) RS485 IN
    subtype: Micro-Fit 3.0, 3-pin
    pincount: 3
    pinlabels: [A, B, SHLD]
  P1_OUT:
    pn: Micro-Fit 3.0 3-pin
    type: Panel 1 (U) RS485 OUT
    subtype: Micro-Fit 3.0, 3-pin
    pincount: 3
    pinlabels: [A, B, SHLD]
  P2_IN:
    pn: Micro-Fit 3.0 3-pin
    type: Panel 2 (UR) RS485 IN
    subtype: Micro-Fit 3.0, 3-pin
    pincount: 3
    pinlabels: [A, B, SHLD]
  P2_OUT:
    pn: Micro-Fit 3.0 3-pin
    type: Panel 2 (UR) RS485 OUT
    subtype: Micro-Fit 3.0, 3-pin
    pincount: 3
    pinlabels: [A, B, SHLD]
  P5_IN:
    pn: Micro-Fit 3.0 3-pin
    type: Panel 5 (R) RS485 IN
    subtype: Micro-Fit 3.0, 3-pin
    pincount: 3
    pinlabels: [A, B, SHLD]
  P5_OUT:
    pn: Micro-Fit 3.0 3-pin
    type: Panel 5 (R) RS485 OUT
    subtype: Micro-Fit 3.0, 3-pin
    pincount: 3
    pinlabels: [A, B, SHLD]
  P8_IN:
    pn: Micro-Fit 3.0 3-pin
    type: Panel 8 (DR) RS485 IN
    subtype: Micro-Fit 3.0, 3-pin
    pincount: 3
    pinlabels: [A, B, SHLD]
  P8_OUT:
    pn: Micro-Fit 3.0 3-pin
    type: Panel 8 (DR) RS485 OUT
    subtype: Micro-Fit 3.0, 3-pin
    pincount: 3
    pinlabels: [A, B, SHLD]
    notes: >
      END OF CHAIN -- left empty. Panel 8 is the termination point; its
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

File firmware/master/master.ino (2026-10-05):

// Master MCU firmware — Teensy 4.0, as-built master-pcb rev 1.
//
// Ported off the 2-panel breadboard prototype 2026-09-03: pins, panel count and
// UART all come from the netlist now (docs/MASTER_PCB.md "Teensy 4.0 pin map").
// The old prototype map is NOT a subset of this one — pins 3 and 4 carried the
// two INT lines there and carry the player-ID DIP here, so a partial port would
// have read the DIP as panel presses.
//
// Runs the pad: INT edge capture, addressed LED frames, FSR telemetry polling.
// Also carries the bench command set, because master bring-up happens with zero
// panels flashed and every board-local check has to work standalone.
//
// Protocol: docs/RS485_PROTOCOL.md. Bring-up procedure: docs/MASTER_BRINGUP.md.
// Flash: arduino-cli compile --fqbn teensy:avr:teensy40 firmware/master
//        arduino-cli upload  --fqbn teensy:avr:teensy40 firmware/master

// ── As-built pin map (netlist-verified against master-pcb.kicad_pcb) ─────────
constexpr uint8_t NUM_PANELS = 9;
constexpr uint8_t PANEL_IDS[NUM_PANELS] = {0, 1, 2, 3, 4, 5, 6, 7, 8};

// Panel ID -> physical position -> Teensy pin -> master connector. The position
// string is exactly what is silkscreened beside the header and printed on the
// cable label, so anything reported by name needs no lookup table at the bench.
constexpr uint8_t INT_PINS[NUM_PANELS]  = {23, 22, 21, 20, 19, 18, 17, 16, 15};
const char *const PANEL_NAME[NUM_PANELS] = {"UL", "U", "UR", "L", "C", "R", "DL", "D", "DR"};
const char *const INT_CONN[NUM_PANELS]   = {"J11","J10","J9","J8","J7","J6","J5","J4","J3"};

// RS-485 is Serial2 (RX 7 / TX 8) with DE on 6. Serial1 (pins 0/1) is
// deliberately left free as the last spare hardware UART.
#define RS485_SERIAL Serial2
constexpr uint8_t RS485_DE_PIN = 6;   // Serial2.transmitterEnable() drives this

// Player/pad ID DIP (SW1). Closes to GND against internal pull-ups, so a CLOSED
// switch reads 0 — meaning player 0 (P1) is all three switches ON, and a
// factory-fresh all-OFF switch reads 7, not 0. Bit order runs backwards against
// ascending pin number, exactly as on the panel's ID DIP.
constexpr uint8_t DIP_ID2_PIN = 3;
constexpr uint8_t DIP_ID1_PIN = 4;
constexpr uint8_t DIP_ID0_PIN = 5;

// Underglow WS2811 data out -> U3 (SN74AHCT1G125, 5V) -> R5 330R -> J2 pin 1.
// R4 (10k pull-down) holds U3's input LOW before firmware drives the pin, so
// the strip sees no garbage during boot. 44 groups of 3 LEDs; the WS2811 drives
// 3 LEDs per chip, so one group = one pixel of data.
constexpr uint8_t UNDERGLOW_PIN = 11;
constexpr int     UNDERGLOW_GROUPS = 44;

constexpr uint8_t LED_PIN = 13;       // Teensy onboard LED; not routed on the board

struct Color { uint8_t r, g, b; };
constexpr Color PANEL_PRESS_COLOR[NUM_PANELS] = {
  {200,   0,   0},  // UL
  {200, 100,   0},  // U
  {200, 200,   0},  // UR
  {  0, 200,   0},  // L
  {  0, 200, 200},  // C
  {  0,   0, 200},  // R
  {120,   0, 200},  // DL
  {200,   0, 120},  // D
  {160, 160, 160},  // DR
};

constexpr uint32_t RS485_BAUD = 1000000;
constexpr uint8_t  PKT_SYNC = 0x55;
constexpr uint8_t  PKT_MAX_PAYLOAD = 80;
constexpr uint8_t  BROADCAST = 0xFF;
constexpr int      NUM_LEDS = 25;
constexpr uint32_t FRAME_INTERVAL_MS = 16;    // ~60Hz per-panel addressed frames
constexpr uint32_t POLL_INTERVAL_MS = 5;      // 200Hz FSR telemetry poll, independent of LED rate
constexpr uint32_t STREAM_INTERVAL_MS = 33;   // ~30Hz print rate when streaming ('t' to toggle)

int panelIndex(uint8_t addr) {
  for (int i = 0; i < NUM_PANELS; i++)
    if (PANEL_IDS[i] == addr) return i;
  return -1;
}

// ── INT edge capture (ISR -> loop ring buffer) ───────────────────────────────
// Parallel volatile arrays rather than an array-of-structs: the implicit
// copy constructor won't bind to a volatile-qualified struct lvalue, but
// plain volatile scalar reads/writes work fine.
constexpr size_t RING_SIZE = 64;
volatile uint32_t ring_t_us[RING_SIZE];
volatile uint8_t  ring_panel[RING_SIZE];
volatile uint8_t  ring_pressed[RING_SIZE];
volatile size_t   ring_head = 0;
volatile size_t   ring_tail = 0;
volatile uint32_t dropped_edges = 0;

inline void pushEdge(uint8_t panel, uint8_t pin) {
  uint8_t pressed = (digitalReadFast(pin) == LOW) ? 1 : 0;  // active-low
  size_t next = (ring_head + 1) % RING_SIZE;
  if (next == ring_tail) {
    dropped_edges++;
    return;
  }
  ring_t_us[ring_head] = micros();
  ring_panel[ring_head] = panel;
  ring_pressed[ring_head] = pressed;
  ring_head = next;
}
// attachInterrupt needs a plain function pointer per pin — no capture, so one
// trampoline per panel rather than a single parameterized handler.
#define INT_TRAMPOLINE(n) void intLineIsr##n() { pushEdge(n, INT_PINS[n]); }
INT_TRAMPOLINE(0) INT_TRAMPOLINE(1) INT_TRAMPOLINE(2)
INT_TRAMPOLINE(3) INT_TRAMPOLINE(4) INT_TRAMPOLINE(5)
INT_TRAMPOLINE(6) INT_TRAMPOLINE(7) INT_TRAMPOLINE(8)
void (*const INT_ISR[NUM_PANELS])() = {
  intLineIsr0, intLineIsr1, intLineIsr2, intLineIsr3, intLineIsr4,
  intLineIsr5, intLineIsr6, intLineIsr7, intLineIsr8,
};

// ── RS-485 framing ───────────────────────────────────────────────────────────
uint8_t crc8Update(uint8_t crc, uint8_t b) {
  crc ^= b;
  for (int i = 0; i < 8; i++)
    crc = (crc & 0x80) ? (uint8_t)((crc << 1) ^ 0x07) : (uint8_t)(crc << 1);
  return crc;
}
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

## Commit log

2026-07-10 Initial commit: architecture docs, prototype firmware, and BOM
    Custom replacement hardware for a StepManiaX 9-panel dance pad: Teensy 4.0
    master + RP2040 panel boards over RS-485, per-panel interrupt wires, FSR
    sensing, and WS2815 panel lighting.
    Includes:
    - CLAUDE.md architecture reference
    - docs/: RS-485 protocol, prototype wiring, animation formats, panel
    config, modular panel count, underglow findings, USB protocol, BOM
    - firmware/: panel prototype (MicroPython + C/Pico SDK), master Teensy
    sketches incl. USB speed test
    - tools/: FSR monitor, USB speed test host script
    [fsr_monitor.py, main.c, main.py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]
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2026-07-11 Panel PCB schematic complete: FSR, LED chain, INT, ID DIP + doc updates
    - FSR inputs x4 (J7-J10, 10k dividers, 10nF C0G ADC caps)
    - LED chain: 25x WS2815 + SN74AHCT125 shifter, GPIO3 debug LED (optional populate)
    - WS2815 per-LED 100nF corrected to VCC->GND per datasheet (BOM.md note fixed)
    - INT out (100R series + single-pos terminal), 4-pos panel ID DIP
    - Spare shifter gates: inputs + ~OE grounded, outputs no-connect
    - Debug press LED gated to diagnostic modes 9-13 (docs/PANEL_CONFIG.md)
    ERC clean, netlist-verified pin-exact (~330 parts).
    [panel-pcb.kicad_sch]
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2026-07-11 Schematic: GUI reorganization, re-annotate by position, 11 test points, normalization pass
    - User reorganized layout + re-annotated all refs by sheet position
    (verified: connectivity identical via UUID-mapped netlist diff, ERC 0 errors)
    - 10 new test points (TP2-TP11): rails, GND x2, UART TX/RX, RS-485 dir,
    LED data 3.3V/5V sides
    - Normalization (133 property changes): cap dielectrics + voltage ratings
    (15pF C0G, 10nF C0G 50V, 100nF X7R 50V, LDO electrolytics 25V), FSR
    pull-downs 10k 1%, power-OR Schottkys -> 1N5819W, footprints for all
    passives/LEDs/JST-PH/Micro-Fit/DIP/SOIC-14
    - Still TBD at sourcing: USB-C receptacle (J1), INT terminal (J9),
    DPDT slide (SW1) footprints
    - Docs: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
    [panel-pcb.kicad_sch]
2026-07-11 Add C51 470uF 12V bulk cap for LED load steps (user-placed, verified); fix inherited description
    [panel-pcb.kicad_sch]
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2026-07-11 Import EG2201A footprint (SnapEDA) into project lib, assign to SW3; fix SW1/SW3 mixup in docs
    [panel-pcb.kicad_sch]
2026-07-11 SW3: swap generic DPDT symbol for SnapEDA EG2201A + fix termination-sense polarity
    - EG2201A symbol embedded + added to new project symbol lib (panel-pcb.kicad_sym
    + sym-lib-table); reads as one physical slide, matches footprint pin layout
    - Rewired for new pin geometry: RS485_A -> pin 2 (common), R2 120R relocated to
    pin 1, GPIO10 label -> pin 5, GND moved pin 6 -> pin 4 so the position that
    inserts the 120R also reads LOW = terminated (was inverted), pins 3/6 NC
    - Netlist-verified pin-exact; ERC 0 errors
    [panel-pcb.kicad_sch]
2026-07-11 Pre-layout audit fixes: R2 -> 120R (RKM consistency), remove 2 drag-debris wire stubs, replace defunct bornier footprint with hand-drawn KF301-1P (verify dims at order)
    [panel-pcb.kicad_sch]
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2026-07-11 PCB placement pass 1: LED lattice + all clusters
    - 25x WS2815 on measured lattice (4-3-4-3-4-3-4, row 1 Y=11mm, 17mm rows,
    34mm columns, serpentine chain order derived from netlist), per-LED caps
    mid-gap below each LED
    - Edge connectors at stock-measured positions (power ~25mm, INT ~93mm,
    RS-485 IN ~103mm left / OUT ~95mm right), FSR JST-PH near-centered per edge
    - MCU cluster in the x148-162 lattice channel (QFN + decoupler columns,
    crystal, flash, FSR analog strip at pins), LDO cluster top-left by power IN,
    RS-485 xcvr + termination bottom-left by data connectors, shifter at LED 0,
    USB-C/SWD/BOOTSEL/ID-DIP bottom strip, TPs near their signals
    - DRC: 0 shorts; remaining violatio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
    [panel-pcb.kicad_pcb]
2026-07-12 Board outline: stock-style connector tabs + user placement pass
    - 5 tabs, 4mm deep, sized to final connector positions: left power (y67-83),
    merged left INT+RS-485 (y132-162, like stock's stepped lower-left), right
    power (y67-83), right RS-485 (y143-163), bottom USB (x145.5-159.5)
    - J5/J8/J9/J10/J11/J1 shifted 4mm outward onto their tabs
    - Includes user's GUI placement adjustments (KiCad 10 format)
    - DRC: 0 shorts, 96 violations (was 512) - remaining are silk refinements +
    by-design no-net peg pads near tab faces
    [panel-pcb.kicad_pcb, panel-pcb.kicad_sch]
2026-07-13 Panel PCB: refined mounting hole/LED lattice measurements, 0402 RP2040 decoupling, JLC DRC rules
    - Mounting holes: top pair 113mm apart (not a symmetric 114mm square) per
    refined caliper measurement, cross-checked against the stock board photo.
    - LED lattice: 33.5mm column pitch (not 34mm), 17mm row pitch, insets
    13.5/13.0mm (L/R) and 12.5mm (T/B) - only the 25 LED footprints moved.
    - RP2040 decoupling caps (C1,C2,C3,C4,C5,C6,C7,C8,C9,C11,C13,C15): 0603 -> 0402
    for placement clearance; nets/positions preserved.
    - Added JLCPCB 4-layer custom DRC rules (panel-pcb.kicad_dru) and matching
    Board Setup constraint values.
    - Added corrected WS2815 PLCC6 footprint (panel-pcb.pretty/) with pad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
    [panel-pcb.kicad_pcb]
2026-07-16 Panel PCB: 12V transition via fixes, JLC DRC rule tuning, schematic field parity
    [panel-pcb.kicad_pcb, panel-pcb.kicad_sch]
2026-07-17 Panel PCB: AP7361C 3V3 LDO + PMEG3015EH swap, THT Micro-Fit connectors, docs reconciliation
    Hardware (schematic + PCB + user re-routing):
    - U6 AMS1117-3.3 -> AP7361C-33ER-13 (-33ER- suffix only; low dropout fixes
    USB-VBUS-only powering headroom), D12/D23 1N5819W -> PMEG3015EH
    - Caps re-specced all-SMD: C38 22uF 16V tantalum (ESR for AMS1117-5.0 out),
    C37+new C52 parallel 10uF 0805 MLCC (12V DC-bias fix), C44/C50 10uF MLCC,
    C51 470uF -> SMD V-chip electrolytic RVT1E471M1010
    - J5/J8/J10/J11 Micro-Fit swapped SMD (43650-0210/-0310) -> right-angle THT
    (43650-0200/-0300); the old BOM "43651" series pointer was wrong
    Docs: full staleness pass cross-referenced against schematic/PCB/memory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
    [panel-pcb.kicad_pcb, panel-pcb.kicad_sch]
2026-07-17 Panel PCB: USBLC6-2SC6 USB ESD array (U7), island GND stitching vias, routing touch-ups
    - Add USBLC6-2SC6 (U7) on the USB-C data lines, connector side of the
    27R series resistors, flow-through routed with a local GND via.
    Rationale: shoe-on-rubber tribocharging on the pad, not just bench
    plug events. Docs updated (CLAUDE.md, BOM, schematic plan).
    - GND stitching vias for the In2 island regions (zone-priority net
    inheritance issue resolved; no +12V free vias remain).
    - Minor trace adjustments from the via pass. DRC clean: 0 violations,
    0 unconnected.
    [panel-pcb.kicad_pcb, panel-pcb.kicad_sch]
2026-07-17 Panel PCB: tighten zone outlines to board area
    Pull three pour boundaries in from oversized extents to the actual
    board envelope. DRC clean: 0 violations, 0 unconnected.
    [panel-pcb.kicad_pcb]
2026-07-17 Panel PCB: silkscreen positioning pass, verified ERC/DRC exclusions, page settings
    - Reposition reference/value silkscreen across the board.
    - Fix J1 B1/B12 starved thermal spokes.
    - Save C51's edited electrolytic footprint into panel-pcb.pretty as
    CP_Elec_10x10.5_RVT1E471M and re-associate.
    - Exclude verified-benign warnings: 25 lib_footprint_mismatch DRC
    false positives (rotation-correlated, content identical to library)
    and lib_symbol_mismatch ERC noise (cached flattened copies of
    derived library symbols, pins verified identical).
    - Page settings: A3 -> A4 landscape, title block date/rev refreshed,
    stale mounting-hole placeholder comment removed.
    Still pending before fab: silks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
    [panel-pcb.kicad_pcb, panel-pcb.kicad_sch]
2026-07-17 Panel PCB: design-review batch 1 - fit R12, lock X1 MPN, metadata fixes
    From the AI design review (tmp/review-bundle/ai-review, not tracked):
    - R12 QSPI /CS pull-up: DNF -> fitted 10k. The Pi guide's DNF default
    was validated on W25Q128JVS, not W25Q32JV, and RP2040's internal
    QSPI_SS pull-up is not guaranteed during early power-ramp.
    - X1 value now names ABM8-272-T3 explicitly (CL=10pF is what the
    15pF/15pF/1k network is calculated for); rationale in Description.
    - Fix refdes drift in four Description fields: C10 (U5->U2),
    R2 (SW2->SW3), D12 (J2->J1), D23 (U3->U5).
    - Rename In2 zone 9 from '+12.0V' to '+5.0V' to match its net.
    - Docs: correct the BOM.md/schematic-plan claim that the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
    [panel-pcb.kicad_pcb, panel-pcb.kicad_sch]
2026-07-17 Panel PCB: design-review batch 2 - first-BIN ground, 12V sense divider, QSPI margin
    - D2.6 (first WS2815 BIN) rewired from /LD0 to GND, matching the
    vendor application circuit (review finding P3-2; the old BOM.md
    claim that the datasheet ties it to the data source was wrong).
    - New 12V presence sense: R18 100k from +12.0V, R19 22k to GND,
    C53 100nF filter, midpoint to GPIO17 (U1.28). ~2.16V at 12V,
    ~100uA injection ceiling into an unpowered GPIO. Lets firmware
    gate LED data output on 12V-good so USB-only bench power never
    drives unpowered WS2815 inputs (review finding P4-2).
    - QSPI_SD0/SD2 pinch widened 0.09mm -> 0.127mm (was at JLC's
    absolute multilayer minimum spacing; review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
    [panel-pcb.kicad_pcb, panel-pcb.kicad_sch]
2026-07-18 Panel PCB: board art, name/rev silk, follow-up review fixes
    - Silkscreen: 'Kraken Pad by SenPi / Rev. 1.0' (F.Silk), JLC order-number
    placeholder JLCJLCJLCJLC (B.Silk).
    - Personal logo as exposed copper: 5 poly pairs F.Cu + point-registered
    F.Mask openings; degenerate near-zero-area sliver pair deleted
    (follow-up review F3).
    - R19 22k -> 33k: 12V-sense node ~2.98V, ~1V margin over guaranteed
    2.0V VIH (follow-up review F1; old 22k value had 164mV nominal margin).
    - New D29 PMEG3015EH clamp, anode GPIO17 / cathode +3V3: bounds the
    sense node to one Vf above the rail when IOVDD is down, closing the
    RP2040 abs-max-vs-FT-description ambiguity (follow-up review F2).
    - Via DRC rules swi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
    [panel-pcb.kicad_pcb, panel-pcb.kicad_sch]
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2026-07-18 Panel PCB: LCSC part numbers, 200R fix, pre-order checklist
    - LCSC fields added to all SMD symbols from the JLC quote session's
    matched picks (tmp/bom.xls) - BOM/CPL exports now carry exact part
    numbers so re-uploads auto-match without manual picking.
    - R5 201R -> 200R 1%: JLC stocks no 201R; the matched part (C8218) is
    200R, and the ADC_AVDD filter doesn't care. Value now matches reality.
    - R7/R15 1k -> '1k 1%' so all three 1k positions (with R6) merge to one
    BOM line, matching the single part picked for them (C2907002).
    - D29 Description filled (12V-sense clamp role); stray trailing quote
    removed. TP6 'RS-485 DC' -> 'DE' typo fixed.
    - docs/PRE_ORDER_CHECKLIST.md: full pre-order r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
    [panel-pcb.kicad_pcb, panel-pcb.kicad_sch]
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2026-07-18 Master PCB: INT TVS decided - 3x SRV05-4 replaces discrete placeholders
    TECH PUBLIC SRV05-4 (SOT-23-6 rail-clamp array, LCSC C558418,
    ~$0.013/pc, 394k stock): D2=INT0-3, D3=INT4-7, D4=INT8 (spare channels
    NC); VN to GND, VP to +3V3. Stock KiCad Power_Protection:SRV05-4
    symbol, pinout verified (IO1/VN/IO2/IO3/VP/IO4). Decided now rather
    than at BOM time so the INT block only gets wired once. Wiring list
    and plan doc updated; D2-D10 D_TVS placeholders removed.
    [master-pcb.kicad_sch]
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2026-07-20 Panel + master schematics: LM66200 power-OR, master cleanup, docs sweep
    Panel:
    - U8 LM66200 ideal-diode mux wired as the 5V power-OR (review 4.m);
    D12/D23 Schottky OR kept as DNP hand-solder fallback
    - Promote LM66200 symbol from schematic cache into panel-pcb.kicad_sym
    - J9 INT terminal 1P -> 2P with new custom KF301 footprint
    - ERC 0 errors
    Master:
    - J3 deleted; J4 is the merged 2-pos terminal (pin 1 DATA, pin 2 GND tie)
    - Status LED resistor moved to the anode side
    - R4/R5 390R DNP RS-485 bias pair wired (review 3.a)
    - Rails standardized +3.3VDC / +5VDC_USB; spare pins given readable names
    - ERC 0 errors
    Docs: MASTER_SCHEMATIC_PLAN, REVIEW_RESPONSES, CLAUDE.md, BOM,
    PANEL_SCHEMATIC_PL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
    [master-pcb.kicad_sch, panel-pcb.kicad_pcb, panel-pcb.kicad_sch]
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2026-07-20 Panel PCB: FSR caps to ADC pins, GND via stitching, silkscreen labels
    - Move all 4 FSR filter caps (C16-C19) from the connector edges to the
    back side near the RP2040 ADC pins, so the 10nF sits electrically at the
    pin where it shunts pickup along the run (was 22-98mm away).
    - Heavy GND via stitching around the FSR traces; all pours remain single
    islands, no +12V free-via inheritance, DRC clean.
    - Additional silkscreen labels.
    - Ignore /tmp.
    DRC 0 errors / 0 unconnected (benign silk-overlap + rotation warnings only).
    [panel-pcb.kicad_pcb]
2026-07-20 Panel PCB: assign 3D models to WS2815 (x25) and KF301 stand-ins; capture continued via/label edits
    3D models (surgical insert, no reformat):
    - 25x WS2815 -> stock LED_WS2812_PLCC6_5.0x5.0mm (identical body), rot 180
    so the pin-1 marker matches the footprint orientation.
    - J9 KF301-2P -> Phoenix MKDS-1,5 5.08mm 2P horizontal stand-in, rot 90
    (orientation to be eyeballed in the 3D viewer).
    - 119/123 model refs now resolve. Remaining gaps: 4x Micro-Fit (need the
    official KiCad 3D pack), SW3 EG2201A (no stock match), 12x testpoints (skip).
    Also captures board edits made in KiCad after 8513c5f was committed: +356
    stitching vias, a new 'RS-485 TERM' silk label, and 2 minor track reroutes.
    D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
    [panel-pcb.kicad_pcb]
2026-07-20 Panel PCB: wire up Micro-Fit/EG2201A 3D models + orientation, add silk label
    - Add 3 vendor STEP models (project-local, KIPRJMOD-relative):
    Molex 43650-0200/-0300 Micro-Fit, E-Switch EG2201A.
    - Micro-Fit x4 repointed off the (nonexistent) stock KiCad models to the
    vendor STEP; oriented flat with openings facing off the board edges
    (rot Z 180). Single local transform serves both edges (footprints are
    180 apart).
    - SW3 EG2201A lifted +9mm to sit on the board (model is in cm units).
    - J9 KF301 stand-in rot Z 0 (screw openings face the board edge).
    - One additional silkscreen label.
    All 14 connectors + switches + 25 LEDs now render. DRC 0 errors / 0
    unconnected; 124 model refs resolve (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
    [0436500200.stp, 0436500300.stp, EG2201A.stp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]
2026-07-21 Panel PCB/sch: all DRC + ERC + schematic-parity clean (0/0/0, no exclusions)
    Warning cleanup (genuine fixes, zero suppressions):
    - lib_footprint_mismatch x25: normalize pad-angle fields to body rotation
    (geometric no-op; matches "Update Footprints from Library")
    - 0402 pad-to-silk x48 + J1 board-edge silk x2: add local trimmed footprints
    panel-pcb:C_0402_1005Metric_SilkTrim and USB_C_Receptacle_GCT_USB4085_EdgeTrim;
    repoint 12 caps + J1 in both schematic and PCB
    - D10<->TP12 silk x2: move TP12 refdes into the gap clear of D10 and its circle
    - ERC: add FSR symbol to panel-pcb.kicad_sym; remove 35 stale ERC exclusions
    - schematic-parity x50: align 25 WS2815 LED symbol fields
    (footprint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
    [panel-pcb.kicad_pcb, panel-pcb.kicad_sch]
2026-07-21 Panel PCB/sch: WS2815 datasheet -> Worldsemi WS2815B-V1 V2.0 (correct VIH spec)
    - Replace old NORMAND datasheet link (0.7*VDD wording) with the Worldsemi
    WS2815B-V1 V2.0 datasheet (absolute VIH 2.7V) across 25 symbols, 25 PCB
    footprints, descr citations, and the panel-pcb:WS2815 library footprint
    - Add footprint descr note: pin 1 is "NC" per Worldsemi but is the internal
    ~5V reg rail; the 100nF to GND is an intentional noise filter
    - DRC/parity/ERC all 0, no exclusions
    [panel-pcb.kicad_pcb, panel-pcb.kicad_sch]
2026-07-23 Panel PCB: JLC stackup, MRR52 terminal footprint on J9
    - Stackup: KiCad default 0.48/0.48/0.48 FR4 -> real JLC JLC04161H-7628
    (0.2104 prepreg / 1.065 core, Er 4.4/4.6, 0.5oz inner). Fab output
    unaffected; corrects impedance calc / 3D / board thickness.
    - J9 (INT out): repoint KF301 hand-stand-in -> TerminalBlock_MRR52-5.08-2P,
    built from Adam Tech datasheet 375571 (hole 1.3 -> 1.50mm, body 10.00mm).
    MPN MRR522-5.08-V, DigiKey 5245-MRR522-5.08-V-ND; stale KF301/C474881
    LCSC+datasheet cleared.
    - Remove orphaned TerminalBlock_KF301-1P footprint (unused since J9 -> 2P).
    - DRC/ERC clean.
    [panel-pcb.kicad_pcb, panel-pcb.kicad_sch]
2026-07-23 Master PCB: DigiKey BOM, SMA TVS, terminal footprints, DRC-clean layout
    First commit of the routed master-pcb.kicad_pcb plus supporting library.
    - Stackup + planes: JLC JLC04161H-7628; both inner layers -> GND
    (Sig+Pwr / GND / GND / Sig+Pwr); +3.3V distributes on outer copper.
    - INT ESD: 3x SRV05-4 arrays -> 9 discrete unidirectional TVS D2-D10
    (Littelfuse SMAJ5.0A, DO-214AC / D_SMA_Handsoldering). Single-line shunt
    stubs at J2; closes the array-decoupling question.
    - Terminal blocks built from datasheets: J2 -> Molex 39531 9-pos pluggable
    euro header (SD-39531-003, hole 1.60mm); J4 -> Adam Tech MRR52-5.08-2P
    (hole 1.50mm). Both replace stand-in footprints.
    - BOM: MPN + DigiKey P/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
    [0436500300.stp, Teensy_4.0_Assembly.STEP, master-pcb-BOM.csv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]
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2026-07-23 Panel PCB: complete THT DigiKey/MPN fields
    Populate DigiKey PN on hand-solder THT parts from the 2026-07-22 cart:
    J1 (USB-C), J2 (SWD, Würth 61300311121), J5/J11 + J8/J10 (Micro-Fit),
    SW3 (EG2201A). SW1 corrected from stale DSWB04LHGET -> CUI DS01C-254-S-04BE
    (the actual cart part) with DigiKey PN, stale LCSC C99418 cleared.
    FSR JST (J3/J4/J6/J7) keep MPN only — out of stock at DigiKey, sourced
    elsewhere. ERC clean.
    [panel-pcb.kicad_sch]
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2026-07-23 Docs: deep consolidation pass
    - Merge ANIMATION_FORMAT + ANIMATION_BINARY_FORMAT + PROTOTYPE_LED_LAYOUT -> ANIMATIONS.md
    - Merge STOCK_PANEL_CHIPS + STOCK_PANEL_PCB_MEASUREMENTS -> STOCK_PANEL_REFERENCE.md
    - Merge BOM + DIGIKEY_SHOPPING_LIST + BOM_PRICED -> one BOM.md (design qty,
    priced cart, AliExpress candidates, THT analysis); fix stale J9/SW/RN1 picks
    - Condense PANEL_SCHEMATIC_PLAN + PANEL_PCB_LAYOUT_NOTES -> PANEL_PCB.md and
    MASTER_SCHEMATIC_PLAN -> MASTER_PCB.md, both as-built with netlist-verified
    pin maps (panel: LED=GPIO3 DE=GPIO6 INT=GPIO10; master: RS-485 on Serial2,
    INT J2 pos 1 = panel 8 DR ... pos 9 = panel 0 UL on GPIO15-23)
    - Archive PROTOTYPE_WIRING, REVIEW_RESPONS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
    [master.ino]
2026-07-24 Panel/master: AI-review metadata fixes + INT-path/latency docs
    - ENIG surface finish on both boards (was unset)
    - Panel C37/C44/C50/C52 value 25V->50V (match part C440198)
    - Panel U2 datasheet URL -> THVD1429 (was THVD1420)
    - Master D2-D10 TVS descriptions corrected to actual netlist wiring (sch+pcb)
    - Master stackup note 'L3 power pours' -> 'L3 GND (solid)'
    - Docs: SENSE_12V is a digital present-check; J9 pin2 -> dedicated GND;
    VUSB<->VIN bridge must stay intact; USB input-path authority + latency budget
    [master-pcb.kicad_pcb, master-pcb.kicad_sch, panel-pcb.kicad_pcb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]
2026-07-24 Master: post-review rework — remove status LED, INT RC/TVS filter, pin reassign
    - Remove status LED (D1, R2); Teensy onboard LED (pin 13) serves as status
    - INT lines get two-stage protection: SMAJ5.0A TVS at the J2 entry + 330R
    series (R6-R14) + 1nF C0G RC (C3-C11) to GND on the Teensy-side node.
    Resolves review F3/F4 (series R makes the 5V-standoff TVS safe on the
    non-5V-tolerant Teensy pin; RC filters ESD/EMI). Pull-up stays Teensy-side.
    - R15 10k pull-down on UNDERGLOW_DATA — defines U3 gate-A input LOW at boot
    (review F5)
    - DIP -> GPIO 3/4/5, RS485_DE -> GPIO6; frees GPIO 0/1/2 and keeps Serial1
    (0/1) as the last spare hardware UART. RS-485 stays on Serial2 (7/8).
    - ERC/DR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
    [master-pcb.kicad_pcb, master-pcb.kicad_sch]
2026-07-24 Panel: post-review rework — INT TVS at J9, dedicated GND pin, U8 bypass caps
    - D30 SMAJ5.0A ESD clamp at J9 (cathode->signal, anode->GND); R17 100R is the
    series element into the RP2040 (mirror of the master INT front-end)
    - J9 pin 2 repurposed signal -> dedicated GND, pre-provisioning a paired
    signal+GND return cable (supersedes the both-pins-bridged arrangement)
    - U8 (LM66200) local bypass added per review F4: C54 1uF (VBUS/VIN1),
    C56 1uF (AMS1117/VIN2), C55 100nF (VOUT/+5VDC)
    - ERC/DRC clean. docs/PANEL_PCB.md updated. NOTE: D30 LCSC field still empty.
    [panel-pcb.kicad_pcb, panel-pcb.kicad_sch]
2026-07-24 Panel: diff-pair re-route for real stackup, QSPI meander fix, DRC honesty
    The impedance geometry was calculated against KiCad's DEFAULT stackup
    (3 x 0.48mm FR4) one day before the real JLC04161H-7628 stackup landed in
    4594625. That put the reference plane at 0.2104mm instead of 0.48mm, so the
    as-routed pairs were sitting near 55 ohm (USB) and 92 ohm (RS-485) against
    90/120 targets. Impedance follows w/h, so a 2.28x thinner dielectric needs a
    ~2.1x narrower trace.
    - USB re-routed to W=0.25/S=0.15 (~90 ohm), RS-485 to W=0.15/S=0.2 (~119
    ohm), both on F.Cu over the solid In1 GND plane. Netclass diff-pair widths
    updated to match.
    - Both pairs length-matched: USB skew 0.023mm, RS-485 skew 0.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
    [panel-pcb.kicad_pcb, panel-pcb.kicad_sch]
2026-07-24 Master: RS-485 pair length-matched, RX/TX test points added
    Same stackup as the panel (JLC04161H-7628), so the same 120-ohm target
    geometry applies. The pair was already at W=0.15/S=0.2 -- it landed on the
    right answer via the 0.15mm data-trace convention rather than by calculation
    -- so only the skew needed work.
    - /RS485+ and /RS485- now 45.39mm each: 0.000mm skew (was 0.60mm). F.Cu only,
    zero vias, ~119 ohm. Netclass diff-pair width corrected 0.2787 -> 0.15 and
    the stale USB pair class dropped (the Teensy handles USB internally; nothing
    USB is routed on this board).
    - TP9 (RS485_RX) and TP10 (RS485_TX) added, giving probe access to the full
    transceiver interface alongside TP1/TP2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
    [master-pcb.kicad_pcb, master-pcb.kicad_sch]
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2026-07-25 Panel: LCSC part metadata, SW3 lugs as pads 7/8, stitching-via purge
    PCB side of the SW3/J1 LCSC swap:
    - J1 metadata USB4085-GF-A -> LCK-TCF829D + LCSC C53184807; SW3 EG2201A ->
    SS22E01L5, datasheet to the LCSC page, stale DigiKey fields dropped
    (sch + pcb). Closes the schematic-parity warning.
    - J1's 9 starved_thermal errors fixed by making all 8 GND pads solid
    zone connections (library footprint + pcb instance). At 1mm pitch with a
    0.5mm thermal gap there is no room for a second spoke, and the shield
    posts' copper already merges with A12/B1.
    - SW3 mounting lugs are pads 7 and 8 per the vendor/EasyEDA numbering
    (was MP1/MP2) and now have symbol pins, so they can be tied to GND.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
    [PLACEHOLDER_USB_C_CMUCF661016C.stp, SS22E01L5.step, panel-pcb.kicad_pcb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]
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2026-07-26 BOM: rewrite as the four orders, derived from the boards
    docs/BOM.md was 419 lines of accumulated sourcing history with the live plan
    scattered through it. It is now 180 lines organised as what we buy and from
    where: order 1 JLCPCB (2 bare boards + panel PCBA), order 2 LCSC (~$110, every
    hand-soldered part on both boards plus the harness), order 3 DigiKey (Teensy
    x2, the only line left), order 4 AliExpress (Euroblock, cable, consumables).
    The part tables are no longer maintained by hand. tools/bom_census.py reads the
    .kicad_pcb files and prints per-board and total counts, classifying each ref by
    its footprint attributes (through-hole = buy, panel SMD = JLC places it, master
    SMD = hand-solde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
    [bom_census.py]
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
